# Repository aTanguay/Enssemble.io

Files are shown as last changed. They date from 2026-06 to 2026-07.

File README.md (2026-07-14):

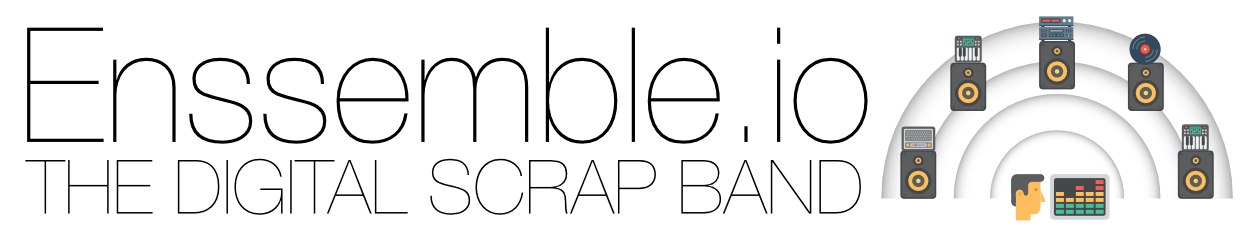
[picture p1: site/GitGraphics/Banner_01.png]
Header


**The Scrap Band**

The goal of Enssemble is to make experimenting with what I like to call a 'scrap band' a lot easier and cheaper. Placing musical members/nodes around your space gives you a completely different (and fun) experience compared to traditional two channel stereo. I personally strive to make them 100% wireless, so one can experiment at will. Running cables breaks the flow - and the metaphor.
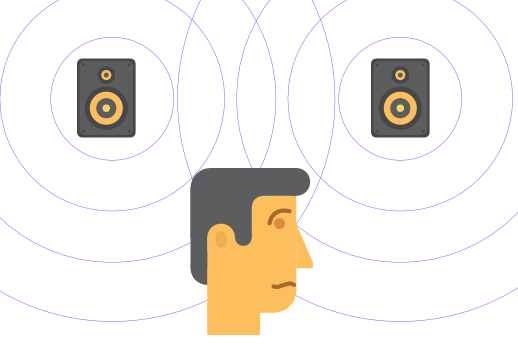
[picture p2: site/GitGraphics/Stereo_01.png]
Stereo


To create a band, we make a collection of sound making devices, sequenced through one BLE MIDI source. I personally use AUMv3 on iOS for this. This is your brain (and can be a voice of course). Just about any kind of sequencing you'd want is possible this way...from generative, to traditional straight forward compositions.

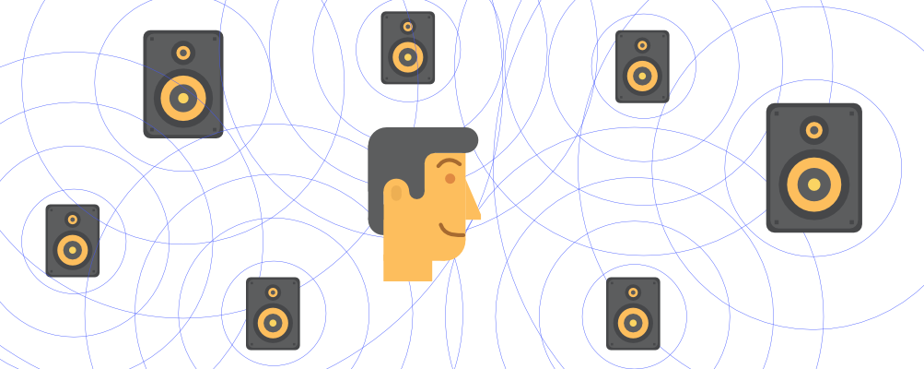
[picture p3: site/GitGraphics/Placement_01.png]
placement


**The Member Nodes** 

Battery>Node/Amp>Speaker

To get going, you need nodes, or 'members' to your band. The cheapest way I have found to make a good node is a [Seeed Studio Xiao MIDI synthesizer](https://www.seeedstudio.com/XIAO-MIDI-Synthesizer-p-6462.html) , a USB power brick, and a thrifted speaker...that's it. This could be done for $30-$50, depending on what you have available...most people have at least a few USB bricks around. So, a whole 'band' could cost you as little as $100, depending on what you have available. And frankly batteries are optional, but I go for no wires here.

Now that's the cheapest 'good' option, but there's nothing stopping you from using the tiny speaker on the Xiao, or hooking up a stadium PA. That's your business.

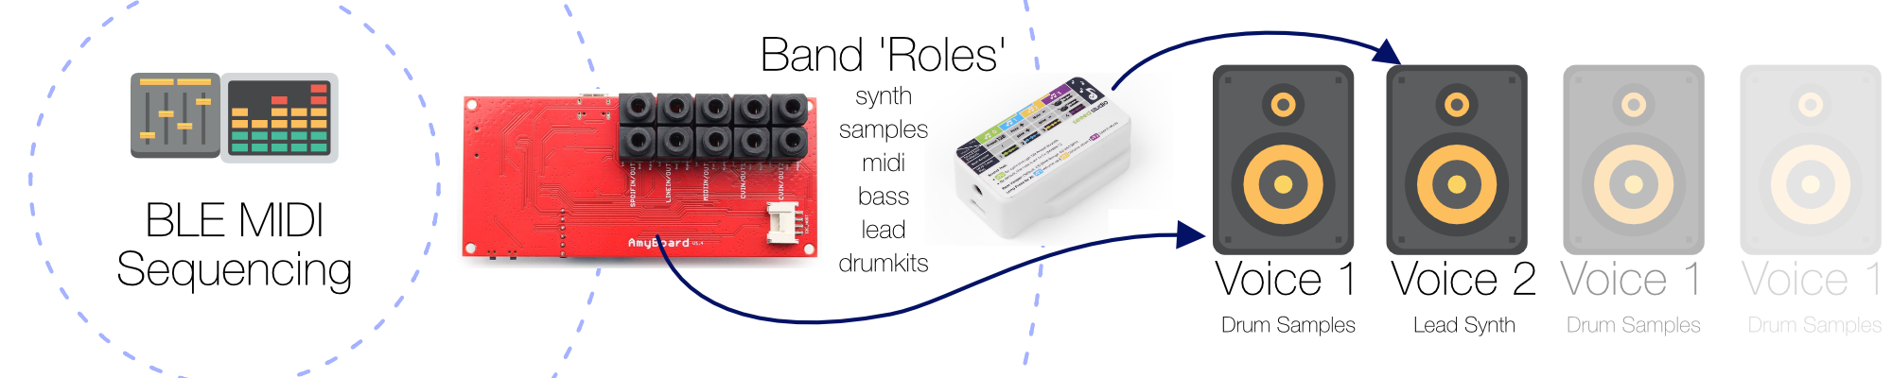
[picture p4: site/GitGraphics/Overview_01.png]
Overview


**Enssemble Firmwares**

Right now, there are two paths for Enssemble firmware. The aforementioned Xiao, and then the ['AmyBoard'](https://www.amyboard.com/) . This is a very cool, very cheap, very capable board that gives you some things that the Xiao doesn't have. The downside being the lack of built in amplifier. The Xiao has a surprisingly capable little Class D amp inside. So when powered and connected to a bookshelf speaker, it's ready to go. You'll be surprised!

On the other hand, the Amyboard supports more modern synthesis, Sample playback, and (TypeA TRS) MIDI in and out. As well as CV, if you wanna get nuts. But, you'll need powered speakers of some type. Which isn't the end of the world, but makes things more complicated.

**Node control and sonic shaping**

For this, I've been using Mozaic on iOS. The firmware support program change and passing CCs to whatever tweakable parameters the synths have. This feature is a little rough right now, but it will get cleaned up. And keep in mind that the Xiao uses some older sound types, but that's half the fun...trying to make cool stuff out a more limited palette. There are both crazy cheesy stuff in there, and surprisingly nice. And hey, put the sound through a pedal and shape it if you don't like it.

**The Pretenious Statement**

The overall experiment here is in 'spatial-like music'...meaning music experienced in 3D dimensions, instead of just two stereo speakers. By being able to place these sound sources literally anywhere around a space, you can create just about any kind of 'experience' you want. You could simulate a 4 piece Jazz trio. You could have sounds in other rooms of a home, all contributing to music. You get the idea. A lot of the inspiration is [Susan Ciani](https://www.sevwave.com/) (who I've actually never seen) who sequences her music in 3D dimensions, leading to an performance that can only be experienced in person. Neat. Whew, those kind of statements make me queasy. Here's a shortened version...It'd be cool.

*(Note, these firmwares were made largely through vibe coding with human planning and oversight. If that sits with you wrong, for the love of god, keep it to yourself and don't use these free tools that somehow a computer is 100% responsible for, but also, somehow took me dozens of man-hours to make)* Eye-roll emoji

**Yeah yeah, make with the BINS**

You probably want to know what you're looking for (feature-wise), which you'll find below, but here's the 
[Latest Release](https://github.com/aTanguay/Enssemble.io/releases/tag/v0.2.0)
Use the ESP browser based flasher, and go nuts.

flash a unit without a toolchain:
```bash
esptool.py --chip esp32c3 -p /dev/cu.usbmodem101 -b 460800 write_flash 0x0 NSMBL_Eenoo_v0.1.bin
```
or at 
[ESP TOOL ONLINE](https://espressif.github.io/esptool-js/)
Connects, flash starting at 0x00 and go to town.

## The Band (The Firmwares)

| Name | Inspiration | MIDI Ch | Role | Default Patch | Firmware |
|---|---|-----|---|---|---|
| **Eenoo** | Brian Eno | 1 | Pads/Ambient | Synth Pad | Amy and Xiao |
| **Prynz** | Prince | 2 | Lead | Synth Leads | Amy and Xiao |
| **Botsee** | Bootsie Collins | 3 | Bass | Synth Bass | Amy and Xiao |
| **Moroh** | Giorgio Moroder | 5 | Arps / Sequences | Synth Lead | Amy and Xiao |
| **8OhAte** | The 808 | 10 | Drums | GM Drum Kits | Xiao Only |
| **Kneel**  | Neal Peart | 10 | Drums | Sampled Kits | Amy Only |
| **Dapht**  | Daft Punk | 4 | General Samples | TBD | Amy Only |
| **Garee** | Gary Numan | ALL | MIDI Out to Hardware | None | Amy Only |

Named configs in `AmyBoard/configs/` — copy to `main/config.h` before flashing each board.

## What each node does (for the most part)

- Each unit advertises as a **BLE MIDI 1.0 peripheral** — connects to iOS as distinct nodes.
- Receives Note On/Off, Program Change, Pitch Bend, and CCs
- Per-unit MIDI channel filtering — each band member responds only to its assigned channel
- Real-time sound shaping via standard MIDI CCs (filter, reverb, chorus, volume, pan)
- Two platforms: **AMYboard** (ESP32-S3 + AMY software synth) and **XIAO MIDI Synthesizer** (ESP32-C3 + SAM2695 hardware GM wavetable)
- AMYboard firmware variants: **AMY synth** (256 patches) and **sample player** (WAV kits from SD)
- iOS control surface via **Mozaic** scripts

## Hardware

### AMYboard (ESP32-S3 Core)
- [AMYboard](https://www.amyboard.com/) — open-source, $29
- AMY software synth engine — 250 oscillators, 128 Juno-6 + 128 DX7 patches, GM drums
- ESP32-S3 dual-core: BLE MIDI on core 0, audio rendering on core 1
- 8MB octal PSRAM, SD card, I2S line out (3.5mm TRS stereo)
- I2C port for accessories, MIDI in/out (TRS), CV in/out, S/PDIF
- Support for I2C encoder and 128x128 OLED that most people use.

### Seeed Studio XIAO MIDI Synthesizer - ESP32-C3 Core + SAM2695 Audio Chip
- [Seeed Studio XIAO MIDI Synthesizer](https://www.seeedstudio.com/XIAO-MIDI-Synthesizer-p-6462.html)  — $22, tiny form factor, single-core RISC-V
- [Dream SAM2695](GM_VOICINGS.md) — hardware GM wavetable synth, 128 GM patches + drum kits, 64-voice polyphony
- UART MIDI at 31250 baud, full CC/NRPN passthrough (filter, envelope, vibrato, reverb/chorus types)
- 3.5mm stereo line out + onboard Class-D amplifier (that's not bad at all)

## Firmware Variants

### NSMBL_Synth — AMY Synth (`AmyBoard/NSMBL_Synth/`)
Full software synthesizer using the AMY engine. Default synths: Juno-6 (ch1), DX7 (ch2), GM drums (ch10). Supports program change to browse all 256 patches. Custom NSMBL CC handler for real-time sound shaping. Used by Eenoo, Prynz, and Botsee.

### NSMBL_SampleKits — Sample Player (`AmyBoard/NSMBL_SampleKits/`)
16-slice drum sample player. Reads WAV files with cue point markers from SD card. 4-voice polyphony, velocity-sensitive, chromatic mapping from C2. Used by Kneel.

### NSMBL_Synth — SAM2695 (`SeeedXiaoMIDI/NSMBL_Synth/`)
Hardware GM wavetable synth via SAM2695 chip. 128 GM patches, full CC passthrough, NRPN support for filter cutoff/resonance, envelope, and vibrato. BLE MIDI parser with running status support. Listens on **MIDI channel 1** (melody) and **channel 10** (GM drums); other channels are ignored (route in your host). See `Docs/SAM2695_MIDI_Reference.md` for full CC/NRPN map.

Per-unit identities live in `SeeedXiaoMIDI/NSMBL_Synth/configs/` — copy one to `main/config.h` before flashing so each module shows up with its own BLE name in AUM: **NSMBL_Eenoo** (pads, ch1), **NSMBL_Prynz** (lead, ch2), **NSMBL_Botsee** (bass, ch3), **NSMBL_Moroh** (arps, ch5), **NSMBL_8OhAte** (drums, ch10). Each unit listens only on its own channel.

Prebuilt per-member BINs are attached to the [v0.1.0 release](https://github.com/aTanguay/Enssemble.io/releases/tag/v0.1.0) — 

**Hardware buttons** (patch browsing, each press auditions the voice):

| Button | Tap | Hold |
|---|-----|---|
| 0 | Family down (coarse, −8) | — |
| 1 | Family up (coarse, +8) | Volume up |
| 2 | Patch down (fine, −1) | Volume down |
| 3 | Patch up (fine, +1) | MIDI panic |

> ⚠️ **Build gotcha:** the ESP-IDF console **must** stay off UART0 (it's the SAM2695's MIDI port). If it doesn't, log output corrupts the chip and patch changes silently fail. `sdkconfig` must show `CONFIG_ESP_CONSOLE_UART_NUM=-1`. See PLANNING.md → Technical Notes.

## Installing

There are many precompiled firmwares available for these boards. The easiest way to flash them is with the online tool from esspressiff. Depending on how many nodes you're making, you can install some or all of the firmwares, depending on their usage. 
[ESP TOOL ONLINE](https://espressif.github.io/esptool-js/)

## iOS Setup

1. Power on units — each plays a startup bleep
2. Open **AUM**, tap MIDI plug icon, connect each unit via Bluetooth MIDI
3. Route MIDI channels to the corresponding units
4. Play with a keyboard app, sequencer (Helium), or Mozaic control surface

iOS handles 13+ simultaneous BLE connections — the full band is well within range.

***CREATE DEMO VIDEO!***

## Mozaic Control Surface (still very rough)

iOS scripts in `Mozaic/` for the [Mozaic](https://ruismaker.com) MIDI scripting app:

| Script | Purpose |
|---|---|
| **NSMBL_EEnoo_Controller.moz** | AMYboard: patch browsing, filter/reso/reverb/chorus knobs, vol/pan mode, sustain, MIDI panic |
| **NSMBL_XIAO_Controller.moz** | XIAO/SAM2695: Mix layout — XY filter pad, NRPNs, named reverb/chorus types, envelope, vibrato |
| NSMBL_EEnoo_PatchSelect.moz | Simple patch bank selector |
| NSMBL_EEnoo_SoundShaper.moz | CC knobs only |

## NSMBL CC Map

Standard MIDI CCs handled by the firmware on all channels. Works with any MIDI controller.

| CC | Parameter | Mapping |
|----|---|---|
| 7 | Volume | Linear 0-127 |
| 10 | Pan | 0=Left, 64=Center, 127=Right |
| 70 | Filter Cutoff | Exponential ~13Hz-6400Hz |
| 71 | Resonance | Exponential Q 0.5-16 |
| 75/93 | Chorus Level | Linear 0=dry, 127=full |
| 91 | Reverb Level | Linear 0=dry, 127=full |

Handled by AMY internally: CC 0 (bank select), CC 64 (sustain), CC 123 (all notes off).

## License

MIT

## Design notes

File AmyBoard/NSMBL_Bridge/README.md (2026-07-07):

# NSMBL_Bridge — AMYboard BLE → DIN MIDI bridge (a.k.a. "Garee")

Takes BLE MIDI in (from AUM / an iPhone) and re-transmits it out the AMYboard's
**hardware DIN MIDI OUT** jack, so the wireless Enssemble rig can drive real
hardware synths, drum machines, and modular gear.

- No synthesis, no AMY engine, no PSRAM — a pure forwarder.
- Reuses the proven BLE MIDI parser from the XIAO firmware.
- Named member: **Garee** (Gary Numan).

## Channel routing (two knobs in `config.h` / `configs/config_*.h`)

| Define | Values | Meaning |
|---|---|---|
| `BRIDGE_IN` | `BRIDGE_ALL` (0) or a channel 1–16 | Forward every channel, or only one |
| `BRIDGE_OUT`  | `BRIDGE_PASSTHROUGH` (0) or a channel 1–16| Keep each message's channel, or remap ALL onto one  |

`config_Garee.h` default = **forward ALL → remap to ch1**, so fixed-channel
hardware (most gear defaults to ch1) just plays whatever you route to Garee.

## Hardware / pin map (AMYboard, ESP32-S3)

Confirmed from `tulipcc` `tulip/amyboard/pins.h` and the v1.4 schematic:

| Signal | GPIO | Notes |
|---|---|---|
| MIDI OUT data | 14 | UART1 TX, "Type A" data leg |
| MIDI OUT src  | 15 | "Type B" data leg — held HIGH here (see below) |
| MIDI IN | 21 | UART1 RX (not used yet) |
| UART | 1 | 31250 baud, 8N1 |

Console is on **USB-Serial-JTAG** (native USB-C), off the MIDI UART. View logs
with `idf.py -p <port> monitor` from a real terminal.

## ⚠️ The critical finding: the OUT jack needs a firmware-driven current source

**This cost hours to find and is not obvious. Read this before touching MIDI OUT.**

The AMYboard MIDI OUT is a **3.5mm TRS jack (PJ-3410)** wired, per the v1.4
schematic, as:

```
TIP    → R37 (22Ω) → GPIO14   (data leg,  "Type A")
RING   → R38 (22Ω) → GPIO15   (other leg, "Type B")
SLEEVE → GND
```

There is **no fixed 3.3V rail on the jack.** A standard DIN MIDI input is an
**optocoupler that needs a current source** (classically DIN pin 4 held at V+).
On this board that source must be provided by **firmware holding the non-data TRS
leg HIGH.** If you only drive the UART TX pin (GPIO14) and leave GPIO15 floating,
**no current flows through the receiver's opto and you get complete silence — on
any adapter, Type A or Type B.** The MIDI is transmitting perfectly on GPIO14;
the receiver just can't "see" it without the source leg.

### The fix (in `midi_out_init()`):

```c
uart_set_pin(UART_NUM_1, MIDI_TX_PIN /*14*/, MIDI_RX_PIN /*21*/, ...);
// Hold the OTHER TRS leg high = the MIDI current source (MIDI idle level).
gpio_reset_pin(MIDI_SRC_PIN /*15*/);
gpio_set_direction(MIDI_SRC_PIN, GPIO_MODE_OUTPUT);
gpio_set_level(MIDI_SRC_PIN, 1);
```

This matches exactly what the stock tulipcc firmware does in
`tulip/shared/amy_connector.c` → `amyboard_set_midi_out()`:

> `gpio_set_level(other_pin, 1);  // hold it high (MIDI idle/source)`

### Type A vs Type B on this board

TRS type is chosen by **which leg carries data vs. source**, in firmware — not
just by the cable/adapter:

- **Type A:** `MIDI_TX_PIN = 14`, `MIDI_SRC_PIN = 15`  (default)
- **Type B:** `MIDI_TX_PIN = 15`, `MIDI_SRC_PIN = 14`

A TRS-A vs TRS-B *adapter* only swaps tip/ring downstream — it cannot substitute
for the missing source leg. Get the source leg driven first; then match the
adapter/cable to your gear's type.

## Build & flash

```bash
cp configs/config_Garee.h main/config.h        # pick the member/personality
idf.py set-target esp32s3                       # first time only
idf.py build
idf.py -p /dev/cu.usbmodem101 flash monitor     # AMYboard enumerates as native USB
```

## Verified

- ✅ BLE MIDI in → remap → DIN MIDI OUT, driving an Akai MPC over a Type-A TRS
  adapter (2026-07-07). Multi-channel source (e.g. Riffer on ch1/2/3) collapses
  to ch1 out.

## Known limits / future

- Forwards channel-voice messages only (note/CC/PC/pitch-bend/aftertouch).
  **SysEx, clock, and real-time are not passed yet.**
- MIDI **thru/merge** from the DIN IN (GPIO21) is stubbed but not wired up.
- Future: single-channel Garee variants; a Type-B variant.

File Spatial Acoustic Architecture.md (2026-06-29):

# Project Manifesto: Spatial Acoustic Architecture

This project is dedicated to moving beyond the limitations of traditional stereo reproduction by exploring Spatial Acoustic Architecture. The philosophy is simple: music should not be a flat, compressed experience. It should be a physical event where sound occupies the same three-dimensional space as the listener.

## Core Philosophy

- **Sound as Physicality:** We reject the "stereo bore." By distributing sound sources physically throughout a room, we allow the room's natural acoustics to act as the final mixing console.
- **The Instrument is the Room:** The listener is not a passive audience member; they are an active participant, and their movement through the space determines the mix.
- **Zero-Friction Immersion:** Accessibility is paramount. The goal is to provide a setup that is easy for non-technical users to assemble, configure, and operate while maintaining the depth required for advanced musical performance.
- **Open Synthesis:** We favor permanent, open-source platforms like the AMYboard over transient maker-market hardware, ensuring the project remains sustainable and hackable for years to come.

## Project Roadmap

| **Phase** | **Objective** | **Primary Tech** |
| --- | --- | --- |
| 1. Foundation | Establish BLE MIDI firmware on AMYboard (ESP32-S3) via ESP-IDF. | NimBLE, ESP-IDF, AMY Engine |
| 2. Voice Categorization | Develop specialized firmware for "Band Members" (e.g., PCM Sampler, Analog Poly-Synth, FM Bassist). | AMY Wire Messages, Custom C Binaries |
| 3. The Conductor | Implement a centralized "Band Leader" interface in AUM using Mozaic for patch management. | AUM3, Mozaic, MIDI CC/PC |
| 4. Expansion | Integration of tactile UI (I2C Encoders/OLED) for physical control in room-scale setups. | Grove I2C, Physical Encoders |

## Distribution Strategy: The "DIY Ecosystem"

To avoid the pitfalls of hardware manufacturing, this project operates on a frictionless DIY model:

1. **GitHub Hub:** The central repository hosting source code, Mozaic scripts, and wiring guides.
2. **Web Flashers:** Use of ESP Web Tools to allow users to install firmware via browser without installing development environments.
3. **Community Sketches:** Sharing specialized configurations that allow users to buy stock boards and instantly transform them into designated band members.

## The Long-Term Goal

The success of this project is not measured by market share or competing with professional synthesizers. It is measured by the ability to democratize spatial audio, turning every living room into a site-specific concert hall.

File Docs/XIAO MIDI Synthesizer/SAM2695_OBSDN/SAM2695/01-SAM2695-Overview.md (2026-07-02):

---
tags: [hardware, midi, synth, sam2695]
---

# SAM2695 — Overview

⬅ [[00-SAM2695-Index]]

Low power single chip synthesizer with effects and built-in CODEC.

## Key features

- Single chip all-in-one design:
  - MIDI control processor, serial and parallel interface
  - Synthesis, General MIDI wavetable implementation
  - GM-compatible effects: reverb + chorus
  - Spatial effect
  - 4-band stereo equalizer
  - Stereo DAC — DR 86dB typ, THD+N -75dB typ
  - Mic input — DR 86dB typ, THD+N -75dB typ
  - Mic echo
- Polyphony: **64 voices** without effects, **38 voices** with effects
- On-chip CleanWave™ wavetable data, firmware, RAM delay lines
- Stereo line audio output
- Typical applications: battery-operated musical keyboards, portable phones, karaoke machines
- Package: **QFN48, 6×6mm** — small footprint, small pin count
- Low power: 18 mA typ operating / 17 µA typ power-down, single 3.3V supply

## Typical hardware configuration

```
MIDI IN ──────┐
              │→ [ SAM2695 ] → Audio Out (stereo)
Parallel MIDI ┘
```

See [[02-SAM2695-Pin-Description]] for full pinout, [[08-SAM2695-Serial-Parallel-Modes]] for how the two input paths (serial MIDI vs 8-bit parallel bus) interact.

## Related
- [[02-SAM2695-Pin-Description]]
- [[03-SAM2695-Electrical-Characteristics]]
- [[06-SAM2695-Reference-Circuits]]

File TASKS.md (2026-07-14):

# TASKS.md — Current Priorities

## Phase 1 — AMYboard BLE MIDI Firmware ✅

### NSMBL_SmplCty (Sample Player) ✅
- [x] ESP-IDF project structure with CMake (target: ESP32-S3)
- [x] NimBLE BLE MIDI peripheral — pinned to Core 0
- [x] MIDI message parsing (Note On/Off, CC, Program Change, Pitch Bend)
- [x] FreeRTOS queue for MIDI events between cores
- [x] SD card driver (SPI, FAT32, long filenames)
- [x] WAV cue point parser for 16-slice kit files
- [x] 4-voice polyphonic sample player with velocity scaling — pinned to Core 1
- [x] I2S audio output (16-bit stereo, 44.1kHz)
- [x] Per-unit configuration (NSMBL_SmplCty, channel 1)
- [x] End-to-end verified: iPhone → BLE MIDI → 808 drum playback

### NSMBL_EEnoo (AMY Synth) ✅
- [x] AMY synth engine integrated as ESP-IDF component (250 oscillators)
- [x] I2S audio output via AMY (32-bit stereo, 44.1kHz)
- [x] All-channel MIDI pass-through (Juno ch1, DX7 ch2, drums ch10)
- [x] Startup bleep confirmation
- [x] BLE MIDI shared from SmplCty codebase
- [x] End-to-end verified: iPhone → BLE MIDI → AMY synth playback

## Phase 2 — Multi-Unit & UX (In Progress)

### Done
- [x] Full CC passthrough — NSMBL CC handler: volume, pan, filter, resonance, reverb, chorus (all channels)
- [x] Pitch Bend passthrough (working since EEnoo launch)
- [x] Per-unit MIDI channel filtering (configurable via config.h, 0=all)
- [x] Mozaic control surface — patch browsing, sound shaping, sustain, panic
- [x] Band member configs created: Eenoo (pads), Prynz (lead), Botsee (bass), Kneel (drums)
- [x] Named configs in `AmyBoard/configs/` — copy to config.h before flashing
- [x] **AMY sample player (`NSMBL_SampleKits`) parser brought up to snuff** — ported the
  running-status BLE parser from the Xiao/Garee rewrite (fixes dropped/corrupted hits on
  ch10 drum streams that use running status). Built clean, flashed + boot-verified on the
  AMYboard (SD mount, 16-slice kit load, BLE connect). (2026-07-09)
  - [ ] Flash with `config_Kneel.h` identity if this unit should join the roster as Kneel
    (currently flashed as generic `NSMBL_SampleKits`, ch10)

### AMYboard sample player — I2C encoder + OLED kit selection (In Progress, 2026-07-09)
*Plan: `~/.claude/plans/warm-mapping-cake.md`. Modulino Knob [ABX00107] @ 0x76/0x74 +
SH1107 128x128 OLED @ 0x3C on the Qwiic bus (SDA=17/SCL=18).*
- [x] Shared `i2c_master` bus (`i2c_bus.c`)
- [x] Modulino Knob driver (`modulino_knob.c`) — wrap-safe delta + button edge
- [x] SH1107 OLED via vendored u8g2 (`oled.c` + `components/u8g2/`, fonts trimmed 38 MB→26 KB)
- [x] Runtime-safe kit swap (`sample_player.c`) — local-load-then-swap under `s_kit_mutex`,
  render never stalls, **latent reload leak fixed**
- [x] Kit scan of `/sdcard/Kits/*.wav` (`ui.c`) — sorted, ext-stripped; **43 kits** found on
  the card (raised `MAX_KITS` 32→96)
- [x] UI loop — turn scrolls, push loads with a "Loading…" screen
- [x] Builds clean; boot-verified on HW (bus up, scan, graceful no-peripheral fallback, 808s intact)
- [x] **Live bring-up ✅** — OLED kit list renders; knob scrolls (found at **0x3B** after the
  address correction); push → "Loading…" → new kit plays; race-safe swap holds under playback.
  SH1107 needed the **`_seeed_` variant** (`OLED_SETUP`): the generic `_128x128_` applies a
  bogus `x_offset=96` that wrapped the display; seeed uses the same init with offset 0.
  **Feature complete.**
- [ ] (future) Modulino **Buttons** (mode/audition/panic); kit switch via MIDI Program Change;
  persist last kit in NVS

### AMY synth (NSMBL_Synth) — encoder + OLED patch & parameter control ✅ (2026-07-12)
*Drivers reused verbatim from the sampler (`i2c_bus.c` / `modulino_knob.c` / vendored `u8g2`);
only `oled.c` draws + `ui.c` are synth-specific.*
- [x] "Menu + edit" UI: turn scrolls Patch/Filter/Reso/Reverb/Chorus/Volume/Pan; push enters
  EDIT; turn adjusts live; push exits.
- [x] Patch: steps 0–255, loads live via bank `CC0` + Program Change; shows `Juno/DX7 NNN`.
- [x] Params send their CC live (70/71/91/93/7/10) via the existing `nsmbl_midi_cc_handler`.
- [x] UI injects `midi_event_t` into `midi_queue` — no `synth_engine.c` change, single AMY consumer.
- [x] Running-status BLE parser ported here too (separate commit).
- [x] **HW-verified**: menu renders + scrolls; EDIT Filter sweeps the sound live over BLE.
- [ ] (watch) app image at ~93% full (AMY + u8g2) — bump partition / trim u8g2 if it grows.
- [ ] (future) shared driver component across all 3 variants; patch-name table; NVS persist;
  Modulino Buttons; reconcile host-sent CCs with on-screen values.

### Garee (NSMBL_Bridge) — encoder routing + OLED MIDI monitor ✅ (2026-07-12)
*3rd and last AMYboard to get the UI — the fleet is complete. Drivers reused verbatim.*
- [x] `bridge_state.c` — runtime `BRIDGE_IN`/`BRIDGE_OUT` (seeded from config) + monitor state,
  shared across parse/forward/UI via a short `portMUX`.
- [x] OLED monitor: `IN→OUT` header (active field boxed), last-note, IN/OUT activity dots,
  forwarded-note counter. Turn edits active field; push toggles IN/OUT.
- [x] Wire-ins: `ble_midi.c` live IN filter + record received; `bridge_task` live OUT + record forwarded.
- [x] **HW-verified**: dots flash on notes, knob re-routes live, DIN gear responds (knob at alt 0x3A).

### Now the natural cleanup — shared driver component
- [ ] **Factor `i2c_bus` / `modulino_knob` / `oled` (+ vendored `u8g2`) into ONE shared component**
  referenced by all three variants (`EXTRA_COMPONENT_DIRS`), killing the 3× copy-paste before it drifts.
- [ ] Flash the synth UI with per-member configs (Eenoo/Prynz/Botsee).
- [ ] (future) NVS-persist: last kit (sampler), last patch/params (synth), last routing (bridge).

## Phase 2b — XIAO Platform (In Progress)

### Done
- [x] XIAO ESP-IDF firmware (`SeeedXiaoMIDI/NSMBL_Synth/`) — BLE MIDI + SAM2695 UART
- [x] SAM2695 MIDI reference extracted from chip spec (`Docs/SAM2695_MIDI_Reference.md`)
- [x] Full CC/NRPN passthrough — firmware forwards all CCs to SAM2695, NRPNs work natively
- [x] Mozaic XIAO controller (`Mozaic/NSMBL_XIAO_Controller.moz`) — Layout 0 (Mix)
  - XY pad: filter cutoff + resonance via NRPN
  - 10 knobs: volume, expression, reverb/chorus send+type, attack, release, vibrato rate/depth
  - 8 pads: patch/bank navigation, sustain, reset, PANIC
- [x] BLE MIDI parser rewrite — proper running status support, debug logging
- [x] SAM2695 bank fix — clamp to GM (0) / MT-32 (127), buttons+Mozaic as GM/MT-32 selectors
- [x] Hardware buttons working — gpio_reset_pin + 50ms debounce (root cause was seating, not firmware)
- [x] Volume-tracking fix — guard was broken in all-channel mode (MIDI_CHANNEL 0)
- [x] **Program changes fixed** — real cause was ESP-IDF console on UART0 corrupting the
  SAM's MIDI; moved console to USB-JTAG (`CONFIG_ESP_CONSOLE_UART_NUM=-1`). GM System On at boot.
- [x] Channel model — listen on ch1 (melody) + ch10 (drums), ignore the rest
- [x] **Patch-nav MVP** — buttons 0/1 family jump (coarse), 2/3 single patch (fine), each auditions
- [x] Review-pass cleanup — panic releases sustain (CC64=0), stale comments fixed
- [x] **v0.1.0 GitHub release** — merged flash-at-0x0 BIN, no toolchain needed
- [x] Roster naming sync across docs + AMY/XIAO configs
- [x] **5 single-channel XIAO band variants** — each listens only on its own port:
  Eenoo (ch1), Prynz (ch2), Botsee (ch3), Moroh (ch5), 8OhAte (ch10); per-member
  prebuilt BINs built and attached to the v0.1.0 release
- [x] Flashed live: Prynz, Botsee, 8OhAte (drums confirmed!)

### Deferred — XIAO firmware hygiene (low priority, not blocking)
- [ ] **Audition blocks the MIDI task (~780ms)** — `audition_voice()` + PC delays run inside
  `midi_task`, so incoming BLE events queue up while the preview plays; a held note's
  note-off can stall, and a PC flood can overflow the 64-deep queue (silent drops).
  Fix deliberately: add a UART write mutex FIRST (two tasks must never interleave bytes
  to the SAM2695 — see the UART0 saga), then move the audition to its own task, then
  hardware-test with a live MIDI stream. Do NOT do this casually.
- [ ] Decide volume-button intent: long-press volume only adjusts VOICE_CHANNEL (ch1);
  drums (ch10) stay at boot volume. If buttons should be "device volume", also send ch10.
- [ ] Move `ble_midi_is_connected()` declaration into `ble_midi.h` (currently extern'd
  inline in main.c's led_task)
- [ ] Streamline PC band-aids (30ms bank/PC gaps, 250ms audition delay) now that the real
  UART0 bug is fixed — kept for now, "don't press our luck" (works reliably as-is)
- [ ] Long-press timing 600ms → 1000ms to match Seeed reference (feel preference)
- [ ] BLE RX buffer is fixed `uint8_t buf[128]` in `ble_midi.c` — size to negotiated MTU to avoid truncating very large bursts
- [ ] Parser SysEx handling consumes the 0xF7 terminator as a timestamp (harmless, not strictly correct)

### Next — MVP for Spatial Composition
- [ ] Flash remaining XIAO units: Eenoo (ch1, from the basement) + Moroh (ch5)
- [ ] Verify 5-unit simultaneous BLE connection from iPhone/AUM (route ch1/2/3/5 + ch10)
- [ ] Connect each unit to a speaker in a different location
- [ ] First spatial composition test (2 XIAO + 1 AMY already sounded amazing)
- [ ] Flash 3 AMYboards: Eenoo (ch1 pads), Prynz (ch2 lead), Botsee (ch3 bass)
- [ ] Verify XIAO Mozaic controller end-to-end (CCs, NRPNs, program changes)

### Later
- [ ] Kit switching via MIDI Program Change (SmplCty)
- [ ] Modulino Buttons + Knob I2C drivers (when hardware arrives)
- [x] **Garee (Gary Numan)** — AMYboard BLE→DIN MIDI bridge scaffolded
  (`AmyBoard/NSMBL_Bridge/`), builds clean for ESP32-S3. MIDI out UART1 GPIO14
  (Type A), 31250. Configurable `BRIDGE_IN` (all/one channel) + `BRIDGE_OUT`
  (passthrough/remap); default config_Garee.h forwards ALL → remaps to ch1 so
  fixed-channel hardware just plays.
  - [x] Flashed + **hardware-verified driving an Akai MPC over Type-A TRS**
    (2026-07-07). Key fix: **hold the non-data TRS leg (GPIO15) HIGH as the MIDI
    current source** — the OUT jack has no 3.3V rail, so a DIN opto gets total
    silence otherwise. Full write-up in `AmyBoard/NSMBL_Bridge/README.md`.
  - [ ] (future) MIDI thru/merge from DIN in (GPIO21); SysEx/clock passthrough
  - [x] (cleanup) reflashed the clean build — per-note diagnostic log removed (2026-07-07)
- [ ] **CV output AMYboard variant** — pitch/gate (and LFO/env) CV out to patch a band
  member into modular/Eurorack; AMYboard has 2x CV out
- [ ] Moroh AMY config (roster lists Moroh as Amy+Xiao; only the XIAO config exists so far)
- [ ] Favorite voice slots stored in NVS flash
- [ ] Reconnection handling — auto re-advertise after iOS disconnects
- [ ] Per-unit Mozaic scripts (one controller per band member)
- [ ] Dapht (Daft Punk) — sampler/granular unit, design TBD after first spatial jam

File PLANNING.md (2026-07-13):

# PLANNING.md — Enssemble / "The Band"

## Project Vision

A set of wireless BLE MIDI synthesizer units deployed spatially around a room — each one a band member with its own voice, driven wirelessly from an iPhone. Sound comes from physically located objects rather than stereo speakers.

Each unit is a band member with a single-name identity: Eenoo, Prynz, Botsee, Moroh, 8OhAte, Kneel, Dapht, Garee.

The firmware is built with **ESP-IDF** and targets two hardware platforms:
- **XIAO MIDI Synthesizer** (ESP32-C3 + SAM2695 hardware GM chip)
- **AMYboard** (ESP32-S3 + AMY software synth engine)

---

## Current Status

ESP-IDF firmware working on both AMYboard and XIAO platforms.

**XIAO platform shipped as v0.1.0** — a 5-piece XIAO band (Eenoo, Prynz, Botsee, Moroh, 8OhAte), each a single-channel BLE MIDI voice with per-member prebuilt BINs attached to the [GitHub release](https://github.com/aTanguay/Enssemble.io/releases/tag/v0.1.0). The long SAM2695 "patch won't change" bug is solved (root cause: ESP-IDF console was on UART0, the SAM's MIDI port). Three XIAO units flashed so far (Prynz, Botsee, 8OhAte); Eenoo + Moroh pending hardware.

Three AMYboards available for spatial deployment. Mozaic iOS control surface replaces the planned TouchOSC phase. Next: flash the remaining units and run the first multi-unit spatial jam.

### Firmware Variants
| Firmware | Directory | Platform | Purpose | Status |
|---|---|---|---|---|
| NSMBL_Synth | `AmyBoard/NSMBL_Synth/` | AMYboard (ESP32-S3) | AMY synth engine (Juno, DX7, drums) | ✅ Verified |
| NSMBL_SampleKits | `AmyBoard/NSMBL_SampleKits/` | AMYboard (ESP32-S3) | 16-slice WAV sample player (SD card) | ✅ Verified |
| NSMBL_Synth | `SeeedXiaoMIDI/NSMBL_Synth/` | XIAO (ESP32-C3) | SAM2695 hardware GM wavetable synth | ✅ Verified |
| NSMBL_Bridge | `AmyBoard/NSMBL_Bridge/` | AMYboard (ESP32-S3) | BLE→DIN MIDI bridge (Garee); channel filter/remap | ✅ HW-verified (drives Akai MPC) |

Band member identity is set via `config.h` — copy a named config from `AmyBoard/configs/`
(AMY) or `SeeedXiaoMIDI/NSMBL_Synth/configs/` (XIAO) before building. XIAO members are
single-channel: Eenoo ch1, Prynz ch2, Botsee ch3, Moroh ch5, 8OhAte ch10.

### iOS Control Surface (Mozaic)
| Script | Purpose | Status |
|---|---|---|
| `NSMBL_EEnoo_Controller.moz` | AMYboard: patch browser + sound shaper + panic | ✅ Working |
| `NSMBL_XIAO_Controller.moz` | XIAO: Mix layout with XY filter, NRPNs, named FX types | ✅ Working |
| `NSMBL_EEnoo_PatchSelect.moz` | Simple patch bank selector (superseded) | ✅ Working |
| `NSMBL_EEnoo_SoundShaper.moz` | CC knobs only (superseded) | ✅ Working |

### NSMBL CC Map (firmware, all channels)
| CC | Function | Range |
|----|---|---|
| 7 | Volume | 0-127 linear |
| 10 | Pan | 0=L, 64=center, 127=R |
| 70 | Filter Cutoff | Exponential ~13Hz-6400Hz |
| 71 | Resonance | Exponential Q 0.5-16 |
| 75/93 | Chorus Level | 0=dry, 127=full |
| 91 | Reverb Level | 0=dry, 127=full |

AMY handles internally: CC 0 (bank select), CC 64 (sustain), CC 123 (all notes off).

### The Band — Full Roster
*Names riff on famous musicians. Configs in `AmyBoard/configs/` (AMY) and `SeeedXiaoMIDI/NSMBL_Synth/configs/` (XIAO).*

| Name | Inspiration | MIDI Ch | Role | Default Patch | Firmware | Xiao Status | Amy Status |
| --- | --- | --- | --- | --- | --- | --- | --- |
| **Eenoo**  | Brian Eno | 1 | Pads/Ambient | Synth Pad | Amy and Xiao | ✅ Ready | |
| **Prynz**  | Prince | 2 | Lead | Synth Leads | Amy and Xiao | ✅ Ready | |
| **Botsee** | Bootsie Collins | 3 | Bass | Synth Bass | Amy and Xiao | ✅ Ready | |
| **Moroh**  | Giorgio Moroder | 5 | Arps / Sequences | Synth Lead | Amy and Xiao | ✅ Ready | |
| **8OhAte** | The 808 | 10 | Drums | GM Kits | Xiao Only | ✅ Ready | |
| **Kneel**  | Neal Peart | 10 | Drums | Sample Kits | Amy Only | | |
| **Dapht**  | Daft Punk | 4 | General Samples | TBD | Amy Only | | |
| **Garee**  | Gary Numan | ALL | MIDI Out to Hardware | None | Amy Only | | |

Named configs in `AmyBoard/configs/` (AMY) and `SeeedXiaoMIDI/NSMBL_Synth/configs/` (XIAO)
— copy one to `main/config.h` before flashing each board.

---

## Architecture

```
iPhone (AUM + Helium / TouchOSC)
        |
        | BLE MIDI 1.0 — one connection per unit
        | iOS confirmed: 13+ simultaneous connections possible
        | Latency: 3-15ms per unit
        |
        +-- Channel 1 --> Eenoo (Pads/Ambient)
        +-- Channel 2 --> Prynz (Lead)
        +-- Channel 3 --> Botsee (Bass)
        +-- Channel 4 --> Dapht (Samples) [Amy]
        +-- Channel 5 --> Moroh (Arps/Sequences)
        +-- Channel 10 -> 8OhAte (Drums, Xiao) / Kneel (Drums, Amy)
        +-- All chans -> Garee (MIDI out to hardware) [Amy]
                |
                v
AMYboard (ESP32-S3, dual-core):
  Core 0:
    +-- NimBLE BLE MIDI stack
    +-- MIDI message parsing & channel filter
    +-- Connection management
    +-- Button handler
  Core 1:
    +-- AMY synth engine (audio rendering)
    +-- I2S DAC output
  Shared (FreeRTOS queue between cores):
    +-- MIDI events from Core 0 -> Core 1
    +-- Per-unit config (device name, channel, patch)
    +-- Boot sound on startup

XIAO (ESP32-C3, single-core):
  +-- BLE MIDI stack (NimBLE) with running status support
  +-- SAM2695 via UART @ 31250 baud (128 GM + drum kits)
  +-- Full CC/NRPN passthrough (filter, envelope, vibrato, FX types)
  +-- 3.5mm stereo + onboard Class-D amp
```

---

## Phases

### Phase 1 — AMYboard BLE MIDI + Sample Player
*AMYboard first. Get BLE MIDI receiving on one core, AMY playing on the other.*

- [ ] ESP-IDF project structure with CMake (target: ESP32-S3)
- [ ] NimBLE BLE MIDI peripheral (advertise, connect, receive MIDI) — pinned to Core 0
- [ ] MIDI message parsing (Note On/Off, CC, Program Change, Pitch Bend)
- [ ] AMY synth engine integration — pinned to Core 1
- [ ] FreeRTOS queue for MIDI events between cores
- [ ] Simple sample player exposing AMY's PCM playback via MIDI notes
- [ ] I2S audio output configuration
- [ ] Per-unit configuration (device name, MIDI channel, default patch)
- [ ] Boot sound on startup
- [ ] Verified working: AUM connects, notes trigger samples, audio out confirmed

### Phase 2 — Multi-Unit & UX (AMYboard)
*Multiple AMYboard units with proper channel separation and standalone usability*

- [ ] Per-unit MIDI channel filtering
- [ ] Full CC passthrough (volume, pan, expression, sustain, mod, effects)
- [ ] Pitch Bend and Aftertouch passthrough
- [ ] Voice/patch selection via AMY
- [ ] Curated preset system per band role
- [ ] Audition note on voice change
- [ ] Favorite voice slots stored in NVS flash
- [ ] Reconnection handling — auto re-advertise after iOS disconnects
- [ ] Button input handler
- [ ] Multi-unit simultaneous operation verified

### Phase 2b — XIAO Platform ✅
*BLE MIDI on XIAO ESP32-C3 + SAM2695 hardware GM synth*

- [x] SAM2695 UART driver component (31250 baud)
- [x] Single-core architecture adapted for ESP32-C3 (RISC-V)
- [x] BLE MIDI parser with running status support
- [x] Full CC/NRPN passthrough to SAM2695
- [x] SAM2695 MIDI reference documented (`Docs/SAM2695_MIDI_Reference.md`)
- [x] Mozaic XIAO controller (Layout 0 Mix — XY filter, NRPNs, named FX types)

### Phase 3 — ~~TouchOSC~~ Mozaic Control Surface ✅
*Replaced TouchOSC plan with Mozaic iOS scripts — simpler, more flexible, already working.*

- [x] Patch browsing (prev/next per channel)
- [x] Sound shaping knobs (filter, resonance, reverb, chorus)
- [x] Volume/Pan mode toggle
- [x] Channel selector (Juno/DX7/Drums)
- [x] Sustain toggle
- [x] CC reset
- [x] MIDI Panic (all sound off, all channels)
- [ ] Multi-unit page — one Mozaic instance per band member

### Phase 4 — Deep Synth Control
*Platform-specific advanced features*

- [ ] XIAO/SAM2695: SysEx for 4-band stereo EQ, master volume/tuning
- [ ] AMYboard/AMY: Custom patches, FM synthesis, filter control
- [ ] I2C encoder/OLED UI for physical control (AMYboard)

### Phase 5 — "The Band" Physical System
*3D printed band members for room-scale deployment*

- Enclosure design — abstract sculptural forms, textile/fabric aesthetic
- LiPo battery integration for fully wireless operation
- Upgraded speakers housed in acoustic chambers
- Power on -> boot sound -> advertise -> AUM connects -> play

---

## Technical Notes

### BLE MIDI
- BLE MIDI 1.0 spec over NimBLE (ESP-IDF component, not Arduino library)
- Each unit is an independent BLE peripheral
- iOS handles 13+ simultaneous connections
- Latency: 3-15ms per unit

### SAM2695 (XIAO platform)
- Needs ~500-600ms after power-up before accepting MIDI
- Pitch Bend must be sent as raw MIDI bytes
- Bank Select (CC 0) must precede Program Change; only bank 0 (GM) / 127 (MT-32) valid
- Channel indexing: BLE MIDI uses 1-16, SAM2695 uses 0-15
- Drum channel (10) volume defaults low — set explicitly

### ⚠️ CRITICAL: keep the ESP-IDF console OFF UART0 (XIAO+SAM2695)
UART0 is the SAM2695's MIDI port. If the ESP-IDF console stays on UART0 (the
default!), every `ESP_LOGI` is transmitted to the chip as garbage MIDI and
corrupts its state — program changes stop working and every note plays one
stuck bell-like sound (intermittent, correlates with logging). This cost us a
full debugging session. Guard rails:
- `sdkconfig.defaults` must set `CONFIG_ESP_CONSOLE_UART_DEFAULT=n`,
  `CONFIG_ESP_CONSOLE_USB_SERIAL_JTAG=y`, `CONFIG_ESP_CONSOLE_SECONDARY_NONE=y`
- Editing `sdkconfig.defaults` does nothing if `sdkconfig` already exists —
  delete `sdkconfig` and rebuild to apply it
- Verify the built `sdkconfig` shows `CONFIG_ESP_CONSOLE_UART_NUM=-1` (NOT 0)
- The Arduino library avoids this by keeping debug on USB `Serial` + synth on `Serial0`

### Hardware — XIAO ESP32-C3
- Button pins (active LOW, internal pullup): GPIO 5, 4, 3, 2
- SAM2695 on UART0 at 31250 baud (TX=21, RX=20) — console MUST be on USB-JTAG, see above
- LED = GPIO 10, active LOW
- Patch nav buttons: 0/1 = family jump (coarse), 2/3 = single patch (fine)

### Hardware — AMYboard ESP32-S3
- AMY software synth engine (250 oscillators, dual-core rendering)
- I2S audio output (32-bit stereo via onboard DAC)
- 8MB octal PSRAM for samples and synth data
- SD card (SPI: MOSI=11, MISO=13, CLK=12, CS=10)
- I2S pins: MCLK=3, BCLK=8, WS=2, DOUT=6
- I2C port: SDA=17, SCL=18 (for Modulino accessories)
- MIDI out: GPIO 14 (Type A) / GPIO 15 (Type B)
- MIDI in: GPIO 21
- Line out: 3.5mm TRS stereo
- S/PDIF in/out, CV in/out (2x each)

### iOS BLE Limits
- iOS handles 13+ simultaneous BLE connections
- iPad Pro tested to 15 concurrent
- 4-5 band members is comfortably within limits
- Each unit is independent — no bandwidth competition

---

## Session Log

### 2026-07-09 — AMY sample player: I2C encoder + OLED kit selection ✅ HW-VERIFIED
- **Goal:** make each AMYboard drum node self-contained — turn a knob to browse the
  WAV kits on the SD card, see the selection on a screen, push to load. Plan file:
  `~/.claude/plans/warm-mapping-cake.md`.
- **Hardware:** Arduino Modulino Knob [ABX00107] (I2C 0x76/0x74) + SH1107 128x128 OLED
  (I2C 0x3C), both on the AMYboard Qwiic bus (SDA=17, SCL=18).
- **Built (all in `AmyBoard/NSMBL_SampleKits/main/`):**
  - `i2c_bus.c` — shared `i2c_master` bus (new driver API).
  - `modulino_knob.c` — probe + wrap-safe int16 delta + button-edge decode; we never `set()`.
    **Corrected against the vendored `Docs/Amyboard/Arduino_Modulino-main` source:** real 7-bit
    address is **0x3B/0x3A** (Arduino quotes 8-bit 0x76/0x74, lib divides by 2), and the read
    frame is **4 bytes** with the pinstrap byte FIRST (discard byte0; count=1-2, button=3).
  - `oled.c` + vendored **u8g2** component (BSD-2) — `u8g2_fonts.c` trimmed 38 MB → 26 KB
    (3 fonts). Kit-list / loading / message screens. SH1107 panel variant is a one-line
    knob: `OLED_SETUP` in `config.h` (swap to `_pimoroni_`/`_seeed_` if the image is offset).
  - `ui.c` — scans `/sdcard/Kits/*.wav`, sorts, drives selection + load-on-press.
- **Race-safe kit swap** in `sample_player.c`: kit now loads into a *local* `kit_t` (old kit
  keeps playing through the ~5 s SD read), then swaps in under a brief `s_kit_mutex`; render
  task takes the mutex with a 0 timeout (emits one silent buffer during the µs swap, never
  stalls). **Fixed a latent reload leak** (old PSRAM buffer is now freed). `note_on` shares
  the mutex so it never indexes a half-swapped kit.
- **Verified on hardware (peripherals not yet attached):** I2C bus up; kit scan found **43
  kits** on the card (sorted, extension-stripped, boot kit matched; `MAX_KITS` raised 32→96
  after the first run capped out); knob/OLED absent → graceful "disabled", 808s still play;
  no crashes; ~35% flash free.
- **Hardware-verified live (evening 2026-07-09):** OLED shows the kit list; the knob
  (found at **0x3B** once the address was corrected) scrolls the highlight; push shows the
  "Loading…" splash and the new kit plays — the race-safe swap held up under live playback.
- **SH1107 panel-offset fix:** the generic `_128x128_` descriptor applies `x_offset=96`,
  which wrapped this module horizontally. Switched `OLED_SETUP` to the **`_seeed_`** variant
  (`u8x8_seeed_128x128_display_info`, `x_offset=0`, same init seq / vertical start as generic)
  — text snapped into alignment. (Not pimoroni — that variant also shifts the vertical start.)
- Scope held tight: Modulino **Buttons** and MIDI-Program-Change kit switching deferred.

### 2026-07-09 — AMY sample player brought up to snuff (parser port) + flashed
- **Ported the running-status BLE parser into `NSMBL_SampleKits`.** The sample
  player was still running the *old* pre-rewrite parser (duplicate timestamp-skip
  blocks, no running-status fallback, desync on 0xA0/0xD0). Replaced its
  `parse_midi_message` with the proven Xiao/Garee version (`data_bytes_for_status()`
  lookup + real running-status tracking + SysRT/SysEx handling). Matters most for a
  drum stream on ch10, where iOS routinely omits repeated status bytes → the old
  parser dropped/corrupted hits. No `midi_event_t` change: aftertouch is advanced
  correctly but not enqueued.
- **Confirmed the UART0/console rule does NOT apply here** — the AMYboard sampler has
  no UART MIDI (audio = I2S, MIDI = BLE), so console-on-UART0 stays (useful for
  monitoring). The Garee GPIO15 MIDI-out current-source fix is likewise bridge-only.
- **Built clean and flashed to the AMYboard** (`/dev/cu.usbmodem101`). Boot verified
  over serial: SD mounted, `808_Mars_01_16kit.wav` loaded (16 cue points → 16 slices,
  3.05 MB into PSRAM), advertised as `NSMBL_SampleKits`, BLE host connected.
- Open item: the board flashed with the generic `main/config.h` (name
  `NSMBL_SampleKits`, ch10), not the `config_Kneel.h` identity — copy that config
  first if this unit should join the roster as **Kneel**.

### 2026-07-07 — Garee bridge live: BLE → DIN MIDI drives real hardware
- **Scaffolded `AmyBoard/NSMBL_Bridge/` (Garee)** — a pure BLE→DIN MIDI forwarder
  (no AMY engine). Reuses the XIAO BLE parser; new `midi_out.c` re-serializes to
  UART1. Configurable `BRIDGE_IN`/`BRIDGE_OUT`; default = forward ALL, remap to ch1.
  Console on USB-Serial-JTAG (off the MIDI UART).
- **Solved a hard, non-obvious hardware bug: no MIDI reached the Akai MPC.** The
  firmware was transmitting fine on GPIO14 (confirmed via per-note logs), and the
  MPC/cable were proven good — yet silence on both Type-A and Type-B adapters.
- **Root cause (from the v1.4 schematic in `Docs/Amyboard/tulipcc-main`):** the OUT
  jack is TRS `tip=GPIO14 (data), ring=GPIO15, sleeve=GND` with **no 3.3V rail**.
  A DIN MIDI opto needs a current source, which on this board must be **firmware
  holding the non-data leg (GPIO15) HIGH**. We only drove GPIO14 → opto never
  conducted. Fix matches stock `amyboard_set_midi_out()`:
  `gpio_set_direction(15,OUTPUT); gpio_set_level(15,1);`. Type A = TX14/SRC15,
  Type B = TX15/SRC14. **Verified live driving the MPC.** Full write-up in the
  bridge README + memory `reference-amyboard-midi-trs`.

### 2026-07-06 — XIAO band shipped: v0.1.0, 5 single-channel members
- **Cut the v0.1.0 GitHub release** with a merged, flash-at-0x0 BIN (no toolchain needed).
- **Synced the whole roster naming** across docs + configs: Eenoo, Prynz, Botsee
  (Bootsie Collins), Moroh (Giorgio Moroder), 8OhAte, Kneel, Dapht, Garee. Renamed
  AMY + XIAO configs to match.
- **Made each XIAO unit single-channel** so it responds only to its own port (synths on
  ch1/2/3/5 via DRUM_CHANNEL disabled; 8OhAte on ch10 = GM drums). Boot flourish is now
  conditional: drummers play the beat, synths play a hello note in their own voice.
- **Built per-member BINs** (Eenoo/Prynz/Botsee/Moroh/8OhAte) and attached them to the
  release. Flashed 3 units live: Prynz, Botsee, 8OhAte (hearing real drums!).
- Review pass on the XIAO firmware: fixed panic to release sustain (CC64=0), tidied stale
  comments; deferred items logged (audition blocking the MIDI task needs a UART mutex first).

### 2026-07-02 — XIAO patch-nav MVP + the UART0/console bug
- **Root-caused the "patch never changes / stuck bell" bug**: the ESP-IDF debug
  console was on UART0 — the SAM2695's MIDI port. Log text was being transmitted
  to the chip as garbage MIDI and corrupting its state. Fix: force console to
  USB-Serial-JTAG, delete stale `sdkconfig`, rebuild (`CONFIG_ESP_CONSOLE_UART_NUM=-1`).
  See the CRITICAL warning in Technical Notes. Verified on two units.
- Chased many red herrings first (bank clamp, timing gaps, GM-On, wavetable
  delay) — all band-aids; the console was the real cause. GM-On kept as good practice.
- Confirmed the SAM2695 is multitimbral; unit listens on ch1 (melody) + ch10 (drums),
  ignores other channels (host routes). Buttons own patch selection.
- Patch nav: buttons 0/1 jump by GM family (coarse, 16 voices), 2/3 step by one
  patch (fine). Each press auditions a single C4 preview note.
- Also fixed earlier this session: BLE running-status parser, GM/MT-32 bank
  handling, button hardening (gpio_reset_pin + debounce), volume tracking.

### 2026-07-01 — XIAO Platform: SAM2695 Reference, Mozaic Controller, BLE Parser Fix
- Extracted full SAM2695 MIDI reference from chip spec PDF → `Docs/SAM2695_MIDI_Reference.md`
- Documented all CCs, reverb/chorus types, NRPNs (filter, envelope, vibrato), RPNs, SysEx deep params, 4-band EQ
- Created Mozaic XIAO controller (`NSMBL_XIAO_Controller.moz`) — Layout 0 (Mix)
  - XY pad: filter cutoff + resonance via NRPN
  - 10 knobs: volume, expression, reverb/chorus send+type (with named labels), attack, release, vibrato rate/depth
  - 8 pads: patch/bank nav, sustain, CC reset, PANIC
- Rewrote BLE MIDI parser (`ble_midi.c`) — proper running status support
  - Old parser had duplicate timestamp-skip blocks that broke when iOS omitted status bytes
  - Timestamps were misinterpreted as status bytes, corrupting CCs into phantom Note Offs
  - New parser tracks running_status, uses data_bytes_for_status() lookup, handles SysRT/SysEx
  - Added raw hex dump at DEBUG level for troubleshooting
- Confirmed XIAO firmware forwards all CCs to SAM2695 — no firmware changes needed for new CC types

### 2026-06-30 — NSMBL_EEnoo + Mozaic Control Surface
- Integrated AMY synth engine as ESP-IDF component (250 oscillators)
- AMY handles I2S, dual-core rendering, and voice management internally
- Default synths: Juno-6 (ch1), DX7 (ch2), GM drums (ch10)
- All-channel MIDI pass-through (no channel filter)
- Reorganized project: `AmyBoard/NSMBL_SmplCty/` and `AmyBoard/NSMBL_EEnoo/`
- Custom NSMBL CC handler replacing AMY's Juno-only example — filter, resonance, reverb, chorus, volume, pan on all channels
- Mozaic iOS control surface: learned API from scratch, built 3 scripts
- Unified Controller script: patch browsing, sound shaping, sustain, panic
- Phase 3 (TouchOSC) rendered unnecessary by Mozaic approach
- Three AMYboards available for first spatial composition test

### 2026-06-29 — NSMBL_SmplCty (Sample Player) Working
- First ESP-IDF firmware from scratch — BLE MIDI + sample playback
- WAV cue point parser for 16-slice drum kits
- 4-voice polyphony with velocity scaling, I2S output
- SD card with FAT32 long filename support
- End-to-end verified: iPhone → AUM → BLE → 808 drums

### 2026-06-29 — ESP-IDF Migration Started
- Decision: move from Arduino to ESP-IDF for both XIAO and AMYboard platforms
- Updated all project documentation for new framework
- Arduino-era prototype code preserved in git history

### 2026-06-26 — Multi-Unit Success (Arduino era)
- Dual-unit operation achieved: EEnoo + Ryngo both connected to AUM
- Drums sequenced via Helium on channel 10
- This validated the spatial multi-unit concept

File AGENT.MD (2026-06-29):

# Development Instructions

## Framework

- Use native ESP-IDF.
- Do not introduce Arduino dependencies unless explicitly approved.
- Target boards: ESP32-C3 (XIAO MIDI Synthesizer) and ESP32-S3 (AMYboard).
- Write new application code in C++ where appropriate.
- Keep hardware drivers in separate components.
- Platform-specific code (SAM2695 driver, AMY driver) must be isolated from shared BLE/MIDI logic.

## Build and Validation

After making code changes, run:

    idf.py build

Do not consider a task complete unless the project builds without errors.

When hardware is attached, use:

    idf.py -p <PORT> flash monitor

## Project Documentation

- README.md describes currently implemented behavior.
- PLANNING.md contains design decisions and planned behavior.
- TASKS.md is the authoritative task list.
- Update TASKS.md when completing work.
- Do not describe planned features as currently implemented.

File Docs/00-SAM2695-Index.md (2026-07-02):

---
tags: [hardware, midi, synth, sam2695, dream, moc]
chip: SAM2695
manufacturer: Dream S.A.S. France
package: QFN48 6x6mm
datasheet_date: 2015-06-22
---

# SAM2695 — Index

Low power single-chip GM synthesizer with effects and built-in CODEC, from Dream S.A.S. France. Used as the synth chip in [[AMYboard]] and similar Eurorack/MIDI projects.

Split out of the monolithic PDF into linked notes:

## Hardware
- [[01-SAM2695-Overview]] — features, block diagram, typical config
- [[02-SAM2695-Pin-Description]] — pinout by function & by pin number, mechanical package
- [[03-SAM2695-Electrical-Characteristics]] — absolute max ratings, DC/DAC/ADC specs
- [[04-SAM2695-Timings]] — 8-bit parallel interface read/write timing
- [[05-SAM2695-Reset-Power-Down]] — reset sequence, pin states in power-down
- [[06-SAM2695-Reference-Circuits]] — crystal, line out, headphone out, mic in
- [[07-SAM2695-Board-Layout]] — layout rules (GND/decoupling/crystal/analog)

## Firmware / MIDI control
- [[08-SAM2695-Serial-Parallel-Modes]] — UART vs 8-bit parallel host interface
- [[09-SAM2695-NRPN-Messages]] — full NRPN control list (EQ, reverb/chorus routing, echo, spatial)
- [[10-SAM2695-Parallel-Controls]] — CONTROL-register byte commands (parallel mode)
- [[11-SAM2695-MIDI-Implementation]] — standard MIDI messages, RPN/NRPN/SysEx table
- [[12-SAM2695-Sounds-GM-MT32]] — GM program list + MT-32 variation bank
- [[13-SAM2695-Drum-Sets]] — channel 10 drum maps (Standard/Power/Brush/Orchestra/CM-64)
- [[14-SAM2695-Polyphony-Effects-Select]] — NRPN 375Fh bitfield, polyphony cost table
- [[15-SAM2695-Codec-Control-Sysex]] — raw port-write SysEx, codec control registers, gain tables
- [[16-SAM2695-Appendix]] — 2-voice instrument list, signal flow, spatial effect & echo diagrams

## Software / porting
- [[17-SAM2695-basicino-ESP-IDF-Breakdown]] — Seeed `SAM2695Synth` Arduino example dissected line-by-line, with raw MIDI byte equivalents and an ESP-IDF UART driver skeleton for porting off Arduino

## Quick reference
- Host interface: 8-bit parallel (D0-D7, A0, CS/, RD/, WR/, IRQ) **or** serial MIDI IN — see [[08-SAM2695-Serial-Parallel-Modes]]
- Master volume NRPN: `3707h` (0-7Fh) — see [[09-SAM2695-NRPN-Messages]]
- Reset all to power-up defaults: NRPN `375Fh` = `45h` — see [[14-SAM2695-Polyphony-Effects-Select]]
- Crystal: 12 MHz (XDIV tied to VD33) or 9.6 MHz (XDIV grounded), 22pF loading caps — see [[06-SAM2695-Reference-Circuits]]
- Write cycle time must be ≥ 3.5 µs — see [[04-SAM2695-Timings]]

## Source
Dream SAM2695 datasheet + user's manual, rev. June 22 2015, © Dream S.A.S. France. `info@dream.fr` / http://www.dream.fr

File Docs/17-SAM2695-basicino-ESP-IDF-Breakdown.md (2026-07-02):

---
tags: [firmware, sam2695, arduino, esp-idf, midi, port]
source: Seeed_Arduino_MIDIMaster / basic.ino
---

# SAM2695Synth `basic.ino` — Breakdown for ESP-IDF Porting

⬅ [[00-SAM2695-Index]]

This note dissects the Seeed `Seeed_Arduino_MIDIMaster` example (`basic.ino`) that talks to a SAM2695 chip (as used on the XIAO MIDI Synthesizer board), so it can be handed to an agent rewriting it against raw ESP-IDF instead of the Arduino framework. Byte-level MIDI details cross-reference [[11-SAM2695-MIDI-Implementation]] and [[09-SAM2695-NRPN-Messages]] in this vault.

## What the code actually does, in one sentence

It opens a **hardware UART at 31250 baud** (standard MIDI speed) wired to the SAM2695's `MIDI_IN` pin, and writes raw 2–3 byte MIDI messages to it — there is no other protocol magic. The `SAM2695Synth` class is a thin C++ wrapper that builds those bytes for you and calls `Serial.write()`.

## Line-by-line

```cpp
#include "SAM2695Synth.h"
```
Pulls in the Seeed library — a templated singleton class `SAM2695Synth<T>` where `T` is whatever serial class you're using (`HardwareSerial`, `SoftwareSerial`, `Uart`). The template exists purely so the same library source works across AVR/SAMD/RP2040/ESP32 boards with different serial implementations. **This whole templating concern disappears in ESP-IDF** — you'll just use the UART driver directly.

### The `#if defined(...)` block (lines 13–53)
This is board-detection boilerplate, not SAM2695-specific logic. It picks:
1. **Which serial peripheral** to hand to the synth (`COM_SERIAL`) — software serial on AVR/RP2040, hardware `Serial0` on ESP32-C3/C6/S3, `Serial1` on SAMD/nRF52.
2. **Which serial to use for debug/USB print** (`SHOW_SERIAL`).

For your ESP32 target, the relevant branch is:
```cpp
#if defined(CONFIG_IDF_TARGET_ESP32C3) || defined(CONFIG_IDF_TARGET_ESP32C6) || defined(CONFIG_IDF_TARGET_ESP32S3)
    #define COM_SERIAL Serial0
    #define SHOW_SERIAL Serial
    SAM2695Synth<HardwareSerial> synth = SAM2695Synth<HardwareSerial>::getInstance();
#endif
```
`Serial0` = ESP32's hardware UART0. On the XIAO MIDI Synthesizer board, UART0 TX is hard-wired on the PCB to the SAM2695's `MIDI_IN` pin (pin 16, per [[02-SAM2695-Pin-Description]]). **Note:** on ESP32-S3, Arduino's `Serial` (USB-CDC) and `Serial0` (real UART0) are separate peripherals — that's *why* this split exists. If you're on a custom board (not the XIAO Synth), you need to confirm which GPIO is physically wired to `MIDI_IN` and use that as your UART TX pin in ESP-IDF; don't assume it matches the XIAO's default.

Only **TX** matters here — this example never reads from the SAM2695 (no IRQ/status handling), so RX is unused/don't-care.

### `setup()`
```cpp
SHOW_SERIAL.begin(USB_SERIAL_BAUD_RATE);       // USB-CDC debug console, irrelevant to the synth
synth.begin(COM_SERIAL, MIDI_SERIAL_BAUD_RATE); // Opens UART0 at 31250 baud, 8N1 (standard MIDI)
synth.setInstrument(0, CHANNEL_0, unit_synth_instrument_t::GrandPiano_1);
delay(1000);
```
- `MIDI_SERIAL_BAUD_RATE` is a library constant = **31250** — the fixed MIDI spec baud rate. Non-negotiable; the SAM2695's serial MIDI IN expects exactly this.
- `synth.begin()` internally just does `serial.begin(baud, SERIAL_8N1)` (or equivalent) on the given port — 8 data bits, no parity, 1 stop bit.
- `synth.setInstrument(bank, channel, value)` sends **two** raw MIDI messages back-to-back:
  1. **Bank Select MSB**: `Bnh 00h bank` (Control Change 0)
  2. **Program Change**: `Cnh value` (where `value` = `GrandPiano_1` = program 0 in the library's 0-indexed enum, i.e. GM PC 1 — see [[12-SAM2695-Sounds-GM-MT32]])
  
  `n` = channel nibble. `CHANNEL_0` is a library constant = `0x00`.
- The 1000ms `delay()` just gives the SAM2695 time to finish its power-up init routine (datasheet: **≤500ms max** before audio is ready — see [[05-SAM2695-Reset-Power-Down]]) before the first note is sent. If your firmware brings up UART late enough after chip power-on, you may be able to shorten or drop this.

### `loop()`
```cpp
synth.setNoteOn(CHANNEL_0, NOTE_E4, VELOCITY_DEFAULT);
delay(1000);
synth.setNoteOff(CHANNEL_0, NOTE_E4);
delay(1000);
```
- `setNoteOn(channel, pitch, velocity)` → raw bytes `[0x90 | channel, pitch, velocity]` (Note On — see [[11-SAM2695-MIDI-Implementation]])
- `setNoteOff(channel, pitch)` → raw bytes `[0x80 | channel, pitch, 0x00]` (Note Off, velocity is don't-care per spec but the library sends 0)
- `NOTE_E4` is a library constant for MIDI note number 64 (E4, one octave+4 semitones above middle C=60)
- `VELOCITY_DEFAULT` is typically `0x64` (100) or `0x7F` (127) — check the header if exact value matters to you; functionally any 1–127 works

**That's the entire example.** No SysEx, no NRPN, no CC beyond bank-select — this is the simplest possible "make a sound" sketch.

## Raw MIDI byte cheat-sheet for this specific sketch

| Library call | Raw bytes sent | Meaning |
|---|---|---|
| `synth.begin(serial, 31250)` | *(none — just opens UART)* | UART0, 31250 baud, 8N1 |
| `synth.setInstrument(0, 0, GrandPiano_1)` | `B0 00 00`, `C0 00` | CC0 bank=0 on ch0, then Program Change 0 (GrandPiano_1) on ch0 |
| `synth.setNoteOn(0, 64, 100)` | `90 40 64` | Note On, ch0, note 64 (E4), velocity 100 |
| `synth.setNoteOff(0, 64)` | `80 40 00` | Note Off, ch0, note 64, velocity 0 |

(Hex above — bytes shown as sent on the wire, MSB nibble = status, low nibble = channel for the status bytes.)

## What an ESP-IDF port needs to do instead

Since ESP-IDF has no Arduino `Serial` object, you replace the whole `SAM2695Synth<T>` abstraction with:

1. **UART driver init** (`driver/uart.h`):
   ```c
   uart_config_t uart_config = {
       .baud_rate = 31250,
       .data_bits = UART_DATA_8_BITS,
       .parity    = UART_PARITY_DISABLE,
       .stop_bits = UART_STOP_BITS_1,
       .flow_ctrl = UART_HW_FLOWCTRL_DISABLE,
   };
   uart_param_config(UART_NUM_1, &uart_config);   // pick a free UART, not UART0 if that's your console
   uart_set_pin(UART_NUM_1, TX_GPIO, UART_PIN_NO_CHANGE, UART_PIN_NO_CHANGE, UART_PIN_NO_CHANGE);
   uart_driver_install(UART_NUM_1, 256, 0, 0, NULL, 0);
   ```
   `TX_GPIO` must be whatever pin your board wires to the SAM2695's `MIDI_IN` pin. RX/RTS/CTS can be `UART_PIN_NO_CHANGE` since you're not reading the SAM2695's IRQ/status line in this simple flow.

2. **Small helper functions** that mirror the library API 1:1, each just calling `uart_write_bytes()`:
   ```c
   void sam2695_note_on(uart_port_t port, uint8_t ch, uint8_t note, uint8_t vel) {
       uint8_t msg[3] = { 0x90 | (ch & 0x0F), note & 0x7F, vel & 0x7F };
       uart_write_bytes(port, (const char*)msg, 3);
   }

   void sam2695_note_off(uart_port_t port, uint8_t ch, uint8_t note) {
       uint8_t msg[3] = { 0x80 | (ch & 0x0F), note & 0x7F, 0x00 };
       uart_write_bytes(port, (const char*)msg, 3);
   }

   void sam2695_set_instrument(uart_port_t port, uint8_t bank, uint8_t ch, uint8_t program) {
       uint8_t bank_msg[3] = { 0xB0 | (ch & 0x0F), 0x00, bank & 0x7F };  // CC0 = bank select MSB
       uint8_t pc_msg[2]   = { 0xC0 | (ch & 0x0F), program & 0x7F };
       uart_write_bytes(port, (const char*)bank_msg, 3);
       uart_write_bytes(port, (const char*)pc_msg, 2);
   }
   ```

3. **Startup delay** — `vTaskDelay(pdMS_TO_TICKS(1000))` after `uart_driver_install()`, matching the datasheet's power-up timing.

4. **Optional but recommended:** if you also want the parallel-port status/IRQ handling, or want to hit the extra features (reverb/chorus/EQ/NRPN), those all go through the *same* UART using the messages catalogued in [[09-SAM2695-NRPN-Messages]] and [[10-SAM2695-Parallel-Controls]] — build them the same way (raw `uint8_t` arrays over `uart_write_bytes`). No parallel bus wiring is implied by this sketch; it only ever uses the serial MIDI path (see [[08-SAM2695-Serial-Parallel-Modes]] for why that's the SAM2695's default power-up state, so no mode-switch handshake is needed).

## Instructions for a coding agent

If you're prompting an agent to generate the ESP-IDF equivalent, give it:
- This file
- [[11-SAM2695-MIDI-Implementation]] (for the full standard MIDI + SysEx message table if they need more than note on/off/program change)
- The target GPIO number for UART TX → SAM2695 `MIDI_IN` (confirm from your board's schematic — **don't let the agent assume a XIAO default pin** unless you're literally using the stock XIAO MIDI Synthesizer board)
- Explicit constraint: **baud rate must be exactly 31250**, 8N1, and consecutive writes should respect the datasheet's minimum inter-message timing if driving the parallel bus (not relevant for pure serial MIDI, which has no documented minimum spacing beyond normal UART framing)

## Related
- [[11-SAM2695-MIDI-Implementation]]
- [[08-SAM2695-Serial-Parallel-Modes]]
- [[09-SAM2695-NRPN-Messages]]
- [[05-SAM2695-Reset-Power-Down]]
- [[02-SAM2695-Pin-Description]]

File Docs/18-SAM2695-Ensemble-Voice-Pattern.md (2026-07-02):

---
tags: [firmware, sam2695, midi, esp-idf, ensemble, agent-instructions]
---

# SAM2695 — "Ensemble Voice" Pattern (Broadcast Program Change, Omni Note Passthrough)

⬅ [[00-SAM2695-Index]]

**Context:** Each unit is a standalone SAM2695 module (see [[17-SAM2695-basicino-ESP-IDF-Breakdown]] for the base ESP-IDF UART wiring) receiving MIDI over BLE from an iOS sequencer (AUM). Several units are deployed around a room as an ensemble ("The Band"). Goal: physical buttons on each unit pick one instrument voice for that unit; the unit should then play that voice regardless of which MIDI channel the sequencer happens to send notes on, while channel 10 remains dedicated to drums.

## Background an agent needs before touching this code

The SAM2695 is a **16-channel multitimbral GM synth** — every MIDI channel (1–16) has its *own independent* instrument assignment, set via Bank Select (CC0) + Program Change, and that assignment persists until changed again. **Channel 10 is hardwired by GM/GS convention to be the drum/rhythm channel** — Program Change on channel 10 selects a drum *kit*, not a melodic instrument, and this is fixed firmware behavior in the chip (see [[13-SAM2695-Drum-Sets]]), not something caused by app/host config.

This means: if your sequencer (AUM) assigns different tracks to different MIDI channels — which is normal, expected multitimbral behavior — and your firmware only ever sends Program Change to one channel while notes arrive on others, **those other channels are still sitting on whatever patch they last had (GM default = Grand Piano at power-up)**. This looks like "buttons don't work" or "wrong instrument depending on channel," but it isn't a bug in the SAM2695 or the MIDI stack — it's a mismatch between the chip's per-channel model and the single "one voice per box" behavior this project wants.

## The fix: broadcast + omni passthrough

Don't try to remap/funnel incoming note channels (that was a false start — see below). Instead:

1. **On patch change (button press):** send the same Bank Select + Program Change to **all 15 melodic channels** (everything except channel 10). This makes every channel's stored instrument identical, so it no longer matters which channel a given note arrives on.
2. **On incoming Note On/Off, CC, pitch bend, aftertouch:** pass through **completely unmodified**, on whatever channel they arrived on. No remapping needed once step 1 is done.
3. **On incoming Program Change from the host (optional but recommended):** drop it. If AUM ever sends its own PC messages per track, letting them through would desync that one channel from the other 14 and reintroduce the original bug. The hardware buttons should be the sole source of truth for patch selection.
4. **Channel 10** is left alone by all of the above — it never gets touched by the broadcast, and (depending on your ensemble design, see "Decisions" below) may also be filtered out of note passthrough on units that shouldn't play drums.

### Why not "channel funnel" (remap every note to one fixed channel)?
That's a different, also-valid pattern (documented for comparison below) but it collapses all incoming tracks onto a single MIDI channel, which throws away the channel identity of notes. **Broadcast** is the better fit here because it keeps each channel's notes native (simpler passthrough, no rewriting per-message) and simply keeps all 15 channels tuned to the same patch. Use funnel only if you specifically need to force polyphony/voice-stealing behavior onto one literal channel for some other reason.

## Reference implementation (ESP-IDF, C)

```c
#include "driver/uart.h"

#define SAM_UART       UART_NUM_1   // whichever UART is wired to SAM2695 MIDI_IN
#define DRUM_CHANNEL   9            // 0-indexed MIDI channel 10

// --- Patch selection: call this from button handlers ---
// Sets the same instrument on all 15 melodic channels (channel 10 untouched).
void sam2695_set_ensemble_voice(uint8_t bank, uint8_t program) {
    for (uint8_t ch = 0; ch < 16; ch++) {
        if (ch == DRUM_CHANNEL) continue;

        uint8_t bank_msg[3] = { (uint8_t)(0xB0 | ch), 0x00, (uint8_t)(bank & 0x7F) };
        uint8_t pc_msg[2]   = { (uint8_t)(0xC0 | ch), (uint8_t)(program & 0x7F) };

        uart_write_bytes(SAM_UART, (const char*)bank_msg, 3);
        uart_write_bytes(SAM_UART, (const char*)pc_msg, 2);
    }
}

// --- Incoming MIDI from BLE (AUM) ---
// Notes/CC/pitchbend/aftertouch: pass through unmodified.
// Program Change from host: dropped, so it can't fight the button-selected voice.
// SysEx / system messages: pass through unmodified.
void handle_incoming_midi(const uint8_t *msg, size_t len) {
    if (len == 0) return;

    uint8_t status = msg[0];

    // System messages (0xF0-0xFF) have no channel nibble - always pass through
    if ((status & 0xF0) == 0xF0) {
        uart_write_bytes(SAM_UART, (const char*)msg, len);
        return;
    }

    uint8_t msg_type = status & 0xF0;

    // Swallow host-originated Program Change - buttons are the only patch source
    if (msg_type == 0xC0) return;

    // Everything else (Note On/Off, CC, Pitch Bend, Poly/Channel Aftertouch): passthrough as-is
    uart_write_bytes(SAM_UART, (const char*)msg, len);
}

// --- Call once at boot with your default/last-saved patch ---
// GM power-on default is Grand Piano on every channel; without this call,
// a freshly booted unit sits on piano until a button is pressed.
void sam2695_init_default_voice(void) {
    sam2695_set_ensemble_voice(0 /*bank*/, 0 /*GrandPiano_1*/);
}
```

## Decisions to make explicit per-unit (don't leave these implicit)

- **Should this unit play drums at all?** If a given box in the ensemble is melodic-only, filter out channel 10 entirely in `handle_incoming_midi` (`if ((status & 0x0F) == DRUM_CHANNEL) return;` after confirming it's a channel-voice message). If it should be a dedicated drum unit, consider the inverse — only pass channel 10 through, ignore everything else.
- **Persisting the selected voice across power cycles.** If you want a unit to remember its last-selected patch after a reboot (NVS/flash), store just the `(bank, program)` pair and call `sam2695_set_ensemble_voice()` with it in `sam2695_init_default_voice()` instead of hardcoding Grand Piano.
- **Button debounce.** Not shown above — make sure button presses are debounced before calling `sam2695_set_ensemble_voice()`, since a bouncing GPIO firing this function rapidly sends 15×2 = 30 MIDI messages per bounce.
- **Bank value.** All examples above use bank `0` (standard GM). If you want MT-32 variation sounds ([[12-SAM2695-Sounds-GM-MT32]]), that's selected differently (CC0=127 then PC) — not a bank-select in the GM sense — so don't conflate the two if you add that feature later.

## Related
- [[17-SAM2695-basicino-ESP-IDF-Breakdown]] — base UART setup this builds on
- [[11-SAM2695-MIDI-Implementation]] — raw message reference (Note On/Off, CC0, Program Change)
- [[13-SAM2695-Drum-Sets]] — why channel 10 is special
- [[12-SAM2695-Sounds-GM-MT32]] — instrument/program numbers for `sam2695_set_ensemble_voice()`

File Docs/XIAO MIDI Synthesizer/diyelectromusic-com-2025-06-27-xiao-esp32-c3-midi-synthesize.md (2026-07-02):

[Skip to content](https://diyelectromusic.com/2025/06/27/xiao-esp32-c3-midi-synthesizer-part-4/#content)



[Kevin](https://diyelectromusic.com/author/emalliab/)[Intermediate](https://diyelectromusic.com/category/project-difficulty/intermediate/), [Synth Modules](https://diyelectromusic.com/category/project-categories/synth-modules/)June 27, 2025June 29, 20254 Minutes

In [Part 2](https://diyelectromusic.com/2025/06/27/xiao-esp32-c3-midi-synthesizer-part-2/) I looked at how to add USB MIDI to the XIAO MIDI Synthesizer and in [Part 3](https://diyelectromusic.com/2025/06/27/xiao-esp32-c3-midi-synthesizer-part-3/) I looked at some of the properties of the SAM2695 synth chip itself. This post combines the two into a relatively simple, but playable, synth.

- [Part 1](https://diyelectromusic.com/2025/06/26/xiao-esp32-c3-midi-synthesizer/) – Getting started and getting code running.
- [Part 2](https://diyelectromusic.com/2025/06/27/xiao-esp32-c3-midi-synthesizer-part-2/) – Swapping the ESP32-C3 for a SAMD21 to get USB MIDI.
- [Part 3](https://diyelectromusic.com/2025/06/27/xiao-esp32-c3-midi-synthesizer-part-3/) – Taking a deeper look at the SAM2695 itself.
- [Part 4](https://diyelectromusic.com/2025/06/27/xiao-esp32-c3-midi-synthesizer-part-4/) – A USB MIDI Synth Module using the SAMD21 again as a USB MIDI Host.
- [Part 5](https://diyelectromusic.com/2025/06/28/xiao-esp32-c3-midi-synthesizer-part-5/) – A Serial MIDI Synth Module using the original ESP32-C3.
- [Part 6](https://diyelectromusic.com/2025/06/29/xiao-esp32-c3-midi-synthesizer-part-6/) – Pairs the Synth with a XIAO Expansion board to add display and potentiometers.

XIAO MIDI Synthesizer USB MIDI Host - MakerTube

Error details

_**Warning!** I strongly recommend using old or second hand equipment for your experiments.  I am not responsible for any damage to expensive instruments!_

These are the key tutorials for the main concepts used in this project:

- [Getting Started with the XIAO MIDI Synthesizer](https://wiki.seeedstudio.com/xiao_midi_synthesizer/)
- [XIAO SAMD21, Arduino and MIDI](https://diyelectromusic.com/2023/03/12/xiao-samd21-arduino-and-midi/)

If you are new to microcontrollers, see the [Getting Started](https://diyelectromusic.wordpress.com/getting-started/) pages.

### The Circuit

I’m wanting to plug a USB MIDI keyboard into my XIAO Synth, so I’m going to swap the XIAO ESP32-C3 out once again for a XIAO SAMD21 as described in [Part 2](https://diyelectromusic.com/2025/06/27/xiao-esp32-c3-midi-synthesizer-part-2/). A future post will go back and create a serial MIDI version using the unmodified XIAO Synth.

Recall that a source of 5V power is required, and below I’m just using the 5V USB passthrough from the original XIAO ESP32-C3.



There is one issue to watch out for in this kind of configuration. Depending on how the USB power is provided, there might not be a common ground point between the XIAO’s power and any audio amplification used.

Apparently GND is always passed through many USB charger blocks.

To prevent interference and noise, it may be necessary to ground the USB connection providing power.

### The Code

I’m using a combination of the SAMD21 USB Host Library “USB MIDI Converter” example and some GPIO and MIDI handling.

The general thread of the code will be as follows:

```
loop():
  Do any USB host processing (e.g. plug-and-play)
  IF USB MIDI messages received THEN
    Send to serial MIDI
  IF any buttons pressed THEN
    Handle button IO
    Generate any additional MIDI messages as required
    Send to serial MIDI
```

In particular it should be noted that the MIDI “listening” is one-way only USB to serial MIDI; and that any internal control events that generate MIDI are also only going one way – to serial MIDI.

The buttons will be used to do the following:

- Button 0 and 1: Program Select Up/Down
- Button 2 and 3: Channel Volume Up/Down

A much more sophisticated interface could be developed – e.g. using one of the buttons to change modes for the other buttons, to allow the selection of different things, but for now, this is plenty.

There are several layers to the code to allow this however, so I’ll cover them briefly here.

- Main Loop button IO: Checks for the main H->L, L->H, L->L, H->H events and calls functions for all but the last (buttons are pulled high so H->H means “nothing happening).
- Event functions for Pressed, Released, Hold which call program or volume handling functions as required.
- Program/volume handling functions that update the values and then trigger the appropriate MIDI messages to be sent.
- Functions to send a MIDI Program Change or Control Change message as required.

In the end I’ve only triggered events on button Pressed, so the Release and Hold functions don’t cause any further action to take place, but the model is there for use in the future if required.

Note: as I’m not using the Arduino MIDI Library, I just build PC or CC messages directly and call out to Serial1.Write as shown below.

```
void midiSendControl (uint8_t cmd, uint8_t d) {
  uint8_t buf[3];
  buf[0] = MIDI_CC | (MIDI_CHANNEL-1);
  buf[1] = cmd;
  buf[2] = d;
  Serial1.write(buf, 3);
}
```

Simple, but it works. Note PC are only two bytes in size not three.

If performance seems to be an issue, then I have a few things to adjust in the scheduling:

- I can split the digitalRead() of each button over several scans to allow MIDI processing to happen in between.
- I can switch to the XIAO equivalent of direct PORT IO to try to read all IO pins at the same time. I don’t know what this looks like for the SAMD21 however and it would make it hardware specific, so I’d really rather not do that.
- I can remove the waiting of 1mS. This was in the original USB converter, so I kept it in here too. I ought to measure the free running loop() time to see if it is needed.

[Find it on GitHub here](https://github.com/diyelectromusic/sdemp/tree/main/src/SDEMP/XIAOSynthUSBMIDIHost).

### Closing Thoughts

In the video I cycle through a few of the programs whilst controlling the synth from a keyboard.

At one point I remove the external audio connection (yes, I should have turned it down first!) to contrast the sound with the internal speaker. Yes, it is a bit “tinny” but it isn’t too bad.

This really is just the very “tip of the iceberg” given the whole range of parameters available that were mentioned in [Part 3](https://diyelectromusic.com/2025/06/27/xiao-esp32-c3-midi-synthesizer-part-3/).

Kevin

### Share this:

- [Share on X (Opens in new window)X](https://diyelectromusic.com/2025/06/27/xiao-esp32-c3-midi-synthesizer-part-4/?share=twitter&nb=1)
- [Share on Facebook (Opens in new window)Facebook](https://diyelectromusic.com/2025/06/27/xiao-esp32-c3-midi-synthesizer-part-4/?share=facebook&nb=1)

LikeLoading...

### _Related_

[XIAO ESP32-C3 MIDI Synthesizer – Part 2](https://diyelectromusic.com/2025/06/27/xiao-esp32-c3-midi-synthesizer-part-2/ "XIAO ESP32-C3 MIDI Synthesizer &#8211; Part&nbsp;2")June 27, 2025In "Intermediate"

[XIAO ESP32-C3 MIDI Synthesizer – Part 5](https://diyelectromusic.com/2025/06/28/xiao-esp32-c3-midi-synthesizer-part-5/ "XIAO ESP32-C3 MIDI Synthesizer &#8211; Part&nbsp;5")June 28, 2025In "Beginner"

[XIAO USB Device to Serial MIDI Converter](https://diyelectromusic.com/2025/06/28/xiao-usb-device-to-serial-midi-converter/ "XIAO USB Device to Serial MIDI&nbsp;Converter")June 28, 2025In "MIDI Control"

- Tagged
- [control change](https://diyelectromusic.com/tag/control-change/)
- [midi](https://diyelectromusic.com/tag/midi/)
- [program change](https://diyelectromusic.com/tag/program-change/)
- [SAM2695](https://diyelectromusic.com/tag/sam2695/)
- [samd21](https://diyelectromusic.com/tag/samd21/)
- [usb host](https://diyelectromusic.com/tag/usb-host/)
- [xiao](https://diyelectromusic.com/tag/xiao/)

Unknown's avatar

## Published by Kevin

Just another soul meandering my way around the Internet ... [View all posts by Kevin](https://diyelectromusic.com/author/emalliab/)

**Published** June 27, 2025June 29, 2025

### Leave a comment [Cancel reply](https://diyelectromusic.com/2025/06/27/xiao-esp32-c3-midi-synthesizer-part-4/\#respond)

Δ

- [Comment](https://diyelectromusic.com/2025/06/27/xiao-esp32-c3-midi-synthesizer-part-4/#respond)
- [Reblog](https://diyelectromusic.com/2025/06/27/xiao-esp32-c3-midi-synthesizer-part-4/)
- [Subscribe](https://diyelectromusic.com/2025/06/27/xiao-esp32-c3-midi-synthesizer-part-4/) [Subscribed](https://diyelectromusic.com/2025/06/27/xiao-esp32-c3-midi-synthesizer-part-4/)

  - [ Simple DIY Electronic Music Projects](https://diyelectromusic.com/)

Join 213 other subscribers

Sign me up

  - Already have a WordPress.com account? [Log in now.](https://wordpress.com/log-in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)

- - [ Simple DIY Electronic Music Projects](https://diyelectromusic.com/)
  - [Subscribe](https://diyelectromusic.com/2025/06/27/xiao-esp32-c3-midi-synthesizer-part-4/) [Subscribed](https://diyelectromusic.com/2025/06/27/xiao-esp32-c3-midi-synthesizer-part-4/)
  - [Sign up](https://wordpress.com/start/)
  - [Log in](https://wordpress.com/log-in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)
  - [Copy shortlink](https://wp.me/pc1YuP-4FZ)
  - [Report this content](https://wordpress.com/abuse/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)
  - [View post in Reader](https://wordpress.com/reader/blogs/177786911/posts/17979)
  - [Manage subscriptions](https://subscribe.wordpress.com/)
  - [Collapse this bar](https://diyelectromusic.com/2025/06/27/xiao-esp32-c3-midi-synthesizer-part-4/)

[Toggle photo metadata visibility](https://diyelectromusic.com/2025/06/27/xiao-esp32-c3-midi-synthesizer-part-4/#)[Toggle photo comments visibility](https://diyelectromusic.com/2025/06/27/xiao-esp32-c3-midi-synthesizer-part-4/#)

Loading Comments...

Write a Comment...

Email (Required)Name (Required)Website

%d

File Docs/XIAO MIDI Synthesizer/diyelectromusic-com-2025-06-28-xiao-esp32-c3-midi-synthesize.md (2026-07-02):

[Skip to content](https://diyelectromusic.com/2025/06/28/xiao-esp32-c3-midi-synthesizer-part-5/#content)



[Kevin](https://diyelectromusic.com/author/emalliab/)[Beginner](https://diyelectromusic.com/category/project-difficulty/beginner/), [Synth Modules](https://diyelectromusic.com/category/project-categories/synth-modules/)June 28, 2025June 29, 20252 Minutes

So I was somewhat guilty that I’d replaced the XIAO microcontroller in the last couple of parts to get USB MIDI, so in this one I put the original ESP32-C3 back in and now have a version of [Part 4](https://diyelectromusic.com/2025/06/27/xiao-esp32-c3-midi-synthesizer-part-4/) for serial MIDI.

- [Part 1](https://diyelectromusic.com/2025/06/26/xiao-esp32-c3-midi-synthesizer/) – Getting started and getting code running.
- [Part 2](https://diyelectromusic.com/2025/06/27/xiao-esp32-c3-midi-synthesizer-part-2/) – Swapping the ESP32-C3 for a SAMD21 to get USB MIDI.
- [Part 3](https://diyelectromusic.com/2025/06/27/xiao-esp32-c3-midi-synthesizer-part-3/) – Taking a deeper look at the SAM2695 itself.
- [Part 4](https://diyelectromusic.com/2025/06/27/xiao-esp32-c3-midi-synthesizer-part-4/) – A USB MIDI Synth Module using the SAMD21 again as a USB MIDI Host.
- [Part 5](https://diyelectromusic.com/2025/06/28/xiao-esp32-c3-midi-synthesizer-part-5/) – A Serial MIDI Synth Module using the original ESP32-C3.
- [Part 6](https://diyelectromusic.com/2025/06/29/xiao-esp32-c3-midi-synthesizer-part-6/) – Pairs the Synth with a XIAO Expansion board to add display and potentiometers.

XIAO MIDI Synthesizer Serial MIDI - MakerTube

Error details

_**Warning!** I strongly recommend using old or second hand equipment for your experiments.  I am not responsible for any damage to expensive instruments!_

These are the key tutorials for the main concepts used in this project:

- [Getting Started with the XIAO MIDI Synthesizer](https://wiki.seeedstudio.com/xiao_midi_synthesizer/)
- [XIAO SAMD21, Arduino and MIDI](https://diyelectromusic.com/2023/03/12/xiao-samd21-arduino-and-midi/)

If you are new to microcontrollers, see the [Getting Started](https://diyelectromusic.wordpress.com/getting-started/) pages.

### The Circuit

This goes back to adding a 3V3 compatible serial MIDI board using the XIAO GPIO breakout pins as described in [Part 1](https://diyelectromusic.com/2025/06/26/xiao-esp32-c3-midi-synthesizer/).

This is powered from 3V3 and GND and connected to D6/RX (which may or may not be GPIO 6).



### The Code

This is all the same code from [Part 4](https://diyelectromusic.com/2025/06/27/xiao-esp32-c3-midi-synthesizer-part-4/) but with the USB handling removed and the bespoke serial port writing replaced with calls into the Arduino MIDI Library using Serial0 as the MIDI device:

```
MIDI_CREATE_INSTANCE(HardwareSerial, Serial0, MIDI);

void midiSendProgram (uint8_t prog) {
  MIDI.sendProgramChange(prog, MIDI_CHANNEL);
}

void midiSendControl (uint8_t cmd, uint8_t d) {
  MIDI.sendControlChange(cmd, d, MIDI_CHANNEL);
}

void setup() {
  MIDI.begin(MIDI_CHANNEL);
  ...
}

void loop() {
  MIDI.read();
  ...
}
```

Once again I’m relying on the fact that the serial MIDI transport has an automatic MIDI THRU enabled between RX and TX.

[Find it on GitHub here](https://github.com/diyelectromusic/sdemp/tree/main/src/SDEMP/XIAOSynthSerialMIDI).

### Closing Thoughts

Whilst the USB MIDI host solution is a lot more convenient in terms of being able to plug in MIDI controllers, the serial MIDI version is a lot easier when it comes to programming and powering the device.

The video shows a PC streaming a MIDI file to the XIAO Synth whilst I’m changing volume and voice.

Kevin

### Share this:

- [Share on X (Opens in new window)X](https://diyelectromusic.com/2025/06/28/xiao-esp32-c3-midi-synthesizer-part-5/?share=twitter&nb=1)
- [Share on Facebook (Opens in new window)Facebook](https://diyelectromusic.com/2025/06/28/xiao-esp32-c3-midi-synthesizer-part-5/?share=facebook&nb=1)

LikeLoading...

### _Related_

[Other SAM2695 Synths](https://diyelectromusic.com/2025/07/15/other-sam2695-synths/ "Other SAM2695 Synths")July 15, 2025In "Beginner"

[XIAO ESP32-C3 MIDI Synthesizer – Part 2](https://diyelectromusic.com/2025/06/27/xiao-esp32-c3-midi-synthesizer-part-2/ "XIAO ESP32-C3 MIDI Synthesizer &#8211; Part&nbsp;2")June 27, 2025In "Intermediate"

[XIAO ESP32-C3 MIDI Synthesizer](https://diyelectromusic.com/2025/06/26/xiao-esp32-c3-midi-synthesizer/ "XIAO ESP32-C3 MIDI&nbsp;Synthesizer")June 26, 2025In "Beginner"

- Tagged
- [control change](https://diyelectromusic.com/tag/control-change/)
- [midi](https://diyelectromusic.com/tag/midi/)
- [program change](https://diyelectromusic.com/tag/program-change/)
- [SAM2695](https://diyelectromusic.com/tag/sam2695/)
- [xiao](https://diyelectromusic.com/tag/xiao/)

Unknown's avatar

## Published by Kevin

Just another soul meandering my way around the Internet ... [View all posts by Kevin](https://diyelectromusic.com/author/emalliab/)

**Published** June 28, 2025June 29, 2025

### Leave a comment [Cancel reply](https://diyelectromusic.com/2025/06/28/xiao-esp32-c3-midi-synthesizer-part-5/\#respond)

Δ

- [Comment](https://diyelectromusic.com/2025/06/28/xiao-esp32-c3-midi-synthesizer-part-5/#respond)
- [Reblog](https://diyelectromusic.com/2025/06/28/xiao-esp32-c3-midi-synthesizer-part-5/)
- [Subscribe](https://diyelectromusic.com/2025/06/28/xiao-esp32-c3-midi-synthesizer-part-5/) [Subscribed](https://diyelectromusic.com/2025/06/28/xiao-esp32-c3-midi-synthesizer-part-5/)

  - [ Simple DIY Electronic Music Projects](https://diyelectromusic.com/)

Join 213 other subscribers

Sign me up

  - Already have a WordPress.com account? [Log in now.](https://wordpress.com/log-in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)

- - [ Simple DIY Electronic Music Projects](https://diyelectromusic.com/)
  - [Subscribe](https://diyelectromusic.com/2025/06/28/xiao-esp32-c3-midi-synthesizer-part-5/) [Subscribed](https://diyelectromusic.com/2025/06/28/xiao-esp32-c3-midi-synthesizer-part-5/)
  - [Sign up](https://wordpress.com/start/)
  - [Log in](https://wordpress.com/log-in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)
  - [Copy shortlink](https://wp.me/pc1YuP-4Gn)
  - [Report this content](https://wordpress.com/abuse/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)
  - [View post in Reader](https://wordpress.com/reader/blogs/177786911/posts/18003)
  - [Manage subscriptions](https://subscribe.wordpress.com/)
  - [Collapse this bar](https://diyelectromusic.com/2025/06/28/xiao-esp32-c3-midi-synthesizer-part-5/)

[Toggle photo metadata visibility](https://diyelectromusic.com/2025/06/28/xiao-esp32-c3-midi-synthesizer-part-5/#)[Toggle photo comments visibility](https://diyelectromusic.com/2025/06/28/xiao-esp32-c3-midi-synthesizer-part-5/#)

Loading Comments...

Write a Comment...

Email (Required)Name (Required)Website

%d

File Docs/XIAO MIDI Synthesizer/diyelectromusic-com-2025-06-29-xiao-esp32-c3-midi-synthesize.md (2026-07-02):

[Skip to content](https://diyelectromusic.com/2025/06/29/xiao-esp32-c3-midi-synthesizer-part-6/#content)



[Kevin](https://diyelectromusic.com/author/emalliab/)[Beginner](https://diyelectromusic.com/category/project-difficulty/beginner/), [MIDI Control](https://diyelectromusic.com/category/project-categories/midi-control/), [Synth Modules](https://diyelectromusic.com/category/project-categories/synth-modules/)June 29, 2025June 29, 20255 Minutes

Expanding on my previous posts, I thought it might be interesting to see how I might be able to add some additional IO to the MIDI Synth. This is an exploration of some options there.

- [Part 1](https://diyelectromusic.com/2025/06/26/xiao-esp32-c3-midi-synthesizer/) – Getting started and getting code running.
- [Part 2](https://diyelectromusic.com/2025/06/27/xiao-esp32-c3-midi-synthesizer-part-2/) – Swapping the ESP32-C3 for a SAMD21 to get USB MIDI.
- [Part 3](https://diyelectromusic.com/2025/06/27/xiao-esp32-c3-midi-synthesizer-part-3/) – Taking a deeper look at the SAM2695 itself.
- [Part 4](https://diyelectromusic.com/2025/06/27/xiao-esp32-c3-midi-synthesizer-part-4/) – A USB MIDI Synth Module using the SAMD21 again as a USB MIDI Host.
- [Part 5](https://diyelectromusic.com/2025/06/28/xiao-esp32-c3-midi-synthesizer-part-5/) – A Serial MIDI Synth Module using the original ESP32-C3.
- [Part 6](https://diyelectromusic.com/2025/06/29/xiao-esp32-c3-midi-synthesizer-part-6/) – Pairs the Synth with a XIAO Expansion board to add display and potentiometers.



_**Warning!** I strongly recommend using old or second hand equipment for your experiments.  I am not responsible for any damage to expensive instruments!_

These are the key tutorials for the main concepts used in this project:

- [Getting Started with the XIAO MIDI Synthesizer](https://wiki.seeedstudio.com/xiao_midi_synthesizer/)
- [XIAO SAMD21, Arduino and MIDI](https://diyelectromusic.com/2023/03/12/xiao-samd21-arduino-and-midi/)
- [XIAO SAMD21, Arduino and MIDI – Part 6](https://diyelectromusic.com/2023/04/11/xiao-samd21-arduino-and-midi-part-6/)

If you are new to microcontrollers, see the [Getting Started](https://diyelectromusic.wordpress.com/getting-started/) pages.

### The Synth Grove Connector

One option to immediately explore for me was the Grove connector on the Synth – highlighted by the blue rectangle in the photo below. I’m thinking at this stage of the XIAO Expander Module ( [more here](https://diyelectromusic.com/2023/04/11/xiao-samd21-arduino-and-midi-part-6/)) and how that might give some options for easily hooking up to the Synth.



There one obvious issue with this, and one not so obvious issue.

First, of course, there is no access to this connector through the case. My initial thought was to simply remove the PCB from the case and use it as a stand-alone board. On initial inspection it seemed that there were two screws holding it down. Not so, a more thorough inspection (after remove the two screws and still not being able to remove it), revealed a third screw underneath the “light pipe” for the LEDs.

Unfortunately that light pipe is pretty well wedged into the case making removal particularly tricky. But without removing the light pipe, it isn’t possible to get to the screw at all.

I did wonder about making a hole in the 3D printed case. A better option might be to get hold of the published 3D print files and add a hole and make my own (they are available via the product page).

But both options would probably end up changing the original case somehow – even if printing my own, I still need to get the original PCB out somehow and that brings me back to the light pipe issue.

The second issue isn’t quite so obvious. In that photo we can see that the pins for the Grove connector are labelled as follows (top to bottom):

- NC
- TX
- 5V
- GND

The UART on the XIAO expander board, which I’d like to use, is labelled:

- RX7
- TX6
- 3V3
- GND

Checking in with the Synth schematic, the connector is wired as follows:



SYS\_MIDI connects to the MIDI\_IN pin of the SAM2695, so actually connecting “TX to TX” in this instance should be ok.

5V might be an issue though, as it really does look like (to me) that it really means 5V – it is the input to the TPL740F33 that generates the 3V3 power signal, as well as feeding the amplifier directly. The datasheet of the TPL740F33 does seem to imply that if receiving 3V3 it can still generate 3V3 so it might be ok? The amplifier obviously won’t be as powerful though running off 3V3.

Anyway, for now, instead I’ve just opted to use the GPIO again, wired into the expansion sockets with the XIAO removed.

At the XIAO expander end, I’ve used the additional pins rather than the Grove connector, as they support a 5V output.



The downsides to this approach:

- I’m not using the Grove connectors, which would have been really neat.
- I have no access to the four buttons on the XIAO MIDI Synth.

But I do now have access to two I2C Grove connectors, a GPIO Grove, and the RX part of the UART Grove too as well as the on-board display.

If a XIAO SAMD21 is used, then the previous code for USB to the Synth can be used directly – see [XIAO ESP32-C3 MIDI Synthesizer – Part 2](https://diyelectromusic.com/2025/06/27/xiao-esp32-c3-midi-synthesizer-part-2/).

If the XIAO ESP32-C3 is used, then an additional serial MIDI connection is required. This can be connected to the Grove UART connector (using the RX pin, and leaving TX unconnected) or the RX pin of the additional 8-way pin header on the expansion board. Then the code from this will work directly: [XIAO ESP32-C3 MIDI Synthesizer – Part 5](https://diyelectromusic.com/2025/06/28/xiao-esp32-c3-midi-synthesizer-part-5/).

### Adding a Display and Program Control

I already have some code that has done this for a XIAO on an expansion board here [XIAO SAMD21, Arduino and MIDI – Part 6](https://diyelectromusic.com/2023/04/11/xiao-samd21-arduino-and-midi-part-6/).

But for this to work usefully with the Synth module, I need to adjust the routing so that MIDI goes from USB to serial, but the program change messages are also sent via serial to the synth module. That has already been address in previous parts, to I just need to merge the code with that from [XIAO ESP32-C3 MIDI Synthesizer – Part 4](https://diyelectromusic.com/2025/06/27/xiao-esp32-c3-midi-synthesizer-part-4/).

This is the result.



There is a bit of jitter on the analog pot, but that is only because I’m using the original fairly simplified algorithm to detect changes. If I was fussed about it, I’d reuse the averaging class from [Arduino MIDI Atari Paddles](https://diyelectromusic.com/2025/06/23/arduino-midi-atari-paddles/). And to be honest, a capacitor on the pot would probably go quite a long way too…

As a test, I also powered the device from the Grove UART port connecting it as follows:

- Expander GND – GND Synth
- Expander 3V3 – 5V IN Synth
- Expander TX – RX/D6 Synth
- Expander RX – N/C

And this all worked fine. So I think a Grove to Grove lead would work fine if I had access to the Synth’s Grove port.

This does mean that the exact same code can work with the M5 Synth module using a Grove to Grove lead. The downside of this, even though it is a lot simpler in connectivity terms, is that there is now external audio out like there is on the XIAO Synth.



For completeness the same code can be used with the XIAO ESP32-C3 and serial MIDI, see the photo at the start of this blog.

To turn off all USB handling in the code, the following must be commented out:

```
//#define HAS_USB
//#define SER_TO_USB
//#define MIDI_USB_PCCC
```

For other parts of the code, the Arduino abstraction for A0 maps over to the ESP32-C3 fine. The only thing to watch out for is the increased analog resolution from 10 to 12 bits, but a call to analogReadResolution(10) drops that back to the expected 10 bits.

Oh and the Serial port to use is different:

- XIAO SAMD21: Serial1
- XIAO ESP32-C3: Serial0

[Find it on GitHub here](https://github.com/diyelectromusic/sdemp/tree/main/src/SDEMP/XiaoSynthMIDIPCCC).

### Closing Thoughts

If I can be bothered, it would be nice to actually display the General MIDI voice name on the display. The SAM2695 also has its MT-32 mode, so having some means of selecting that might be interesting too.

And so far I’ve largely only messed about with driving it on a single MIDI channel, so there is a lot more that could be done there.

Kevin

### Share this:

- [Share on X (Opens in new window)X](https://diyelectromusic.com/2025/06/29/xiao-esp32-c3-midi-synthesizer-part-6/?share=twitter&nb=1)
- [Share on Facebook (Opens in new window)Facebook](https://diyelectromusic.com/2025/06/29/xiao-esp32-c3-midi-synthesizer-part-6/?share=facebook&nb=1)

LikeLoading...

### _Related_

[XIAO ESP32-C3 MIDI Synthesizer – Part 2](https://diyelectromusic.com/2025/06/27/xiao-esp32-c3-midi-synthesizer-part-2/ "XIAO ESP32-C3 MIDI Synthesizer &#8211; Part&nbsp;2")June 27, 2025In "Intermediate"

[XIAO ESP32-C3 MIDI Synthesizer – Part 5](https://diyelectromusic.com/2025/06/28/xiao-esp32-c3-midi-synthesizer-part-5/ "XIAO ESP32-C3 MIDI Synthesizer &#8211; Part&nbsp;5")June 28, 2025In "Beginner"

[XIAO USB Device to Serial MIDI Converter](https://diyelectromusic.com/2025/06/28/xiao-usb-device-to-serial-midi-converter/ "XIAO USB Device to Serial MIDI&nbsp;Converter")June 28, 2025In "MIDI Control"

- Tagged
- [control change](https://diyelectromusic.com/tag/control-change/)
- [esp32c3](https://diyelectromusic.com/tag/esp32c3/)
- [midi](https://diyelectromusic.com/tag/midi/)
- [program change](https://diyelectromusic.com/tag/program-change/)
- [SAM2695](https://diyelectromusic.com/tag/sam2695/)
- [samd21](https://diyelectromusic.com/tag/samd21/)
- [usb midi](https://diyelectromusic.com/tag/usb-midi/)
- [xiao](https://diyelectromusic.com/tag/xiao/)

Unknown's avatar

## Published by Kevin

Just another soul meandering my way around the Internet ... [View all posts by Kevin](https://diyelectromusic.com/author/emalliab/)

**Published** June 29, 2025June 29, 2025

## 3 thoughts on “XIAO ESP32-C3 MIDI Synthesizer – Part 6”

1. [@diyelectromusic.com](https://diyelectromusic.com/@diyelectromusic.com) since I've lost track of where this was going, I can only commend the byzantine heights it's attaining 🙂 Makes my MI porting efforts look pedestrian. (ducks'n'runs)

[Like](https://diyelectromusic.com/2025/06/29/xiao-esp32-c3-midi-synthesizer-part-6/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) Liked by [1 person](https://diyelectromusic.com/2025/06/29/xiao-esp32-c3-midi-synthesizer-part-6/#)

[Reply as](https://diyelectromusic.com/2025/06/29/xiao-esp32-c3-midi-synthesizer-part-6/)

Reply on the Fediverse

## Remote Reply

#### Original Comment URL

Paste the comment URL into the search field of your favorite open social app or platform.

Comment URL Copy

#### Your Profile

Or, if you know your own profile, we can start things that way! Why do I need to enter my profile?

This site is part of the ⁂ open social web, a network of interconnected social platforms (like Mastodon, Pixelfed, Friendica, and others). Unlike centralized social media, your account lives on a platform of your choice, and you can interact with people across different platforms.

By entering your profile, we can send you to your account where you can complete this action.

Your Fediverse profile ReplyLoading…

Save my profile for future comments.

1. I do like the idea that you imagine there was any kind of direction to begin with 🙂

      I’m just messing around, as usual!

      Kevin

      [Like](https://diyelectromusic.com/2025/06/29/xiao-esp32-c3-midi-synthesizer-part-6/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) Like

      [Reply](https://diyelectromusic.com/2025/06/29/xiao-esp32-c3-midi-synthesizer-part-6/?replytocom=3955#respond)
2. [@diyelectromusic.com](https://diyelectromusic.com/@diyelectromusic.com) I had not heard of the SAM2695. Thanks for pointing it out. I think M5Stack missed a trick by not including a headphone jack in their module.

[Like](https://diyelectromusic.com/2025/06/29/xiao-esp32-c3-midi-synthesizer-part-6/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) Liked by [1 person](https://diyelectromusic.com/2025/06/29/xiao-esp32-c3-midi-synthesizer-part-6/#)

[Reply as](https://diyelectromusic.com/2025/06/29/xiao-esp32-c3-midi-synthesizer-part-6/)

Reply on the Fediverse

## Remote Reply

#### Original Comment URL

Paste the comment URL into the search field of your favorite open social app or platform.

Comment URL Copy

#### Your Profile

Or, if you know your own profile, we can start things that way! Why do I need to enter my profile?

This site is part of the ⁂ open social web, a network of interconnected social platforms (like Mastodon, Pixelfed, Friendica, and others). Unlike centralized social media, your account lives on a platform of your choice, and you can interact with people across different platforms.

By entering your profile, we can send you to your account where you can complete this action.

Your Fediverse profile ReplyLoading…

Save my profile for future comments.

### Leave a comment [Cancel reply](https://diyelectromusic.com/2025/06/29/xiao-esp32-c3-midi-synthesizer-part-6/\#respond)

Δ

- [Comment](https://diyelectromusic.com/2025/06/29/xiao-esp32-c3-midi-synthesizer-part-6/#comments)
- [Reblog](https://diyelectromusic.com/2025/06/29/xiao-esp32-c3-midi-synthesizer-part-6/)
- [Subscribe](https://diyelectromusic.com/2025/06/29/xiao-esp32-c3-midi-synthesizer-part-6/) [Subscribed](https://diyelectromusic.com/2025/06/29/xiao-esp32-c3-midi-synthesizer-part-6/)

  - [ Simple DIY Electronic Music Projects](https://diyelectromusic.com/)

Join 213 other subscribers

Sign me up

  - Already have a WordPress.com account? [Log in now.](https://wordpress.com/log-in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)

- - [ Simple DIY Electronic Music Projects](https://diyelectromusic.com/)
  - [Subscribe](https://diyelectromusic.com/2025/06/29/xiao-esp32-c3-midi-synthesizer-part-6/) [Subscribed](https://diyelectromusic.com/2025/06/29/xiao-esp32-c3-midi-synthesizer-part-6/)
  - [Sign up](https://wordpress.com/start/)
  - [Log in](https://wordpress.com/log-in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)
  - [Copy shortlink](https://wp.me/pc1YuP-4GX)
  - [Report this content](https://wordpress.com/abuse/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)
  - [View post in Reader](https://wordpress.com/reader/blogs/177786911/posts/18039)
  - [Manage subscriptions](https://subscribe.wordpress.com/)
  - [Collapse this bar](https://diyelectromusic.com/2025/06/29/xiao-esp32-c3-midi-synthesizer-part-6/)

[Toggle photo metadata visibility](https://diyelectromusic.com/2025/06/29/xiao-esp32-c3-midi-synthesizer-part-6/#)[Toggle photo comments visibility](https://diyelectromusic.com/2025/06/29/xiao-esp32-c3-midi-synthesizer-part-6/#)

Loading Comments...

Write a Comment...

Email (Required)Name (Required)Website

%d

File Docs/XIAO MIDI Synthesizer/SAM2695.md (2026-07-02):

## SAM2695

## LOW POWER SINGLE CHIP SYNTHESIZER
## WITH EFFECTS AND BUILT-IN CODEC

 Single chip all-in-one design.
o   MIDI control processor, serial and parallel interface
o   Synthesis, General MIDI wavetable implementation
o   General MIDI compatible effects: reverb + chorus
o   Spatial   Effect
o   4-band stereo equalizer
o   Stereo DAC. DR: 86dB typ, THD+N: -75dB typ
o   Mike input. DR: 86dB typ, THD+N: -75dB typ
o   Mike   echo

 State of the art synthesis for best quality/price products
o   64-voice polyphony (without effects)
o   38-voice polyphony + effects
o   On-chip CleanWave™ wavetable data, firmware, RAM delay lines

 Audio stereo line output.

 Typical applications: battery operated musical keyboards, portable phones,
karaokes.

 QFN48 (6 x 6mm) package: small footprint, small pin count

 Low power
o   18 mA typ Operating / 17 μA typ Power down
o   Single 3.3V power supply

## MIDI IN

## Audio
## Out
Typical hardware configuration

## SAM2695
Parallel MIDI

Cited trademarks belong to their respective owners, General MIDI logo under license of MIDI Manufacturers Association
© 2013-2014 DREAM S.A.S. FRANCE - All rights reserved

## 2
## SAM2695

## 1- PIN DESCRIPTION

1-1- PINS BY FUNCTION – 48-lead QFN Package
- 5VT indicates a 5 volt tolerant Input or I/O pin.
-  DR4,  DR8 indicates driving capability at VOL, VOH (see § 4- D.C. CHARACTERISTICS)

Power supply group

Pin name Pin # Type Description
## GND 9, 13, 18, 25,
## 36, 45, 48
## PWR    DIGITAL    GROUND
All pins should be connected to a ground plane
GND                   exposed                   die
pad
## PWR    DIGITAL    GROUND
Ground supply; down bonded to the exposed die pad (heatsink).
It is recommended, but not obligatory, to connect this pad to a
ground plane during PCB layout
## VD33 8, 11, 20, 31,
## 35, 41, 46
PWR    PERIPHERY POWER SUPPLY (+2.7V to 3.6V)
All VD33 pins should be returned to nominal +3.3V.
AGND                4                PWR                ANALOG                GROUND
This pin should be connected to an analog ground plane
## VA33 6 PWR    CODEC PERIPHERY ANALOG SUPPLY
This pin should be connected to a nominal 3.3V power through a
serial inductor filter (better result) or a 10 ohm resistor.

Serial MIDI, parallel MIDI

Pin name Pin # Type Description
MIDI_IN              16              IN-5VT  Serial  TTL  MIDI  IN.  Connected  to  the  built-in  synthesizer  at
power-up. This pin has a built-in pull up. It should be left open or
tied HIGH if not used.
## D0-D7                24,                26-30,
## 32, 33
## I/O
## -5VT-DR8
8-bit data bus to host processor.
Information on these pins is parallel MIDI
A0                      10                      IN-5VT  Select  data(0)  or  control(1)  for  write,  data(0)  or  status(1)  for
read.
CS/                     14                     IN-5VT  Chip  select,  active  low.  This  pin  has  a  built-in  pull  up.  It  should
be left unconnected if not used.
RD/                     15                     IN-5VT  Read,  active  low.  When  CS/  and  RD/  are  low,  data  (A0=0)  or
status (A0=1) is read on D0-D7. Read data is acknowledged on
the rising edge of RD/.
WR/                    12                    IN-5VT  Write,  active  low.  When  CS/  and  WR/  are  low,  data  (A0=0)  or
control (A0=1) is written from the D0-D7 bus to the SAM2695 on
the rising edge of WR/.
IRQ                    42                    OUT-DR4  A rising edge indicates that a MIDI byte is available for read on
D0-D7. Acknowledged by reading the byte.

Analog audio group

Pin name Pin # Type Description
MICIN 7 IN Analog microphone input.
AOUTL 1 OUT Left channel audio line or headphones output
AOUTR 2 OUT Right channel audio line or headphones output
VCM 5 OUT Analog common-mode voltage. Should be stabilized by external
capacitors 10μF // 100nF to AGND.
VCMHPOUT 3 OUT Analog headphones common-mode voltage buffer output.

## 3
## SAM2695

Miscellaneous group

Pin name Pin # Type Description
RST/PD/             38             IN-5VT    Master reset and Power down. Schmitt trigger input.
RST/PD/ should be held low during at least 10ms after power is
applied.
On the rising edge of RST/PD/ the chip enters its initialization
routine.
When  RST/PD/  is  low,  Power-down  is  active:  8-bit  port  data
lines are High-Z. IRQ is set to 0. The PLL is stopped and supply
voltage  is  removed  from  analog  and  digital  core.  To  exit  from
power down, RST/PD/ must be set to VD33.
X1-X2  39,  40  -  9.6  MHz  or  12  MHz  crystal  connection.  An  external  clock  can
also be used on X1.
XDIV 47 IN System clock divider.
- When grounded, it allows using 9.6MHz crystal
- When connected to VD33, it allows using 12MHz crystal
OUTVC12  34  PWR     3.3V  to  1.2  V  regulator  output.  The  built-in  regulator  gives  1.2V
for internal use only (core supply).
4.7μF   or   10μF   Decoupling   capacitor   must   be   connected
between OUTVC12 and GND.
TEST 37 IN Test pin with a built-in pull-down. It should be grounded or left
open for normal operation.
## NC 17, 19, 21-23;
## 43, 44
- Not connected pins.

1-2- PINOUT BY PIN # - 48-lead QFN Package

Pin# Signal Name Pin# Signal Name Pin#Signal Name Pin# Signal Name
## 1         AOUTL         13
## GND
## 25
## GND
## 37       TEST
## 2         AOUTR         14         CS/ 26        D1        38        RST/PD/
3         VCMHPOUT          15         RD/         27         D2         39         X1
## 4
## AGND
## 16         MIDI_IN         28         D3         40         X2
## 5         VCM         17         NC         29         D4         41
## VD33
## 6
## VA33
## 18
## GND
## 30        D5        42        IRQ
## 7         MICIN         19         NC         31
## VD33
## 43       NC
## 8
## VD33
## 20
## VD33
## 32        D6        44        NC
## 9
## GND
## 21         NC         33         D7         45
## GND
## 10       A0 22         NC         34         OUTVC12         46
## VD33
## 11
## VD33
## 23         NC         35
## VD33
## 47       XDIV
## 12       WR/ 24         D0         36
## GND
## 48
## GND

## 4
## SAM2695
1-3- MECHANICAL DIMENSIONS – 48-lead MQFN Package

## ZI
21140 Semur-en-Auxois
## FRANCE
## TITLE
48 LD MQFN (6x6mm) Package Outline
L/F Material: A194 FH

Package designation

## MQFN48
## REV.

## 5
## SAM2695

## 1-4- MARKING

## SAM2695
## FRANCE
## YYWW
## XXXXX-XXX
## •

## Pin 1

## 6
## SAM2695

2- ABSOLUTE MAXIMUM RATINGS (All voltages with respect to 0V, GND=0V)*

## Parameter Symbol Min Typ Max Unit
Temperature under bias - -55 - +125 °C
Storage temperature - -65 - +150 °C
Voltage on any 5 volt tolerant pin (5VT)                            -                            -0.3                            -                            5.5                            V
Voltage on any non-5 volt tolerant pin - -0.3 - VD33+0.3 V
Supply voltage (I/O) VD33 -0.3 - 3.6 V
Supply voltage (CODEC analog 3.3V) VA33 -0.3 - 3.6 V

*NOTICE: Stresses beyond those listed under “Absolute Maximum Ratings” may cause permanent damage to
the  device.  This  is  a  stress  rating  only  and  functional  operation  of  the  device  at  these  or  any  other  conditions
beyond  those  indicated  in  the  operational  sections  of  this  specification  is  not  implied.  Exposure  to  absolute
maximum rating conditions for extended periods may affect device reliability.

## 3- RECOMMENDED OPERATING CONDITIONS

## Parameter Symbol Min Typ Max Unit
Digital supply voltage VD33 2.7 3.3 3.6 V
Analog supply voltage (CODEC) VA33 2.7 3.3 3.6 V
Operating ambient temperature tA -25 - +70 °C

## 4- D.C. CHARACTERISTICS
(TA=25°C, VD33=3.3V, X1=12 MHz, AOUTL/AOUTR load = 47kΩ)

## Parameter Symbol Min Typ Max Unit
Low level input voltage VIL - - 0.8 V
High level input voltage on 5VT pins VIH 2 - - V
High level input voltage on non 5VT pins VIH 2 - - V
Low level output voltage  at IOL = IOHL Min VOL - - 0.4 V
High level output voltage at IOH = IOHL Min VOH 2.4 - - V
Schmitt-trigger negative-to-threshold voltage VTN 0.8 1.1 - V
Schmitt-trigger positive-to-threshold voltage VTP - 1.6 2 V
Driving capability at VOL, VOH for DR4 pins IOHL - - 4 mA
Driving capability at VOL, VOH for DR8 pins IOHL -  8 mA
Input leakage current IIN -10 ±1 10 μA
OUTVC12 output voltage VD12 1.14 1.2 1.26 V
Digital power supply current  ID33 - 10 - mA
Analog power supply current  IA33 - 8 - mA
Power down supply current - - 17 - μA
Pull-up, Pull-down or Keeper resistor Rudk 30 75 190 kΩ

## 7
## SAM2695
## 5- DAC. CHARACTERISTICS
## (TA=25°C, VA33=3.3V)

## Parameter Symbol Min Typ Max Unit
## Total Harmonic Distortion + Noise
(at - 6 dB)
THD + N - -75 - dB
Dynamic Range (-60dBFS with A-Weighted)                  DR                  -                   86                   -                  dB
Inter-channel isolation (1kHz) - 89 - - dB
Full-scale output voltage - - 0.85*VA33 - Vpp
VCM Maximum allowable DC current source - - - 0.1 mA
VCM Reference voltage
(with 10μF and 100nF capacitors)
## - VA33 ÷ 2
– 50mV
## VA33 ÷ 2 VA33 ÷ 2
+ 50mV
## V
## Output Gain Control
- 1dB steps
- Additional setting 1
- Additional setting 2
## -
## -40
## -43.5
## -58.5

## +6

dB
dB
dB
Maximum output power in Headphones mode -  30  mW

## 6- ADC. CHARACTERISTICS
## (TA=25°C, VA33 = 3.3V)

## Parameter Symbol Min Typ Max Unit
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

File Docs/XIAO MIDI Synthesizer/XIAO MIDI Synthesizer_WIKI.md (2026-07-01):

# Getting Started with XIAO MIDI Synthesizer

URL: https://wiki.seeedstudio.com/xiao_midi_synthesizer/



[**Get One Now 🖱️**](https://www.seeedstudio.com/XIAO-MIDI-Synthesizer-p-6462.html)

## Introduction
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

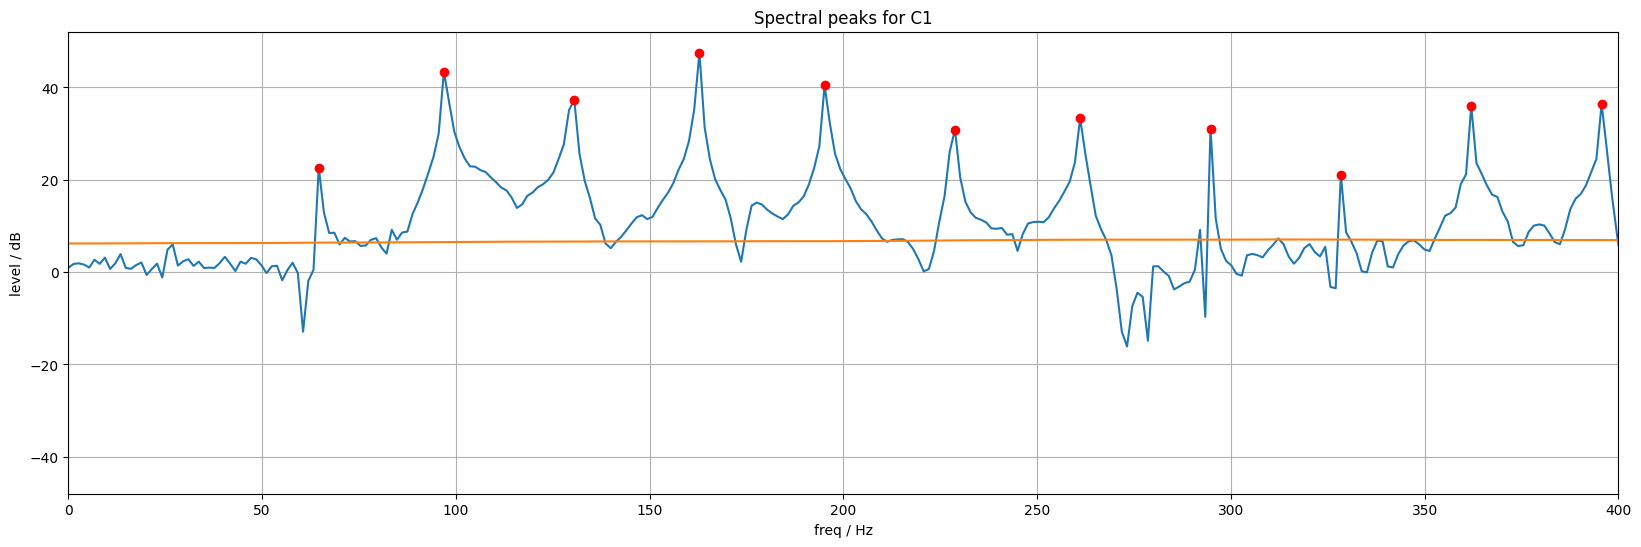
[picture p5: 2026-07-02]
Docs/AmyBoard/amy-main/docs/spectralpeaks.png

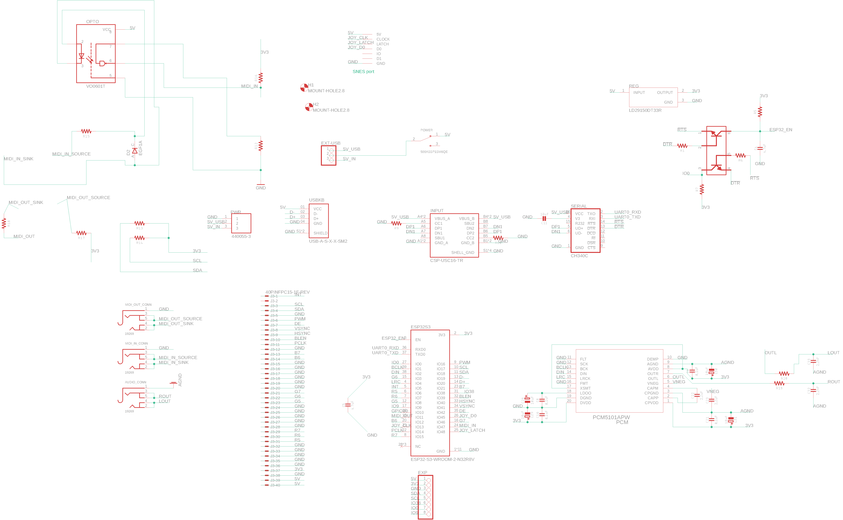
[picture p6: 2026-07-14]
Docs/Amyboard/tulipcc-main/docs/pcbs/tulip4_board_v4r8/schematic.png

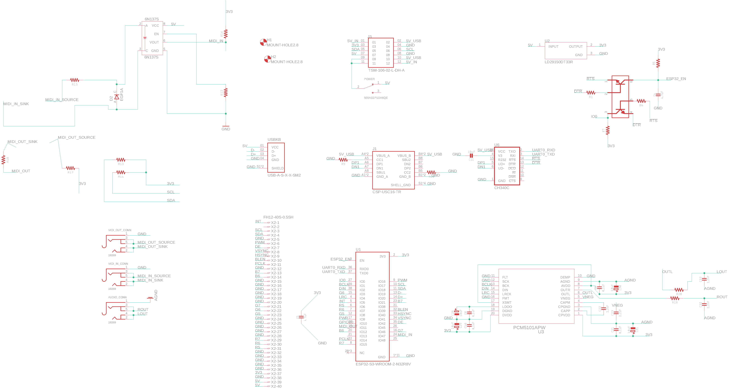
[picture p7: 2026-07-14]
Docs/Amyboard/tulipcc-main/docs/pcbs/tulip4_board_v4r6/schematic.png

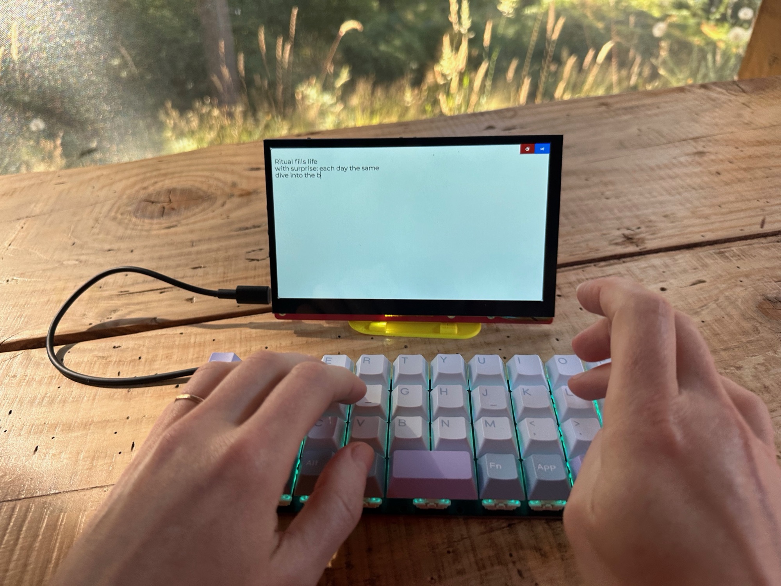
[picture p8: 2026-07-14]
Docs/Amyboard/tulipcc-main/assets/img/tulipcc-poem.jpeg

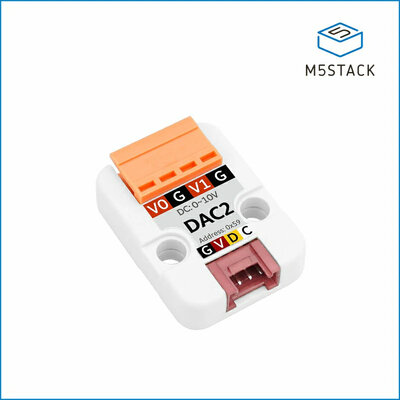
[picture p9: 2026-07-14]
Docs/Amyboard/tulipcc-main/docs/amyboard/img/accessory_m5_dac2.jpg

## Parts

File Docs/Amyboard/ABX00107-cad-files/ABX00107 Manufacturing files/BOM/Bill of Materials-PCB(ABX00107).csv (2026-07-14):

Quantity | Designator | Description | Part Number | Manufacturer
1 | C3 | CAP CHIP 0402 100nF 10% 16V X7R | 0402B104K160CT | Walsin
1 | C4 | CAP CHIP 0603 4.7uF 10% 16V X5R | GRM188R61C475KAAJD | Murata
1 | D1 | LED SMD 0603 GREEN/568 15mcd 120^ | HSMG-C190 | Broadcom
1 | ENCODER1 | ENCODER 2b quadrature, 15PPR, 30 detents, shaft 15mm D-Cut, switch 350+-100gf, SMD 15x18x20mm | PEC11J-9215F-S0015 | Bourns
2 | J1, J2 | CONN JST 4POS SIDE 1MM TIN QWIIC | SM04B-SRSS-TB(LF)(SN) | JST
1 | R1 | RES CHIP 0402 1k 1% 1/16W | CRCW04021K00FKEDC | Vishay
5 | R6, R7, R8, R10, R11 | RES CHIP 0402 4k7 1% 1/16W | RC0402FR-074K7L | YAGEO
1 | U1 | IC Cortex M0, 32b MCU, 32KB Flash, 6KB RAM, VDD 2-3.6V, -40°C to 85°C, QFN20 3x3mm | STM32C011F4U6TR | ST Microelectronics

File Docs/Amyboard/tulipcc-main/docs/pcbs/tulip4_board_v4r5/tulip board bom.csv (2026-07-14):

Part | Value | Device | Package | Description | AVAILABILITY | DESCRIPTION | MF | MP | MPN | OC_FARNELL | OC_NEWARK | PACKAGE | POPULARITY | PRICE | PURCHASE-URL
6N138 | 6N138SDM | 6N138SDM | COUPL_6N138SDM | Optocoupler DC-IN 1-CH Darlington With Base DC-OUT 8-Pin PDIP SMD Black T/R Check availability | In Stock | Optoisolator Darlington with Base Output 5000Vrms 1 Channel 8-SMD | ON Semiconductor | 6N138SDM |  |  |  | PDIP GW-8 ON Semiconductor |  | None | https://pricing.snapeda.com/search/part/6N138SDM/?ref=eda
AUDIO_CONN | 19269 | AUDIO_3.5MMJACK | 4UCONN_19269 | 3.5MM Audio Jack
C1 | 0.1uF | CAP_CERAMIC0805-NOOUTLINE | 0805-NO | Ceramic Capacitors
C2 | 0.1uF | CAP_CERAMIC0805-NOOUTLINE | 0805-NO | Ceramic Capacitors
C3 | 4.7uF | CAP_CERAMIC0805-NOOUTLINE | 0805-NO | Ceramic Capacitors
C4 | 4.7uF | CAP_CERAMIC0805-NOOUTLINE | 0805-NO | Ceramic Capacitors
C5 | 4.7uF | CAP_CERAMIC0805-NOOUTLINE | 0805-NO | Ceramic Capacitors
C11 | 0.1uF | CAP_CERAMIC0805-NOOUTLINE | 0805-NO | Ceramic Capacitors
C12 | 0.1uF | CAP_CERAMIC0805-NOOUTLINE | 0805-NO | Ceramic Capacitors
C13 | 0.01uF | CAP_CERAMIC0805-NOOUTLINE | 0805-NO | Ceramic Capacitors
C14 | 0.01uF | CAP_CERAMIC0805-NOOUTLINE | 0805-NO | Ceramic Capacitors
C15 | 0.1uF | CAP_CERAMIC0805-NOOUTLINE | 0805-NO | Ceramic Capacitors
C16 | 47uF | CAP_ELECTROLYTICPANASONIC_C | PANASONIC_C | Electrolytic Capacitors
C17 | 47uF | CAP_ELECTROLYTICPANASONIC_C | PANASONIC_C | Electrolytic Capacitors
C18 | 10uF | CAP_CERAMIC0805-NOOUTLINE | 0805-NO | Ceramic Capacitors
C19 | 10uF | CAP_CERAMIC0805-NOOUTLINE | 0805-NO | Ceramic Capacitors
C20 | 10uF | CAP_CERAMIC0805-NOOUTLINE | 0805-NO | Ceramic Capacitors
CONNHEADER |  | FE08-2 | FE08-2 | FEMALE HEADER |  |  |  |  |  | unknown | unknown |  | 1
CP2102 | CP2102N-A02-GQFN24 | CP2102N-A02-GQFN24 | QFN50P400X400X80-25N | USB Interface IC USB to UART bridge - QFN24 | In Stock | USB Bridge, USB to UART USB 2.0 UART Interface 24-QFN (4x4) | Silicon Labs | CP2102N-A02-GQFN24 |  |  |  | WFQFN-24 Silicon Labs |  | None | https://pricing.snapeda.com/search/part/CP2102N-A02-GQFN24/?ref=eda
D2 | EGF1A | EGF1A | DIOM449X264X300L114X135N | EGF1A Series 1 A 100 V 50 ns Surface Mount Fast Recovery Rectifier - DO-214AC Check availability | In Stock | Diode Standard 50 V 1A Surface Mount DO-214AC (SMA) | ON Semiconductor | EGF1A |  |  |  | SMA-2 ON Semiconductor |  | None | https://pricing.snapeda.com/search/part/EGF1A/?ref=eda
FB3 | Ferrite | FERRITE0805 | 0805 | Ferrite Bead
FB4 | Ferrite | FERRITE0805 | 0805 | Ferrite Bead
J1 | CSP-USC16-TR | CSP-USC16-TR | VALCON_CSP-USC16-TR | CSP-USC16-TR Valcon USB Type C Surface Mount PCB Socket Check availability | In Stock | CSP-USC16-TR Valcon USB Type C Surface Mount PCB Socket | Valcon | CSP-USC16-TR |  |  |  | None |  | None | https://pricing.snapeda.com/search/part/CSP-USC16-TR/?ref=eda
MIDI_IN_CONN | 19269 | AUDIO_3.5MMJACK | 4UCONN_19269 | 3.5MM Audio Jack
MIDI_OUT_CONN | 19269 | AUDIO_3.5MMJACK | 4UCONN_19269 | 3.5MM Audio Jack
R1 | 100k | R-US_R0805 | R0805 | RESISTOR, American symbol
R2 | 22.1k | R-US_R0805 | R0805 | RESISTOR, American symbol
R3 | 47.5k | R-US_R0805 | R0805 | RESISTOR, American symbol
R4 | 10k | R-US_R0805 | R0805 | RESISTOR, American symbol
R5 | 10k | R-US_R0805 | R0805 | RESISTOR, American symbol
R6 | 100k | R-US_R0805 | R0805 | RESISTOR, American symbol
R7 | 10k | R-US_R0805 | R0805 | RESISTOR, American symbol
R8 | 220k | R-US_R0805 | R0805 | RESISTOR, American symbol
R9 | 100 | R-US_R0805 | R0805 | RESISTOR, American symbol
R10 | 5.1K | R-US_R0805 | R0805 | RESISTOR, American symbol
R11 | 5.1K | R-US_R0805 | R0805 | RESISTOR, American symbol
R12 | 4.7K | R-US_R0805 | R0805 | RESISTOR, American symbol
R13 | 4.7K | R-US_R0805 | R0805 | RESISTOR, American symbol
R14 | 4.7K | R-US_R0805 | R0805 | RESISTOR, American symbol
R15 | 220 | R-US_R0805 | R0805 | RESISTOR, American symbol
R16 | 470 | R-US_R0805 | R0805 | RESISTOR, American symbol
R17 | 33 | R-US_R0805 | R0805 | RESISTOR, American symbol
R18 | 10 | R-US_R0805 | R0805 | RESISTOR, American symbol
R22 | 220k | R-US_R0805 | R0805 | RESISTOR, American symbol
R23 | 100 | R-US_R0805 | R0805 | RESISTOR, American symbol
REG | TS1117BCW33_RPG | TS1117BCW33_RPG | VREG_TS1117BCW33_RPG | Check availability | In Stock | 1A 3.3V LOW DROPOUT VOLTAGE REGULATOR | Taiwan Semiconductor | TS1117BCW33 RPG |  |  |  | SOT-223 Taiwan Semiconductor |  | None | https://pricing.snapeda.com/search/part/TS1117BCW33 RPG/?ref=eda
RESET | MBT3904DW1T1G | MBT3904DW1T1G | SOT236 | Check availability | In Stock | Bipolar (BJT) Transistor Array 2 NPN (Dual) 40V 200mA 300MHz 150mW Surface Mount SC-88/SC70-6/SOT-363 | ON Semiconductor | MBT3904DW1T1G |  |  |  | SC-88-6 ON Semiconductor |  | None | https://pricing.snapeda.com/search/part/MBT3904DW1T1G/?ref=eda
U1 | ESP32-S3-WROOM-2-N32R8V | ESP32-S3-WROOM-2-N32R8V | XCVR_ESP32-S3-WROOM-2-N32R8V | Check availability | In Stock | Bluetooth, WiFi 802.11b/g/n, Bluetooth v5.0 Transceiver Module 2.4GHz PCB Trace Surface Mount | Espressif Systems | ESP32-S3-WROOM-2-N32R8V |  |  |  | Package |  | None | https://pricing.snapeda.com/search/part/ESP32-S3-WROOM-2-N32R8V/?ref=eda
UDA1334 | UDA1334ATS | AUDIO_I2S_UDA1334" | SSOP16_4.4MM | UDA1334 I2C Audio DAC
USBKB | USB-A-S-X-X-SM2 | USB-A-S-X-X-SM2 | SAMTEC_USB-A-S-X-X-SM2 | USB-A (USB TYPE-A) USB 2.0 Receptacle Connector 4 Position Surface Mount, Right Angle; Through Hole Check availability | In Stock | USB-A (USB TYPE-A) USB 2.0 Receptacle Connector 4 Position Surface Mount, Right Angle | Samtec | USB-A-S-F-W-SM2-TR |  |  |  | None |  | None | https://pricing.snapeda.com/search/part/USB-A-S-F-W-SM2-TR/?ref=eda
X2 | FH12-40S-0.5SH | FH12-40S-0.5SH | FH12-40S-0.5SH | 0.5mm Pitch Connectors For FPC/FFC |  |  |  |  | FH12-40S-0.5SH(55) | 1324556 | 34M6178 |  | 0

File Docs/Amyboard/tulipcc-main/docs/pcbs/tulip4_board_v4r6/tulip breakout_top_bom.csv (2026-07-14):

Comment | Designator | Footprint | LCSC Part #
0.1uF | C8 C9 C10 C21 | 0805-NO
2.2nF | C32 C33 | 0805-NO
2.2uF | C22 C23 | 0805-NO
4.7K | R12 R13 R14 | R0805
4.7uF | C4 C5 | 0805-NO
5.1K | R9 R10 | R0805
6N137S | 6N137S | 8-SMD
10 | R18 | R0805
10k | R5 R7 | R0805
10uF | C11 | 0805-NO
10uF | C28 C29 C30 C31 | PANASONIC_C
33 | R17 | R0805
100k | R1 R6 | R0805
220 | R15 | R0805
470 | R16 R19 R20 | R0805
500ASSP1SM6QE | POWER | SW_500ASSP1SM6QE
19269 | AUDIO_CONN MIDI_IN_CONN MIDI_OUT_CONN | 4UCONN_19269
CH340C | U6 | SO016
CSP-USC16-TR | J1 | VALCON_CSP-USC16-TR
EGF1A | D2 | DIOM449X264X300L114X135N
ESP32-S3-WROOM-2-N32R8V | U1 | XCVR_ESP32-S3-WROOM-2-N32R8V
FH12-40S-0.5SH | X2 | FH12-40S-0.5SH
LD29150DT33R | U2 | DPAK456P972X240-3N
MBT3904DW1T1G | RESET | SOT236
PCM5101APW | U3 | PW20_TEX
TSM-106-02-L-DH-A | J3 | SAMTEC_TSM-106-02-L-DH-A
USB-A-S-X-X-SM2 | USBKB | SAMTEC_USB-A-S-X-X-SM2

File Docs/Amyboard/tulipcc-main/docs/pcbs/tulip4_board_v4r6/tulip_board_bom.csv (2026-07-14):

Part | Value | Device | Package | Description | AMOUNT | WHERE | URL
6N137S | 6N137S | 6N137S | 8-SMD | Lite-On 6N137 - High Speed Opto Isolator | 1 | DIGIKEY | https://www.digikey.com/en/mylists/list/90SZQTXF6W
AUDIO_CONN | 19269 | AUDIO_3.5MMJACK | 4UCONN_19269 | 3.5MM Audio Jack | 3 | DIGIKEY | https://www.digikey.com/en/mylists/list/90SZQTXF6W
C4 C5 | 4.7uF | CAP_CERAMIC0805-NOOUTLINE | 0805-NO | Ceramic Capacitors | 2 | DIGIKEY | https://www.digikey.com/en/mylists/list/90SZQTXF6W
C8 C9 C10 C21 | 0.1uF | CAP_CERAMIC0805-NOOUTLINE | 0805-NO | Ceramic Capacitors | 4 | DIGIKEY | https://www.digikey.com/en/mylists/list/90SZQTXF6W
C11 | 10uF | CAP_CERAMIC0805-NOOUTLINE | 0805-NO | Ceramic Capacitors | 1 | DIGIKEY | https://www.digikey.com/en/mylists/list/90SZQTXF6W
C22 C23 | 2.2uF | CAP_CERAMIC0805-NOOUTLINE | 0805-NO | Ceramic Capacitors | 2 | DIGIKEY | https://www.digikey.com/en/mylists/list/90SZQTXF6W
C28 C29 C30 C31 | 10uF | CAP_ELECTROLYTICPANASONIC_C | PANASONIC_C | Electrolytic Capacitors | 4 | DIGIKEY | https://www.digikey.com/en/mylists/list/90SZQTXF6W
C32 C33 | 2.2nF | CAP_CERAMIC0805-NOOUTLINE | 0805-NO | Ceramic Capacitors | 2 | DIGIKEY | https://www.digikey.com/en/mylists/list/90SZQTXF6W
D2 | EGF1A | EGF1A | DIOM449X264X300L114X135N | Diode EGF1A Series 1 A 100 V | 1 | DIGIKEY | https://www.digikey.com/en/mylists/list/90SZQTXF6W
J3 | TSM-106-02-L-D |  |  | Header row SMT | 1 | DIGIKEY | https://www.digikey.com/en/mylists/list/90SZQTXF6W
R1 R6 | 100k | R-US_R0805 | R0805 | RESISTOR, American symbol | 2 | DIGIKEY | https://www.digikey.com/en/mylists/list/90SZQTXF6W
R5 R7 | 10k | R-US_R0805 | R0805 | RESISTOR, American symbol | 2 | DIGIKEY | https://www.digikey.com/en/mylists/list/90SZQTXF6W
R9 R10 | 5.1K | R-US_R0805 | R0805 | RESISTOR, American symbol | 2 | DIGIKEY | https://www.digikey.com/en/mylists/list/90SZQTXF6W
R12 R13 R14 | 4.7K | R-US_R0805 | R0805 | RESISTOR, American symbol | 3 | DIGIKEY | https://www.digikey.com/en/mylists/list/90SZQTXF6W
R15 | 220 | R-US_R0805 | R0805 | RESISTOR, American symbol | 1 | DIGIKEY | https://www.digikey.com/en/mylists/list/90SZQTXF6W
R16 R19 R20 | 470 | R-US_R0805 | R0805 | RESISTOR, American symbol | 3 | DIGIKEY | https://www.digikey.com/en/mylists/list/90SZQTXF6W
R17 | 33 | R-US_R0805 | R0805 | RESISTOR, American symbol | 1 | DIGIKEY | https://www.digikey.com/en/mylists/list/90SZQTXF6W
R18 | 10 | R-US_R0805 | R0805 | RESISTOR, American symbol | 1 | DIGIKEY | https://www.digikey.com/en/mylists/list/90SZQTXF6W
RESET | MBT3904DW1T1G | MBT3904DW1T1G | SOT236 | ESP32 reset transistors | 1 | DIGIKEY | https://www.digikey.com/en/mylists/list/90SZQTXF6W
U1 | ESP32-S3-WROOM-2-N32R8V | ESP32-S3-WROOM-2-N32R8V | XCVR_ESP32-S3-WROOM-2-N32R8V | ESP32-S3 | 1 | DIGIKEY | https://www.digikey.com/en/mylists/list/90SZQTXF6W
U2 | LD29150DT33R | LD29150DT33R | DPAK456P972X240-3N | Regulator - LD29150 Series 1.5 A 3.3 V | 1 | DIGIKEY | https://www.digikey.com/en/mylists/list/90SZQTXF6W
U3 | PCM5101APW | PCM5101APW | PW20_TEX | Audio I2S DAC | 1 | DIGIKEY | https://www.digikey.com/en/mylists/list/90SZQTXF6W
USBKB | USB-A-S-X-X-SM2 | USB-A-S-X-X-SM2 | SAMTEC_USB-A-S-X-X-SM2 | USB-A female connector | 1 | DIGIKEY | https://www.digikey.com/en/mylists/list/90SZQTXF6W
X2 | FH12-40S-0.5SH | FH12-40S-0.5SH | FH12-40S-0.5SH | 40 pin 0.5mm FPC connector | 1 | DIGIKEY | https://www.digikey.com/en/mylists/list/90SZQTXF6W
POWER | 500ASSP1SM6QE | 500ASSP1SM6QE |  | Power switch | 1 | DIGIKEY | https://www.digikey.com/en/mylists/list/90SZQTXF6W
JUMPER |  |  |  | Jumper | 1 | DIGIKEY | https://www.digikey.com/en/mylists/list/90SZQTXF6W
J1 | CSP-USC16-TR | CSP-USC16-TR | VALCON_CSP-USC16-TR | USB C connector | 1 | TOBY | https://www.toby.co.uk/signal-to-board-connectors/usb-connectors/csp-usc16-tr-valcon-usb-type-c-surface-mount-pcb-socket/CSP-USC16-TR/
U6 | CH340C | CH340C | SO016 | USB to Serial | 1 | LCSC | https://www.lcsc.com/product-detail/USB_CH340C_C84681.html
FPC CABLE |  |  |  | A-B 40 Pin FPC cable | 1 | ADAFRUIT | https://www.adafruit.com/product/4933
DISPLAY |  |  |  | 10.1" RGB Display | 1 | HOTMCU | https://www.hotmcu.com/101-inch-1024x600-tft-lcd-display-with-capacitive-touch-panel-p-215.html
BATTERY HOLDER |  |  |  | Optional 2 cell parallel 18650 Battery holder | 1 | AMAZON | https://www.amazon.com/dp/B07FRYPYTK
BOOST/CHARGER | J5019 |  |  | Optional J5019 Charger circuit board | 1 | AMAZON | https://www.amazon.com/dp/B08GWTBD3T
BATTERY-18650 |  |  |  | Optional batteries | 2 | 18650BATTERYSTORE | https://www.18650batterystore.com/products/sanyo-ncr18650ga

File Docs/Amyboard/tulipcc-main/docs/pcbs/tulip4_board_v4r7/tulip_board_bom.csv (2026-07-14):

Part | Value | Device | Package | Description | AMOUNT | WHERE | URL
VO0601T | VO0601T | VO0601T | 8-SOIC | Optoisolator | 1 | DIGIKEY | https://www.digikey.com/en/mylists/list/ZB5IAQSM2O
AUDIO_CONN | 19269 | AUDIO_3.5MMJACK | 4UCONN_19269 | 3.5MM Audio Jack | 3 | DIGIKEY | https://www.digikey.com/en/mylists/list/ZB5IAQSM2O
C4 C5 | 4.7uF | CAP_CERAMIC0805-NOOUTLINE | 0805-NO | Ceramic Capacitors | 2 | DIGIKEY | https://www.digikey.com/en/mylists/list/ZB5IAQSM2O
C8 C9 C10 C21 | 0.1uF | CAP_CERAMIC0805-NOOUTLINE | 0805-NO | Ceramic Capacitors | 4 | DIGIKEY | https://www.digikey.com/en/mylists/list/ZB5IAQSM2O
C11 | 10uF | CAP_CERAMIC0805-NOOUTLINE | 0805-NO | Ceramic Capacitors | 1 | DIGIKEY | https://www.digikey.com/en/mylists/list/ZB5IAQSM2O
C22 C23 | 2.2uF | CAP_CERAMIC0805-NOOUTLINE | 0805-NO | Ceramic Capacitors | 2 | DIGIKEY | https://www.digikey.com/en/mylists/list/ZB5IAQSM2O
C28 C29 C30 C31 | 10uF | CAP_ELECTROLYTICPANASONIC_C | PANASONIC_C | Electrolytic Capacitors | 4 | DIGIKEY | https://www.digikey.com/en/mylists/list/ZB5IAQSM2O
C32 C33 | 2.2nF | CAP_CERAMIC0805-NOOUTLINE | 0805-NO | Ceramic Capacitors | 2 | DIGIKEY | https://www.digikey.com/en/mylists/list/ZB5IAQSM2O
D2 | EGF1A | EGF1A | DIOM449X264X300L114X135N | Diode EGF1A Series 1 A 100 V | 1 | DIGIKEY | https://www.digikey.com/en/mylists/list/ZB5IAQSM2O
EXT-USB | 1540 | 1540 |  | Right angle headers (3 pin) 0.1” | 1 | ADAFRUIT | https://www.adafruit.com/product/1540
R1 R6 | 100k | R-US_R0805 | R0805 | RESISTOR, American symbol | 2 | DIGIKEY | https://www.digikey.com/en/mylists/list/ZB5IAQSM2O
R5 R7 | 10k | R-US_R0805 | R0805 | RESISTOR, American symbol | 2 | DIGIKEY | https://www.digikey.com/en/mylists/list/ZB5IAQSM2O
R9 R10 | 5.1K | R-US_R0805 | R0805 | RESISTOR, American symbol | 2 | DIGIKEY | https://www.digikey.com/en/mylists/list/ZB5IAQSM2O
R12 R13 R14 | 4.7K | R-US_R0805 | R0805 | RESISTOR, American symbol | 3 | DIGIKEY | https://www.digikey.com/en/mylists/list/ZB5IAQSM2O
R15 | 220 | R-US_R0805 | R0805 | RESISTOR, American symbol | 1 | DIGIKEY | https://www.digikey.com/en/mylists/list/ZB5IAQSM2O
R16 R19 R20 | 470 | R-US_R0805 | R0805 | RESISTOR, American symbol | 3 | DIGIKEY | https://www.digikey.com/en/mylists/list/ZB5IAQSM2O
R17 | 33 | R-US_R0805 | R0805 | RESISTOR, American symbol | 1 | DIGIKEY | https://www.digikey.com/en/mylists/list/ZB5IAQSM2O
R18 | 10 | R-US_R0805 | R0805 | RESISTOR, American symbol | 1 | DIGIKEY | https://www.digikey.com/en/mylists/list/ZB5IAQSM2O
RESET | MBT3904DW1T1G | MBT3904DW1T1G | SOT236 | ESP32 reset transistors | 1 | DIGIKEY | https://www.digikey.com/en/mylists/list/ZB5IAQSM2O
U1 | ESP32-S3-WROOM-2-N32R8V | ESP32-S3-WROOM-2-N32R8V | XCVR_ESP32-S3-WROOM-2-N32R8V | ESP32-S3 | 1 | DIGIKEY | https://www.digikey.com/en/mylists/list/ZB5IAQSM2O
U2 | LD29150DT33R | LD29150DT33R | DPAK456P972X240-3N | Regulator - LD29150 Series 1.5 A 3.3 V | 1 | DIGIKEY | https://www.digikey.com/en/mylists/list/ZB5IAQSM2O
U3 | PCM5101APW | PCM5101APW | PW20_TEX | Audio I2S DAC | 1 | DIGIKEY | https://www.digikey.com/en/mylists/list/ZB5IAQSM2O
USBKB | USB-A-S-X-X-SM2 | USB-A-S-X-X-SM2 | SAMTEC_USB-A-S-X-X-SM2 | USB-A female connector | 1 | DIGIKEY | https://www.digikey.com/en/mylists/list/ZB5IAQSM2O
X2 | XF2M-4015-1A | XF2M-4015-1A | XF2M-4015-1A | 40 pin 0.5mm FPC connector | 1 | DIGIKEY | https://www.digikey.com/en/mylists/list/ZB5IAQSM2O
POWER | 500ASSP1SM6QE | 500ASSP1SM6QE |  | Power switch | 1 | DIGIKEY | https://www.digikey.com/en/mylists/list/ZB5IAQSM2O
JUMPER |  |  |  | Jumper | 1 | DIGIKEY | https://www.digikey.com/en/mylists/list/ZB5IAQSM2O
J1 | CSP-USC16-TR | CSP-USC16-TR | VALCON_CSP-USC16-TR | USB C connector | 1 | TOBY | https://www.toby.co.uk/signal-to-board-connectors/usb-connectors/csp-usc16-tr-valcon-usb-type-c-surface-mount-pcb-socket/CSP-USC16-TR/
U6 | CH340C | CH340C | SO016 | USB to Serial | 1 | LCSC | https://www.lcsc.com/product-detail/USB_CH340C_C84681.html
DISPLAY |  |  |  | 10.1" RGB Display with A-A 40 pin FPC cable | 1 | HOTMCU | https://www.hotmcu.com/101-inch-1024x600-tft-lcd-display-with-capacitive-touch-panel-p-215.html
POWER | A100044-ND | A100044-ND | JST | OPTIONAL 3 pin JST connector | 1 | DIGIKEY | https://www.digikey.com/en/mylists/list/ZB5IAQSM2O
POWER_CABLE |  |  |  | OPTIONAL 3 pin JST cable | 1 | AMAZON | https://www.amazon.com/gp/product/B01DUC1PW6/
BATTERY HOLDER |  |  |  | OPTIONAL 2 cell parallel 18650 Battery holder | 1 | AMAZON | https://www.amazon.com/dp/B07FRYPYTK
BOOST/CHARGER | J5019 |  |  | OPTIONAL J5019 Charger circuit board | 1 | AMAZON | https://www.amazon.com/dp/B08GWTBD3T
BATTERY-18650 |  |  |  | OPTIONAL batteries | 2 | 18650BATTERYSTORE | https://www.18650batterystore.com/products/sanyo-ncr18650ga
SNES |  |  |  | OPTIONAL 7-pin SNES connector | 1 | ZEDLABZ | https://www.zedlabz.com/products/zedlabz-7-pin-90-degree-female-controller-connector-port-for-nintendo-snes-console-2-pack-grey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

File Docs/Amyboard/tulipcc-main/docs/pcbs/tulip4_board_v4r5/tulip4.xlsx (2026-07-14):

Country of Origin may be different at time of shipment.
The HTSUS and ECCN information shown is for informational purposes only and is not a representation or warranty as to the accuracy or reliability of these classifications. All information is provided "as is" and is subject to change without notice. Any use made of the information provided is without recourse to Digi-Key and at the user's risk.
Index | Manufacturer Part Number | Manufacturer Name | Description | Availability | Stock Status | Assemblies | Attrition % | Requested Quantity 1 | Pack Quantity 1 | Pack Type 1 | Digi-Key Part Number 1 | Unit Price 1 | Extended Price 1 | Minimum Order Quantity 1 | Customer Reference | Requested Part Number | Lead Weeks | Datasheet | Reference Designator | US Import Tariff | Note | Part Status | RoHS Status | ECCN | HTSUS | Country of Origin | Environmental Information | Original Part numbers | Image
1 | ESP32-S3-WROOM-2-N32R8V | Espressif Systems | SMD MODULE, ESP32-S3R8 WITH 1.8V | 490 | In Stock | 5 |  | 1 | 5 | Cut Tape (CT) | 1965-ESP32-S3-WROOM-2-N32R8VCT-ND | 7.35000 | $36.75 | 1 |  | 1965-ESP32-S3-WROOM-2-N32R8VCT-ND | 8 | https://media.digikey.com/pdf/Data%20Sheets/Espressif%20PDFs/ESP32-S3-WROOM-2_2U_Preliminary_v0.1_Preliminary.pdf |  | May apply on shipments to the U.S. |  | Active | Unknown | 5A992C | 8517.62.0090 | China |  | 1965-ESP32-S3-WROOM-2-N32R8VCT-ND | https://media.digikey.com/Photos/Espressif%20Systems/MFG_ESP32-S3-WROOM-2-N32R8V.jpg
2 | RMCF0805JT22K0 | Stackpole Electronics Inc | RES 22K OHM 5% 1/8W 0805 | 1,070,039 | In Stock | 5 |  | 1 | 5 | Cut Tape (CT) | RMCF0805JT22K0CT-ND | 0.10000 | $0.50 | 1 |  | RMCF0805JT22K0CT-ND | 16 | https://www.seielect.com/catalog/sei-rmcf_rmcp.pdf |  | May apply on shipments to the U.S. |  | Active | ROHS3 Compliant | EAR99 | 8533.21.0030 | China | https://www.seielect.com/catalog/cert-of-compliance.pdf|https://www.seielect.com/catalog/SEI-RoHS_Compliance_Status.pdf|https://www.seielect.com/catalog/reach.pdf | RMCF0805JT22K0CT-ND | https://media.digikey.com/Renders/Stackpole%20Renders/0805-RMCF-Series.jpg
3 | CRCW0805100KJNTA | Vishay Dale | RES SMD 100K OHM 5% 1/8W 0805 | 4,970 | In Stock | 5 |  | 2 | 10 | Cut Tape (CT) | 541-3014-1-ND | 0.13900 | $1.39 | 1 |  | 541-3014-1-ND | 99 | https://www.vishay.com/docs/20008/dcrcw.pdf |  | N/A |  | Active | RoHS non-compliant | EAR99 | 8533.21.0030 | Israel |  | 541-3014-1-ND | https://media.digikey.com/Renders/Vishay%20Dale%20Renders/CRCW-0805-(2125metric).jpg
4 | RC0805JR-1347KL | YAGEO | RES 47K OHM 5% 1/8W 0805 | 30,560 | In Stock | 5 |  | 1 | 5 | Cut Tape (CT) | 13-RC0805JR-1347KLCT-ND | 0.10000 | $0.50 | 1 |  | 13-RC0805JR-1347KLCT-ND | 20 | https://www.yageo.com/upload/media/product/productsearch/datasheet/rchip/PYu-RC_Group_51_RoHS_L_12.pdf |  | N/A |  | Active | ROHS3 Compliant | EAR99 | 8533.21.0030 | Taiwan | https://www.yageo.com/en/Download/Index/certificates#rchip | 13-RC0805JR-1347KLCT-ND | https://media.digikey.com/Renders/Yageo%20Renders/0805-(2012-Metric).jpg
5 | RC0805JR-0710KP | YAGEO | RES SMD 10K OHM 5% 1/8W 0805 | 3,125 | In Stock | 5 |  | 2 | 10 | Cut Tape (CT) | YAG1329CT-ND | 0.06400 | $0.64 | 1 |  | YAG1329CT-ND | 20 | https://www.yageo.com/upload/media/product/products/datasheet/rchip/PYu-RC_51_RoHS_P_4.pdf |  | N/A |  | Active | ROHS3 Compliant | EAR99 | 8533.21.0030 | Taiwan |  | YAG1329CT-ND | https://media.digikey.com/Renders/Yageo%20Renders/0805-(2012-Metric).jpg
6 | RMCF0805JT5K10 | Stackpole Electronics Inc | RES 5.1K OHM 5% 1/8W 0805 | 903,112 | In Stock | 5 |  | 2 | 10 | Cut Tape (CT) | RMCF0805JT5K10CT-ND | 0.01800 | $0.18 | 1 |  | RMCF0805JT5K10CT-ND | 16 | https://www.seielect.com/catalog/sei-rmcf_rmcp.pdf |  | May apply on shipments to the U.S. |  | Active | ROHS3 Compliant | EAR99 | 8533.21.0030 | Taiwan | https://www.seielect.com/catalog/cert-of-compliance.pdf|https://www.seielect.com/catalog/SEI-RoHS_Compliance_Status.pdf|https://www.seielect.com/catalog/reach.pdf | RMCF0805JT5K10CT-ND | https://media.digikey.com/Renders/Stackpole%20Renders/0805-RMCF-Series.jpg
7 | RMCF0805JT4K70 | Stackpole Electronics Inc | RES 4.7K OHM 5% 1/8W 0805 | 1,587,175 | In Stock | 5 |  | 3 | 15 | Cut Tape (CT) | RMCF0805JT4K70CT-ND | 0.01800 | $0.27 | 1 |  | RMCF0805JT4K70CT-ND | 16 | https://www.seielect.com/catalog/sei-rmcf_rmcp.pdf |  | May apply on shipments to the U.S. |  | Active | ROHS3 Compliant | EAR99 | 8533.21.0030 | Taiwan | https://www.seielect.com/catalog/reach.pdf|https://www.seielect.com/catalog/cert-of-compliance.pdf|https://www.seielect.com/catalog/SEI-RoHS_Compliance_Status.pdf | RMCF0805JT4K70CT-ND | https://media.digikey.com/Renders/Stackpole%20Renders/0805-RMCF-Series.jpg
8 | RC0805JR-07220RL | YAGEO | RES 220 OHM 5% 1/8W 0805 | 593,020 | In Stock | 5 |  | 1 | 5 | Cut Tape (CT) | 311-220ARCT-ND | 0.10000 | $0.50 | 1 |  | 311-220ARCT-ND | 33 | https://www.yageo.com/upload/media/product/productsearch/datasheet/rchip/PYu-RC_Group_51_RoHS_L_12.pdf |  | May apply on shipments to the U.S. |  | Active | ROHS3 Compliant | EAR99 | 8533.21.0030 | Taiwan | https://www.yageo.com/en/Download/Index/certificates#rchip | 311-220ARCT-ND | https://media.digikey.com/Renders/Yageo%20Renders/0805-(2012-Metric).jpg
9 | RMCF0805JG470R | Stackpole Electronics Inc | RES 470 OHM 5% 1/8W 0805 | 104,496 | In Stock | 5 |  | 3 | 15 | Cut Tape (CT) | RMCF0805JG470RCT-ND | 0.01800 | $0.27 | 1 |  | RMCF0805JG470RCT-ND | 16 | https://www.seielect.com/catalog/sei-rmcf_rmcp.pdf |  | N/A |  | Active | ROHS3 Compliant | EAR99 | 8533.21.0030 | Taiwan | https://www.seielect.com/catalog/reach.pdf|https://www.seielect.com/catalog/cert-of-compliance.pdf|https://www.seielect.com/catalog/SEI-RoHS_Compliance_Status.pdf | RMCF0805JG470RCT-ND | https://media.digikey.com/Renders/Stackpole%20Renders/0805-RMCF-Series.jpg
10 | RMCF0805JT33R0 | Stackpole Electronics Inc | RES 33 OHM 5% 1/8W 0805 | 343,659 | In Stock | 5 |  | 1 | 5 | Cut Tape (CT) | RMCF0805JT33R0CT-ND | 0.10000 | $0.50 | 1 |  | RMCF0805JT33R0CT-ND | 16 | https://www.seielect.com/catalog/sei-rmcf_rmcp.pdf |  | May apply on shipments to the U.S. |  | Active | ROHS3 Compliant | EAR99 | 8533.21.0030 | Taiwan | https://www.seielect.com/catalog/cert-of-compliance.pdf|https://www.seielect.com/catalog/SEI-RoHS_Compliance_Status.pdf|https://www.seielect.com/catalog/reach.pdf | RMCF0805JT33R0CT-ND | https://media.digikey.com/Renders/Stackpole%20Renders/0805-RMCF-Series.jpg
11 | RMCF0805JG10R0 | Stackpole Electronics Inc | RES 10 OHM 5% 1/8W 0805 | 851,705 | In Stock | 5 |  | 1 | 5 | Cut Tape (CT) | RMCF0805JG10R0CT-ND | 0.10000 | $0.50 | 1 |  | RMCF0805JG10R0CT-ND | 19 | https://www.seielect.com/catalog/sei-rmcf_rmcp.pdf |  | May apply on shipments to the U.S. |  | Active | ROHS3 Compliant | EAR99 | 8533.21.0030 | Taiwan | https://www.seielect.com/catalog/reach.pdf|https://www.seielect.com/catalog/cert-of-compliance.pdf|https://www.seielect.com/catalog/SEI-RoHS_Compliance_Status.pdf | RMCF0805JG10R0CT-ND | https://media.digikey.com/Renders/Stackpole%20Renders/0805-RMCF-Series.jpg
12 | 0805ZC475MAT2A | KYOCERA AVX | CAP CER 4.7UF 10V X7R 0805 | 16,992 | In Stock | 5 |  | 3 | 15 | Cut Tape (CT) | 478-7965-1-ND | 0.15200 | $2.28 | 1 |  | 478-7965-1-ND | 16 | https://datasheets.kyocera-avx.com/X7RDielectric.pdf |  | May apply on shipments to the U.S. |  | Active | ROHS3 Compliant | EAR99 | 8532.24.0020 | Taiwan |  | 478-7965-1-ND | https://media.digikey.com/Renders/AVX%20Renders/0805-(2012-Metric)-1,52mm.jpg
13 | STX-3500-5NTR | Kycon, Inc. | CONN JACK STEREO 3.5MM SMD R/A | 2,232 | In Stock | 5 |  | 3 | 15 | Cut Tape (CT) | 2092-STX-3500-5NCT-ND | 1.39300 | $20.90 | 1 |  | 2092-STX-3500-5NCT-ND | 31 | https://www.kycon.com/Pub_Eng_Draw/STX-3500-5N.pdf |  | N/A |  | Active | RoHS Compliant | EAR99 | 8536.69.4040 | Taiwan |  | 2092-STX-3500-5NCT-ND | https://media.digikey.com/Photos/Kycon-Inc/STX-3500-5NTR.jpg
14 | CP2102-GMR | Silicon Labs | IC USB-TO-UART BRIDGE 28VQFN | 21,488 | In Stock | 5 |  | 1 | 5 | Cut Tape (CT) | 336-1160-1-ND | 5.06000 | $25.30 | 1 |  | 336-1160-1-ND | 20 | https://www.silabs.com/documents/public/data-sheets/CP2102-9.pdf |  | N/A |  |  | ROHS3 Compliant | EAR99 | 8542.39.0001 | Taiwan |  | 336-1160-1-ND | https://media.digikey.com/photos/Silicon%20Labs%20Photos/SL-28-MLP.jpg
15 | US1A-13-F | Diodes Incorporated | DIODE GEN PURP 50V 1A SMA | 35,238 | In Stock | 5 |  | 1 | 5 | Cut Tape (CT) | US1A-FDICT-ND | 0.46000 | $2.30 | 1 |  | US1A-FDICT-ND | 20 | https://www.diodes.com/assets/Datasheets/ds16008.pdf |  | May apply on shipments to the U.S. |  | Active | ROHS3 Compliant | EAR99 | 8541.10.0080 | China | https://www.diodes.com/assets/Quality-Reliability-Docs/Master_CofC.pdf | US1A-FDICT-ND | https://media.digikey.com/Renders/Diodes%20Renders/DO-214AA_SMB.jpg
16 | USB4500-03-0-A | GCT | USB C REC 16P, 3U" MID MNT 0.8MM | 1,203 | In Stock | 5 |  | 1 | 5 | Cut Tape (CT) | 2073-USB4500-03-0-ACT-ND | 0.80000 | $4.00 | 1 |  | 2073-USB4500-03-0-ACT-ND | 10 | https://gct.co/files/drawings/usb4500.pdf |  | May apply on shipments to the U.S. |  | Active | ROHS3 Compliant | EAR99 | 8536.69.4040 | China |  | 2073-USB4500-03-0-ACT-ND | https://media.digikey.com/Photos/GCT/MFG_USB4500_0.jpg
17 | MBT3904DW1T1G | onsemi | TRANS 2NPN 40V 0.2A SC88/SC70-6 | 393,040 | In Stock | 5 |  | 1 | 5 | Cut Tape (CT) | MBT3904DW1T1GOSCT-ND | 0.26000 | $1.30 | 1 |  | MBT3904DW1T1GOSCT-ND | 23 | https://www.onsemi.com/pdf/datasheet/mbt3904dw1t1-d.pdf |  | May apply on shipments to the U.S. |  | Active | ROHS3 Compliant | EAR99 | 8541.21.0075 | China | https://www.onsemi.com/PowerSolutions/MaterialComposition.do?export=pdf&opnId=MBT3904DW1T1G|https://www.onsemi.com/site/pdf/REACH-compliance-statement.pdf|https://www.onsemi.com/site/pdf/RoHS-statement.pdf | MBT3904DW1T1GOSCT-ND | https://media.digikey.com/Renders/On%20Semi%20Renders/Mfg_488;-419B-02;-DF,-DW,-SQ;-6.jpg
18 | PCM5101AQPWRQ1 | Texas Instruments | IC DAC 16/24/32BIT 384K 20TSSOP | 2,000 | In Stock | 5 |  | 1 | 5 | Cut Tape (CT) | 296-37276-1-ND | 4.03000 | $20.15 | 1 |  | 296-37276-1-ND | 35 | https://www.ti.com/general/docs/suppproductinfo.tsp?distId=10 |  | N/A |  | Active | ROHS3 Compliant | EAR99 | 8542.39.0001 | Taiwan |  | 296-37276-1-ND | https://media.digikey.com/Renders/Texas%20Instr%20Renders/296;4040064-5;PW;20.jpg
19 | USB-A-S-F-W-SM2-TR | Samtec Inc. | CONN RCPT USB2.0 TYPEA 4P SMD RA | 873 | In Stock | 5 |  | 1 | 5 | Cut Tape (CT) | SAM14901CT-ND | 2.18000 | $10.90 | 1 |  | SAM14901CT-ND | 11 | http://suddendocs.samtec.com/catalog_english/usb_a.pdf |  | May apply on shipments to the U.S. |  | Active | ROHS3 Compliant | EAR99 | 8536.69.4040 | China |  | SAM14901CT-ND | https://media.digikey.com/Photos/Samtec%20Photos/USB-A-S-F-W-SM2.JPG
20 | FH12-40S-0.5SH(55) | Hirose Electric Co Ltd | CONN FFC BOTTOM 40POS 0.50MM R/A | 15,355 | In Stock | 5 |  | 1 | 5 | Cut Tape (CT) | 26-FH12-40S-0.5SH(55)CT-ND | 3.00000 | $15.00 | 1 |  | 26-FH12-40S-0.5SH(55)CT-ND | 16 | https://www.hirose.com/product/document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 |  | N/A |  | Active | RoHS Compliant | EAR99 | 8536.69.4051 | Japan |  | 26-FH12-40S-0.5SH(55)CT-ND | https://media.digikey.com/photos/Hirose%20Elect%20Photos/FH12-40S-0.5SH(55).jpg
21 | 6N137S | Lite-On Inc. | OPTOISO 5KV 1CH OPEN COLL 8SMD | 104,885 | In Stock | 5 |  | 1 | 5 | Tube | 160-1793-ND | 0.81000 | $4.05 | 1 |  | 160-1793-ND | 24 | https://media.digikey.com/pdf/Data%20Sheets/Lite-On%20PDFs/6N137%20Series.pdf |  | N/A |  | Active | ROHS3 Compliant | EAR99 | 8541.49.8000 | Malaysia |  | 160-1793-ND | https://media.digikey.com/photos/Lite%20On%20Photos/6N137S-TA1.JPG
22 | EEE-FC1C100R | Panasonic Electronic Components | CAP ALUM 10UF 20% 16V SMD | 605,091 | In Stock | 5 |  | 4 | 20 | Cut Tape (CT) | PCE3995CT-ND | 0.27600 | $5.52 | 1 |  | PCE3995CT-ND | 50 | https://industrial.panasonic.com/cdbs/www-data/pdf/RDE0000/ABA0000C1172.pdf |  | N/A |  |  | RoHS Compliant | EAR99 | 8532.22.0020 | Malaysia |  | PCE3995CT-ND | https://media.digikey.com/photos/Panasonic%20Photos/FC%20SERIES%205.5H,4.0D.jpg
23 | C0805C104K4RAC7800 | KEMET | CAP CER 0.1UF 16V X7R 0805 | 290,807 | In Stock | 5 |  | 6 | 30 | Cut Tape (CT) | 399-C0805C104K4RAC7800CT-ND | 0.13600 | $4.08 | 1 |  | 399-C0805C104K4RAC7800CT-ND | 45 | https://connect.kemet.com:7667/gateway/IntelliData-ComponentDocumentation/1.0/download/datasheet/C0805C104K4RACTU |  | May apply on shipments to the U.S. |  | Active | ROHS3 Compliant | EAR99 | 8532.24.0020 | Taiwan |  | 399-C0805C104K4RAC7800CT-ND | https://media.digikey.com/Renders/Kemet%20Renders/0805-(2012-Metric)-2,00x1,20x1,00mm.jpg
24 | 0805ZC225MAT2A | KYOCERA AVX | CAP CER 2.2UF 10V X7R 0805 | 2,900 | In Stock | 5 |  | 2 | 10 | Cut Tape (CT) | 478-0805ZC225MAT2ACT-ND | 0.13000 | $1.30 | 1 |  | 478-0805ZC225MAT2ACT-ND | 99 | https://datasheets.kyocera-avx.com/X7RDielectric.pdf |  | N/A |  | Active | ROHS3 Compliant | EAR99 | 8532.24.0020 | Taiwan |  | 478-0805ZC225MAT2ACT-ND | https://media.digikey.com/Renders/AVX%20Renders/0805-(2012-Metric)-1,40mm.jpg
25 | C0805C222KAGECAUTO | KEMET | CAP CER 0805 2.2NF 250V C0G | 13,725 | In Stock | 5 |  | 2 | 10 | Cut Tape (CT) | 399-17905-1-ND | 0.19000 | $1.90 | 1 |  | 399-17905-1-ND | 56 | https://connect.kemet.com:7667/gateway/IntelliData-ComponentDocumentation/1.0/download/datasheet/C0805C222KAGECAUTO |  | N/A |  | Active | ROHS3 Compliant | EAR99 | 8532.24.0020 | Mexico |  | 399-17905-1-ND | https://media.digikey.com/Renders/Kemet%20Renders/0805-(2012-Metric)-2,00x1,20x1,00mm.jpg

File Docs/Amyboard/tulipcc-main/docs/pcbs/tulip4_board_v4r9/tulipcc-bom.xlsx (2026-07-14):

Item | Qty | Designator | Comment | Manufacturer | Footprint | Supplier 1 | Supplier 1 # | Supplier 2 | Supplier 2 #
1 | 11 | C1, C4, C8, C9, C11, C13, C15, C17, C26, C27, C30 | 0.1uF | Kemet | C0805C104K5RAC7411 | Mouser | 80-C0805C104K5RACLR | DigiKey | 399-C0805C104K5RAC7800CT-ND
2 | 5 | C2, C32, C33, C34, C35 | 22uF | Kemet | C1210C226M4RAC7210 | Mouser | 80-C1210C226M4RACLR | DigiKey | 399-C1210C226M4RAC7210CT-ND
3 | 5 | C3, C5, C29, C31, C36 | 4.7uF | Kemet | C0805C475K3RACTU | Mouser | 80-C0805C475K3RACTU | DigiKey | 399-C0805C475K3RAC7800CT-ND
4 | 2 | C6, C7 | 47pF | Kemet | C0805C470K5RACTU | Mouser | 80-C0805C470K5RACTU | DigiKey | 399-C0805C470K5RAC7800CT-ND
5 | 3 | C10, C21, C25 | 220uF | WE | 865060345007 | Mouser | 710-865060345007 | DigiKey | 732-8524-1-ND
6 | 4 | C12, C14, C16, C28 | 10uF | WE | 865060340001 | Mouser | 710-865060340001 | DigiKey | 732-8518-1-ND
7 | 4 | C18, C19, C22, C23 | 2.2uF | Kemet | C0805C225K3RACTU | Mouser | 80-C0805C225K3R | DigiKey | 399-11941-1-ND
8 | 2 | C20, C24 | 0.47uF | Kemet | C0805C474K3RACTU | Mouser | 80-C0805C474K3R | DigiKey | 399-C0805C474K3NAC7800CT-ND
9 | 1 | D1 | 1N4148WS | Vishay | 1N4148WS-G3-08 | Mouser | 78-1N4148WS-G3-08 | DigiKey | 1N4148WS-G3-08GICT-ND
10 | 1 | D2 | B340AE-13 | Diodes Inc | B340AE-13 | Mouser | 621-B340AE-13 | DigiKey | B340AE-13DICT-ND
11 | 1 | FB1 | 120R | Murata | BLM21PG121SN1D | Mouser | 81-BLM18SG121TN1D | DigiKey | 490-BLM21PG121BH1DCT-ND
12 | 1 | J1 | XF2M-4015-1A | Omron | XF2M-4015-1A | Mouser | 653-XF2M-4015-1A | DigiKey | OR729CT-ND
13 | 1 | J2 | 1734709-4 | TE | 1734709-4 | Mouser | 571-1734709-4 | DigiKey | A99957CT-ND
14 | 2 | J3, J5 | 217179-0001 | Molex | 217179-0001 | Mouser | 538-217179-0001 | DigiKey | 900-2171790001CT-ND
15 | 3 | J4, J6, J7 | SJ2-35863B1 | CUI | SJ2-35863B1-SMT-TR | Mouser | 490-SJ2-35863B1SMTTR | DigiKey | CP-SJ2-35863B1-SMT-CT-ND
16 | 1 | J8 | 1734827-2 | TE | 1734827-2 | Mouser | 571-1734827-2 | DigiKey | 455-S2B-PH-SM4-TBCT-ND
17 | 1 | L1 | 1uH | Vishay Dale | IFSC1515AHER1R0M01 | Mouser | 70-IFSC1515AHER1R0M0 | DigiKey | 541-1403-1-ND
18 | 1 | Q1 | DMP3099L | Diodes Inc | DMP3099L-13 | Mouser | 621-DMP3099L-13 | DigiKey | DMP3099L-13DICT-ND
19 | 9 | R1, R2, R11, R14, R27, R28, R30, R31, R32 | 10K | Bourns | CR0805-FX-1002ELF | Mouser | 652-CR0805FX-1002ELF | DigiKey | CR0805-FX-1002ELFCT-ND
20 | 2 | R3, R4 | 2.4K | Bourns | CR0805-FX-2401ELF | Mouser | 652-CR0805FX-2401ELF | DigiKey | CR0805-FX-2401ELFCT-ND
21 | 2 | R5, R6 | 100K | Bourns | CR0805-FX-1003ELF | Mouser | 652-CR0805FX-1003ELF | DigiKey | CR0805-FX-1003ELFCT-ND
22 | 2 | R7, R8 | 27R | Bourns | CR0805-FX-27R0ELF | Mouser | 652-CR0805FX-27R0ELF | DigiKey | 118-CMP0603AFX-27R0ELFCT-ND
23 | 2 | R9, R10 | 5.1K | Bourns | CR0805-FX-5101ELF | Mouser | 652-CR0805FX-5101ELF | DigiKey | CR0805-FX-5101ELFCT-ND
24 | 1 | R12 | 220R | Bourns | CR0805-FX-2200ELF | Mouser | 652-CR0805FX-2200ELF | DigiKey | CR0805-FX-2200ELFCT-ND
25 | 3 | R13, R22, R23 | 470R | Bourns | CR0805-FX-4700ELF | Mouser | 652-CR0805FX-4700ELF | DigiKey | CR0805-FX-4700ELFCT-ND
26 | 2 | R15, R16 | 0R | Bourns | CR0805-J/-000ELF | Mouser | 652-CR0805-J/-000ELF | DigiKey | CR0805-J/-000ELFCT-ND
27 | 1 | R17 | 33R | Bourns | CR0805-FX-3002ELF | Mouser | 652-CR0805FX-33R0ELF | DigiKey | 118-CR0805-FX-3002ELFCT-ND
28 | 1 | R18 | 10R | Bourns | CR0805-FX-10R0ELF | Mouser | 652-CR0805FX-10R0ELF | DigiKey | 118-CR0805-FX-10R0ELFCT-ND
29 | 2 | R19, R20 | 56K | Bourns | CR0805-FX-5602ELF | Mouser | 652-CR0805FX-5602ELF | DigiKey | 118-CR0805-FX-5602ELFCT-ND
30 | 2 | R21, R26 | 33K | Bourns | CR0805-FX-3302ELF | Mouser | 652-CR0805FX-3302ELF | DigiKey | CR0805-FX-3302ELFCT-ND
31 | 2 | R24, R25 | 22K | Bourns | CR0805-FX-2202ELF | Mouser | 652-CR0805-FX2202ELF | DigiKey | CR0805-FX-2202ELFCT-ND
32 | 1 | R29 | 2K | Bourns | CR0805-FX-2001ELF | Mouser | 652-CR0805FX-2001ELF | DigiKey | CR0805-FX-2001ELFCT-ND
33 | 1 | SW1 | JS102011JAQN | C&K | JS102011JAQN | Mouser | 611-JS102011JAQN | DigiKey | CKN10720CT-ND
34 | 1 | U1 | ESP32-S3-WROOM-2-N32R8V | Espressif | ESP32-S3-WROOM-2-N32R8V | Mouser | 356-ESP3S3WRM2N32R8V | DigiKey | 1965-ESP32-S3-WROOM-2-N32R8VCT-ND
35 | 1 | U2 | MBT3904DW1T1G | Onsemi | MBT3904DW1T1G | Mouser | 863-MBT3904DW1T1G | DigiKey | MBT3904DW1T1GOSCT-ND
36 | 2 | U3, U7 | USBLC6-2SC6 | ST | USBLC6-2SC6 | Mouser | 511-USBLC6-2SC6 | DigiKey | 497-5235-1-ND
37 | 1 | U4 | FT231XS | FTDI | FT231XS-R | Mouser | 895-FT231XS-R | DigiKey | 768-1129-1-ND
38 | 1 | U5 | MIC2005A-2YM5-TR | Microchip | MIC2005A-2YM5-TR | Mouser | 998-MIC2005A-2YM5TR | DigiKey | 576-3464-1-ND
39 | 1 | U6 | H11L1SR2M | Onsemi | H11L1SR2M | Mouser | 512-H11L1SR2M | DigiKey | H11L1SR2MCT-ND
40 | 1 | U8 | PCM5101A-Q1 | TI | PCM5101AQPWRQ1 | Mouser | 595-PCM5101AQPWRQ1 | DigiKey | 296-37276-1-ND
41 | 1 | U9 | TPA6110A2DGN | TI | TPA6110A2DGNR | Mouser | 595-TPA6110A2DGNR | DigiKey | 296-31976-1-ND
42 | 1 | U10 | MCP73832 | Microchip | MCP73832T-2ACI/OT | Mouser | 579-MCP73832T-2ACIOT | DigiKey | MCP73832T-2ACI/OTCT-ND
43 | 1 | U11 | MAX17048G | Analog Devices | MAX17048G+T10 | Mouser | 700-MAX17048G+T10 | DigiKey | MAX17048G+T10CT-ND
44 | 1 | U12 | TPS7A4533DCQR | TI | TPS7A4533DCQR | Mouser | 595-TPS7A4533DCQR | DigiKey | 296-37002-1-ND
45 | 1 | U13 | MIC2875-5.0YMT | Microchip | MIC2875-5.0YMT | Mouser | 998-MIC2875-50YMTT5 | Microchip | MIC2875-5.0YMT-TR
46 | 1 | VR1 | RK10J12R0A0B | Alps | RK10J12R0A0B | Mouser | 688-RK10J12R0A0B

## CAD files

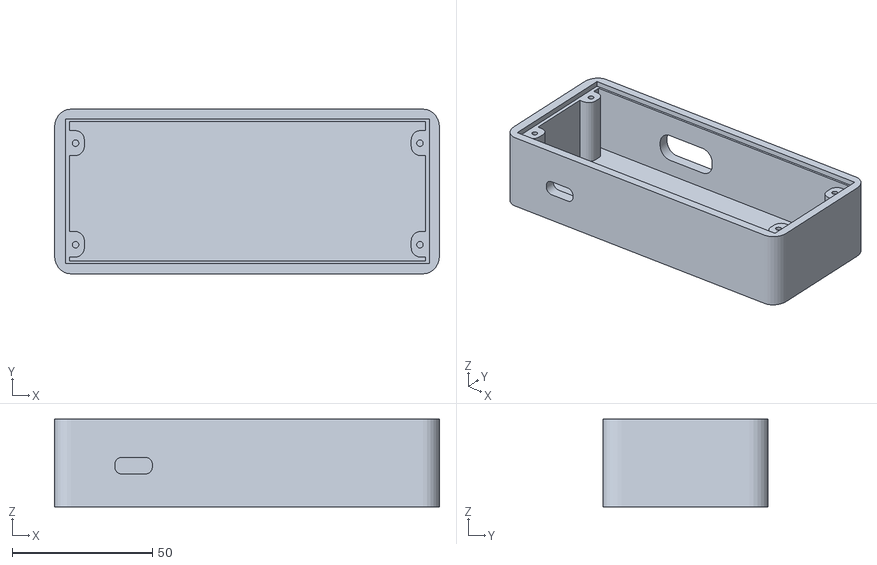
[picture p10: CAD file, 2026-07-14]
3D_Design/AmyBoardCasing_03.stl
137.1 x 58.6 x 31.2

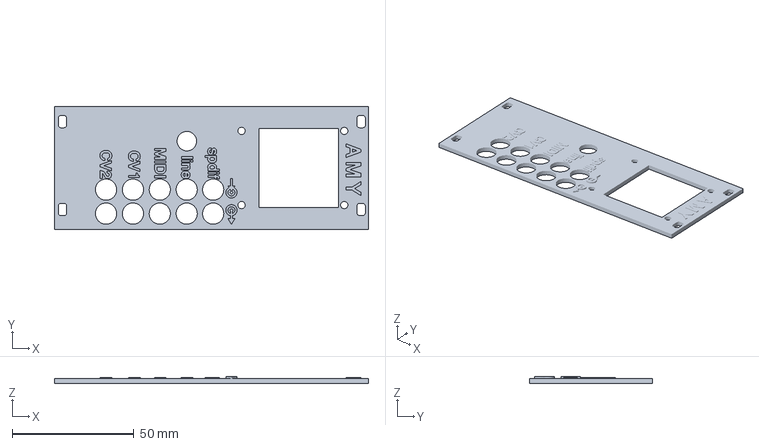
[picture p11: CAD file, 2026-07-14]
Docs/Amyboard/tulipcc-main/docs/pcbs/amyboard/amyboard_front_panel.3mf
128.7 x 50.5 x 2.69 mm

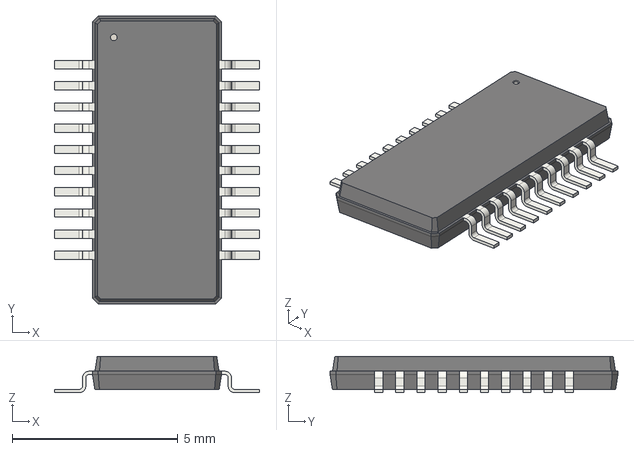
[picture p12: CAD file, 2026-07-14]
Docs/Amyboard/tulipcc-main/docs/pcbs/tulip4_board_v4r9/3dmodels/SSOP-20_3.9x8.7mm_P0.635mm.step
6.20 x 8.70 x 1.10 mm

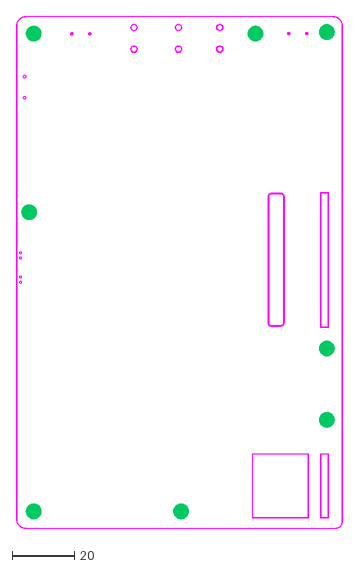
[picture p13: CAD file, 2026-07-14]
Docs/Amyboard/tulipcc-main/docs/pcbs/tulip4_r11/tulipv4_r11_dimension.dxf
105.3 x 165.3

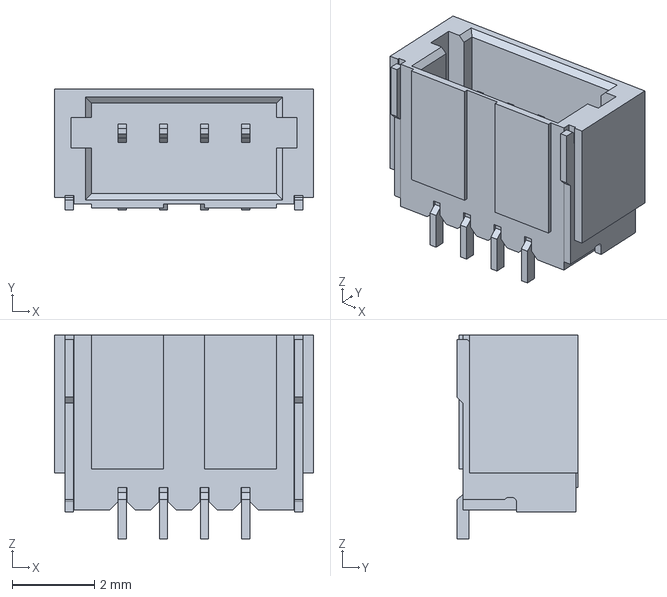
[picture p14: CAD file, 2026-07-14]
Docs/Amyboard/tulipcc-main/docs/pcbs/tulip4_board_v4r9/3dmodels/TE-1734709-4-b-3d.stp
6.30 x 2.95 x 4.95 mm

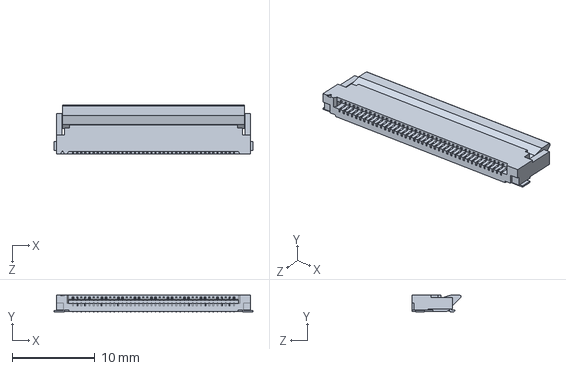
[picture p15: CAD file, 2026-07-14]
Docs/Amyboard/tulipcc-main/docs/pcbs/tulip4_board_v4r9/3dmodels/XF2M_4015_1A.step
24.1 x 2.00 x 5.90 mm

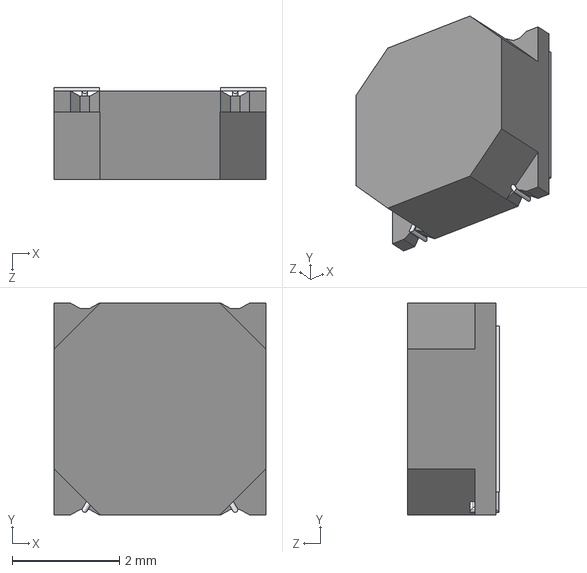
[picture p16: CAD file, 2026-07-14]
Docs/Amyboard/tulipcc-main/docs/pcbs/tulip4_board_v4r9/3dmodels/VISHAY_IFSC-1515AH-01.STEP
3.95 x 3.95 x 1.71 mm

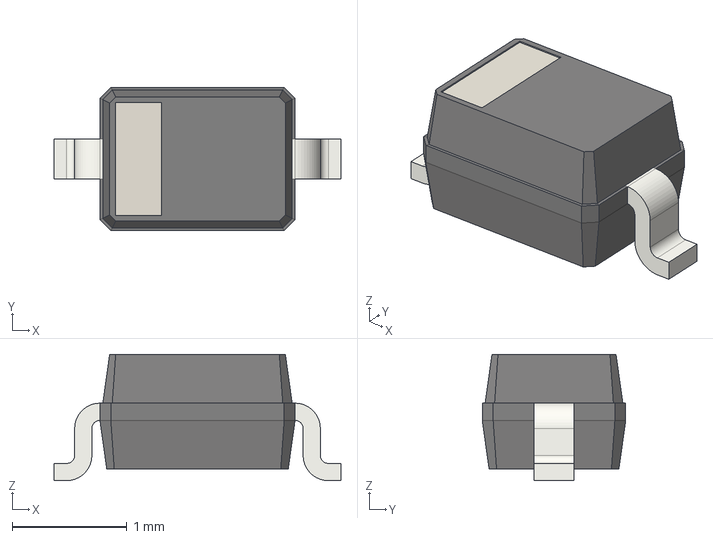
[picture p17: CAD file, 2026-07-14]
Docs/Amyboard/tulipcc-main/docs/pcbs/tulip4_board_v4r9/3dmodels/D_SOD-323.step
2.50 x 1.25 x 1.10 mm

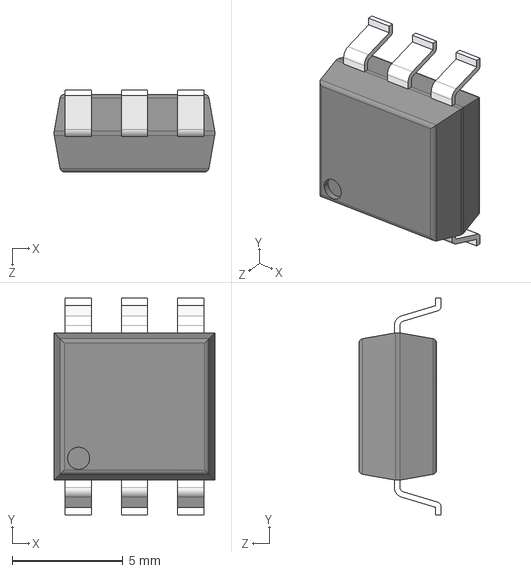
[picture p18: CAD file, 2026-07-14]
Docs/Amyboard/tulipcc-main/docs/pcbs/tulip4_board_v4r9/3dmodels/DIP-6-SMD.step
7.25 x 9.80 x 3.71 mm

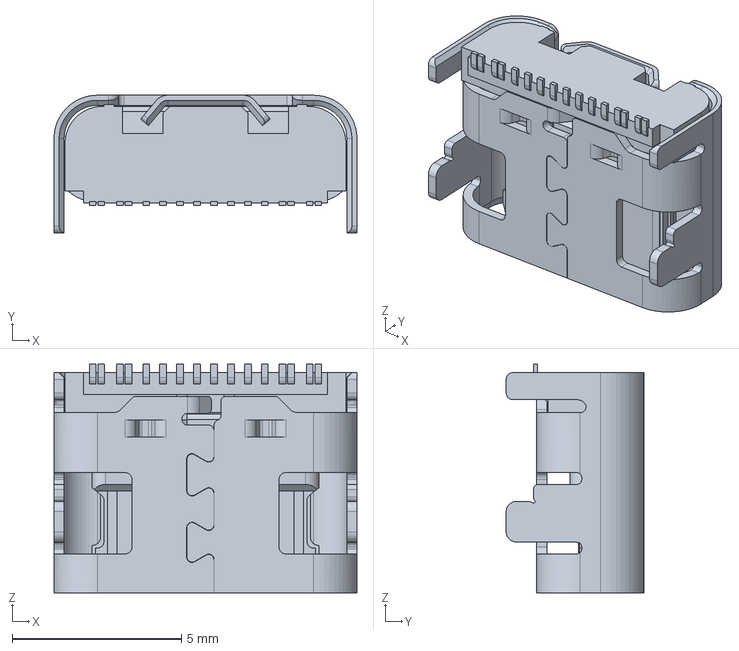
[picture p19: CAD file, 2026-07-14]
Docs/Amyboard/tulipcc-main/docs/pcbs/tulip4_board_v4r9/3dmodels/MOLEX_217179-0001.stp
8.94 x 4.06 x 6.75 mm

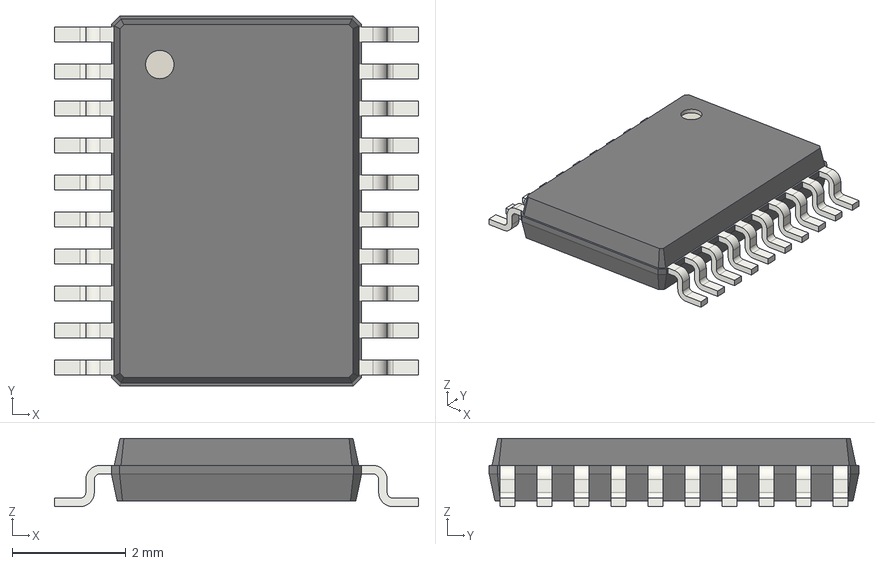
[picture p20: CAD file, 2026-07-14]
Docs/Amyboard/tulipcc-main/docs/pcbs/tulip4_board_v4r9/3dmodels/TSSOP-20_4.4x6.5mm_P0.65mm.step
6.40 x 6.50 x 1.20 mm

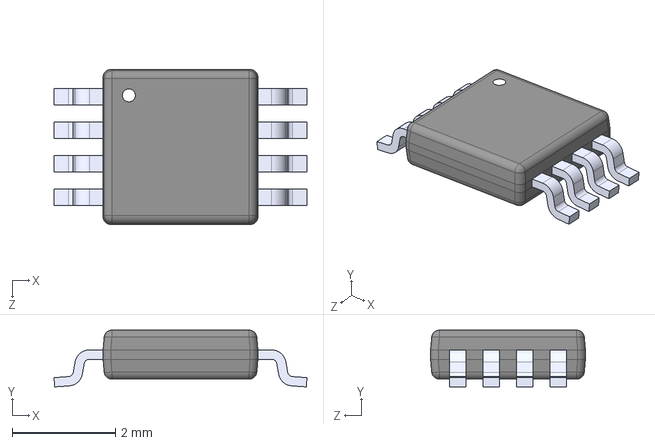
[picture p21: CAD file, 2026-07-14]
Docs/Amyboard/tulipcc-main/docs/pcbs/tulip4_board_v4r9/3dmodels/HVSSOP-8.STEP
4.90 x 1.10 x 3.00 mm

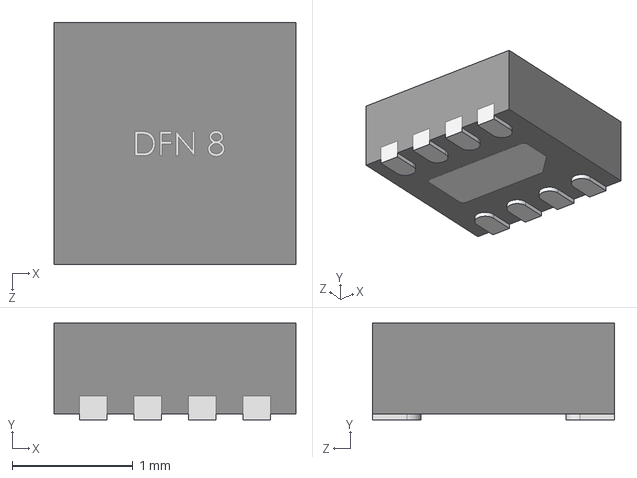
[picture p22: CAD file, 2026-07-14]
Docs/Amyboard/tulipcc-main/docs/pcbs/tulip4_board_v4r9/3dmodels/DFN 8.STEP
2.00 x 0.801 x 2.00 mm

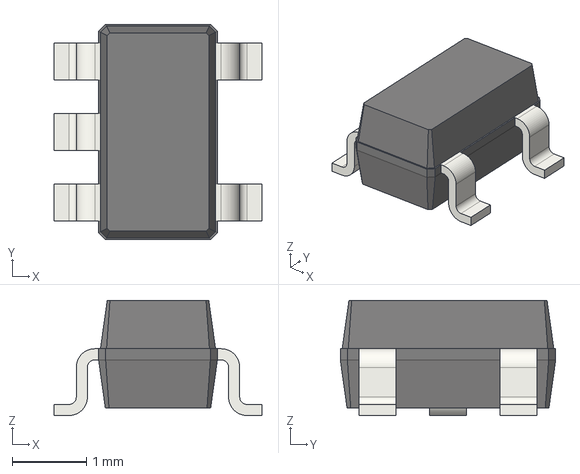
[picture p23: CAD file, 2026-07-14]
Docs/Amyboard/tulipcc-main/docs/pcbs/tulip4_board_v4r9/3dmodels/SOT-23-5.step
2.80 x 2.90 x 1.55 mm

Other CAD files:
Docs/Amyboard/tulipcc-main/docs/pcbs/tulip4_board_v4r9/3dmodels/CAP_WE_865060345007.stp
Docs/Amyboard/tulipcc-main/docs/pcbs/tulip4_board_v4r9/3dmodels/SOT-23-3.step
Docs/Amyboard/tulipcc-main/docs/pcbs/tulip4_board_v4r9/3dmodels/CUI_DEVICES_SJ2-35863B1-SMT-TR.step
Docs/Amyboard/tulipcc-main/docs/pcbs/tulip4_board_v4r9/3dmodels/RK10J1_R.step
Docs/Amyboard/ABX00107-cad-files/ABX00107 DXF/ABX00107_DXF_ALL.DXF
Docs/Amyboard/ABX00107-cad-files/ABX00107 DXF/ABX00107_DXF_BOTTOM ASSEMBLY.DXF
Docs/Amyboard/ABX00107-cad-files/ABX00107 DXF/ABX00107_DXF_BOTTOM SOLDER.DXF
Docs/Amyboard/ABX00107-cad-files/ABX00107 DXF/ABX00107_DXF_BOTTOM.DXF
Docs/Amyboard/ABX00107-cad-files/ABX00107 DXF/ABX00107_DXF_OUTLINE.DXF
Docs/Amyboard/ABX00107-cad-files/ABX00107 DXF/ABX00107_DXF_TOP ASSEMBLY.DXF
Docs/Amyboard/ABX00107-cad-files/ABX00107 DXF/ABX00107_DXF_TOP SOLDER.DXF
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

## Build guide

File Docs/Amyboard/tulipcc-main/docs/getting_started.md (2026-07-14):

# Getting started with the Tulip CC v4r11

Welcome to the [Tulip Creative Computer!](https://github.com/shorepine/tulipcc) Here you'll find out all about your new [Tulip board that you bought from Makerfabs.](https://tulip.computer)

Before we get started, we want to explain the brief history of Tulip and how we work on it. You'll get a lot more out of Tulip if you understand what sort of thing we're building and what sort of community we are.

Tulip

Tulip has been a side project of [mine](https://notes.variogram.com/about) for a few years. I've always wanted a small low-power computer I could write code or games or music on, that was portable and didn't have distractions like a web browser or work email. Over the years, Tulip has gone through a few iterations from [a bunch of wires](tulip_breadboard.md) to the much more polished and cheap board you just bought from our friends at Makerfabs. Along the way, I encouraged [a friend](https://scholar.google.com/citations?user=1H4HuCkAAAAJ&hl=en) to help me with the [music synthesizer underlying Tulip](https://github.com/shorepine/amy). We quickly saw the power and fun of having an excellent analog and FM-style synth that could be controlled in Python on constrained real-time hardware. The Tulip you have in your hands is brand new, we constantly chase bugs, add new features, make new music and demos for it. There's a small but growing community of like minded people on our [Discord](https://discord.gg/TzBFkUb8pG) who try fun experiments as we build. 

**No one working on Tulip makes any money from it**. We're all hobbyists and engineers and scientists and musicians who enjoy working on a small project like this and we hope others can join us. Tulip was designed to be incredibly cheap and completely open source. You can even [build one yourself!](tulip_build.md) I've spent the initial money on PCB design to be able to get this version of Tulip in your hands, and you did pay a tiny amount extra over the raw cost of the parts and assembly needed to build Tulip, to support future design work from our partner Makerfabs. 

**Tulip is fun to use today but still needs help**. You should have fun hacking on and using Tulip, and never expect it to be perfect. You will run into lots of weirdness and challenges. We hope you find those constraints entertaining and inspiring. We're hoping to build a community of people that can work together to make Tulip better every day. Remember, if the Tulip firmware doesn't do it for you, you can always use the hardware you bought for your own creations. You can easily replace our firmware and flash it yourself using the ESP-IDF or Arduino.

If you have problems with Tulip, you can find us on GitHub [issues](https://github.com/shorepine/tulipcc/issues) or the [Discord](https://discord.gg/TzBFkUb8pG). We'll do our best to help out!

-- Brian

## Get used to the ports

Here's a legend to the ports, facing the front. 



## Acesssories you may want

The Tulip board you got can work on its own. Most people will want to add a couple of accessories to make it work even better. You should at least get a computer keyboard, the rest are optional. 

### USB keyboard

Tulip is a very command-line centered interface with some touch controls. You'll have a much easier time using Tulip if you connect a USB computer keyboard to it for typing. It turns the Tulip into a portable "deck" for whatever you can imagine. 

You _should_ be able to use any USB computer keyboard you already have. We're always surprised to find weird keyboards that don't follow all the "rules", so if yours doesn't "just work", get in touch and we'll help you debug!

[If you want a more compact hardware keyboard, the tiny "cardKB" will work great with Tulip, plugged into the I2C port.](https://shop.m5stack.com/products/cardkb-mini-keyboard-programmable-unit-v1-1-mega8a)

### DACs or ADCs for modular synths

If you use modular synths, Tulip is a powerful and fun control surface and way to "program" your modular rig or older analog synth in Python. You can use the existing MIDI ports to do a lot, but if you have CV gear, we recommend getting a I2C DAC to control it. [You can get a 2 channel DAC with modular ready 3.5mm jacks from Makerfabs](https://www.makerfabs.com/mabee-dac-gp8413.html). You can use up to 8 at once for a total of 16 CV outputs!

[You can see a list other supported I2C devices, including ADCs to read CV output, that you can use with your Tulip.](tulip_api.md#i2c--grove--mabee)

### Type-A 3.5mm MIDI adapters to full size

We support both USB MIDI and "standard" TRS MIDI. Most modern MIDI equipment now uses 3.5mm jacks for MIDI connectors. If you have the older 5-pin DIN connectors and want to use them on Tulip, you'll want to pick up a couple of [Type-A 3.5mm adapters](https://www.amazon.com/Kurrent-Electric-Type-3-5mm-Adapter/dp/B0C2RLB3SL/). 

### A hub for USB MIDI

If you want to use a USB MIDI device (like a keyboard or a USB-MIDI adapter), we support that on Tulip from the `USB-KB` connector. We also support simple hubs, since you'll want to connect both a USB MIDI plug and a typing keyboard. USB hub support works but is in constant development, so please let us know if your setup doesn't work! 

### A small li-po battery

Tulip is a low power device and can run on battery for portable computing. There's a standard JST connector on back for flat li-po or 18650 battery packs. Tulip will charge the battery if you connect a USB power cable to the USB charge/PWR port (the top one.) I personally use [this 1200mAh battery](https://www.adafruit.com/product/258). If you want to keep it "inside" Tulip (between the back case and the PCB), you'll want to find a battery that is 5mm or so thin. You can use a piece of double sided tape it keep it inside the battery area of the PCB. 

Larger batteries will work great and last longer, but you'll have to remove the back case to make them fit (or mount the battery some other way.) [This 5200mAh battery pack](https://www.amazon.com/XINLANTECH-Rechargeable-Bluetooth-Electronic-Batteries/dp/B0C2VFTDPY) will last many many hours on Tulip and fit right on the PCB with the back case removed. 

**Please make sure you have the polarity right!** The red cable on the battery should be going to the side of the connector with a + sign on the Tulip board. 

### An extra Alles or five



Tulip supports using [Alles](http://github.com/shorepine/alles) as extra speakers. You control up to dozens of other speakers wirelessly using the AMY synthesizer for amazing multi-channel audio setups, using only a Tulip to control them! [You can get Alles PCBs from our friends at Blinkinlabs.](https://shop.blinkinlabs.com/products/alles-pcb)

## Get started with Tulip



Now that you've got your Tulip, here's how to get started:

 - If you want to use a battery, open the back black case with a screwdriver and plug it in. If you do remove the back case, make sure not to bump the touchscreen connector labeled above as it's been known to be loose (we're working on gluing it down at the factory.) 
 - Connect a USB-C cable from a power adapter or your computer to the **top** USB connector, facing Tulip.
 - Plug in a USB keyboard to the **bottom** USB connector. 
 - Optionally wire up your stereo audio jack, MIDI and I2C connectors if you have them. Headphones will work fine on the audio jack if you don't have a mixer or other sound system. 
 - Turn on the Tulip! The switch is on the top of the board.
 - You should see the following. If you have audio connected, you should also hear a "bleep" sound on startup.



 - Your USB keyboard should be able to type into this screen, called the "REPL". It can accept Python code and some simple system commands. Try `ls` and you should see a directory listing. 

### First, upgrade your Tulip! 

You should **upgrade the firmware on Tulip** whenever you receive it. You should also upgrade maybe once every week or so. We are constantly adding new features, fixing bugs, updating the API. To upgrade your Tulip, connect it to your Wi-Fi first:

 - `tulip.wifi('ssid', 'password')` will return an IP address if successful.
 - `tulip.upgrade()` will walk you through the upgrade. Accept both upgrades -- the system folder and the firmware. This process will take a few minutes in total. Your Tulip will reboot itself when it is done.

[If you don't have easy access to Wi-Fi, or want to flash Tulip from code we haven't released yet, you can also directly flash Tulip from your computer.](tulip_flashing.md)

### More quick start tips

 - Type `run('calibrate')` to calibrate the touch screen if you think it is needed. 
 - The black icon on the bottom right is a launcher, for quick access to some included programs. Tap on `Drums` and you should see (and hear!) a drum machine. 
 - Tap the top right blue "switch" icon to get back to the REPL. Tap it again to get back to the drum machine. You can also use `control-Tab`
 - Tap the red "quit" icon to quit the drum machine.
 - You can `edit('boot.py')` to add anything you want to run on Tulip startup, like wifi, or calibration, or setting up a synth. You can save in the editor with `control-X` and quit with `control-Q`. 
 - You can switch TFB/REPL font sizes with `tulip.tfb_font(x)`: `0` is the default 8x12 font, `1` is a small 6x8 font, and `2` is a big 12x16 font.
 - After joining Wi-Fi, try out Tulip World with `run('worldui')` or `world.ls()` to see files and messages posted by others! 
 - Other things to try:
   - Some games/animations: `run('bunny_bounce')` or `run('planet_boing')` or `run('parallax')` (use control-C to quit), 
   - Music apps: `run('voices')`, `run('juno6')`, `run('drums')`
   - Music demo: `run('xanadu')`
   - Other utlities: `run('wordpad')`, `run('buttons')`. 
 - The code for all of these are available, for you to modify or learn from. We ship a copy of `drums`, `voices` and `juno6` as `my_drums`, `my_voices`, `my_juno6` in `/sys/ex` if you want to edit those. The official versions are read-only and you can't mess them up! 
 - If you've got MIDI plugged in, try playing a note! Tulip boots with Juno-6 patch #0 on MIDI Channel 1. You can use the `voices` app to change that assignment. If you want your MIDI knobs / sliders to control things like the Juno-6 parameters in `run('juno6')`, run a script to learn the sliders and update the midi mapping: `import learn_midi_codes`. Note you'll need to "learn" at least 13 buttons, 8 knobs and 9 sliders for full control of Juno. 
 - Try `world.download('mc_dance')`, `world.download('tracks')`, or `world.download('periodic2')` for some neat things by the Tulip community. 

Your next stop: [check out our making music on Tulip tutorial](music.md)

Then, [check out the API for making your own music, games, graphics with Tulip.](tulip_api.md)

If you're having any issues with your Tulip, please check out our [troubleshooting guide.](troubleshooting.md)

[If you want to work on Tulip itself, check out our guide to compiling and flashing the Tulip firmware.](tulip_flashing.md)

If you find yourself wanting to write Tulip code on a "real" computer, check out [Tulip Web](https://tulip.computer/run) and [Tulip Desktop](tulip_desktop.md), which simulates the Tulip hardware, or, see below how to transfer and edit files remotely.

## How to transfer files between Tulip and your computer

There are a few ways to files between Tulip and your computer. You can connect Tulip to your computer over a USB cable (the top USB port, the charging/UART/power port) and use a program called `mpremote`, or you can do it wirelessly by turning on Wi-Fi on the Tulip and using our Tulip World BBS or setting up a little server on your computer. 

### Using `mpremote`

[`mpremote`](https://docs.micropython.org/en/latest/reference/mpremote.html) is provided by the MicroPython project to be able to control and interact with MicroPython on many kinds of devices, including Tulip! It connects to Tulip over the UART USB connection and you are able to use the Tulip REPL, edit, upload and download files. (It does a lot more, but we'll just discuss file transfer here.)

**You may need to install the USB->Serial driver first for your computer's OS.** Some OSes already have it installed and some don't. If `mpremote` can't find a port, [try to install the CH340K drivers.](https://www.wch-ic.com/downloads/CH341SER_ZIP.html). 

First, install `mpremote`on your computer. Usually, this is (in your Terminal app) `pip install mpremote`. (If you don't have `pip`, please search for how to install it on your OS.) Once it's installed, make sure you've connected a USB cable from Tulip's top USB port - "USB pwr/charge/program" - to your computer. Then, with Tulip on, just run `mpremote` on your computer's terminal. You should see the Tulip's REPL on your screen! You can type into it and see it there. It's a fine way to control almost all of Tulip. 

To transfer a file from your computer to Tulip from mpremote, use `mpremote resume fs cp local_file.py :tulip_file.py`. This takes a file called `local_file.py` on your computer in the folder you're in, and transfers it to the current Tulip directory, calling it `tulip_file.py`. It's pretty fast! To transfer a file from Tulip to your computer, do it in reverse: `mpremote resume fs cp :tulip_file.py local_file.py`. 

To edit a file on Tulip directly on your computer, just do `mpremote resume edit file.py`. This will open whatever `EDITOR` you have set in your shell's environment. Once you save it in your editor, it'll be saved on Tulip! 

[See a lot more about `mpremote`](https://docs.micropython.org/en/latest/reference/mpremote.html). Note that we've only confirmed Tulip to work with the `fs`, `mount` and `repl` commands so far.  And on Tulip, you always need to add `resume` to your `mpremote` command. If you have any issues let us know! 

## Using Wi-Fi

With Wi-Fi, after you do `tulip.wifi('ssid', 'password')` first, there are two ways of getting files between Tulip hardware and your computer:

 - **Use Tulip World and Tulip Desktop:** On [Tulip Desktop](tulip_desktop.md) your files are in your  `~/.local/share/tulipcc/user` folder. You can edit and add files there directly and use `world.upload(folder)` or `world.upload(filename)` to place files on Tulip World from either Deskop or hardware Tulip. You can retrieve these files with `world.download(folder)` or `world.download(filename)`. The only downside to this method is that your files are publicly available to anyone else on Tulip World, so please don't share private information using Tulip World. 

 - **Use our file transfer script**: You can privately transfer files to and from a Tulip with our Python script [file_server.py](../tulip/shared/util/file_server.py). Download that script to your computer somewhere. Then, on your computer's terminal, run it, like `$ python file_server.py`. Wherever you run that script, all files in the folder you ran it from will be available to your Tulip. Use your computers' network manager to find out your computers' IP address (the `192.168.1.23` bit below is an example of it.)\
 \
 You can transfer any files **from** a computer to Tulip with `tulip.url_save(url, filename)` like: `tulip.url_save('http://192.168.1.23:8000/file.py', 'file.py')`. The `file.py` should be a file in the current directory that you've run `file_server.py` from.\
 \
 To transfer from a Tulip **to** a computer, use `tulip.url_put(url, file)` like `tulip.url_put('http://192.168.1.23:8000', 'file.py')` and it will appear in that folder on your computer.

[shore pine sound systems discord **Chat about Tulip on our Discord!**](https://discord.gg/TzBFkUb8pG)

Have fun! See you on Tulip World!

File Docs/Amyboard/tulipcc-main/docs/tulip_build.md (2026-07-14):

# Building your own Tulip Creative Computer

Custom Tulip laptop

[If you don't want to buy your own Tulip CC](https://tulip.computer), there are four ways to start building and using your own [Tulip Creative Computer.](../README.md) 

 * [No hardware for me, I want to just run Tulip Desktop or Tulip Web on my desktop computer for now.](tulip_desktop.md) Use this option if you're just curious about Tulip and want to try it out. If you get into it, you can then upgrade to real hardware!
 * [I just want to build a temporary Tulip with hookup wires and a breadboard.](tulip_breadboard.md) Do this if you aren't great at soldering or just want to quickly throw a Tulip together. It won't be very stable and will be hard to move or use portably, as there's many wires. But it'll work!
 * [I can solder through-hole just fine and want to build a more reliable Tulip with your breakout board PCB.](tulip_breakout.md) Do this if you are competent at thru-hole soldering and want to make a reliable Tulip by soldering together other breakout boards. You can buy a cheap PCB that bridges together all the things you need. It's more bulky than our integrated Tulip board, but works just the same. 
 * [I want to build a single board Tulip and know how to solder SMT or use a service that assembles one for me.](tulip_board.md) This is the deluxe option: a fully integrated Tulip board with connectors for a display, audio, MIDI and keyboard. Like a Raspberry Pi but it's Tulip. But you'll need either good soldering skills (many small SMT parts and the FPC connector) or use a service like JLCPCB, PCBway, or Aisler to assemble the board for you. 

 When you're done building your Tulip Creative Computer, [next learn how to compile and flash the firmware.](tulip_flashing.md)

Any questions? [Chat with us on our discussions page.](https://github.com/shorepine/tulipcc/discussions)

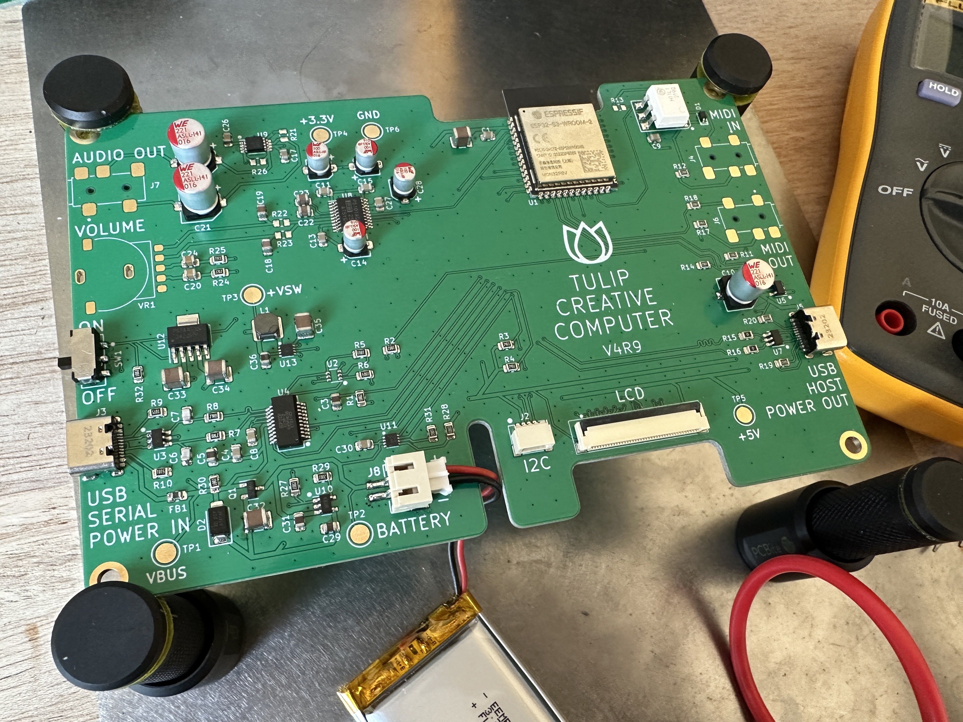
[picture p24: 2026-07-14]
Docs/Amyboard/tulipcc-main/docs/pics/nicoboard-assembled.jpg

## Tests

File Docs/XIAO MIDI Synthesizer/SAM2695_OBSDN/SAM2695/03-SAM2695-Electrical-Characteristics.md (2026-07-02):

---
tags: [hardware, sam2695, electrical]
---

# SAM2695 — Electrical Characteristics

⬅ [[00-SAM2695-Index]]

## Absolute maximum ratings (all voltages vs GND=0V)

| Parameter | Symbol | Min | Max | Unit |
|---|---|---|---|---|
| Temperature under bias | – | -55 | +125 | °C |
| Storage temperature | – | -65 | +150 | °C |
| Voltage on any 5V-tolerant pin | – | -0.3 | 5.5 | V |
| Voltage on any non-5V-tolerant pin | – | -0.3 | VD33+0.3 | V |
| Supply voltage (I/O) | VD33 | -0.3 | 3.6 | V |
| Supply voltage (CODEC analog) | VA33 | -0.3 | 3.6 | V |

> Stress beyond these ratings may cause permanent damage; not a functional operating spec.

## Recommended operating conditions

| Parameter | Symbol | Min | Typ | Max | Unit |
|---|---|---|---|---|---|
| Digital supply voltage | VD33 | 2.7 | 3.3 | 3.6 | V |
| Analog supply voltage (CODEC) | VA33 | 2.7 | 3.3 | 3.6 | V |
| Operating ambient temperature | tA | -25 | – | +70 | °C |

## D.C. characteristics
(TA=25°C, VD33=3.3V, X1=12MHz, AOUTL/AOUTR load = 47kΩ)

| Parameter | Symbol | Min | Typ | Max | Unit |
|---|---|---|---|---|---|
| Low level input voltage | VIL | – | – | 0.8 | V |
| High level input voltage, 5VT pins | VIH | 2 | – | – | V |
| High level input voltage, non-5VT pins | VIH | 2 | – | – | V |
| Low level output voltage @ IOL=IOHL min | VOL | – | – | 0.4 | V |
| High level output voltage @ IOH=IOHL min | VOH | 2.4 | – | – | V |
| Schmitt-trigger negative threshold | VTN | 0.8 | 1.1 | – | V |
| Schmitt-trigger positive threshold | VTP | – | 1.6 | 2 | V |
| Driving capability (DR4 pins) | IOHL | – | – | 4 | mA |
| Driving capability (DR8 pins) | IOHL | – | 8 | – | mA |
| Input leakage current | IIN | -10 | ±1 | 10 | µA |
| OUTVC12 output voltage | VD12 | 1.14 | 1.2 | 1.26 | V |
| Digital power supply current | ID33 | – | 10 | – | mA |
| Analog power supply current | IA33 | – | 8 | – | mA |
| Power down supply current | – | – | 17 | – | µA |
| Pull-up/down/keeper resistor | Rudk | 30 | 75 | 190 | kΩ |

## DAC characteristics
(TA=25°C, VA33=3.3V)

| Parameter | Symbol | Typ | Max | Unit |
|---|---|---|---|---|
| THD+N (at -6dB) | THD+N | -75 | – | dB |
| Dynamic range (-60dBFS, A-weighted) | DR | 86 | – | dB |
| Inter-channel isolation (1kHz) | – | 89 | – | dB |
| Full-scale output voltage | – | 0.85×VA33 | – | Vpp |
| VCM max allowable DC current source | – | – | 0.1 | mA |
| VCM reference voltage (10µF+100nF caps) | – | VA33÷2 ±50mV | – | V |
| Output gain control, 1dB steps | – | -40 to +6 | – | dB |
| Output gain, additional setting 1 | – | -43.5 | – | dB |
| Output gain, additional setting 2 | – | -58.5 | – | dB |
| Max output power, headphone mode | – | 30 | – | mW |

## ADC characteristics
(TA=25°C, VA33=3.3V)

| Parameter | Symbol | Min | Typ | Max | Unit |
|---|---|---|---|---|---|
| THD+N (at -6dB) | THD+N | – | -75 | -70 | dB |
| Dynamic range (-60dBFS, A-weighted) | DR | – | 86 | – | dB |
| Full-scale input voltage | – | – | 0.6×VA33 | – | Vpp |
| Input gain without boost | – | – | +4 | – | dB |
| Input gain with boost | – | +22 | – | +24 | dB |
| Input programmable gain amp, 1dB steps | – | -27 | – | +36 | dB |
| Frequency response (-3dB bandwidth) | – | 0.41 | – | – | Fs |
| MICIN input resistance, boost disabled | – | – | 35 | – | kΩ |
| MICIN input resistance, boost enabled | – | – | 3.5 | – | kΩ |

## Related
- [[15-SAM2695-Codec-Control-Sysex]] — for the actual gain-control bitfields (OUTG, ING, MICBT) used to hit these ranges in firmware
- [[02-SAM2695-Pin-Description]]

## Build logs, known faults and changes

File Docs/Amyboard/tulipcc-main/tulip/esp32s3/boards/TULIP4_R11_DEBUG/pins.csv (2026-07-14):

I2C_SCL | GPIO9
I2C_SDA | GPIO8
FG_INT | GPIO21
UART0_TX | GPIO43
UART0_RX | GPIO44

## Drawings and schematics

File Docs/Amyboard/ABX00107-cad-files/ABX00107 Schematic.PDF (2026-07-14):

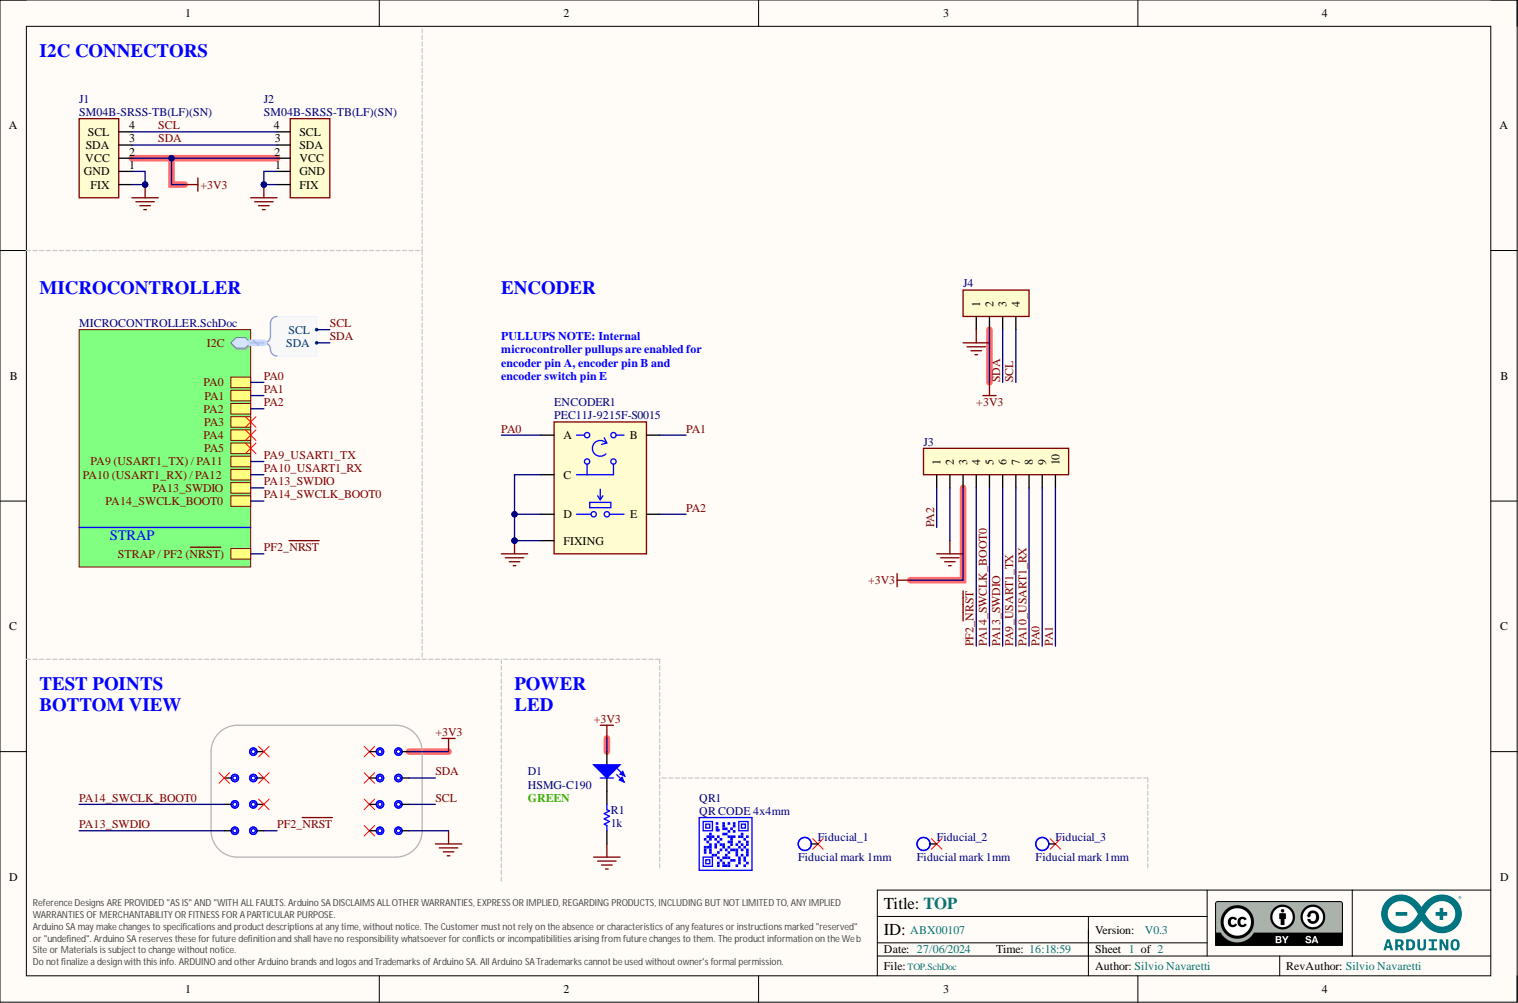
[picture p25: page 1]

SM04B-SRSS-TB(LF)(SN)

PULLUPS NOTE: Internal
microcontroller pullups are enabled for
encoder pin A, encoder pin B and
encoder switch pin E

Reference Designs ARE PROVIDED "AS IS" AND "WITH ALL FAULTS. Arduino SA DISCLAIMS ALL OTHER WARRANTIES, EXPRESS OR IMPLIED, REGARDING PRODUCTS, INCLUDING BUT NOT LIMITED TO, ANY IMPLIED
WARRANTIES OF MERCHANTABILITY OR FITNESS FOR A PARTICULAR PURPOSE.
Arduino SA may make changes to specifications and product descriptions at any time, without notice. The Customer must not rely on the absence or characteristics of any features or instructions marked "reserved"
or "undefined". Arduino SA reserves these for future definition and shall have no responsibility whatsoever for conflicts or incompatibilities arising from future changes to them. The product information on the Web
Site or Materials is subject to change without notice.

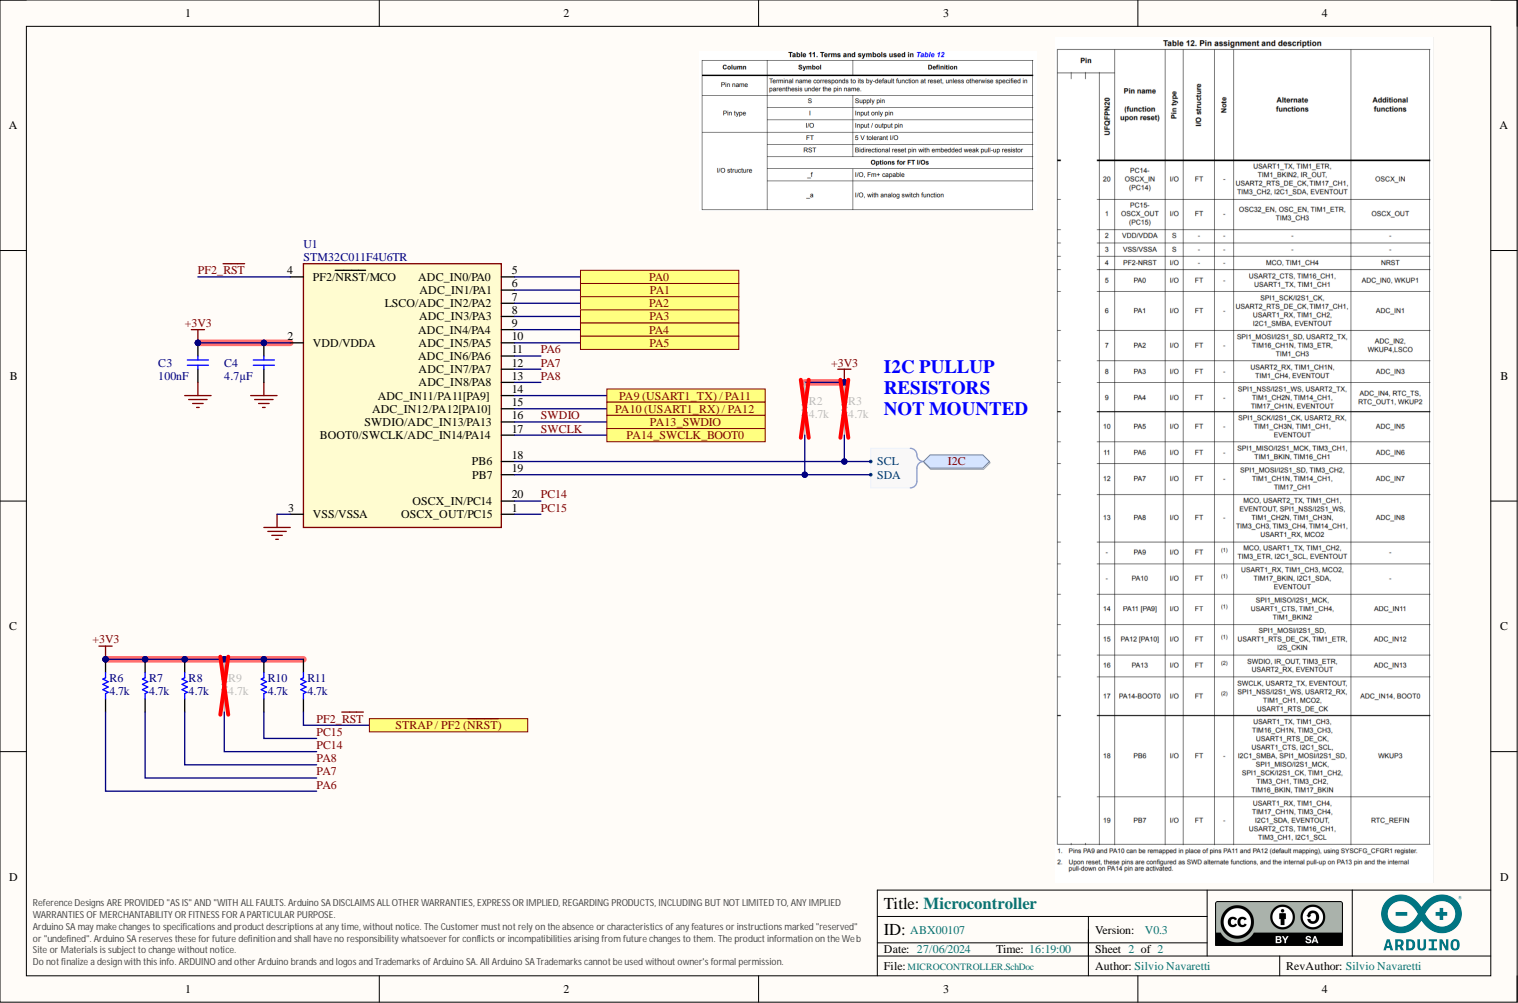
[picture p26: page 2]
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

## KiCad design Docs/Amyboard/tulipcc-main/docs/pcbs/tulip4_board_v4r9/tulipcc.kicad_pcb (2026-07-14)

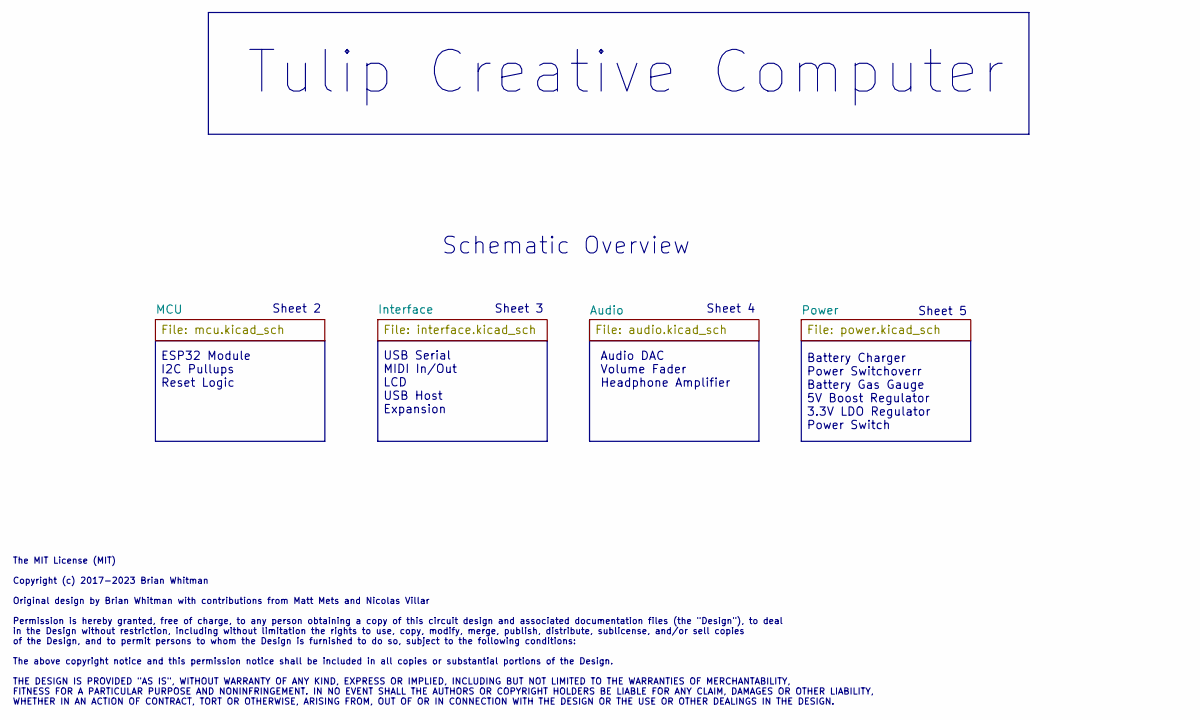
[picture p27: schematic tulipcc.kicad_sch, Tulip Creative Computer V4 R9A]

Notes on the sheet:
Schematic Overview
Sheet 2
Sheet 3
Battery Charger Power Switchoverr Battery Gas Gauge 5V Boost Regulator 3.3V LDO Regulator Power Switch
USB Serial MIDI In/Out LCD USB Host Expansion
Tulip Creative Computer
Sheet 4
Sheet 5
The MIT License (MIT) Copyright (c) 2017-2023 Brian Whitman Original design by Brian Whitman with contributions from Matt Mets and Nicolas Villar Permission is hereby granted, free of charge, to any person obtaining a copy of this circuit design and associated documentation files (the "Design"), to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
Audio DAC Volume Fader Headphone Amplifier
ESP32 Module I2C Pullups Reset Logic

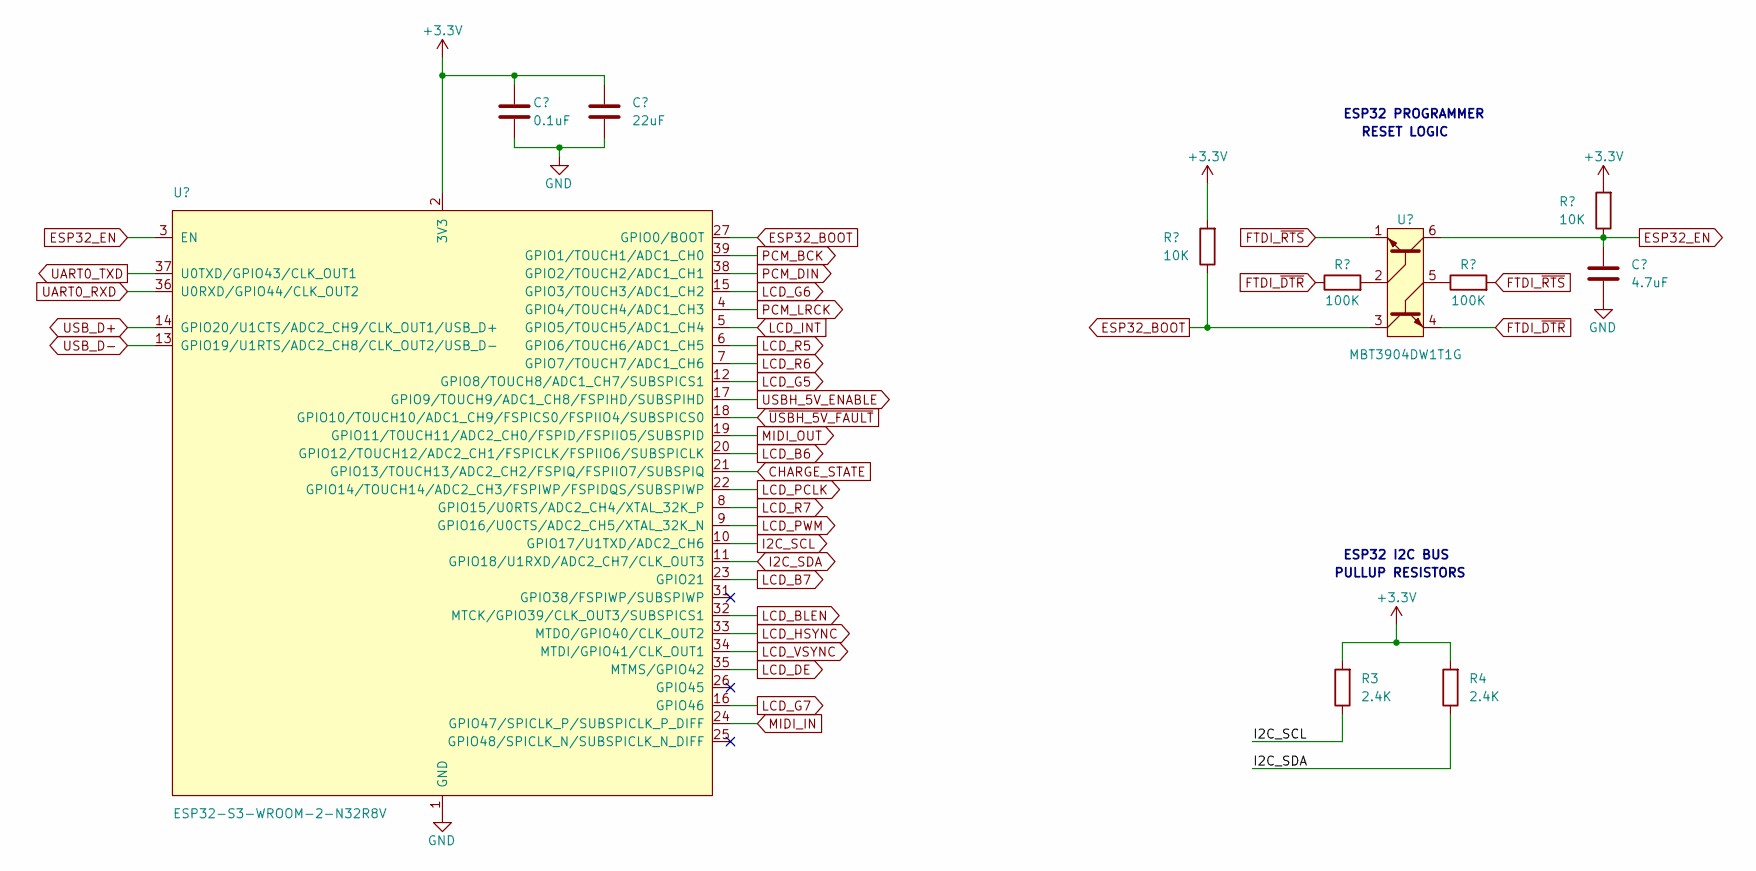
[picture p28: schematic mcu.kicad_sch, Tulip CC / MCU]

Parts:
C1: 0.1uF; C_0805_2012; Part # C0805C104K5RAC7411
C2: 22uF; C_1210_3225; Rating 16V; Part # C1210C226M4RAC7210
C3: 4.7uF; C_0805_2012; Part # C0805C475K3RACTU
R1, R2: 10K; R_0805_2012; Part # CR0805-FX-1002ELF
R3, R4: 2.4K; R_0805_2012; Part # CR0805-FX-2401ELF
R5, R6: 100K; R_0805_2012; Part # CR0805-FX-1003ELF
U1: ESP32-S3-WROOM-2-N32R8V; ESP32-S3-WROOM-2; Part # ESP32-S3-WROOM-2-N32R8V
U2: MBT3904DW1T1G; SOT-363_SC-70-6; Part # MBT3904DW1T1G

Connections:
+3.3V: C1.1, C2.2, R1.2, R2.2, R3.2, R4.2, U1.2 (3V3); also elsewhere on the board
CHARGE_STATE: U1.21 (GPIO13/TOUCH13/ADC2_CH2/FSPIQ/FSPIIO7/S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); also elsewhere on the board
ESP32_BOOT: R2.1, U1.27 (GPIO0/BOOT), U2.3
ESP32_EN: C3.1, R1.1, U1.3 (EN), U2.6
FTDI_~DTR: R5.1, U2.4; also elsewhere on the board
FTDI_~RTS: R6.2, U2.1; also elsewhere on the board
GND: C1.2, C2.1, C3.2, U1.1 (GND), U1.40 (GND), U1.41 (GND); also elsewhere on the board
I2C_SCL: R3.1, U1.10 (GPIO17/U1TXD/ADC2_CH6); also elsewhere on the board
I2C_SDA: R4.1, U1.11 (GPIO18/U1RXD/ADC2_CH7/CLK_OUT3); also elsewhere on the board
LCD_B6: U1.20 (GPIO12/TOUCH12/ADC2_CH1/FSPICLK/FSPIIO6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); also elsewhere on the board
LCD_B7: U1.23 (GPIO21); also elsewhere on the board
LCD_BLEN: U1.32 (MTCK/GPIO39/CLK_OUT3/SUBSPICS1); also elsewhere on the board
LCD_DE: U1.35 (MTMS/GPIO42); also elsewhere on the board
LCD_G5: U1.12 (GPIO8/TOUCH8/ADC1_CH7/SUBSPICS1); also elsewhere on the board
LCD_G6: U1.15 (GPIO3/TOUCH3/ADC1_CH2); also elsewhere on the board
LCD_G7: U1.16 (GPIO46); also elsewhere on the board
LCD_HSYNC: U1.33 (MTDO/GPIO40/CLK_OUT2); also elsewhere on the board
LCD_INT: U1.5 (GPIO5/TOUCH5/ADC1_CH4); also elsewhere on the board
LCD_PCLK: U1.22 (GPIO14/TOUCH14/ADC2_CH3/FSPIWP/FSPIDQS/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); also elsewhere on the board
LCD_PWM: U1.9 (GPIO16/U0CTS/ADC2_CH5/XTAL_32K_N); also elsewhere on the board
LCD_R5: U1.6 (GPIO6/TOUCH6/ADC1_CH5); also elsewhere on the board
LCD_R6: U1.7 (GPIO7/TOUCH7/ADC1_CH6); also elsewhere on the board
LCD_R7: U1.8 (GPIO15/U0RTS/ADC2_CH4/XTAL_32K_P); also elsewhere on the board
LCD_VSYNC: U1.34 (MTDI/GPIO41/CLK_OUT1); also elsewhere on the board
MIDI_IN: U1.24 (GPIO47/SPICLK_P/SUBSPICLK_P_DIFF); also elsewhere on the board
MIDI_OUT: U1.19 (GPIO11/TOUCH11/ADC2_CH0/FSPID/FSPIIO5/S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); also elsewhere on the board
unnamed: R5.2, U2.2
unnamed: R6.1, U2.5
PCM_BCK: U1.39 (GPIO1/TOUCH1/ADC1_CH0); also elsewhere on the board
PCM_DIN: U1.38 (GPIO2/TOUCH2/ADC1_CH1); also elsewhere on the board
PCM_LRCK: U1.4 (GPIO4/TOUCH4/ADC1_CH3); also elsewhere on the board
UART0_RXD: U1.36 (U0RXD/GPIO44/CLK_OUT2); also elsewhere on the board
UART0_TXD: U1.37 (U0TXD/GPIO43/CLK_OUT1); also elsewhere on the board
USBH_5V_ENABLE: U1.17 (GPIO9/TOUCH9/ADC1_CH8/FSPIHD/SUBSPIHD); also elsewhere on the board
USB_D+: U1.14 (GPIO20/U1CTS/ADC2_CH9/CLK_OUT1/USB_D+); also elsewhere on the board
USB_D-: U1.13 (GPIO19/U1RTS/ADC2_CH8/CLK_OUT2/USB_D-); also elsewhere on the board
~USBH_5V_FAULT: U1.18 (GPIO10/TOUCH10/ADC1_CH9/FSPICS0/FSPIIO4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); also elsewhere on the board

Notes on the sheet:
PULLUP RESISTORS
RESET LOGIC
ESP32 I2C BUS
ESP32 PROGRAMMER

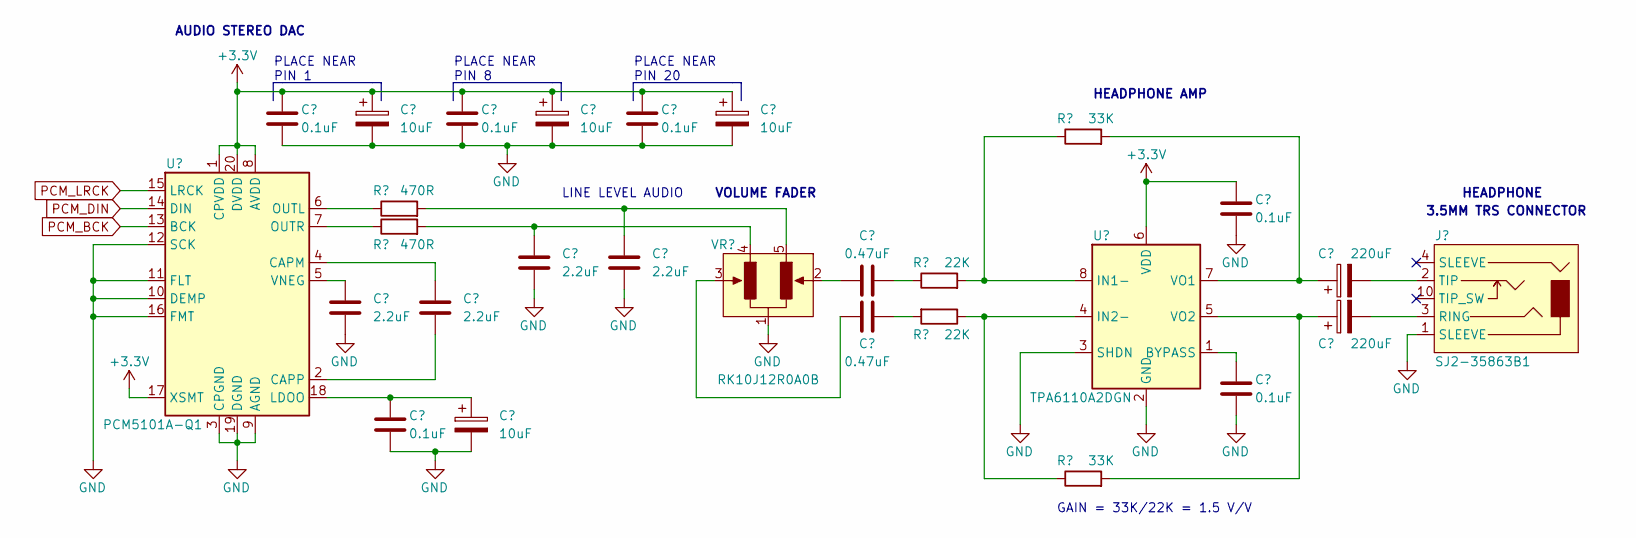
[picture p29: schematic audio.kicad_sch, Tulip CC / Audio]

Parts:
C11, C13, C15, C17, C26, C27: 0.1uF; C_0805_2012; Part # C0805C104K5RAC7411
C12, C14, C16, C28: 10uF; CAP_WE_865060340001; Rating 16V; Part # 865060340001
C18, C19, C22, C23: 2.2uF; C_0805_2012; Part # C0805C225K3RACTU
C20, C24: 0.47uF; C_0805_2012; Part # C0805C474K3RACTU
C21, C25: 220uF; CAP_WE_865060345007; Rating 16V; Part # 865060345007
J7: SJ2-35863B1; CON_CUI_SJ2-35863B1-SMT; Part # SJ2-35863B1-SMT-TR
R21, R26: 33K; R_0805_2012; Part # CR0805-FX-3002ELF
R22, R23: 470R; R_0805_2012; Part # CR0805-FX-4700ELF
R24, R25: 22K; R_0805_2012; Part # CR0805-FX-2202ELF
U8: PCM5101A-Q1; TSSOP-20_4.4x6.5mm_P0.65mm; Part # PCM5101AQPWRQ1
U9: TPA6110A2DGN; HVSSOP-8-1EP_3x3mm_P0.65mm_EP1.57x1.89mm; Part # TPA6110A2DGNR
VR1: RK10J12R0A0B; ALPS_RK10J12R0A0B; Part # RK10J12R0A0B

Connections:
+3.3V: C11.1, C12.1, C13.1, C14.1, C15.1, C16.1, C17.1, U8.1 (CPVDD), U8.8 (AVDD), U8.17 (XSMT), U8.20 (DVDD), U9.6 (VDD); also elsewhere on the board
GND: C11.2, C12.2, C13.2, C14.2, C15.2, C16.2, C17.2, C18.2, C19.2, C22.2, C26.2, C27.2, C28.2, J7.1 (SLEEVE), U8.3 (CPGND), U8.9 (AGND), U8.10 (DEMP), U8.11 (FLT), U8.12 (SCK), U8.16 (FMT), U8.19 (DGND), U9.2 (GND), U9.3 (SHDN), U9.9 (GND), VR1.1; also elsewhere on the board
unnamed: C18.1, R23.2, VR1.4
unnamed: C19.1, R22.2, VR1.5
unnamed: C20.1, R24.1
unnamed: C20.2, VR1.2
unnamed: C24.1, R25.2
unnamed: C24.2, VR1.3
unnamed: C25.2, J7.3 (RING)
unnamed: C21.2, J7.2 (TIP)
unnamed: C23.1, U8.4 (CAPM)
unnamed: C23.2, U8.2 (CAPP)
unnamed: C27.1, C28.1, U8.18 (LDOO)
unnamed: R22.1, U8.6 (OUTL)
unnamed: R23.1, U8.7 (OUTR)
unnamed: C22.1, U8.5 (VNEG)
unnamed: C26.1, U9.1 (BYPASS)
unnamed: R21.1, R24.2, U9.8 (IN1-)
unnamed: R25.1, R26.1, U9.4 (IN2-)
unnamed: C21.1, R21.2, U9.7 (VO1)
unnamed: C25.1, R26.2, U9.5 (VO2)
PCM_BCK: U8.13 (BCK); also elsewhere on the board
PCM_DIN: U8.14 (DIN); also elsewhere on the board
PCM_LRCK: U8.15 (LRCK); also elsewhere on the board

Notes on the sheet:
GAIN = 33K/22K = 1.5 V/V
3.5MM TRS CONNECTOR
HEADPHONE AMP
VOLUME FADER
PLACE NEAR PIN 20
PLACE NEAR PIN 1
HEADPHONE
PLACE NEAR PIN 8
LINE LEVEL AUDIO
AUDIO STEREO DAC

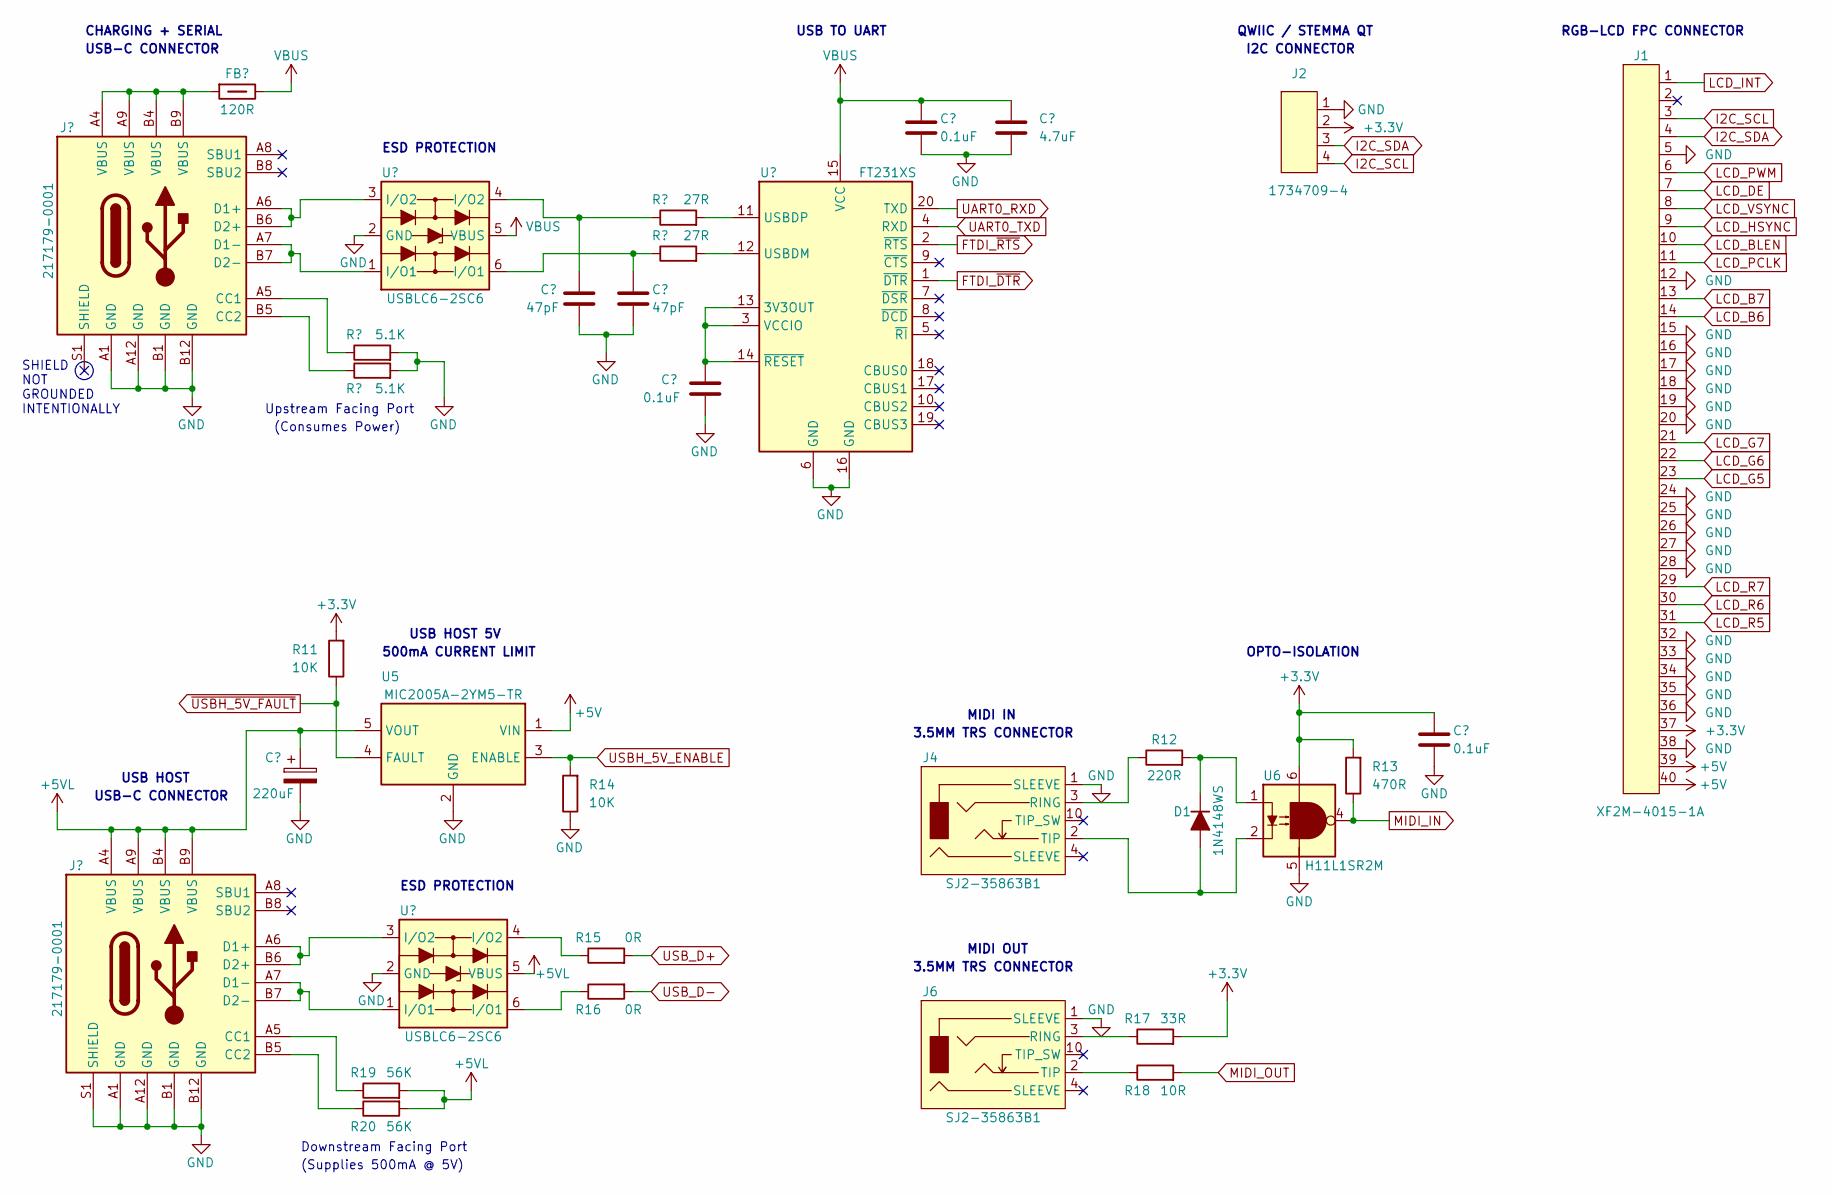
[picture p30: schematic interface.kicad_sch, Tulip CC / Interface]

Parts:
C4, C8, C9: 0.1uF; C_0805_2012; Part # C0805C104K5RAC7411
C5: 4.7uF; C_0805_2012; Part # C0805C475K3RACTU
C6, C7: 47pF; C_0805_2012; Part # C0805C470K5RACTU
C10: 220uF; CAP_WE_865060345007; Rating 16V; Part # 865060345007
D1: 1N4148WS; D_SOD-323; Part # 1N4148WS-G3-08
FB1: 120R; FB_0805_2012; Part # BLM21PG121SN1D
J1: XF2M-4015-1A; OMRON_XF2M-4015-1A; Part # XF2M-4015-1A
J2: 1734709-4; TE_1734709-4; Part # 1734709-4
J3, J5: 217179-0001; USB-C_Molex_217179-0001; Part # 217179-0001
J4, J6: SJ2-35863B1; CON_CUI_SJ2-35863B1-SMT; Part # SJ2-35863B1-SMT-TR
R7, R8: 27R; R_0805_2012; Part # CR0805-FX-27R0ELF
R9, R10: 5.1K; R_0805_2012; Part # CR0805-FX-5101ELF
R11, R14: 10K; R_0805_2012; Part # CR0805-FX-1002ELF
R12: 220R; R_0805_2012; Part # CR0805-FX-2200ELF
R13: 470R; R_0805_2012; Part # CR0805-FX-4700ELF
R15, R16: 0R; R_0805_2012; Part # CR0805-J/-000ELF
R17: 33R; R_0805_2012; Part # CR0805-FX-3002ELF
R18: 10R; R_0805_2012; Part # CR0805-FX-10R0ELF
R19, R20: 56K; R_0805_2012; Part # CR0805-FX-5602ELF
U3, U7: USBLC6-2SC6; SOT-23-6; Part # USBLC6-2SC6
U4: FT231XS; SSOP-20_3.9x8.7mm_P0.635mm; Part # FT231XS-R
U5: MIC2005A-2YM5-TR; SOT-23-5; Part # MIC2005A-2YM5-TR
U6: H11L1SR2M; PDIP6-SMD; Part # H11L1SR2M

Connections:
+3.3V: C9.1, J1.37, J2.2, R11.2, R13.2, R17.2, U6.6; also elsewhere on the board
+5V: J1.39, J1.40, U5.1 (VIN); also elsewhere on the board
+5VL: C10.1, J5.A4 (VBUS), J5.A9 (VBUS), J5.B4 (VBUS), J5.B9 (VBUS), R19.2, R20.2, U5.5 (VOUT), U7.5 (VBUS)
FTDI_~DTR: U4.1 (~DTR); also elsewhere on the board
FTDI_~RTS: U4.2 (~RTS); also elsewhere on the board
GND: C4.2, C5.2, C6.2, C7.2, C8.2, C9.2, C10.2, J1.5, J1.12, J1.15, J1.16, J1.17, J1.18, J1.19, J1.20, J1.24, J1.25, J1.26, J1.27, J1.28, J1.32, J1.33, J1.34, J1.35, J1.36, J1.38, J2.1, J3.A1 (GND), J3.A12 (GND), J3.B1 (GND), J3.B12 (GND), J4.1 (SLEEVE), J5.A1 (GND), J5.A12 (GND), J5.B1 (GND), J5.B12 (GND), J5.S1 (SHIELD), J6.1 (SLEEVE), R9.2, R10.2, R14.1, U3.2 (GND), U4.6 (GND), U4.16 (GND), U5.2 (GND), U6.5, U7.2 (GND); also elsewhere on the board
I2C_SCL: J1.3, J2.4; also elsewhere on the board
I2C_SDA: J1.4, J2.3; also elsewhere on the board
LCD_B6: J1.14; also elsewhere on the board
LCD_B7: J1.13; also elsewhere on the board
LCD_BLEN: J1.10; also elsewhere on the board
LCD_DE: J1.7; also elsewhere on the board
LCD_G5: J1.23; also elsewhere on the board
LCD_G6: J1.22; also elsewhere on the board
LCD_G7: J1.21; also elsewhere on the board
LCD_HSYNC: J1.9; also elsewhere on the board
LCD_INT: J1.1; also elsewhere on the board
LCD_PCLK: J1.11; also elsewhere on the board
LCD_PWM: J1.6; also elsewhere on the board
LCD_R5: J1.31; also elsewhere on the board
LCD_R6: J1.30; also elsewhere on the board
LCD_R7: J1.29; also elsewhere on the board
LCD_VSYNC: J1.8; also elsewhere on the board
MIDI_IN: R13.1, U6.4; also elsewhere on the board
MIDI_OUT: R18.2; also elsewhere on the board
unnamed: C6.1, R7.1, U3.4 (I/O2)
unnamed: C7.1, R8.1, U3.6 (I/O1)
unnamed: D1.2 (A), J4.2 (TIP), U6.2
unnamed: D1.1 (K), R12.2, U6.1
unnamed: FB1.1, J3.A4 (VBUS), J3.A9 (VBUS), J3.B4 (VBUS), J3.B9 (VBUS)
unnamed: J3.A5 (CC1), R9.1
unnamed: J3.B5 (CC2), R10.1
unnamed: J3.A6 (D1+), J3.B6 (D2+), U3.3 (I/O2)
unnamed: J3.A7 (D1-), J3.B7 (D2-), U3.1 (I/O1)
unnamed: J4.3 (RING), R12.1
unnamed: J5.A5 (CC1), R19.1
unnamed: J5.B5 (CC2), R20.1
unnamed: J5.A6 (D1+), J5.B6 (D2+), U7.3 (I/O2)
unnamed: J5.A7 (D1-), J5.B7 (D2-), U7.1 (I/O1)
unnamed: J6.3 (RING), R17.1
unnamed: J6.2 (TIP), R18.1
unnamed: R15.1, U7.4 (I/O2)
unnamed: R16.1, U7.6 (I/O1)
unnamed: C8.1, U4.3 (VCCIO), U4.13 (3V3OUT), U4.14 (~RESET)
unnamed: R8.2, U4.12 (USBDM)
unnamed: R7.2, U4.11 (USBDP)
UART0_RXD: U4.20 (TXD); also elsewhere on the board
UART0_TXD: U4.4 (RXD); also elsewhere on the board
USBH_5V_ENABLE: R14.2, U5.3 (ENABLE); also elsewhere on the board
USB_D+: R15.2; also elsewhere on the board
USB_D-: R16.2; also elsewhere on the board
VBUS: C4.1, C5.1, FB1.2, U3.5 (VBUS), U4.15 (VCC); also elsewhere on the board
~USBH_5V_FAULT: R11.1, U5.4 (FAULT); also elsewhere on the board

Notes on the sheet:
USB TO UART
3.5MM TRS CONNECTOR
500mA CURRENT LIMIT
OPTO-ISOLATION
MIDI IN
USB-C CONNECTOR
USB HOST 5V
ESD PROTECTION
USB HOST
SHIELD NOT GROUNDED INTENTIONALLY
I2C CONNECTOR
RGB-LCD FPC CONNECTOR
MIDI OUT
Upstream Facing Port
QWIIC / STEMMA QT
(Consumes Power)
Downstream Facing Port
CHARGING + SERIAL
(Supplies 500mA @ 5V)

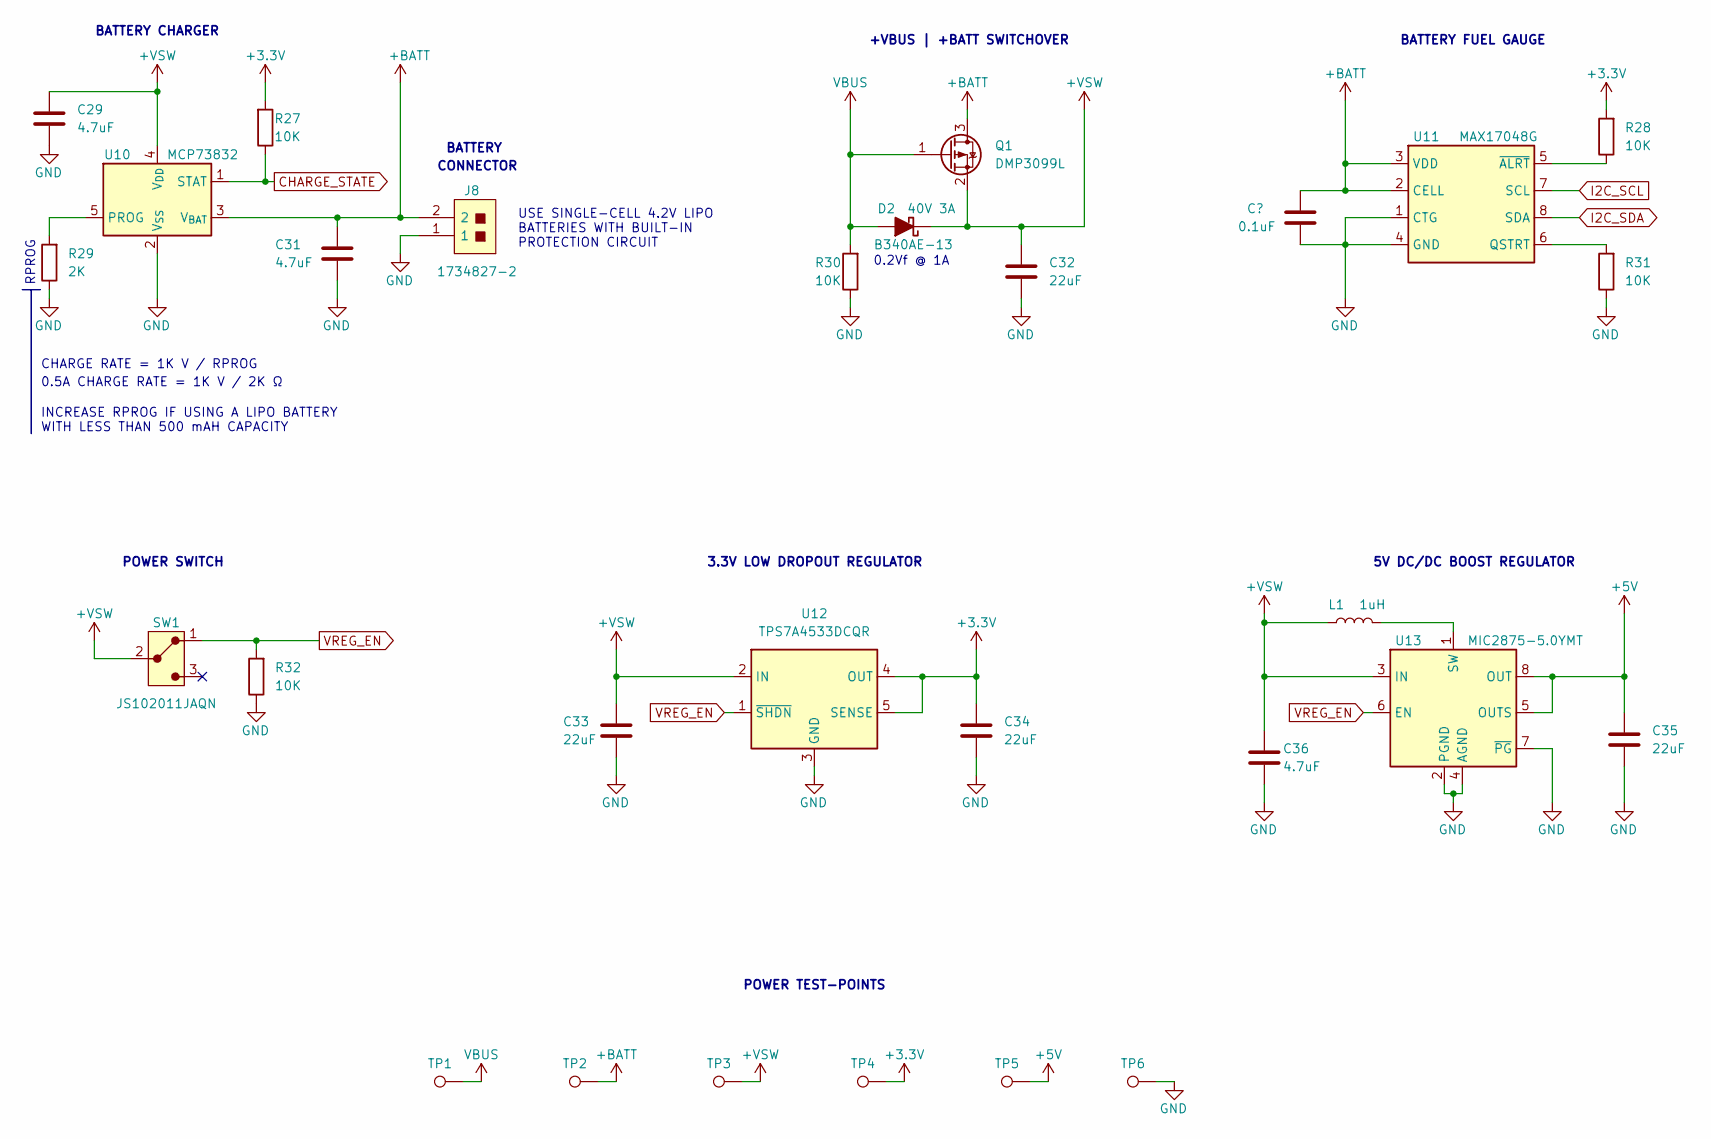
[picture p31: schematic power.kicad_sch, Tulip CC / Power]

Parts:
C29, C31, C36: 4.7uF; C_0805_2012; Part # C0805C475K3RACTU
C30: 0.1uF; C_0805_2012; Part # C0805C104K5RAC7411
C32, C33, C34, C35: 22uF; C_1210_3225; Rating 16V; Part # C1210C226M4RAC7210
D2: B340AE-13; D_SMA; Rating 40V 3A; Part # B340AE-13
J8: 1734827-2; TE_17348272; Part # 1734827-2
L1: 1uH; IND_VD_IFSC-1515AH-01; Rating 3.8A 25mR; Part # IFSC1515AHER1R0M01
Q1: DMP3099L; SOT-23-3; Part # DMP3099L-13
R27, R28, R30, R31, R32: 10K; R_0805_2012; Part # CR0805-FX-1002ELF
R29: 2K; R_0805_2012; Part # CR0805-FX-2001ELF
SW1: JS102011JAQN; CK_JS102011JAQN; Part # JS102011JAQN
TP1, TP2, TP3, TP4, TP5, TP6: PCB Test Point; TEST_POINT; Part # N/A
U10: MCP73832; SOT-23-5; Part # MCP73832T-2ACI/OT
U11: MAX17048G; TDFN-8-1EP_2x2mm_P0.5mm_EP0.8x1.2mm; Part # MAX17048G+T10
U12: TPS7A4533DCQR; SOT-223-6; Part # TPS7A4533DCQR
U13: MIC2875-5.0YMT; UDFN-8-1EP_2x2mm_P0.5mm_EP0.7x1.3mm_1; Part # MIC2875-5.0YMT

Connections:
+3.3V: C34.2, R27.2, R28.2, TP4.1, U12.4 (OUT), U12.5 (SENSE); also elsewhere on the board
+5V: C35.2, TP5.1, U13.5 (OUTS), U13.8 (OUT); also elsewhere on the board
+BATT: C30.1, C31.1, J8.2, Q1.3 (D), TP2.1, U10.3 (V_{BAT}), U11.2 (CELL), U11.3 (VDD)
+VSW: C29.1, C32.1, C33.2, C36.1, D2.1 (K), L1.1, Q1.2 (S), SW1.2, TP3.1, U10.4 (V_{DD}), U12.2 (IN), U13.3 (IN)
CHARGE_STATE: R27.1, U10.1 (STAT); also elsewhere on the board
GND: C29.2, C30.2, C31.2, C32.2, C33.1, C34.1, C35.1, C36.2, J8.1, R29.1, R30.1, R31.1, R32.1, TP6.1, U10.2 (V_{SS}), U11.1 (CTG), U11.4 (GND), U11.9 (GND), U12.3 (GND), U12.6 (GND), U13.2 (PGND), U13.4 (AGND), U13.7 (~PG), U13.9 (AGND); also elsewhere on the board
I2C_SCL: U11.7 (SCL); also elsewhere on the board
I2C_SDA: U11.8 (SDA); also elsewhere on the board
unnamed: R29.2, U10.5 (PROG)
unnamed: R31.2, U11.6 (QSTRT)
unnamed: R28.1, U11.5 (~ALRT)
unnamed: L1.2, U13.1 (SW)
VBUS: D2.2 (A), Q1.1 (G), R30.2, TP1.1; also elsewhere on the board
VREG_EN: R32.2, SW1.1, U12.1 (~SHDN), U13.6 (EN)

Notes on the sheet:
BATTERY
0.2Vf @ 1A
3.3V LOW DROPOUT REGULATOR
RPROG
BATTERY CHARGER
+VBUS | +BATT SWITCHOVER
POWER TEST-POINTS
BATTERY FUEL GAUGE
INCREASE RPROG IF USING A LIPO BATTERY WITH LESS THAN 500 mAH CAPACITY
USE SINGLE-CELL 4.2V LIPO BATTERIES WITH BUILT-IN PROTECTION CIRCUIT
POWER SWITCH
CONNECTOR
0.5A CHARGE RATE = 1K V / 2K Ω
5V DC/DC BOOST REGULATOR
CHARGE RATE = 1K V / RPROG

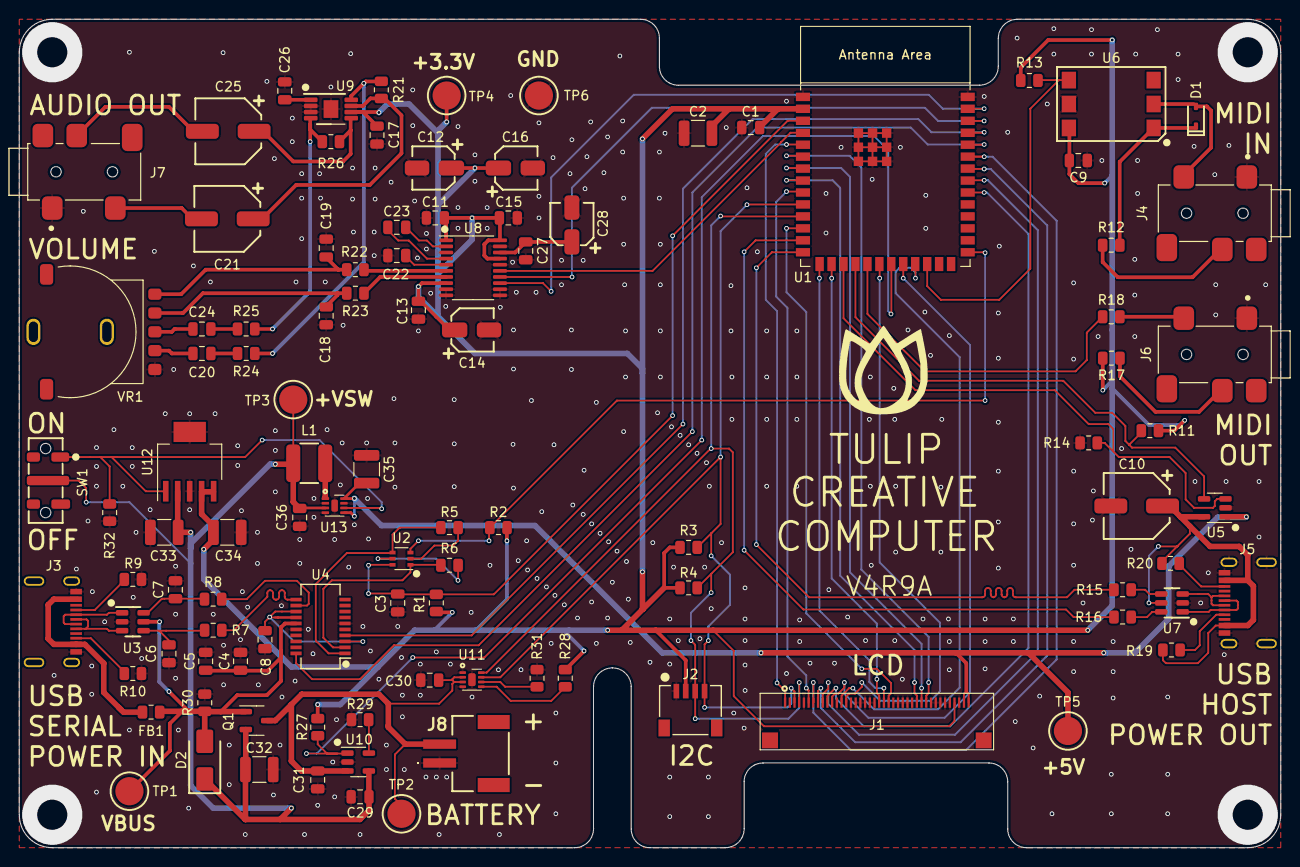
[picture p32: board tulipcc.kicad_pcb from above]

Board: 2 copper layers, 134.0 x 88.0 mm, 102 parts (0 on the bottom side), 87 nets.

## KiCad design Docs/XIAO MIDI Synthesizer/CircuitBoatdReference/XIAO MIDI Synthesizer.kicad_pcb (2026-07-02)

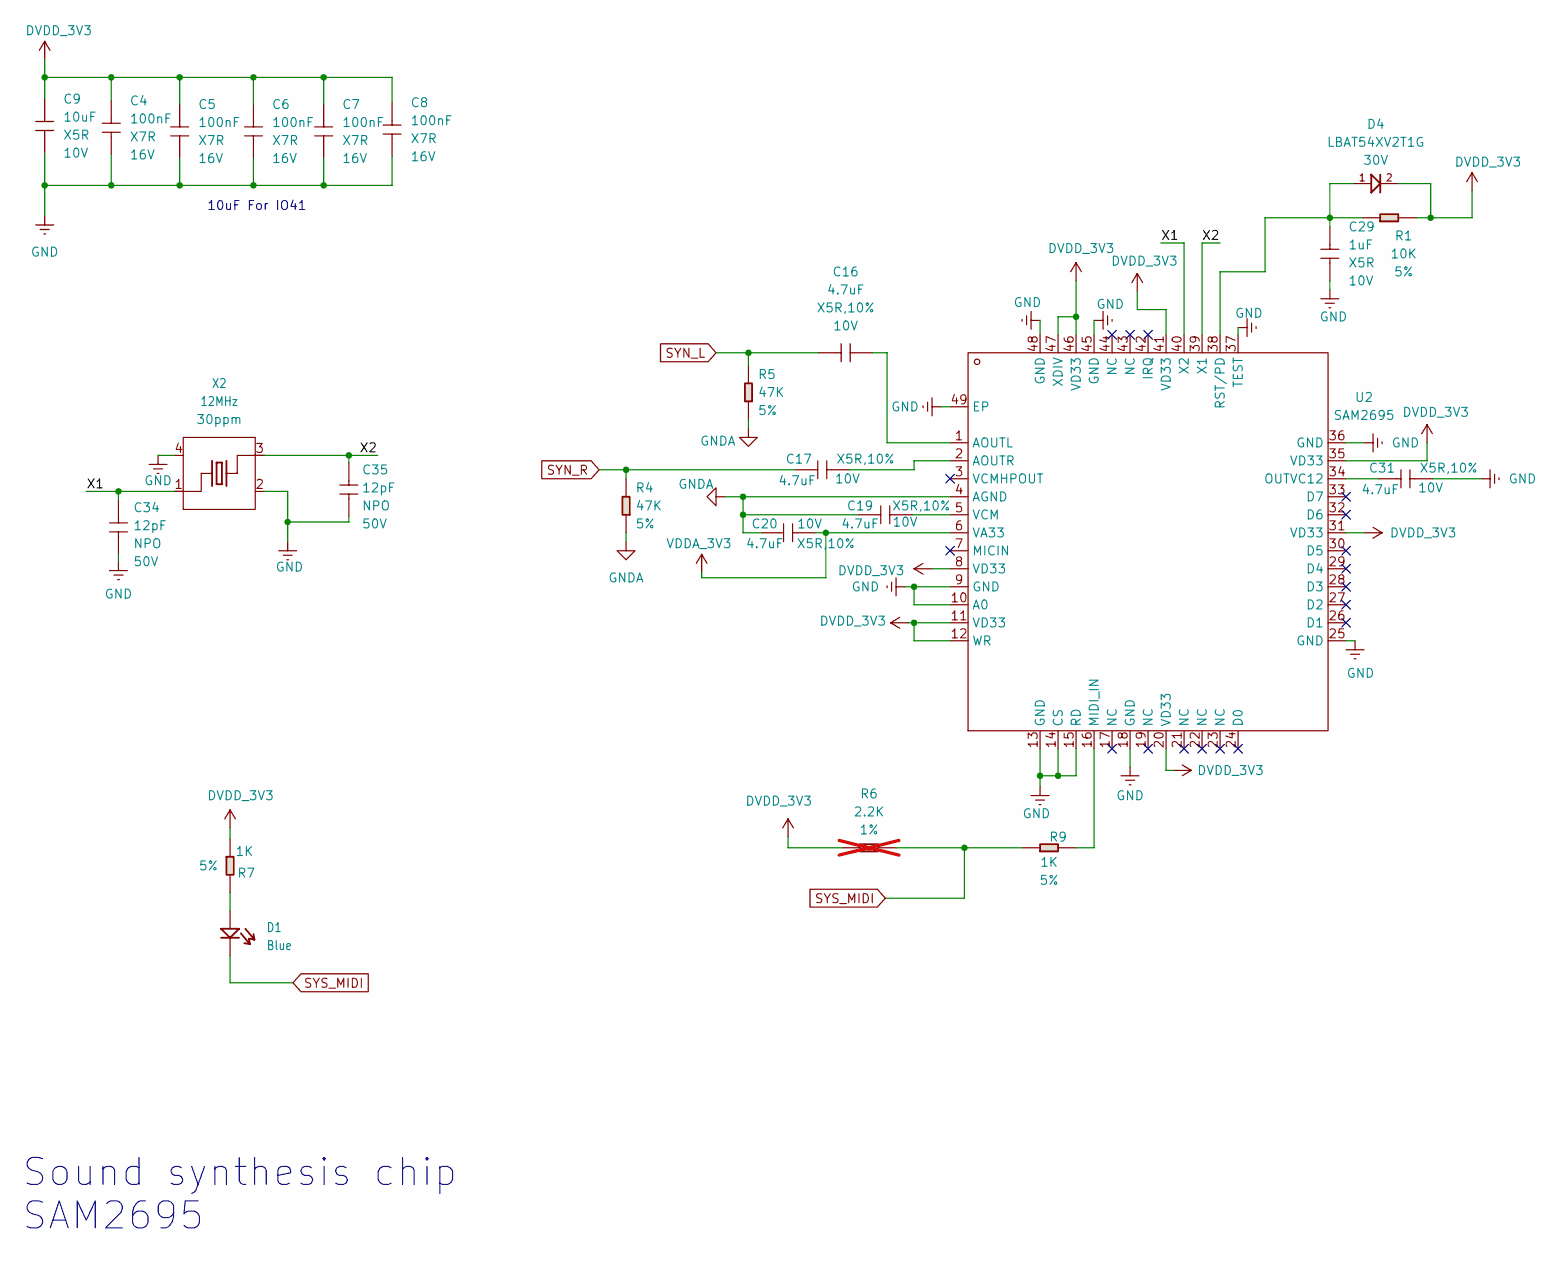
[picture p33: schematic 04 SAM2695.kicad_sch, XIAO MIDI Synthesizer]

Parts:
C4, C5, C6, C7, C8: 100nF; C0402; Voltage Rating 16V; MPN CC0402KRX7R7BB104
C9: 10uF; C0402; Voltage Rating 10V; MPN CC0402MRX5R6BB106
C16, C17, C19, C20, C31: 4.7uF; C0402; Voltage Rating 10V; MPN CC0402KRX5R6BB475
C29: 1uF; C0402; Voltage Rating 10V; MPN CC0402KRX5R6BB105
C34, C35: 12pF; C0402; Voltage Rating 50V; MPN CC0402JRNPO9BN120
D1: Blue; LED-0603; MPN 19-217/BHC-ZL1M2RY/3T
D4: LBAT54XV2T1G; SOD-523; Rating 30V; MPN LBAT54XV2T1G
R1: 10K; R0402; Power Rating 5%; MPN RC0402JR-0710KL
R4, R5: 47K; R0402; Power Rating 5%; MPN RC0402JR-0747KL
R6: 2.2K; R0402; Power Rating 1%; MPN RC0402FR-072K2L; not fitted
R7, R9: 1K; R0402; Power Rating 5%; MPN RC0402JR-071KL
U2: SAM2695; QFN48-0.4-6X6MM; MPN SAM2695
X2: 12MHz; X4-SMD-2.5X2.0MM; Rating 30ppm; MPN FA-20H 12MHz

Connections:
/04 SAM2695/X1: C34.1, U2.40 (X2), X2.1
/04 SAM2695/X2: C35.2, U2.39 (X1), X2.3
DVDD_3V3: C4.1, C5.1, C6.1, C7.1, C8.1, C9.1, D4.2, R1.2, R6.1, R7.1, U2.8 (VD33), U2.11 (VD33), U2.12 (WR), U2.20 (VD33), U2.31 (VD33), U2.35 (VD33), U2.41 (VD33), U2.46 (VD33), U2.47 (XDIV); also elsewhere on the board
GND: C4.2, C5.2, C6.2, C7.2, C8.2, C9.2, C29.1, C31.2, C34.2, C35.1, U2.9 (GND), U2.10 (A0), U2.13 (GND), U2.14 (CS), U2.15 (RD), U2.18 (GND), U2.25 (GND), U2.36 (GND), U2.37 (TEST), U2.45 (GND), U2.48 (GND), U2.49 (EP), X2.2, X2.4; also elsewhere on the board
GNDA: C19.1, C20.1, R4.1, R5.1, U2.4 (AGND); also elsewhere on the board
unnamed: D1.1 (+), R7.2
unnamed: C16.2, U2.1 (AOUTL)
unnamed: C17.2, U2.2 (AOUTR)
unnamed: R9.2, U2.16 (MIDI_IN)
unnamed: C31.1, U2.34 (OUTVC12)
unnamed: C29.2, D4.1, R1.1, U2.38 (RST/PD)
unnamed: C19.2, U2.5 (VCM)
SYN_L: C16.1, R5.2; also elsewhere on the board
SYN_R: C17.1, R4.2; also elsewhere on the board
SYS_MIDI: D1.2 (-), R6.2, R9.1; also elsewhere on the board
VDDA_3V3: C20.2, U2.6 (VA33); also elsewhere on the board

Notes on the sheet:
Sound synthesis chip SAM2695
10uF For IO41

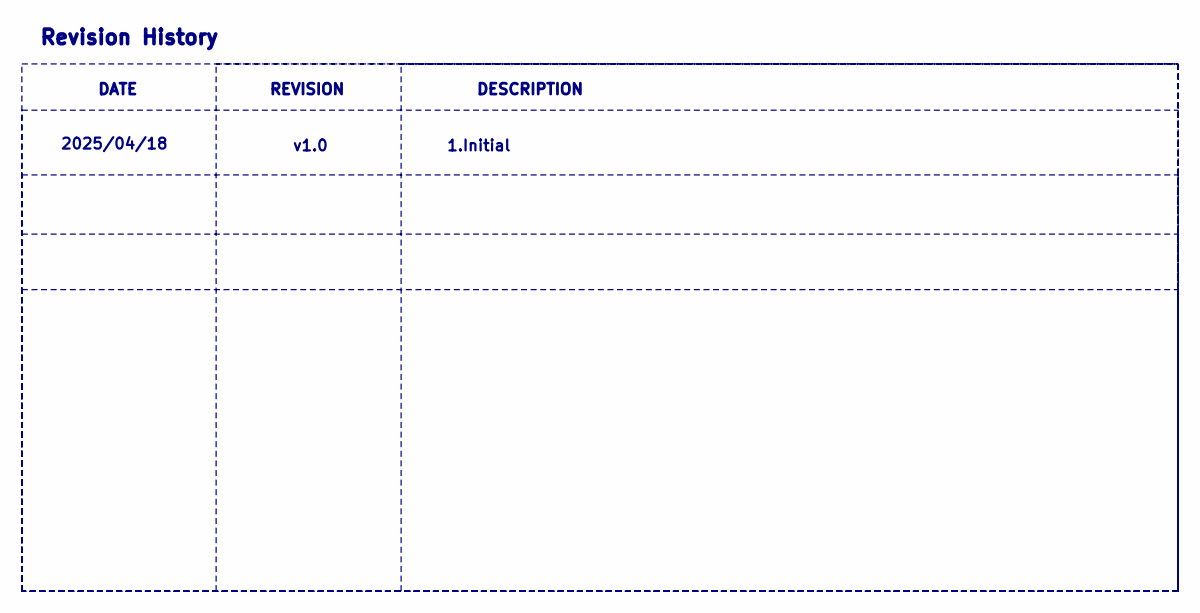
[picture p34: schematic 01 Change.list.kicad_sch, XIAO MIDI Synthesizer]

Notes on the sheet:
v1.0
DATE REVISION DESCRIPTION
1.Initial
Revision History
2025/04/18

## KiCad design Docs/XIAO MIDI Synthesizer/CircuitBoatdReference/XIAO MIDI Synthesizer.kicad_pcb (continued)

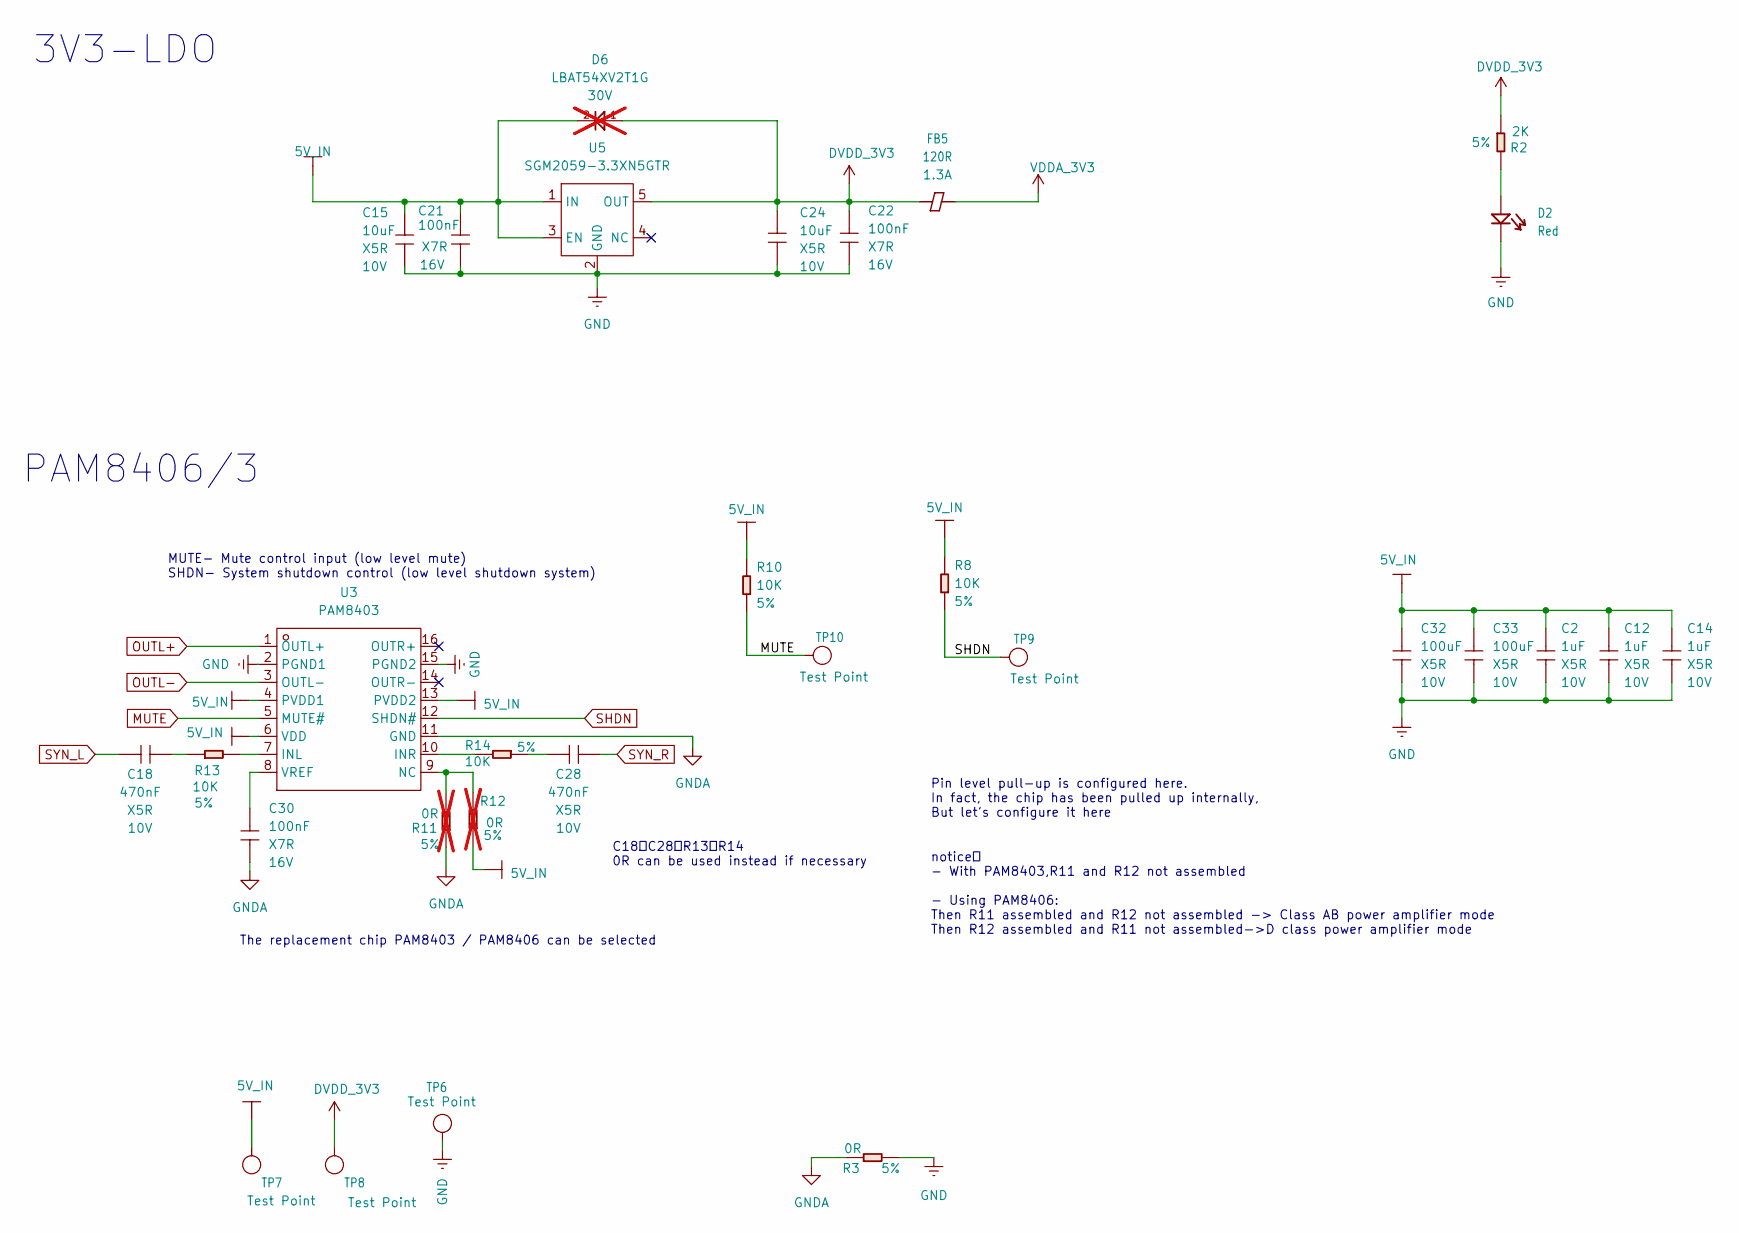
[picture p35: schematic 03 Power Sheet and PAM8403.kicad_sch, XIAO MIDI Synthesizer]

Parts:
C2, C12, C14: 1uF; C0402; Voltage Rating 10V; MPN CC0402KRX5R6BB105
C15, C24: 10uF; C0402; Voltage Rating 10V; MPN CC0402MRX5R6BB106
C18, C28: 470nF; C0402; Voltage Rating 10V; MPN CC0402KRX5R6BB474
C21, C22, C30: 100nF; C0402; Voltage Rating 16V; MPN CC0402KRX7R7BB104
C32, C33: 100uF; C1206; Voltage Rating 10V; MPN GRM31CR61A107ME05L
D2: Red; LED-0603; MPN EL-19-217/R6C-AL1M2VY/3T
D6: LBAT54XV2T1G; SOD-523; Rating 30V; MPN LBAT54XV2T1G; not fitted
FB5: 120R; L0402; Rating 1.3A; MPN BLM15PD121SN1D
R2: 2K; R0402; Power Rating 5%; MPN RC0402JR-072KL
R3: 0R; R0402; Power Rating 5%; MPN RC0402JR-070RL
R8, R10, R13, R14: 10K; R0402; Power Rating 5%; MPN RC0402JR-0710KL
R11, R12: 0R; R0402; Power Rating 5%; MPN RC0402JR-070RL; not fitted
TP6, TP7, TP8, TP9, TP10: Test Point; TP-1.6MM-ROUND; Part Type Test Point
U3: PAM8403; SOP16-1.27-10X4MM; MPN PAM8403
U5: SGM2059-3.3XN5GTR; SOT-23-5; MPN SGM2059-3.3XN5GTR

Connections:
5V_IN: C2.1, C12.1, C14.1, C15.1, C21.1, C32.1, C33.1, D6.2, R8.2, R10.2, R12.1, TP7.1 (T), U3.4 (PVDD1), U3.6 (VDD), U3.13 (PVDD2), U5.1 (IN), U5.3 (EN); also elsewhere on the board
DVDD_3V3: C22.1, C24.1, D6.1, FB5.1, R2.1, TP8.1 (T), U5.5 (OUT); also elsewhere on the board
GND: C2.2, C12.2, C14.2, C15.2, C21.2, C22.2, C24.2, C32.2, C33.2, D2.2 (-), R3.2, TP6.1 (T), U3.2 (PGND1), U3.15 (PGND2), U5.2 (GND); also elsewhere on the board
GNDA: C30.2, R3.1, R11.1, U3.11 (GND); also elsewhere on the board
MUTE: R10.1, TP10.1 (T), U3.5 (MUTE#)
unnamed: C18.2, R13.1
unnamed: C28.1, R14.1
unnamed: D2.1 (+), R2.2
unnamed: R13.2, U3.7 (INL)
unnamed: R14.2, U3.10 (INR)
unnamed: R11.2, R12.2, U3.9 (NC)
unnamed: C30.1, U3.8 (VREF)
OUTL+: U3.1 (OUTL+); also elsewhere on the board
OUTL-: U3.3 (OUTL-); also elsewhere on the board
SHDN: R8.1, TP9.1 (T), U3.12 (SHDN#); also elsewhere on the board
SYN_L: C18.1; also elsewhere on the board
SYN_R: C28.2; also elsewhere on the board
VDDA_3V3: FB5.2; also elsewhere on the board

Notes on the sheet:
PAM8406/3
MUTE- Mute control input (low level mute) SHDN- System shutdown control (low level shutdown system)
C18，C28，R13，R14 0R can be used instead if necessary
3V3-LDO
The replacement chip PAM8403 / PAM8406 can be selected
Pin level pull-up is configured here. In fact, the chip has been pulled up internally, But let's configure it here
notice： - With PAM8403,R11 and R12 not assembled - Using PAM8406: Then R11 assembled and R12 not assembled -> Class AB power amplifier mode Then R12 assembled and R11 not assembled->D class power amplifier mode

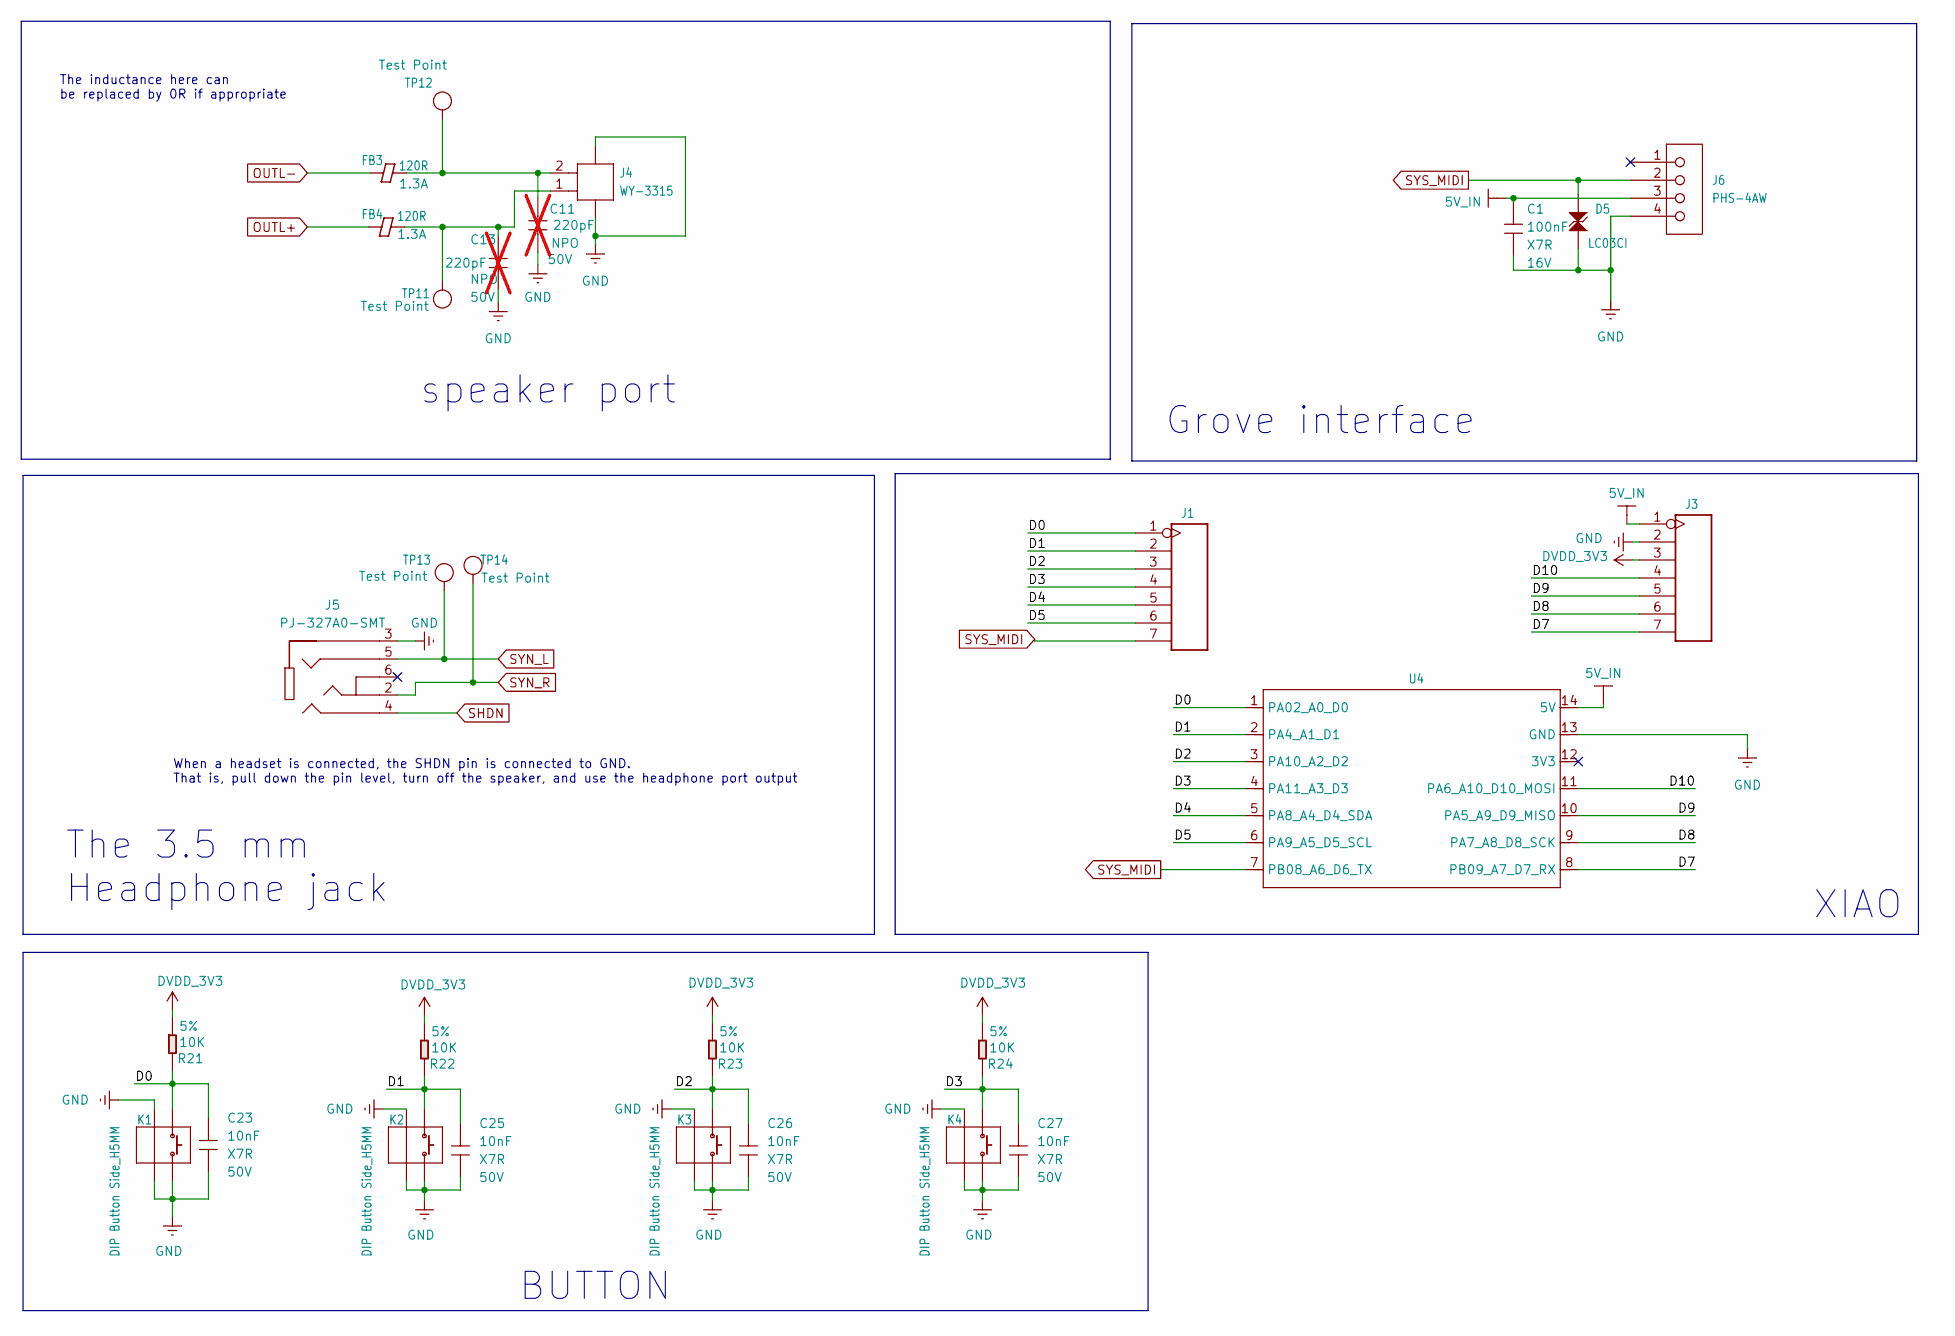
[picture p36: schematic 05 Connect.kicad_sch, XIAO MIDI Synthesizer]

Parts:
C1: 100nF; C0402; Voltage Rating 16V; MPN CC0402KRX7R7BB104
C11, C13: 220pF; C0402; Voltage Rating 50V; MPN CC0402JRNPO9BN221; not fitted
C23, C25, C26, C27: 10nF; C0402; Voltage Rating 50V; MPN CC0402KRX7R9BB103
D5: LC03CI; SOD-323; MPN LC03CI
FB3, FB4: 120R; L0402; Rating 1.3A; MPN BLM15PD121SN1D
J1, J3: ST-PH-254-0087-1*7P-PC1.8; H7-2.54; MPN ST-PH-254-0087-1*7P-PC1.8
J4: WY-3315; JST2P_1d25_7_55x4_25x4_8mm; MPN WY-3315
J5: PJ-327A0-SMT; AUDIO5P-3.6-14X6.1X4.5MM; MPN PJ-327A0-SMT
J6: PHS-4AW; HW4-2.0-90D; MPN PHS-4AW
K1, K2, K3, K4: DIP Button Side_H5MM; SW4-DIP-7.5X6.6X7MM; MPN TC-00100A
R21, R22, R23, R24: 10K; R0402; Power Rating 5%; MPN RC0402JR-0710KL
TP11, TP12, TP13, TP14: Test Point; TP-1.6MM-ROUND; Part Type Test Point
U4: MOUDLE14P-XIAO-HALF-HOLE

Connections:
5V_IN: C1.2, J3.1, J6.3, U4.14 (5V); also elsewhere on the board
/05 Connect/D0: C23.1, J1.1, K1.1, R21.2, U4.1 (PA02_A0_D0)
/05 Connect/D1: C25.1, J1.2, K2.1, R22.2, U4.2 (PA4_A1_D1)
/05 Connect/D2: C26.1, J1.3, K3.1, R23.2, U4.3 (PA10_A2_D2)
/05 Connect/D3: C27.1, J1.4, K4.1, R24.2, U4.4 (PA11_A3_D3)
/05 Connect/D4: J1.5, U4.5 (PA8_A4_D4_SDA)
/05 Connect/D5: J1.6, U4.6 (PA9_A5_D5_SCL)
/05 Connect/D7: J3.7, U4.8 (PB09_A7_D7_RX)
/05 Connect/D8: J3.6, U4.9 (PA7_A8_D8_SCK)
/05 Connect/D9: J3.5, U4.10 (PA5_A9_D9_MISO)
/05 Connect/D10: J3.4, U4.11 (PA6_A10_D10_MOSI)
DVDD_3V3: J3.3, R21.1, R22.1, R23.1, R24.1; also elsewhere on the board
GND: C1.1, C11.2, C13.2, C23.2, C25.2, C26.2, C27.2, D5.1, J3.2, J4.3, J4.4, J5.3, J6.4, K1.2, K1.3 (S1), K1.4 (S2), K2.2, K2.3 (S1), K2.4 (S2), K3.2, K3.3 (S1), K3.4 (S2), K4.2, K4.3 (S1), K4.4 (S2), U4.13 (GND); also elsewhere on the board
unnamed: C13.1, FB4.2, J4.1, TP11.1 (T)
unnamed: C11.1, FB3.2, J4.2, TP12.1 (T)
OUTL+: FB4.1; also elsewhere on the board
OUTL-: FB3.1; also elsewhere on the board
SHDN: J5.4; also elsewhere on the board
SYN_L: J5.5, TP13.1 (T); also elsewhere on the board
SYN_R: J5.2, TP14.1 (T); also elsewhere on the board
SYS_MIDI: D5.2, J1.7, J6.2, U4.7 (PB08_A6_D6_TX); also elsewhere on the board

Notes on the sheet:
When a headset is connected, the SHDN pin is connected to GND. That is, pull down the pin level, turn off the speaker, and use the headphone port output
The 3.5 mm Headphone jack
XIAO
speaker port
BUTTON
The inductance here can be replaced by 0R if appropriate
Grove interface

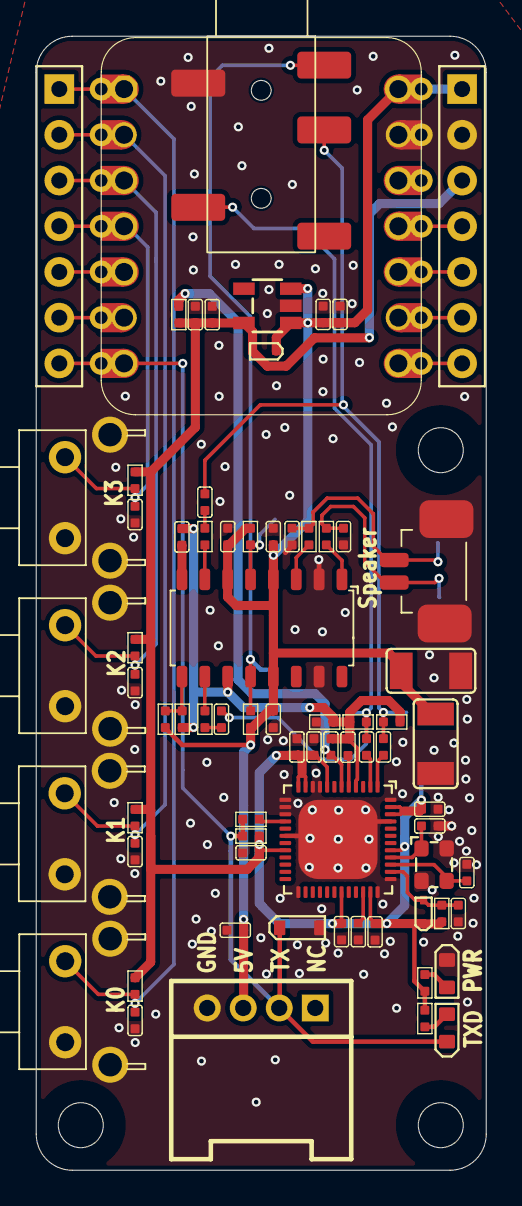
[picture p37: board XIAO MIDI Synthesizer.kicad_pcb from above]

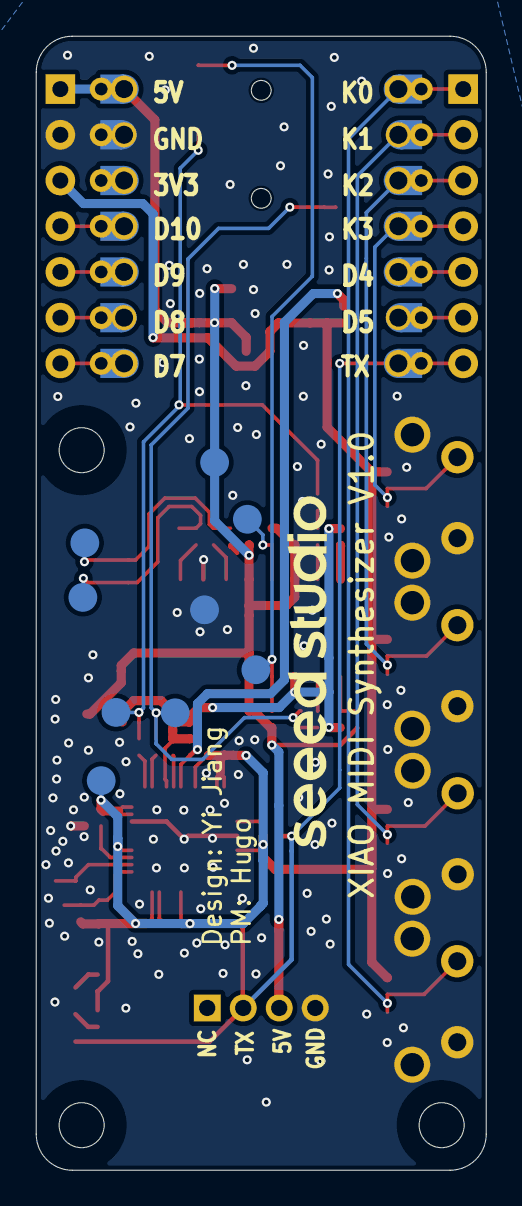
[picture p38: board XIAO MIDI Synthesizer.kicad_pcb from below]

Board: 2 copper layers, 25.0 x 63.0 mm, 82 parts (9 on the bottom side), 40 nets.

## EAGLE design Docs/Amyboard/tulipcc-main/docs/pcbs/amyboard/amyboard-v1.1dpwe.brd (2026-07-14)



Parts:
1-10VPP: 218-4LPSTR; SW_218-4LPSTR
BOOT: TS24CA; 2*4*3.5MM
C1, C4, C5, C7, C11, C13, C15, C20, C23, C24, C25, C26, C33, C35, C36, C37, C40, C41, C46, C47, C52: 100nF; DISCRETE_C0402
C2, C3, C8, C12, C14, C16, C22, C42, C43, C44, C45: 10uF/10V/TAN; SMC_Z
C6: 68nF; DISCRETE_C0402
C9, C10: 1nF; DISCRETE_C0402
C17: 4.7nF; DISCRETE_C0402
C21, C32, C53, C54, C55: 1uF; DISCRETE_C0402
C27: 22uF; C0603
C28: 10uF; DISCRETE_C0402
C29: 22pF; C0603
C30: 1uF; C0603
C31, C56: 10uF; C0603
C34, C38, C39, C85: 10uF; DISCRETE_C0603
C48, C49: 2.2uF; DISCRETE_C0402
C50, C51: 2.2nF; DISCRETE_C0402
C106: 4.7uF/16V; 0603
C107: 10uF; 0603
CV_IN1, CV_IN2: NV-PJ3410_STEREO; NV-PJ3410_SOCKET
CV_OUT1, CV_OUT2: NV-PJ3410_STEREO; NV-PJ3410_SOCKET
D1, D2, D3, D4, D5, D8, D9, D10, D14: SS34; DO-214AC
D12: SMF05C; SOT363
D13: 1N4148WS; SOD323
FB3: 100Mhz@120R; R0805
HOST: 2X6 FEMALE; 2X6
I2C_CONTROL, I2C_HOST: HW4-SMD-2.0; HW4-SMD-2.0-90D
L3: 3.3µH/±30%/3.4A; CR54
LDK320AM120R: TS5205; SOT25
LINE_IN: NV-PJ3410_STEREO; NV-PJ3410_SOCKET
LINE_OUT: NV-PJ3410_STEREO; NV-PJ3410_SOCKET
ME6214C33, ME6214C50: SPX3819; SOT23-5
MIDI_IN: NV-PJ3410_STEREO; NV-PJ3410_SOCKET
MIDI_OUT: NV-PJ3410_STEREO; NV-PJ3410_SOCKET
MODULAR_PSU: 52601-G10-8LF; AMPHENOL_52601-G10-8LF
PCM5101: U11; PW20_TEX
Q2, Q5: S8050; SOT23
Q3: AO3407; SOT23-3
R1, R2, R52, R53: 5.1K; DISCRETE_R0402
R3: 150R; DISCRETE_R0402
R4: 680R; DISCRETE_R0402
R5, R7: 39.7K; DISCRETE_R0402
R6, R20: 13.1K; DISCRETE_R0402
R8, R9, R12, R13, R14, R21, R31, R32, R33, R39, R40, R41, R42, R43, R47, R48, R49: 10K; DISCRETE_R0402
R10, R27: 30K; DISCRETE_R0402
R11, R19: 100K; DISCRETE_R0402
R15, R17, R37: 10R; DISCRETE_R0402
R16: 0R; DISCRETE_R0402
R18: 4.65K; DISCRETE_R0402
R22, R28: 51K; DISCRETE_R0402
R23: 1K; DISCRETE_R0402
R24: 2R; DISCRETE_R0402
R25, R26: 2.2K; DISCRETE_R0402
R29, R30: 22K; DISCRETE_R0402
R35, R50, R51: 470R; DISCRETE_R0402
R36: 220R; DISCRETE_R0402
R38: 33R; DISCRETE_R0402
R44: NC; DISCRETE_R0402
R45, R46: 51R; DISCRETE_R0402
R80: 0R; DISCRETE_R0603
RST: TS24CA; 2*4*3.5MM
SD1: SD; 9P-SMD-W/-RING
SPDIF_IN: NV-PJ3410_STEREO; NV-PJ3410_SOCKET
SPDIF_OUT: NV-PJ3410_STEREO; NV-PJ3410_SOCKET
TXC7W-22.5792MBE: SM77H
U1: PCM9211PT; QFP50P900X900X160-48N
U2: ESP32­S2­SOLO; ESP32-­S2-­SOLO
U4: TL074CD; SOIC127P600X175-14N
U5: ADS1015IDGSR; SOP50P490X110-10N
U6: HX3608; SOT-23-6
U7: GP8413; SOIC-10
U15: H11L1SR2M; SOP-6-2.54MM
U16: SPX3819; SOT23-5
USB: USB-C; USB-C-16P-5
XC6901DC01MR-G: TS5205; SOT25

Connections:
3V3_IN: D2.A, I2C_CONTROL.3, Q3.2 (S)
5V_IN: C34.2, C52.2, C85.2, D3.A, D14.A, FB3.2
12V5_UNREG: C28.2, LDK320AM120R.1 (VIN), LDK320AM120R.3 (CE), ME6214C33.1 (VIN), ME6214C33.3 (EN), ME6214C50.1 (VIN), ME6214C50.3 (EN), R15.2
12_IN: D1.A, D4.A, MODULAR_PSU.09, MODULAR_PSU.10
13.5V: C20.2, C26.2, C27.1, C29.1, D8.C, R15.1, R16.1, R19.1, U7.5 (VCC)
+3V3: C3.+, C5.1, C11.1, C12.+, C14.+, C15.1, C33.2, C35.1, C37.2, C38.1, C39.2, C40.1, C45.+, C46.1, C107.1, D12.4 (C3), HOST.2, HOST.5, I2C_HOST.3, PCM5101.1 (CPVDD), PCM5101.17 (XSMT), PCM5101.20 (DVDD), Q3.3 (D), R23.1, R35.1, R38.2, R39.2, R40.2, R41.2, R42.2, R43.2, R44.2, R47.2, R49.2, SD1.4 (VDD), TXC7W-22.5792MBE.1 (E/D), TXC7W-22.5792MBE.4 (VCC), U1.22 (DVDD), U1.34 (RST), U1.36 (VDDRX), U1.42 (VCC), U2.2 (3V3), U15.6 (VCC), U16.5 (VOUT)
-12.6V: C25.1, R17.2
A3V3: C22.+, C47.1, C55.2, ME6214C33.5 (VOUT), PCM5101.8 (AVDD), R6.2, R12.2, R13.2, R20.2, R31.1, U5.8 (VDD)
A5V: C13.1, C16.+, C54.2, HOST.12, ME6214C50.5 (VOUT), U1.46 (VCCAD)
A12V: C21.2, LDK320AM120R.5 (VOUT), U4.4 (VCC+)
A-12V: C53.2, U4.11 (VCC-), XC6901DC01MR-G.5 (VOUT)
ADC1: C10.1, R5.1, R6.1, R8.2, U5.4 (AIN0)
ADC2: C9.1, R7.1, R20.1, R21.2, U5.5 (AIN1)
AGND: C7.2, C8.-, C11.2, C12.-, C13.2, C16.-, C22.-, C45.-, C46.2, C47.2, C48.1, C50.1, C51.1, LINE_IN.GND (EARTH), LINE_OUT.GND (EARTH), PCM5101.3 (CPGND), PCM5101.9 (AGND), R25.1, R26.1, R29.1, R30.1, R80.1, U1.41 (AGND), U1.45 (AGNDAD), U5.6 (AIN2), U5.7 (AIN3)
AMYIN: U1.17 (DOUT), U2.17 (IO9)
AMYOUT: PCM5101.14 (DIN), R33.2, U1.10 (MPIO_C3), U2.6 (IO6)
AMY_FOLLOWER_SCL: I2C_CONTROL.1, U2.5 (IO5)
AMY_FOLLOWER_SDA: I2C_CONTROL.2, U2.4 (IO4)
BCLK: PCM5101.13 (BCK), U1.8 (MPIO_C1), U1.19 (BCK), U2.12 (IO8)
CV_OUT1: CV_OUT1.LEFT/TIP (TIP), R27.1, U4.1 (OUT1)
CV_OUT2: CV_OUT2.LEFT/TIP (TIP), R10.1, U4.7 (OUT2)
DTR: HOST.11, Q5.2 (E), R48.2
ENABLE: R14.2, U6.4 (EN)
GND: BOOT.1, BOOT.3, BOOT.4, C2.-, C3.-, C5.2, C9.2, C10.2, C14.-, C15.2, C17.1, C20.1, C21.1, C23.1, C24.1, C25.2, C26.1, C27.2, C28.1, C31.1, C32.2, C33.1, C34.1, C35.2, C36.1, C37.1, C38.2, C39.1, C40.2, C41.1, C42.-, C52.1, C53.1, C54.1, C55.1, C56.2, C85.1, C106.2, C107.2, CV_IN1.GND (EARTH), CV_IN2.GND (EARTH), CV_OUT1.GND (EARTH), CV_OUT2.GND (EARTH), D9.C, D12.2 (A), HOST.1, I2C_CONTROL.4, I2C_CONTROL.SS1, I2C_CONTROL.SS2, I2C_HOST.4, I2C_HOST.SS1, I2C_HOST.SS2, LDK320AM120R.2 (GND), ME6214C33.2 (GND), ME6214C50.2 (GND), MIDI_IN.GND (EARTH), MIDI_OUT.GND (EARTH), MODULAR_PSU.03, MODULAR_PSU.04, MODULAR_PSU.05, MODULAR_PSU.06, MODULAR_PSU.07, MODULAR_PSU.08, PCM5101.10 (DEMP), PCM5101.11 (FLT), PCM5101.12 (SCK), PCM5101.16 (FMT), PCM5101.19 (DGND), R4.2, R8.1, R11.1, R18.2, R21.1, R32.1, R33.1, R52.2, R53.2, R80.2, RST.1, RST.3, RST.4, SD1.6 (VSS), SD1.G1, SD1.G2, SD1.G3, SD1.G4, SPDIF_IN.GND (EARTH), SPDIF_OUT.GND (EARTH), TXC7W-22.5792MBE.2 (GND), U1.21 (DGND), U1.23 (MDO/ADRO), U1.26 (MS/ADR1), U1.27 (MODE), U1.38 (GNDRX), U2.1 (GND), U2.40 (GND), U2.41 (EPAD), U5.3 (GND), U6.2 (GND), U7.3 (A0), U7.4 (A1), U7.6 (GND), U7.9 (A2), U15.5 (GND), U16.2 (GND), USB.GND, USB.GND2 (GND), XC6901DC01MR-G.1 (VIN)
I2C_SCL: I2C_HOST.1, U1.25 (MC/SCL), U2.11 (IO18), U5.10 (SCL), U7.1 (SCLK)
I2C_SDA: I2C_HOST.2, U1.24 (MDL/SDA), U2.10 (IO17), U5.9 (SDA), U7.2 (SDA)
IO0: BOOT.2, Q5.3 (C), R49.1, U2.27 (IO0)
IO19: R45.2, U2.13 (IO19)
IO20: R46.2, U2.14 (IO20)
LIN: LINE_IN.LEFT/TIP (TIP), R2.2
LINX: C43.+, U1.47 (VINL)
LOUT: LINE_OUT.LEFT/TIP (TIP), R22.1, U4.8 (OUT3)
LOUT_2V: C50.2, R51.1, U4.10 (POS_3)
LRC: PCM5101.15 (LRCK), U1.9 (MPIO_C2), U1.18 (LRCK), U2.38 (IO2)
MCLK: U1.7 (MPIO_CO), U1.20 (SCKO), U2.15 (IO3)
MIDI_IN: R35.2, U2.23 (IO21), U15.4 (VO)
MIDI_OUT: R37.2, U2.22 (IO14)
unnamed: C1.1, U1.37 (RXINO)
unnamed: C4.2, R3.1
unnamed: C4.1, U1.15 (MPOO)
unnamed: 1-10VPP.1, C43.-, R2.1
unnamed: 1-10VPP.2, C44.-, R1.1
unnamed: C7.1, C8.+, U1.44 (VCOM)
unnamed: C6.2, C17.2, U1.43 (FLLT)
unnamed: C6.1, R4.1
unnamed: CV_IN2.LEFT/TIP (TIP), R7.2
unnamed: C32.1, R17.1, XC6901DC01MR-G.2 (GND)
unnamed: C31.2, D10.A
unnamed: C23.2, U4.3 (POS_1), U7.8 (VOUT0)
unnamed: CV_IN1.LEFT/TIP (TIP), R5.2
unnamed: C24.2, U4.5 (POS_2), U7.7 (VOUT1)
unnamed: D8.A, L3.P$2 (2), R24.2, U6.1 (SW)
unnamed: C42.+, U7.10 (V5V)
unnamed: D3.C, D4.C, D5.A, Q3.1 (G), R11.2
unnamed: C106.1, D5.C, U16.1 (VIN), U16.3 (EN)
unnamed: C29.2, R18.1, R19.2, U6.3 (FB)
unnamed: C30.1, R24.1
unnamed: R16.2, U6.5 (VIN)
unnamed: C30.2, D9.A, D10.C
unnamed: R23.2, XC6901DC01MR-G.3 (CE)
unnamed: R10.2, R13.1, U4.6 (NEG_2)
unnamed: R12.1, R27.2, U4.2 (NEG_1)
unnamed: Q2.1 (B), R48.1
unnamed: 1-10VPP.5, R30.2
unnamed: 1-10VPP.6, R29.2
unnamed: Q5.1 (B), R9.1
unnamed: R53.1, USB.A5 (CC1)
unnamed: R52.1, USB.B5 (CC2)
unnamed: 1-10VPP.8, R25.2
unnamed: 1-10VPP.7, R26.2
unnamed: FB3.1, USB.VBUS1 (VBUS), USB.VBUS2 (VBUS)
unnamed: R31.2, U5.2 (ALERT/RDY)
unnamed: 1-10VPP.3, R22.2, U4.9 (NEG3)
unnamed: 1-10VPP.4, R28.2, U4.13 (NEG_4)
unnamed: R32.2, U5.1 (ADDR)
unnamed: C2.+, C41.2, PCM5101.18 (LDOO)
unnamed: PCM5101.7 (OUTR), R50.2
unnamed: C49.2, PCM5101.4 (CAPM)
unnamed: C49.1, PCM5101.2 (CAPP)
unnamed: D13.+, MIDI_IN.LEFT/TIP (TIP), U15.2 (CAT)
unnamed: MIDI_IN.RIGHT/RING (RING), R36.1
unnamed: D13.-, R36.2, U15.1 (AN)
unnamed: MIDI_OUT.LEFT/TIP (TIP), R37.1
unnamed: MIDI_OUT.RIGHT/RING (RING), R38.1
unnamed: R39.1, SD1.1 (DATA2)
unnamed: R43.1, SD1.8 (DATA1)
OUTL: PCM5101.6 (OUTL), R51.2
RESET: C36.2, Q2.3 (C), R47.1, RST.2, U2.3 (EN)
RIN: LINE_IN.RIGHT/RING (RING), R1.2
RINX: C44.+, U1.48 (VINR)
ROUT: LINE_OUT.RIGHT/RING (RING), R28.1, U4.14 (OUT4)
ROUT_2V: C51.2, R50.1, U4.12 (POS_4)
RTS: HOST.3, Q2.2 (E), R9.2
RXD/IO44: HOST.7, U2.36 (RXD0)
SPDIFIN_SIGNAL: C1.2, SPDIF_IN.LEFT/TIP (TIP)
SPDIFOUT_SIGNAL: R3.2, SPDIF_OUT.LEFT/TIP (TIP)
SPI0_CS0: D12.1 (C1), HOST.4, R40.1, SD1.2 (CS), U2.18 (IO10)
SPI0_MISO: D12.6 (C5), HOST.8, R42.1, SD1.7 (DO), U2.21 (IO13)
SPI0_MOSI: D12.3 (C2), HOST.6, R41.1, SD1.3 (DI), U2.19 (IO11)
SPI0_SCK: D12.5 (C4), HOST.10, R44.1, SD1.5 (SCLK), U2.20 (IO12)
TXD/IO43: HOST.9, U2.37 (TXD0)
USB_D+: R46.1, USB.A6 (D+), USB.B6 (D+)
USB_D-: R45.1, USB.A7 (D-), USB.B7 (D-)
VNEG: C48.2, PCM5101.5 (VNEG)
VPWR: C56.1, D1.C, D2.C, D14.C, L3.P$1 (1), R14.1
XTI: TXC7W-22.5792MBE.3 (OUT), U1.39 (XTI)
XTO: U1.40 (XTO)

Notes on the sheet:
USB
USB Type C
IO46: pulldown
IO46: inout &output
ESP32-S3-WROOM-2-N32R8V
IO47
IO48
ME6214C33
MIDI
PCM9211 ADC and SPDIF
ESP32S3
HEADERS
TF Card
CMD
CLK
Modular 10vpp
Fb=0.6V
PCM5101 DAC
Place C20 and C25 close to U4 (TL074)
POWER
AmyBoard V1.1 dpwe
XC6901 pin numbers are correct; pin 1 is GND and pin 2 is -VIN
P-chan FET with Rds < 0.1R @ Vgs=-3V e.g. DMP4065SQ



Board: 2 copper layers, 106.0 x 48.0 mm, 159 parts (11 on the bottom side), 106 nets.

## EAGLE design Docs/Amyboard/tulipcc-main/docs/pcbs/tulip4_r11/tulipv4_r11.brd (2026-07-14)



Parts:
3V3: PAD-TEST-POINT-CIRCLE'4545'; TP_4545; PARTNO DNP
5V: TEST-POINT'4545'; TP-D45MIL
AUDIO_CONN1: 19269; 4UCONN_19269
BAT: JST-2P; HW2-SMD-2.0-90D
BOOT: TS24CA; 2*4*3.5MM
C1, C61: 10pF/25V; DISCRETE_C0603
C2: 10pF/50V; DISCRETE_C0603
C3, C4, C5, C6, C10, C16, C20, C23, C29, C31, C63: 10uF; DISCRETE_C0603
C7, C8, C9, C14, C17, C18, C19, C21, C24, C25, C26, C28, C30, C32, C46, C47, C48, C49, C50, C51, C52, C53, C55, C62, C68: 0.1uF; DISCRETE_C0603
C11: 4.7uF/35V; DISCRETE_C1206
C12: 0.1uF/50V; DISCRETE_C0603
C13: NC; DISCRETE_C0603
C15, C60: 100nF; DISCRETE_C0603
C22, C27, C35, C36, C38, C40, C42, C43, C65: 10uF; 0603
C33: 22uF; C0603
C37, C39, C44: 0.1uF; 0603
C41, C64: 4.7uF/16V; 0603
C45, C66: NC; 0603
C54: 100nF; C0603
C56, C57, C58, C59: 1uF; DISCRETE_C0603
C67: 0.1uF/16V; DISCRETE_C0603
C69: 22pF; C0603
C73, C74, C75, C76: 0.1uF; 0805-NO@1
C77, C78: 2.2uF; 0805-NO@1
C79, C80, C81, C82: 10uF; PANASONIC_C
C83, C84: 2.2nF; 0805-NO@1
D1, D4, D9: 1N4148WS; SOD323
D2, D10, D12: SS54; DO-214AC
D3: W8/5.1V; SOD123
D5: 7.5V; SOD-323
D6, D7: 200mA/70V; SOT23-3
D8: 16V; SOD-323
D11: B5819WS; SOD323
FB1, FB2: 100Mhz@120R; R0805
GND: TEST-POINT'4545'; TP-D45MIL
I2C: GROVE-CONNECTOR-SMD'90D'; HW4-SMD-2.0-90D
L1, L2: 10µH/±30%; CR54
L3: 3.3µH/±30%/3.4A; CR54
M1, M2, M3, M4, M5, M6, M7, M8: M2.5
MIDI_IN_CONN2: 19269; 4UCONN_19269
MIDI_OUT_CONN3: 19269; 4UCONN_19269
P1, P4: 1X6P-1MM; 1*6P-SMT1MM
P3: 150P-0.5MM; 1*50P-SMT0.5MM
PWR: NC; CHIPLED_0805_NOOUTLINE
Q1, Q3, Q4, Q7: S8050; SOT23
Q6: MOSFET-PCHANNEL; SOT23-3
R1, R39, R40, R43, R44, R45, R60, R65: 10K; DISCRETE_R0603
R2, R17, R35, R51, R53, R54, R63: 0R; R0603
R3: 3.48K; DISCRETE_R0603
R4, R27: NC; R0603
R5: 220R; R0603
R6: 33R; R0603
R7: 10R; R0603
R8, R62: 0R; DISCRETE_R0603
R9: 470R; R0603
R10, R24, R64: 4.3K; DISCRETE_R0603
R11, R30: 2K; DISCRETE_R0603
R12, R13, R42, R47: 5.1K; DISCRETE_R0603
R14, R15: 56K; DISCRETE_R0603
R16, R22, R25, R26: 10K; R0603
R18: 1.2K; DISCRETE_R0603
R19, R31, R36, R37, R56, R61, R66: NC; DISCRETE_R0603
R20, R21: 51R; R0603
R23: 50R; DISCRETE_R0603
R28: 1.2K; R0603
R29: 10KR; DISCRETE_R0603
R32, R33: 3.6R; DISCRETE_R0603
R34, R38: 470K; R0603
R41, R59: 4.7K; DISCRETE_R0603
R46, R67, R68: 470; R0805
R48: 88.7K; DISCRETE_R0603
R49, R52, R57: 100K; DISCRETE_R0603
R50: 13K; DISCRETE_R0603
R58: 100k; R0603
R69: 12K; DISCRETE_R0603
RST: TS24CA; 2*4*3.5MM
RW1: TC33X-2-103E; TC33-3MM-SMD
SW1: JS102011JAQN; SMD-6-2.5MM
U1: ESP32­S2­SOLO; ESP32-­S2-­SOLO
U2: RY3730; SOT23-6
U3: CH340K; ESOP-10-EP-150MIL
U4: SGM6601YTN5G/TR; SOT-23-5
U5, U8: SPX3819; SOT23-5
U6: TP4056; SOP8-1.27P
U7: H11L1SR2M; SOP-6-2.54MM
U9: HX3608; SOT-23-6
U11: U11; PW20_TEX
USB-KEY: USB_C5; USB-C-16P-5
USB-TTL: USB_C5; USB-C-16P-5
VCOM: PAD-TEST-POINT-CIRCLE'4545'; TP_4545
VDD10: PAD-TEST-POINT-CIRCLE'4545'; TP_4545; PARTNO DNP
VGH: PAD-TEST-POINT-CIRCLE'4545'; TP_4545; PARTNO DNP
VGL: PAD-TEST-POINT-CIRCLE'4545'; TP_4545; PARTNO DNP
VPWR: PAD-TEST-POINT-CIRCLE'4545'; TP_4545; PARTNO DNP

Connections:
3.3V: 3V3.T, C5.2, C14.1, C16.2, C17.2, C20.2, C21.2, C22.1, C23.2, C24.2, C25.2, C26.2, C29.2, C30.2, C31.1, C32.1, C60.2, C62.2, C63.2, L2.P$1 (1), P1.1, P3.12, P3.43, P3.44, P4.1, R1.2, R6.1, R9.1, R36.2, R40.2, R42.2, R44.2, R45.2, R47.2, R63.2, R64.2, R65.2, U4.5 (VIN), U7.6 (VCC)
5V: 5V.T, C27.1, C28.2, C33.1, C54.1, C65.1, C68.2, C69.1, D10.C, D12.C, R14.1, R15.1, R48.2, R62.2, U8.5 (VOUT), USB-KEY.VBUS1 (VBUS), USB-KEY.VBUS2 (VBUS)
+3V3: C3.2, C9.1, C10.1, C18.2, C19.2, C42.1, C74.2, C75.2, C76.2, C80.+, C81.+, C82.+, I2C.3, PWR.A, R4.1, R16.2, R22.2, R27.2, R63.1, U1.2 (3V3), U3.7 (VCC), U3.10 (V3), U5.5 (VOUT), U11.1 (CPVDD), U11.8 (AVDD), U11.17 (XSMT), U11.20 (DVDD)
AGND: AUDIO_CONN1.1, C74.1, C76.1, C78.2, C81.-, C82.-, C83.2, C84.2, R8.1, U11.3 (CPGND), U11.9 (AGND)
AVDD10: C53.2, C55.2, C61.2, C64.1, C67.2, D7.1 (A1), D9.-, P3.8, R29.2, R49.2, U8.1 (VIN), U8.3 (EN), VDD10.T
BCLK: R53.2, U11.13 (BCK)
D+: U3.1 (UD+), USB-TTL.A6 (D+), USB-TTL.B6 (D+)
D-: U3.2 (UD-), USB-TTL.A7 (D-), USB-TTL.B7 (D-)
DCLK: C1.2, FB1.1, P3.14
DIN: R51.2, U11.14 (DIN)
DTR: Q3.2 (E), R26.2, U3.4 (DTR#)
ENABLE: R57.1, U9.4 (EN)
GND: BAT.3, BAT.4, BAT.- (2), BOOT.1, BOOT.3, BOOT.4, C1.1, C2.1, C3.1, C4.1, C5.1, C6.1, C7.1, C8.2, C9.2, C10.2, C11.1, C12.1, C13.1, C14.2, C15.1, C16.1, C17.1, C18.1, C19.1, C20.1, C21.1, C22.2, C23.1, C24.1, C25.1, C26.1, C27.2, C28.1, C29.1, C30.1, C31.2, C32.2, C33.2, C35.1, C36.1, C37.2, C38.2, C39.2, C40.2, C41.2, C42.2, C43.1, C44.2, C45.2, C46.1, C47.1, C50.1, C51.1, C52.1, C53.1, C54.2, C55.1, C56.1, C57.1, C58.1, C59.1, C60.1, C62.1, C63.1, C64.2, C65.2, C66.2, C67.1, C68.1, C73.2, C75.1, C79.-, C80.-, D3.A, D5.C, D6.2 (C2), D8.A, GND.T, I2C.4, I2C.SS1, I2C.SS2, M1.1, M2.1, M3.1, M4.1, M5.1, M6.1, M7.1, M8.1, MIDI_IN_CONN2.1, MIDI_OUT_CONN3.1, P1.6, P1.7, P1.8, P3.3, P3.11, P3.13, P3.15, P3.16, P3.17, P3.18, P3.24, P3.25, P3.26, P3.32, P3.33, P3.34, P3.35, P3.46, P3.51, P3.52, P4.6, P4.7, P4.8, Q1.2 (E), Q7.2 (E), R8.2, R10.1, R12.1, R13.1, R19.1, R24.1, R28.2, R30.1, R31.1, R32.1, R33.1, R37.2, R38.1, R43.1, R50.1, R58.2, R60.1, R61.1, R66.1, R69.1, RST.1, RST.3, RST.4, U1.1 (GND), U1.40 (GND), U1.41 (EPAD), U2.2 (GND), U3.3 (GND), U3.EP, U4.2 (GND), U5.2 (GND), U6.1 (TEMP), U6.3 (GND), U6.6 (DONE), U6.7 (CHRG), U6.9 (GND), U7.5 (GND), U8.2 (GND), U9.2 (GND), U11.10 (DEMP), U11.11 (FLT), U11.12 (SCK), U11.16 (FMT), U11.19 (DGND), USB-KEY.GND, USB-KEY.GND2 (GND), USB-TTL.GND, USB-TTL.GND2 (GND)
IO0: BOOT.2, Q3.3 (C), R22.1, U1.27 (IO0)
IO1: P3.39, U1.39 (IO1)
IO2: R54.1, U1.38 (IO2)
IO3: R34.1, R38.2, U1.15 (IO3)
IO4: P3.31, U1.4 (IO4)
IO5: R51.1, U1.5 (IO5)
IO6: P3.27, U1.6 (IO6)
IO7: P3.28, U1.7 (IO7)
IO8: R53.1, U1.12 (IO8)
IO9: P3.38, U1.17 (IO9)
IO10: P3.21, U1.18 (IO10)
IO11/MIDI_OUT: R7.1, U1.19 (IO11)
IO12/MIDI_IN: R9.2, U1.20 (IO12), U7.4 (VO)
IO13: P3.20, U1.21 (IO13)
IO14: P3.23, U1.22 (IO14)
IO15: P3.29, U1.8 (IO15)
IO16: P3.30, U1.9 (IO16)
IO17/I2C_SDA: I2C.2, P1.5, P4.5, R47.1, U1.10 (IO17)
IO18/I2C_SCL: I2C.1, P1.4, P4.4, R27.1, R42.1, U1.11 (IO18)
IO19: R20.2, U1.13 (IO19)
IO20: R21.2, U1.14 (IO20)
IO21: P3.22, U1.23 (IO21)
IO38: P3.36, U1.31 (IO38)
IO39: P3.40, R40.1, U1.32 (IO39)
IO40: P3.42, U1.33 (IO40)
IO41: P3.41, R45.1, U1.34 (IO41)
IO42: FB1.2, U1.35 (IO42)
IO45: P3.19, R4.2, U1.26 (IO45)
IO46: P3.37, U1.16 (IO46)
IO47: R59.2, U1.24 (IO33)
IO48: R41.2, U1.25 (IO34)
LCD_RST: C15.2, P3.7, R1.1
LED+: C11.2, C12.2, D1.-, P3.49, P3.50, R46.1, U2.5 (OVP)
LED-: P3.47, P3.48, R32.2, R33.2, R46.2, U2.3 (FB)
LOUT: AUDIO_CONN1.2, AUDIO_CONN1.4, C84.1, R68.1
LRC: R54.2, U11.15 (LRCK)
unnamed: C47.2, D6.1 (A1), R11.1
unnamed: Q4.1 (B), R26.1
unnamed: Q3.1 (B), R25.1
unnamed: C61.1, R49.1, R50.2, R52.1
unnamed: P3.4, R65.1, R66.2
unnamed: R15.2, USB-KEY.A5 (CC1)
unnamed: PWR.C, R19.2
unnamed: C48.2, D6.3 (COM)
unnamed: C48.1, C49.2, D9.+, L2.P$2 (2), U4.1 (SW)
unnamed: R13.2, USB-TTL.A5 (CC1)
unnamed: R12.2, USB-TTL.B5 (CC2)
unnamed: C49.1, D7.3 (COM)
unnamed: C50.2, D7.2 (C2), R18.2
unnamed: R14.2, USB-KEY.B5 (CC2)
unnamed: R52.2, U4.3 (FB)
unnamed: R3.1, R30.2, RW1.2, RW1.3
unnamed: D1.+, L1.P$2 (2), R23.2, U2.1 (LX)
unnamed: Q1.3 (C), R35.1
unnamed: R64.1, U4.4 (EN)
unnamed: Q1.1 (B), R41.1, R43.2
unnamed: FB2.1, USB-TTL.VBUS1 (VBUS), USB-TTL.VBUS2 (VBUS)
unnamed: C2.2, R23.1
unnamed: MIDI_IN_CONN2.3, MIDI_IN_CONN2.5, R5.2
unnamed: Q7.3 (C), R31.2, R39.1, U2.4 (EN)
unnamed: D12.A, L3.P$2 (2), U9.1 (SW)
unnamed: D4.-, R5.1, U7.1 (AN)
unnamed: MIDI_OUT_CONN3.3, MIDI_OUT_CONN3.5, R6.2
unnamed: C69.2, R48.1, R69.2, U9.3 (FB)
unnamed: Q7.1 (B), R59.1, R60.2
unnamed: R28.1, U6.2 (ISET)
unnamed: R61.2, U9.6 (NC)
unnamed: R56.1, R62.1, U9.5 (VIN)
unnamed: C66.1, U8.4 (BYP)
unnamed: MIDI_OUT_CONN3.2, MIDI_OUT_CONN3.4, R7.2
unnamed: D4.+, MIDI_IN_CONN2.2, MIDI_IN_CONN2.4, U7.2 (CAT)
unnamed: C73.1, C79.+, U11.18 (LDOO)
unnamed: R67.2, U11.7 (OUTR)
unnamed: C77.1, U11.4 (CAPM)
unnamed: R17.2, U3.9 (RXD)
unnamed: C77.2, U11.2 (CAPP)
unnamed: R2.2, U3.8 (TXD)
unnamed: C45.1, U5.4 (BYP)
OUTL: R68.2, U11.6 (OUTL)
RESET: C8.1, Q4.3 (C), R16.1, RST.2, U1.3 (EN)
ROUT: AUDIO_CONN1.3, AUDIO_CONN1.5, C83.1, R67.1
RTS: Q4.2 (E), R25.2, U3.6 (RTS#)
RXD/IO44: R2.1, U1.36 (RXD0)
TP_INT: P1.2, P4.2, R36.1, R37.1
TP_RST: C13.2, P1.3, P4.3, R35.2, R44.1
TXD/IO43: R17.1, U1.37 (TXD0)
USB_D+: R21.1, USB-KEY.A6 (D+), USB-KEY.B6 (D+)
USB_D-: R20.1, USB-KEY.A7 (D-), USB-KEY.B7 (D-)
VBAT: BAT.+ (1), C40.1, C44.1, D11.+, Q6.3 (D), R34.2, U6.5 (BAT)
VBUS: C4.2, C6.2, C7.2, C36.2, C37.1, C38.1, C39.1, D2.A, D10.A, FB2.2, Q6.1 (G), R58.1, U6.4 (VIN), U6.8 (CE)
VCOM: C52.2, P3.5, P3.45, R3.2, R29.1, RW1.1, VCOM.T
VGH: C51.2, C56.2, C57.2, D8.C, P3.10, R18.1, R24.2, VGH.T
VGL: C46.2, C58.2, C59.2, D5.A, P3.9, R10.2, R11.2, VGL.T
VNEG: C78.1, U11.5 (VNEG)
VOUT: C35.2, D2.C, D3.C, D11.-, Q6.2 (S), SW1.2, SW1.2@1 (2)
VPWR: C41.1, C43.2, L1.P$1 (1), L3.P$1 (1), R39.2, R56.2, R57.2, SW1.3, SW1.3@1 (3), U2.6 (IN), U5.1 (VIN), U5.3 (EN), VPWR.T

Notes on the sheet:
www.makerfabs.com
Design by Charlin
USB
LEDS
POWER AND FILTERING
USB TO SERIAL CONVERTER
Tulip CC v4r10
POWER
USB to UART
USB Type C
GT911
Closer to IC
Back Light
IO46: pulldown
IO46: inout &output
Mabee
LCD
MCU
ESP32-S3-WROOM-2-N32R8V
IO47
IO48
Closer to PIN4
LDO&Charger
AO3401
ME6217
VSYNC
HSYNC
GND
BAT54S
key flash
2.5~5.5V
Zener
IO47 and IO48 is 1.8V
VDD_SPI=1.8V IO45 pullup
ADC1_CH2
Fb=0.6V


Board: 2 copper layers, 105.0 x 165.0 mm, 211 parts (0 on the bottom side), 109 nets.

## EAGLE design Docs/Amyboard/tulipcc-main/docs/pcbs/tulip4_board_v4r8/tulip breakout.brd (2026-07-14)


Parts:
AUDIO_CONN: 19269; 4UCONN_19269
C4, C5: 4.7uF; 0805-NO
C8, C9, C10, C21: 0.1uF; 0805-NO
C11: 10uF; 0805-NO
C22, C23: 2.2uF; 0805-NO
C28, C29, C30, C31: 10uF; PANASONIC_C
C32, C33: 2.2nF; 0805-NO
D2: EGF1A; DIOM449X264X300L114X135N
ESP32S3: ESP32-S3-WROOM-2-N32R8V; XCVR_ESP32-S3-WROOM-2-N32R8V
EXP: PINHD-1X8BIG; 1X08-BIG
EXT-USB: EG1224; SW_EG1224
H1, H2: MOUNT-HOLE2.8; 2,8
INPUT: CSP-USC16-TR; VALCON_CSP-USC16-TR
J3: 40PINFPC15-1F-REV; XF2M-4015-1F-REVERSE
KEYBD: CSP-USC16-TR; VALCON_CSP-USC16-TR
MIDI_IN_CONN: 19269; 4UCONN_19269
MIDI_OUT_CONN: 19269; 4UCONN_19269
OPTO: VO0601T; SOIC127P610X331-8N
PCM: PCM5101APW; PW20_TEX
POWER: EG1224; SW_EG1224
PWR: 440055-3; TE_440055-3
R1, R6: 100k; R0805
R5, R7: 10k; R0805
R9, R10: 5.1K; R0805
R12, R13, R14: 4.7K; R0805
R15: 220; R0805
R16, R19, R20: 470; R0805
R17: 33; R0805
R18: 10; R0805
REG: LD29150DT33R; DPAK456P972X240-3N
RESET: MBT3904DW1T1G; SOT236
SERIAL: CH340C; SO016
SNES: SNESCONN

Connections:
3V3: C5.1, C9.2, C10.2, C21.2, C29.+, C30.+, C31.+, ESP32S3.2 (3V3), EXP.2, J3.37 (MS), PCM.1 (CPVDD), PCM.8 (AVDD), PCM.17 (XSMT), PCM.20 (DVDD), R5.2, R7.1, R13.1, R14.1, R16.2, R17.1, REG.2 (OUTPUT)
5V: EXP.1, J3.39 (MS), J3.40 (MS), KEYBD.A4 (VBUS_A), KEYBD.A9 (VBUS_A), KEYBD.B4 (VBUS_B), KEYBD.B9 (VBUS_B), OPTO.8 (VCC), POWER.1, REG.1 (INPUT), SNES.5V
5V_IN: EXT-USB.3, PWR.3
5V_USB: EXT-USB.1, INPUT.A4 (VBUS_A), INPUT.A9 (VBUS_A), INPUT.B4 (VBUS_B), INPUT.B9 (VBUS_B), PWR.2, SERIAL.16 (VCC)
!DTR: R1.2, RESET.4, SERIAL.13 (!DTR)
!RTS: R6.1, RESET.1, SERIAL.14 (!RTS)
AGND: AUDIO_CONN.1, C9.1, C21.1, C23.2, C30.-, C31.-, C32.2, C33.2, PCM.3 (CPGND), PCM.9 (AGND)
B6: ESP32S3.20 (IO12), J3.14 (MS)
B7: ESP32S3.23 (IO21), J3.13 (MS)
BCLK: ESP32S3.39 (IO1), PCM.13 (BCK)
BLEN: ESP32S3.32 (IO39), J3.10 (MS)
D+: ESP32S3.14 (IO20), KEYBD.A6 (DP1), KEYBD.B6 (DP2)
D-: ESP32S3.13 (IO19), KEYBD.A7 (DN1), KEYBD.B7 (DN2)
DE: ESP32S3.35 (IO42), J3.7 (MS)
DIN: ESP32S3.38 (IO2), PCM.14 (DIN)
DN1: INPUT.A7 (DN1), INPUT.B7 (DN2), SERIAL.6 (UD-)
DP1: INPUT.A6 (DP1), INPUT.B6 (DP2), SERIAL.5 (UD+)
ESP32_EN: C4.1, ESP32S3.3 (EN), R5.1, RESET.6
EXT-USB: EXT-USB.2, POWER.2
G5: ESP32S3.12 (IO8), J3.23 (MS)
G6: ESP32S3.15 (IO3), J3.22 (MS)
G7: ESP32S3.16 (IO46), J3.21 (MS)
GND: C4.2, C5.2, C8.2, C10.1, C11.1, C28.-, C29.-, ESP32S3.1 (GND), ESP32S3.40 (GND), ESP32S3.41_1 (GND), ESP32S3.41_2 (GND), ESP32S3.41_3 (GND), ESP32S3.41_4 (GND), ESP32S3.41_5 (GND), ESP32S3.41_6 (GND), ESP32S3.41_7 (GND), ESP32S3.41_8 (GND), ESP32S3.41_9 (GND), EXP.3, INPUT.A1 (GND_A), INPUT.A12 (GND_A), INPUT.B1 (GND_B), INPUT.B12 (GND_B), INPUT.S1 (SHELL_GND), INPUT.S2 (SHELL_GND), INPUT.S3 (SHELL_GND), INPUT.S4 (SHELL_GND), J3.5 (MS), J3.12 (MS), J3.15 (MS), J3.16 (MS), J3.17 (MS), J3.18 (MS), J3.19 (MS), J3.20 (MS), J3.24 (MS), J3.25 (MS), J3.26 (MS), J3.27 (MS), J3.28 (MS), J3.32 (MS), J3.33 (MS), J3.34 (MS), J3.35 (MS), J3.36 (MS), J3.38 (MS), KEYBD.A1 (GND_A), KEYBD.A12 (GND_A), KEYBD.B1 (GND_B), KEYBD.B12 (GND_B), KEYBD.S1 (SHELL_GND), KEYBD.S2 (SHELL_GND), KEYBD.S3 (SHELL_GND), KEYBD.S4 (SHELL_GND), MIDI_IN_CONN.1, MIDI_OUT_CONN.1, OPTO.5 (GND), PCM.10 (DEMP), PCM.11 (FLT), PCM.12 (SCK), PCM.16 (FMT), PCM.19 (DGND), PWR.1, R9.2, R10.1, R12.1, REG.3 (GND), SERIAL.1 (GND), SNES.GND
GPIO10: ESP32S3.18 (IO10)
HSYNC: ESP32S3.33 (IO40), J3.9 (MS)
INT: ESP32S3.5 (IO5), J3.1 (MSV)
IO0: ESP32S3.27 (IO0), EXP.7, R7.2, RESET.3
IO9: ESP32S3.17 (IO9), EXP.8
IO38: ESP32S3.31 (IO38), EXP.6
JOY_CLK: ESP32S3.21 (IO13), SNES.CLOCK
JOY_D0: ESP32S3.26 (IO45), SNES.D0
JOY_LATCH: ESP32S3.25 (IO48), SNES.LATCH
LOUT: AUDIO_CONN.2, AUDIO_CONN.4, C33.1, R20.1
LRC: ESP32S3.4 (IO4), PCM.15 (LRCK)
MIDI_IN: ESP32S3.24 (IO47), OPTO.6 (VO), R16.1
MIDI_IN_SINK: D2.A, MIDI_IN_CONN.2, MIDI_IN_CONN.4, OPTO.3 (C)
MIDI_IN_SOURCE: MIDI_IN_CONN.3, MIDI_IN_CONN.5, R15.2
MIDI_OUT: ESP32S3.19 (IO11), R18.2
MIDI_OUT_SINK: MIDI_OUT_CONN.2, MIDI_OUT_CONN.4, R18.1
MIDI_OUT_SOURCE: MIDI_OUT_CONN.3, MIDI_OUT_CONN.5, R17.2
unnamed: R1.1, RESET.2
unnamed: R6.2, RESET.5
unnamed: INPUT.B5 (CC2), R10.2
unnamed: C8.1, C28.+, PCM.18 (LDOO)
unnamed: PCM.7 (OUTR), R19.2
unnamed: C22.1, PCM.4 (CAPM)
unnamed: C22.2, PCM.2 (CAPP)
unnamed: D2.C, OPTO.2 (A), R15.1
unnamed: OPTO.7 (VE), R12.2
unnamed: C11.2, SERIAL.4 (V3)
unnamed: INPUT.A5 (CC1), R9.1
OUTL: PCM.6 (OUTL), R20.2
PCLK: ESP32S3.22 (IO14), J3.11 (MS)
PWM: ESP32S3.9 (IO16), J3.6 (MS)
R5: ESP32S3.6 (IO6), J3.31 (MS)
R6: ESP32S3.7 (IO7), J3.30 (MS)
R7: ESP32S3.8 (IO15), J3.29 (MS)
ROUT: AUDIO_CONN.3, AUDIO_CONN.5, C32.1, R19.1
SCL: ESP32S3.10 (IO17), EXP.5, J3.3 (MS), R14.2
SDA: ESP32S3.11 (IO18), EXP.4, J3.4 (MS), R13.2
UART0_RXD: ESP32S3.36 (RXD0), SERIAL.2 (TXO)
UART0_TXD: ESP32S3.37 (TXD0), SERIAL.3 (RXI)
VNEG: C23.1, PCM.5 (VNEG)
VSYNC: ESP32S3.34 (IO41), J3.8 (MS)

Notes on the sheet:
SNES port



Board: 2 copper layers, 66.2 x 55.6 mm, 50 parts (2 on the bottom side), 63 nets.

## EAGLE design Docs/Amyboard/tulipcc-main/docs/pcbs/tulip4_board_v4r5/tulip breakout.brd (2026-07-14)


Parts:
6N137S: 6N137S; 8-SMD
AUDIO_CONN: 19269; 4UCONN_19269
C4, C5: 4.7uF; 0805-NO
C8, C9, C10, C21: 0.1uF; 0805-NO
C11: 10nF; 0805-NO
C22, C23: 2.2uF; 0805-NO
C28, C29, C30, C31: 10uF; PANASONIC_C
C32, C33: 2.2nF; 0805-NO
D2: EGF1A; DIOM449X264X300L114X135N
J1: CSP-USC16-TR; VALCON_CSP-USC16-TR
J3: TSM-106-02-L-DH-A; SAMTEC_TSM-106-02-L-DH-A
MIDI_IN_CONN: 19269; 4UCONN_19269
MIDI_OUT_CONN: 19269; 4UCONN_19269
POWER: 500ASSP1SM6QE; SW_500ASSP1SM6QE
R1, R6: 100k; R0805
R5, R7: 10k; R0805
R9, R10: 5.1K; R0805
R12, R13, R14: 4.7K; R0805
R15: 220; R0805
R16, R19, R20: 470; R0805
R17: 33; R0805
R18: 10; R0805
RESET: MBT3904DW1T1G; SOT236
U1: ESP32-S3-WROOM-2-N32R8V; XCVR_ESP32-S3-WROOM-2-N32R8V
U2: LD29150DT33R; DPAK456P972X240-3N
U3: PCM5101APW; PW20_TEX
U6: CH340C; SO016
USBKB: USB-A-S-X-X-SM2; SAMTEC_USB-A-S-X-X-SM2
X2: FH12-40S-0.5SH

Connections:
3V3: C5.1, C9.2, C10.2, C21.2, C29.+, C30.+, C31.+, J3.03, R5.2, R7.1, R13.1, R14.1, R16.2, R17.1, U1.2 (3V3), U2.2 (OUTPUT), U3.1 (CPVDD), U3.8 (AVDD), U3.17 (XSMT), U3.20 (DVDD), U6.16 (VCC), X2.37
5V: 6N137S.8 (VCC), J3.07, POWER.1 (NC), U2.1 (INPUT), USBKB.01 (VCC), X2.39, X2.40
5V_IN: J3.01, J3.12
5V_USB: J1.A4 (VBUS_A), J1.A9 (VBUS_A), J1.B4 (VBUS_B), J1.B9 (VBUS_B), J3.02, J3.10
!DTR: R1.2, RESET.4, U6.13 (!DTR)
!RTS: R6.1, RESET.1, U6.14 (!RTS)
AGND: AUDIO_CONN.1, C9.1, C21.1, C23.2, C30.-, C31.-, C32.2, C33.2, U3.3 (CPGND), U3.9 (AGND)
B6: U1.20 (IO12), X2.14
B7: U1.23 (IO21), X2.13
BCLK: U1.39 (IO1), U3.13 (BCK)
BLEN: U1.32 (IO39), X2.10
D+: U1.14 (IO20), USBKB.03 (D+)
D-: U1.13 (IO19), USBKB.02 (D-)
DE: U1.35 (IO42), X2.7
DIN: U1.38 (IO2), U3.14 (DIN)
DN1: J1.A7 (DN1), U6.6 (UD-)
DP1: J1.A6 (DP1), U6.5 (UD+)
ESP32_EN: C4.1, R5.1, RESET.6, U1.3 (EN)
G5: U1.12 (IO8), X2.23
G6: U1.15 (IO3), X2.22
G7: U1.16 (IO46), X2.21
GND: 6N137S.5 (GND), C4.2, C5.2, C8.2, C10.1, C11.1, C28.-, C29.-, J1.A1 (GND_A), J1.A12 (GND_A), J1.B1 (GND_B), J1.B12 (GND_B), J1.S1 (SHELL_GND), J1.S2 (SHELL_GND), J1.S3 (SHELL_GND), J1.S4 (SHELL_GND), J3.04, J3.08, MIDI_IN_CONN.1, MIDI_OUT_CONN.1, R9.2, R10.1, R12.1, U1.1 (GND), U1.40 (GND), U1.41_1 (GND), U1.41_2 (GND), U1.41_3 (GND), U1.41_4 (GND), U1.41_5 (GND), U1.41_6 (GND), U1.41_7 (GND), U1.41_8 (GND), U1.41_9 (GND), U2.3 (GND), U3.10 (DEMP), U3.11 (FLT), U3.12 (SCK), U3.16 (FMT), U3.19 (DGND), U6.1 (GND), USBKB.04 (GND), USBKB.S1 (SHIELD), USBKB.S2 (SHIELD), X2.5, X2.12, X2.15, X2.16, X2.17, X2.18, X2.19, X2.20, X2.24, X2.25, X2.26, X2.27, X2.28, X2.32, X2.33, X2.34, X2.35, X2.36, X2.38
GPIO10: U1.18 (IO10)
HSYNC: U1.33 (IO40), X2.9
INT: U1.5 (IO5), X2.1
IO0: R7.2, RESET.3, U1.27 (IO0)
LOUT: AUDIO_CONN.2, AUDIO_CONN.4, C33.1, R20.1
LRC: U1.4 (IO4), U3.15 (LRCK)
MIDI_IN: 6N137S.6 (VOUT), R16.1, U1.24 (IO47)
MIDI_IN_SINK: 6N137S.3 (C), D2.A, MIDI_IN_CONN.2, MIDI_IN_CONN.4
MIDI_IN_SOURCE: MIDI_IN_CONN.3, MIDI_IN_CONN.5, R15.2
MIDI_OUT: R18.2, U1.19 (IO11)
MIDI_OUT_SINK: MIDI_OUT_CONN.2, MIDI_OUT_CONN.4, R18.1
MIDI_OUT_SOURCE: MIDI_OUT_CONN.3, MIDI_OUT_CONN.5, R17.2
unnamed: R1.1, RESET.2
unnamed: R6.2, RESET.5
unnamed: J1.B5 (CC2), R10.2
unnamed: C8.1, C28.+, U3.18 (LDOO)
unnamed: R19.2, U3.7 (OUTR)
unnamed: J3.09, J3.11, POWER.2 (COM)
unnamed: C22.1, U3.4 (CAPM)
unnamed: C22.2, U3.2 (CAPP)
unnamed: 6N137S.2 (A), D2.C, R15.1
unnamed: 6N137S.7 (EN), R12.2
unnamed: C11.2, U6.4 (V3)
unnamed: J1.A5 (CC1), R9.1
OUTL: R20.2, U3.6 (OUTL)
PCLK: U1.22 (IO14), X2.11
PWM: U1.9 (IO16), X2.6
PWR: U1.17 (IO9)
R5: U1.6 (IO6), X2.31
R6: U1.7 (IO7), X2.30
R7: U1.8 (IO15), X2.29
ROUT: AUDIO_CONN.3, AUDIO_CONN.5, C32.1, R19.1
SCL: J3.06, R14.2, U1.10 (IO17), X2.3
SDA: J3.05, R13.2, U1.11 (IO18), X2.4
UART0_RXD: U1.36 (RXD0), U6.2 (TXO)
UART0_TXD: U1.37 (TXD0), U6.3 (RXI)
VNEG: C23.1, U3.5 (VNEG)
VSYNC: U1.34 (IO41), X2.8


Board: 2 copper layers, 78.8 x 55.6 mm, 45 parts (0 on the bottom side), 58 nets.

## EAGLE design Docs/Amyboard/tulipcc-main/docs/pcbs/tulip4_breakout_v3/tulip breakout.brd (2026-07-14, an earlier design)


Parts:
AUDIO3: PINHD-1X6; 1X06
D1: 1N4004; DO41-10
DISPLAY1: MA20-2
ESP32S3L, ESP32S3R: PINHD-1X22; 1X22
H1, H2: MOUNT-HOLE2.8; 2,8
MIDIIN: MIDIJACK; CP-2350
MIDIOUT: MIDIJACK; CP-2350
OK1: 6N138; DIL08
R1, R2, R3: 4.7K; 0207/12
R4: 220; 0207/12
R5: 470; 0207/12
R6: 33; 0207/12
R7: 10; 0207/12
X1: PN87520

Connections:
3V3: DISPLAY1.37, ESP32S3L.1, ESP32S3L.2, R1.2, R2.2, R5.2, R6.2
5V: AUDIO3.1, DISPLAY1.39, DISPLAY1.40, ESP32S3L.21, OK1.8 (VCC), X1.1
B6: DISPLAY1.14, ESP32S3L.18
B7: DISPLAY1.13, ESP32S3R.18
BCLK: AUDIO3.6, ESP32S3R.4
BLEN: DISPLAY1.10, ESP32S3R.9
D+: ESP32S3R.19, X1.3
D-: ESP32S3R.20, X1.2
DE: DISPLAY1.7, ESP32S3R.6
DIN: AUDIO3.5, ESP32S3R.5
G5: DISPLAY1.23, ESP32S3L.12
G6: DISPLAY1.22, ESP32S3L.13
G7: DISPLAY1.21, ESP32S3L.14
GND: AUDIO3.3, DISPLAY1.5, DISPLAY1.12, DISPLAY1.15, DISPLAY1.16, DISPLAY1.17, DISPLAY1.18, DISPLAY1.19, DISPLAY1.20, DISPLAY1.24, DISPLAY1.25, DISPLAY1.26, DISPLAY1.27, DISPLAY1.28, DISPLAY1.32, DISPLAY1.33, DISPLAY1.34, DISPLAY1.35, DISPLAY1.36, DISPLAY1.38, ESP32S3L.22, ESP32S3R.1, ESP32S3R.21, ESP32S3R.22, MIDIOUT.2, OK1.5 (GND), R3.1, X1.4
HSYNC: DISPLAY1.9, ESP32S3R.8
INT: DISPLAY1.1, ESP32S3L.5
LRC: AUDIO3.4, ESP32S3L.4
MIDI_IN: ESP32S3R.17, OK1.6 (VO), R5.1
MIDI_OUT: ESP32S3L.17, R7.1
unnamed: MIDIIN.4, R4.1
unnamed: D1.C, OK1.2 (A), R4.2
unnamed: D1.A, MIDIIN.5, OK1.3 (C)
unnamed: OK1.7 (VB), R3.2
unnamed: MIDIOUT.5, R7.2
unnamed: MIDIOUT.4, R6.1
PCLK: DISPLAY1.11, ESP32S3L.20
PWM: DISPLAY1.6, ESP32S3L.9
R5: DISPLAY1.31, ESP32S3L.6
R6: DISPLAY1.30, ESP32S3L.7
R7: DISPLAY1.29, ESP32S3L.8
SCL: DISPLAY1.3, ESP32S3L.10, R2.1
SDA: DISPLAY1.4, ESP32S3L.11, R1.1
VSYNC: DISPLAY1.8, ESP32S3R.7


Board: 2 copper layers, 89.1 x 43.5 mm, 18 parts (1 on the bottom side), 33 nets.

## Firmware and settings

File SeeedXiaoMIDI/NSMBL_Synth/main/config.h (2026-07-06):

#pragma once

// --- Band Member Identity ---
// Copy a named config from configs/ before building, e.g.:
//   cp configs/config_Eenoo.h  main/config.h   (pads,  ch1)
//   cp configs/config_Prynz.h  main/config.h   (lead,  ch2)
//   cp configs/config_Botsee.h main/config.h   (bass,  ch3)
//   cp configs/config_Moroh.h  main/config.h   (arps,  ch5)
//   cp configs/config_8OhAte.h main/config.h   (drums, ch10)
#define DEVICE_NAME     "NSMBL_Synth"
#define DEFAULT_PATCH   0
#define DEFAULT_BANK    0

// --- Channel behavior ---
// The unit listens on exactly two MIDI channels and ignores all others, like a
// normal hardware synth — you route in your host (AUM). Send melody to MIDI
// channel 1 and GM drums to channel 10; anything else is dropped by the parser.
#define VOICE_CHANNEL   0       // melodic voice (internal 0 = MIDI channel 1)
#define DRUM_CHANNEL    9       // GM drums   (internal 9 = MIDI channel 10)

// --- Hardware Pins (XIAO ESP32-C3) ---
#define BUTTON_0_PIN    5
#define BUTTON_1_PIN    4
#define BUTTON_2_PIN    3
#define BUTTON_3_PIN    2
#define LED_PIN         10      // Active LOW

// --- SAM2695 UART ---
#define SAM_UART_NUM    UART_NUM_0
#define SAM_UART_BAUD   31250
#define SAM_TX_PIN      21      // XIAO Serial0 TX
#define SAM_RX_PIN      20      // XIAO Serial0 RX

// --- MIDI Event Queue ---
#define MIDI_QUEUE_SIZE 64

// --- Button Timing ---
#define DEBOUNCE_MS     50
#define LONG_PRESS_MS   600

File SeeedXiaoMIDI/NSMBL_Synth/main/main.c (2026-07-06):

#include "config.h"
#include "ble_midi.h"
#include "sam2695.h"
#include "buttons.h"

#include "esp_log.h"
#include "nvs_flash.h"
#include "driver/gpio.h"
#include "esp_timer.h"
#include "freertos/FreeRTOS.h"
#include "freertos/task.h"
#include "freertos/queue.h"

static const char *TAG = "nsmbl";

// --- Voice state ---
static uint8_t  current_program = DEFAULT_PATCH;
static uint8_t  current_bank    = DEFAULT_BANK;
static uint8_t  current_volume  = 100;
static uint32_t last_note_ms    = 0;   // when the last incoming note arrived

// A Program Change is silent on its own, so preview the new voice with a short
// note when a patch button is pressed while nothing is being played.
#define AUDITION_IDLE_MS 1200

static uint32_t now_ms(void)
{
    return (uint32_t)(esp_timer_get_time() / 1000);
}

// --- GM Patch names (first 10 of each family for display) ---
static const char *GM_FAMILIES[] = {
    "Piano", "Chrom Perc", "Organ", "Guitar",
    "Bass", "Strings", "Ensemble", "Brass",
    "Reed", "Pipe", "Synth Lead", "Synth Pad",
    "Synth FX", "Ethnic", "Percussive", "SFX"
};

// --- MIDI event processing ---
// The parser only delivers events on VOICE_CHANNEL (melody, MIDI ch1) and
// DRUM_CHANNEL (GM drums, MIDI ch10), so each message just plays on its own
// channel. Program/bank/volume state is tracked for the melodic voice only.
static void process_midi_event(const midi_event_t *event)
{
    uint8_t ch    = event->channel - 1;              // VOICE_CHANNEL or DRUM_CHANNEL
    bool    drums = (ch == DRUM_CHANNEL);

    switch (event->type) {
    case MIDI_NOTE_ON:
        last_note_ms = now_ms();
        sam2695_note_on(ch, event->data1, event->data2);
        break;

    case MIDI_NOTE_OFF:
        sam2695_note_off(ch, event->data1);
        break;

    case MIDI_CC:
        if (!drums && event->data1 == 0) {
            // Bank Select MSB — SAM2695 has only bank 0 (GM) and 127 (MT-32).
            // Clamp and track it so the next Program Change uses the same bank.
            current_bank = (event->data2 == 0) ? 0 : 127;
            sam2695_control_change(VOICE_CHANNEL, 0, current_bank);
        } else {
            sam2695_control_change(ch, event->data1, event->data2);
            if (!drums && event->data1 == 7) {
                current_volume = event->data2;
            }
        }
        break;

    case MIDI_PROGRAM_CHANGE:
        if (drums) {
            // On channel 10 a Program Change selects the drum kit (bank 0).
            sam2695_program_change(DRUM_CHANNEL, 0, event->data1);
        } else {
            sam2695_program_change(VOICE_CHANNEL, current_bank, event->data1);
            current_program = event->data1;
            ESP_LOGI(TAG, "Patch: [%d] %s", event->data1,
                     GM_FAMILIES[event->data1 / 8]);
        }
        break;

    case MIDI_PITCH_BEND: {
        uint16_t bend = (uint16_t)(event->pitch_bend + 8192);
        sam2695_pitch_bend(ch, bend);
        break;
    }

    case MIDI_AFTERTOUCH:
        sam2695_aftertouch(ch, event->data1);
        break;
    }
}

// --- Voice audition ---
// Play a short preview note on the voice channel so a patch-button press is
// audible. Skipped if a note arrived recently, so it won't interrupt playing.
static void audition_voice(void)
{
    if (last_note_ms != 0 && (now_ms() - last_note_ms) < AUDITION_IDLE_MS) {
        return;
    }
    // The SAM2695 needs time to load the new patch's wavetable after a Program
    // Change; a note played too soon (<~150ms) still uses the OLD patch. 250ms
    // is a safe margin so the preview always reflects the selected voice.
    vTaskDelay(pdMS_TO_TICKS(250));
    sam2695_note_on(VOICE_CHANNEL, 60, 110);   // single C4 preview note
    vTaskDelay(pdMS_TO_TICKS(500));
    sam2695_note_off(VOICE_CHANNEL, 60);
}

// --- Button callbacks ---
// Patch navigation:
//   Button 0/1 = coarse — jump by instrument family (16 distinct voices)
//   Button 2/3 = fine   — step one patch at a time within/across families
// Each press auditions the new voice.
static void on_short_press(uint8_t idx)
{
    switch (idx) {
    case 0: {  // Family down — jump to the previous instrument family
        uint8_t fam = (current_program / 8 + 15) & 0x0F;   // -1 family, wraps 0..15
        current_program = fam * 8;
        sam2695_program_change(VOICE_CHANNEL, current_bank, current_program);
        ESP_LOGI(TAG, "Family down -> [%d] %s", current_program,
                 GM_FAMILIES[current_program / 8]);
        audition_voice();
        break;
    }
    case 1: {  // Family up — jump to the next instrument family
        uint8_t fam = (current_program / 8 + 1) & 0x0F;    // +1 family, wraps 0..15
        current_program = fam * 8;
        sam2695_program_change(VOICE_CHANNEL, current_bank, current_program);
        ESP_LOGI(TAG, "Family up   -> [%d] %s", current_program,
                 GM_FAMILIES[current_program / 8]);
        audition_voice();
        break;
    }
    case 2:  // Patch down — fine step to the previous voice
        current_program = (current_program == 0) ? 127 : (current_program - 1);
        sam2695_program_change(VOICE_CHANNEL, current_bank, current_program);
        ESP_LOGI(TAG, "Patch down  -> [%d] %s", current_program,
                 GM_FAMILIES[current_program / 8]);
        audition_voice();
        break;
    case 3:  // Patch up — fine step to the next voice
        current_program = (current_program + 1) & 0x7F;
        sam2695_program_change(VOICE_CHANNEL, current_bank, current_program);
        ESP_LOGI(TAG, "Patch up    -> [%d] %s", current_program,
                 GM_FAMILIES[current_program / 8]);
        audition_voice();
        break;
    }
}

static void on_long_press(uint8_t idx)
{
    switch (idx) {
    case 0:  // (reserved)
        break;
    case 1:  // Volume up
        current_volume = (current_volume + 10 > 127) ? 127 : current_volume + 10;
        sam2695_set_volume(VOICE_CHANNEL, current_volume);
        ESP_LOGI(TAG, "Volume: %d", current_volume);
        break;
    case 2:  // Volume down
        current_volume = (current_volume < 10) ? 0 : current_volume - 10;
        sam2695_set_volume(VOICE_CHANNEL, current_volume);
        ESP_LOGI(TAG, "Volume: %d", current_volume);
        break;
    case 3:  // MIDI panic
        for (uint8_t ch = 0; ch < 16; ch++) {
            sam2695_all_notes_off(ch);
        }
        ESP_LOGI(TAG, "PANIC: All notes off");
        break;
    }
}

// --- LED blink task ---
static void led_task(void *arg)
{
    gpio_config_t led_cfg = {
        .pin_bit_mask = (1ULL << LED_PIN),
        .mode         = GPIO_MODE_OUTPUT,
    };
    gpio_config(&led_cfg);
    gpio_set_level(LED_PIN, 1);  // off (active LOW)

    extern bool ble_midi_is_connected(void);

    while (1) {
        if (ble_midi_is_connected()) {
            gpio_set_level(LED_PIN, 0);  // solid on
        } else {
            // slow blink
            int64_t ms = esp_timer_get_time() / 1000;
            gpio_set_level(LED_PIN, (ms % 1000 < 100) ? 0 : 1);
        }
        vTaskDelay(pdMS_TO_TICKS(50));
    }
}

// --- Main event loop ---
static void midi_task(void *arg)
{
    QueueHandle_t midi_queue = (QueueHandle_t)arg;
    midi_event_t event;

    while (1) {
        if (xQueueReceive(midi_queue, &event, pdMS_TO_TICKS(10))) {
            process_midi_event(&event);
        }
        buttons_poll();
        vTaskDelay(1);
    }
}

void app_main(void)
{
    ESP_LOGI(TAG, "=================================");
    ESP_LOGI(TAG, "  %s", DEVICE_NAME);
    ESP_LOGI(TAG, "  XIAO BLE MIDI + SAM2695");
    ESP_LOGI(TAG, "=================================");

    // NVS (required for BLE)
    esp_err_t ret = nvs_flash_init();
    if (ret == ESP_ERR_NVS_NO_FREE_PAGES || ret == ESP_ERR_NVS_NEW_VERSION_FOUND) {
        ESP_ERROR_CHECK(nvs_flash_erase());
        ret = nvs_flash_init();
    }
    ESP_ERROR_CHECK(ret);

    // SAM2695 init (UART + boot delay)
    sam2695_init();

    // Init all 16 channels to default volume
    for (uint8_t ch = 0; ch < 16; ch++) {
        sam2695_set_volume(ch, 100);
        vTaskDelay(pdMS_TO_TICKS(10));
    }

    // Set default melodic voice on the voice channel
    sam2695_program_change(VOICE_CHANNEL, current_bank, current_program);
    ESP_LOGI(TAG, "Boot voice -> patch %d [%s] bank %d",
             current_program, GM_FAMILIES[current_program / 8], current_bank);
    vTaskDelay(pdMS_TO_TICKS(50));

    // Default reverb/chorus on the voice channel
    sam2695_control_change(VOICE_CHANNEL, 0x50, 1);   // Reverb type: Room 2
    sam2695_control_change(VOICE_CHANNEL, 0x5B, 30);  // Reverb send: 30
    sam2695_control_change(VOICE_CHANNEL, 0x51, 0);   // Chorus type: Chorus 1
    sam2695_control_change(VOICE_CHANNEL, 0x5D, 0);   // Chorus send: 0

    // Boot flourish: a drummer (DRUM_CHANNEL is a real MIDI channel 0-15) gets
    // the signature beat; a synth (DRUM_CHANNEL disabled, > 15) gets a short
    // hello note in its own voice.
#if DRUM_CHANNEL <= 15
    sam2695_boot_sound(DRUM_CHANNEL);
#else
    sam2695_note_on(VOICE_CHANNEL, 60, 100);
    vTaskDelay(pdMS_TO_TICKS(350));
    sam2695_note_off(VOICE_CHANNEL, 60);
#endif

    // Buttons
    buttons_init(on_short_press, on_long_press);

    // MIDI queue + BLE
    QueueHandle_t midi_queue = xQueueCreate(MIDI_QUEUE_SIZE, sizeof(midi_event_t));
    ble_midi_init(midi_queue);

    // Start tasks
    xTaskCreate(midi_task, "midi", 4096, midi_queue, 5, NULL);
    xTaskCreate(led_task, "led", 2048, NULL, 2, NULL);

    ESP_LOGI(TAG, "=== %s ready ===", DEVICE_NAME);
}

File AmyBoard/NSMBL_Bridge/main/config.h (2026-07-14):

#pragma once

// --- Bridge identity (generic default) ---
// Copy a named config from ../configs/ before building, e.g.:
//   cp configs/config_Garee.h main/config.h
#define DEVICE_NAME     "NSMBL_Bridge"

// --- Bridge channel routing ---
//   BRIDGE_IN:  BRIDGE_ALL (0) = forward every channel, or 1-16 = only that channel
//   BRIDGE_OUT: BRIDGE_PASSTHROUGH (0) = keep each message's original channel,
//               or 1-16 = remap ALL forwarded messages onto that one channel
//               (handy because most hardware is fixed to channel 1).
#define BRIDGE_ALL          0
#define BRIDGE_PASSTHROUGH  0
#define BRIDGE_IN   BRIDGE_ALL          // generic default: forward everything...
#define BRIDGE_OUT  BRIDGE_PASSTHROUGH  // ...unchanged

// --- AMYboard DIN MIDI out (UART1) ---
// AMYboard: MIDI OUT Type A = GPIO14 (Type B = GPIO15), MIDI IN = GPIO21, UART1.
#define MIDI_UART_NUM   UART_NUM_1
#define MIDI_BAUD       31250
#define MIDI_TX_PIN     14      // MIDI OUT data leg (Type A); use 15 for Type B
#define MIDI_RX_PIN     21      // MIDI IN — reserved for future thru/merge
// The OUT jack is TRS tip=GPIO14, ring=GPIO15, sleeve=GND with NO fixed 3.3V rail.
// A DIN MIDI opto needs a current source, so the *other* leg must be held HIGH
// (MIDI idle/source). Type A: TX=14, SRC=15. Type B: swap to TX=15, SRC=14.
#define MIDI_SRC_PIN    15

// --- I2C bus (Qwiic accessories: Modulino Knob + SH1107 OLED) ---
#define I2C_SDA             17
#define I2C_SCL             18
#define I2C_FREQ_HZ         400000
#define KNOB_ADDR_PRIMARY   0x3B    // Modulino Knob 7-bit (Arduino 8-bit 0x76 / 2)
#define KNOB_ADDR_ALT       0x3A    // Modulino Knob 7-bit (Arduino 8-bit 0x74 / 2)
#define OLED_ADDR           0x3C    // SH1107 128x128
#define OLED_SETUP          u8g2_Setup_sh1107_i2c_seeed_128x128_f  // seeed = x_offset 0

// --- MIDI Event Queue ---
#define MIDI_QUEUE_SIZE 128

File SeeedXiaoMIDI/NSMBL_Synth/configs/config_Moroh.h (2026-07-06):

#pragma once

// ============================================================
//  MOROH — Arps / Sequences (Giorgio Moroder)
//  Copy to main/config.h before building:
//    cp configs/config_Moroh.h main/config.h
// ============================================================

// --- Band Member Identity ---
#define DEVICE_NAME     "NSMBL_Moroh"
#define DEFAULT_PATCH   80      // Lead 1 (Square) — top of the GM Synth Lead area
#define DEFAULT_BANK    0

// --- Channel behavior ---
// Listens ONLY on its roster channel (MIDI ch5). DRUM_CHANNEL disabled (> 15).
#define VOICE_CHANNEL   4       // Moroh listens only on MIDI channel 5
#define DRUM_CHANNEL    0xFF    // no drums — single-channel synth

// --- Hardware Pins (XIAO ESP32-C3) ---
#define BUTTON_0_PIN    5
#define BUTTON_1_PIN    4
#define BUTTON_2_PIN    3
#define BUTTON_3_PIN    2
#define LED_PIN         10      // Active LOW

// --- SAM2695 UART ---
#define SAM_UART_NUM    UART_NUM_0
#define SAM_UART_BAUD   31250
#define SAM_TX_PIN      21      // XIAO Serial0 TX
#define SAM_RX_PIN      20      // XIAO Serial0 RX

// --- MIDI Event Queue ---
#define MIDI_QUEUE_SIZE 64

// --- Button Timing ---
#define DEBOUNCE_MS     50
#define LONG_PRESS_MS   600

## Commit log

2026-06-29 Add NSMBL_SmplCty: AMYboard BLE MIDI sample player on ESP-IDF
    First AMYboard band member — a 16-slice drum sample player that receives
    BLE MIDI from iPhone and plays WAV kit files from SD card. Dual-core
    architecture: BLE MIDI on Core 0, I2S audio rendering on Core 1 with
    FreeRTOS queue between them. Parses standard WAV cue points for slice
    boundaries, maps to MIDI notes starting at C2 (note 36).
    Also migrates all project documentation from Arduino to ESP-IDF,
    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
2026-06-30 Add NSMBL_EEnoo AMY synth firmware, reorganize project structure
    New band member: EEnoo — a full polyphonic synth using the AMY engine
    (250 oscillators) with Juno-6 on ch1, DX7 on ch2, and GM drums on ch10.
    All driven over BLE MIDI from iPhone.
    Reorganized AmyBoard/ so each firmware variant lives in its own directory:
    - AmyBoard/NSMBL_SmplCty/ — 16-slice drum sample player (WAV/SD card)
    - AmyBoard/NSMBL_EEnoo/ — AMY synth engine with multi-channel support
    Updated PLANNING.md and TASKS.md to reflect completed Phase 1 milestones.
    [config.h, main.c, sd_card.c]
2026-06-30 Add Mozaic patch selector script for NSMBL_EEnoo
    iOS Mozaic script with 16-pad interface for switching between
    Juno-6 (ch1) and DX7 (ch2) patch banks, plus knob for fine patch
    selection. Passes all other MIDI through to the synth.
2026-06-30 Add Mozaic sound shaper script for NSMBL_EEnoo
    Real-time CC control surface: filter cutoff (CC 70), resonance
    (CC 71), volume (CC 7), mod wheel (CC 1). Channel selector pads
    for Juno/DX7/Drums, sustain toggle, CC reset, and a test keyboard
    on the bottom row. Pairs with the patch selector script.
2026-06-30 Add NSMBL CC handler and unified Mozaic controller
    Firmware: replace AMY's Juno-only CC handler with nsmbl_midi_cc_handler
    that works on all channels. Maps CC 7 (volume), 10 (pan), 70 (filter),
    71 (resonance), 75/93 (chorus), 91 (reverb).
    Mozaic: new unified EEnoo Controller script combining patch selection
    and sound shaping — prev/next patch browsing, filter/reso/reverb/chorus
    knobs with vol/pan toggle mode, sustain, CC reset.
2026-06-30 Add MIDI Panic button to EEnoo Controller
    Sends CC 120 (All Sound Off), CC 123 (All Notes Off), and CC 64
    (Sustain Off) on all 16 channels. Kills stuck notes dead.
2026-06-30 Add band member configs: EEnoo, Pryns, Aufde, Kneel
    Named configs for each band member — just copy to config.h before
    flashing. EEnoo (pads), Pryns (lead), Aufde (bass) use AMY synth
    firmware. Kneel (drums) uses SmplCty sample player firmware.
2026-06-30 Update README and TASKS for current state of the project
    README rewritten to reflect actual working system: AMYboard-focused,
    band roster with musician-inspired names, NSMBL CC map, Mozaic
    control surface, build instructions with named configs. Removed
    outdated XIAO/Arduino-era content.
2026-06-30 Add band member firmware projects: Pryns, Aufde, Kneel
    Three new firmware directories, all verified building:
    - NSMBL_Pryns (Prince) — lead synth, ch2, Juno Lead I
    - NSMBL_Aufde (Auf der Maur) — bass synth, ch3, Juno Synth Bass I
    - NSMBL_Kneel (Neal Peart) — drums, ch10, SmplCty sample player
    Each is a self-contained ESP-IDF project ready to flash.
    Updated .gitignore for ESP-IDF build artifacts and .DS_Store.
2026-06-30 Consolidate firmware into NSMBL_Synth and NSMBL_SampleKits
    Replace per-band-member directories with two firmware bases:
    - NSMBL_Synth (AMY engine) — used by EEnoo, Pryns, Aufde
    - NSMBL_SampleKits (WAV player) — used by Kneel
    Band member identity is just a config.h swap from configs/.
    Eliminates code duplication across 5 directories.
    [config.h, main.c, sd_card.c]
2026-07-01 Add XIAO ESP-IDF firmware, SAM2695 reference, Mozaic controller, fix BLE MIDI parser
    - XIAO ESP32-C3 + SAM2695 firmware (SeeedXiaoMIDI/NSMBL_Synth/)
    - SAM2695 MIDI reference with all CCs, NRPNs, reverb/chorus types (Docs/)
    - Mozaic XIAO controller: Mix layout with XY filter pad, NRPNs, named FX types
    - Rewrote BLE MIDI parser to handle running status — old parser misinterpreted
    timestamp bytes as status bytes when iOS batched messages, silently dropping CCs
    - Added ESP-IDF toolchain instructions to CLAUDE.MD
    - Updated PLANNING.md, TASKS.md, README.md for XIAO platform status
    [buttons.c, config.h, main.c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]
2026-07-01 Fix BLE MIDI running status parsing and SAM2695 bank handling
    BLE parser (ble_midi.c):
    - Rewrote parse loop to handle running-status continuation. Batched
    same-status messages (e.g. NRPN sequences: CC99+CC98+CC6) omit both
    timestamp and status bytes; the old loop demanded a timestamp each
    iteration and dropped everything after the first message. Confirmed
    via live capture: dual-NRPN packets now parse fully.
    - Reverted debug logging to DEBUG level after diagnosis.
    Bank handling (sam2695.c, main.c, Mozaic):
    - SAM2695 has only two banks: 0=GM, 127=MT-32. Values 1-126 are empty
    and silence Program Changes. Device bank buttons did bank+1, walking
    into empty banks and killing patch ch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
    [main.c, sam2695.c]
2026-07-01 Harden button input and fix volume tracking
    buttons.c:
    - Call gpio_reset_pin() before configuring each button pad, matching what
    Arduino's pinMode() does — detaches any stale peripheral/matrix routing
    before setting the pulled-up input.
    - Add the 50ms debounce that DEBOUNCE_MS was declared for but never used,
    so a bouncy switch can't double-fire a press.
    - Remove the temporary GPIO scan / edge / heartbeat diagnostics used to
    trace the (hardware seating) button issue.
    main.c:
    - Fix volume tracking in all-channel mode. The guard `ch == (MIDI_CHANNEL-1)`
    evaluated to `ch == -1` when MIDI_CHANNEL is 0, so incoming volume CCs
    never updated current_volume. Now matches the program-ch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
    [buttons.c, main.c]
2026-07-02 Lots of reference added
    Scraped a lot of stuff for reference.
    [01 Change.list.kicad_sch, 02 Block Diagram.kicad_sch, 03 Power Sheet and PAM8403.kicad_sch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]
2026-07-02 Listen only on channel 1 (melody) and channel 10 (drums)
    The SAM2695 is multitimbral (a different instrument per MIDI channel), which
    surprised us during testing: changing the patch then playing on another channel
    sounded like "nothing changed" because each channel is its own voice. Rather
    than fight that, make the unit behave like a normal hardware synth.
    - ble_midi.c: the parser now accepts only VOICE_CHANNEL (MIDI ch1) and
    DRUM_CHANNEL (MIDI ch10); all other channels are dropped before queueing, so
    a busy unused channel can't starve the ones we care about. Routing is handled
    in the host (AUM).
    - config.h: replace the old MIDI_CHANNEL accept-all knob with explicit
    VOICE_CHANNEL /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
    [config.h, main.c]
2026-07-02 Fix melodic program changes: move ESP-IDF console off UART0
    Root cause of "patch never changes, stuck on one bell-like sound": the debug
    console was on UART0 — the same port that drives the SAM2695. Every ESP_LOGI
    was transmitted to the chip as garbage MIDI and corrupted its state, so program
    changes (though provably correct on the wire) never took effect. Intermittent
    and correlated with logging activity, which is what made it so hard to pin down.
    sdkconfig.defaults: force the console to USB-Serial-JTAG and off UART0
    (CONFIG_ESP_CONSOLE_UART_DEFAULT=n, USB_SERIAL_JTAG=y, SECONDARY_NONE). The
    earlier attempt never applied because sdkconfig.defaults only takes effect when
    sdkconfig doesn't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
    [main.c, sam2695.c]
2026-07-02 XIAO patch-nav MVP: fine step on buttons 2/3 + document the UART0 gotcha
    - Buttons 2/3 now step patches one at a time (fine), complementing the
    family-jump on 0/1 (coarse) — full access to all 128 voices with fast browse.
    - Documented the console-on-UART0 root cause in PLANNING.md (Technical Notes,
    with guard rails), README.md (button map + build gotcha), and TASKS.md so it
    can't quietly regress. The fix: console on USB-JTAG, CONSOLE_UART_NUM=-1.
    [main.c]
2026-07-02 Add SAM2695 datasheet reference (markdown breakdown)
    17-part markdown breakdown of the SAM2695 datasheet (overview, pins, timings,
    reset/power, MIDI implementation, sounds/GM-MT32, drum sets, NRPNs, etc.) used
    as reference while debugging the XIAO synth. Obsidian/macOS cruft excluded.
2026-07-02 Review cleanup: panic releases sustain, fix stale comments, task the rest
    From a fresh-eyes review of the XIAO firmware:
    - sam2695_all_notes_off now sends CC64=0 before All Sound Off / All Notes Off,
    so panic also kills notes held by a sustain pedal left on
    - Remove duplicated/stale comment block above on_short_press and correct the
    "chord" comments (audition plays a single C4)
    - TASKS.md: document the deferred findings — audition blocking the MIDI task
    (needs a UART mutex before de-blocking), volume-button intent for drums,
    ble_midi_is_connected declaration home
    [main.c, sam2695.c]
2026-07-02 Add named XIAO band-member configs: Jami, Bowee, Ryngo
    Multiple XIAO units all advertise as "NSMBL_Synth", which makes them
    indistinguishable in AUM. Following the AmyBoard configs/ pattern, add three
    identity headers to copy over main/config.h before flashing:
    - config_Jami.h — NSMBL_Jami, lead synth (default: Lead 2 sawtooth)
    - config_Bowee.h — NSMBL_Bowee, strings synth (default: String Ensemble 1)
    - config_Ryngo.h — NSMBL_Ryngo, drums (sequence ch10; kit via PC)
    Same firmware everywhere — only DEVICE_NAME and DEFAULT_PATCH differ. Verified
    the Jami variant builds. README and config.h comments updated with usage.
    [config_Bowee.h, config_Jami.h, config_Ryngo.h]
2026-07-06 Sync band roster naming across docs and configs
    Adopt the canonical roster (README/PLANNING tables) everywhere:
    Eenoo (pads), Prynz (lead), Botsee (bass, Bootsie Collins), 8OhAte (XIAO drums),
    Kneel (Amy drums), Dapht (samples), Garee (MIDI out).
    - Rename configs to match:
    - AmyBoard: Aufde->Botsee, EEnoo->Eenoo, Pryns->Prynz (Kneel unchanged)
    - XIAO: Jami/Bowee/Ryngo -> Eenoo/Prynz/Botsee/8OhAte; XIAO synth configs now
    listen on their roster channel (Eenoo ch1, Prynz ch2, Botsee ch3), drums ch10
    - Update main/config.h pointer comments in both firmwares
    - PLANNING: intro line + architecture diagram to new names/channels
    - README + TASKS: prose/task references to new names
    - GM_VOICI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
    [config.h, config_8OhAte.h, config_Botsee.h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]
2026-07-06 XIAO band variants: each unit listens on exactly one MIDI channel
    Per the roster, make each XIAO variant single-channel so it responds only to
    its own port (routed per-device in AUM):
    - Synths listen ONLY on their roster channel (Eenoo ch1, Prynz ch2, Botsee ch3)
    via DRUM_CHANNEL disabled (0xFF); the parser then passes only VOICE_CHANNEL.
    - 8OhAte listens ONLY on ch10 (VOICE_CHANNEL=DRUM_CHANNEL=9); MIDI ch10 is
    always GM drums on the SAM2695.
    main.c: boot flourish is now conditional (#if DRUM_CHANNEL <= 15) — drummers
    play the signature beat, synths play a short hello note in their own voice.
    Prebuilt per-member BINs are gitignored (attached to the GitHub release instead).
    Co-Autho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
    [config_8OhAte.h, config_Botsee.h, config_Eenoo.h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]
2026-07-06 Add Moroh (Giorgio Moroder) — 5th XIAO member, arps/sequences on ch5
    New single-channel XIAO variant: NSMBL_Moroh, listens only on MIDI ch5,
    default patch Lead 1 (Square, PC 80) at the top of the GM Synth Lead area.
    Rounds out the 5-piece XIAO band (Eenoo/Prynz/Botsee/Moroh/8OhAte).
    Roster tables (README + PLANNING), architecture diagram, intro line, and the
    config.h pointer comment updated. BIN built and attached to the v0.1.0 release.
2026-07-06 Docs: bring status/tasks up to date with v0.1.0 XIAO band
    - PLANNING: refresh Current Status (v0.1.0 shipped, 5-piece single-channel XIAO
    band, UART0 bug solved, 3 units flashed); config note covers both platforms;
    add 2026-07-06 session-log entry
    - TASKS: mark shipped milestones (release, naming sync, 5 single-channel
    variants + BINs, flashed units); update Next to remaining flashes; add Garee
    MIDI-out and CV-output AMYboard variants to Later
    - README: point to the release's prebuilt per-member BINs with a flash command
2026-07-07 Scaffold Garee — AMYboard BLE-to-DIN MIDI bridge firmware
    New AmyBoard/NSMBL_Bridge/ project: BLE MIDI in -> DIN MIDI out, no synthesis.
    Reuses the proven BLE parser (from the XIAO firmware); adds a small UART1 MIDI
    output stage (GPIO14 Type A, 31250 baud, per the AMY source pin defs).
    Configurable routing via two #defines:
    - BRIDGE_IN: BRIDGE_ALL or a single channel (parser drops the rest)
    - BRIDGE_OUT: BRIDGE_PASSTHROUGH or remap every message onto one channel
    config_Garee.h default = forward ALL, remap to ch1 — so hardware that's fixed to
    channel 1 just plays whatever you route to Garee, no menu-diving on the gear.
    Builds clean for ESP32-S3. Console stays on UART0 (MIDI is on UART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
    [config.h, config_Garee.h, main.c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]
2026-07-07 Garee: console on USB-Serial-JTAG (S3 native USB), off the MIDI UART
    The AMYboard enumerates as native USB (/dev/cu.usbmodem*), so put the console on
    USB-Serial-JTAG to make logs viewable over the same USB-C used to flash. MIDI is
    on UART1 (GPIO14/21), a different peripheral, so there's no console/MIDI
    collision. View logs with `idf.py -p <port> monitor` from a real terminal.
2026-07-07 Garee: fix DIN MIDI out — hold the non-data TRS leg high as the source
    The AMYboard MIDI OUT is a TRS jack (PJ-3410) wired tip=GPIO14 (data),
    ring=GPIO15, sleeve=GND, with NO fixed 3.3V rail (v1.4 schematic). A DIN MIDI
    input's optocoupler needs a current source, which on this board must be provided
    by firmware holding the non-data leg HIGH. Garee only drove UART TX on GPIO14 and
    left GPIO15 floating, so the receiver's opto never conducted — total silence into
    an Akai MPC on BOTH Type-A and Type-B adapters, even though the UART transmitted
    perfectly.
    Fix in midi_out_init(): after uart_set_pin, drive MIDI_SRC_PIN (15) as a GPIO
    output held high. Matches stock tulipcc amyboard_set_midi_ou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
    [config.h, config_Garee.h, midi_out.c]
2026-07-13 NSMBL_SampleKits: I2C encoder + SH1107 OLED kit selection
    Self-contained local UI so an AMYboard drum node can browse and load kits
    from the SD card with no host:
    - i2c_bus: shared i2c_master bus (Qwiic, SDA=17/SCL=18)
    - modulino_knob: Arduino Modulino Knob driver. 7-bit addr 0x3B/0x3A (Arduino's
    8-bit 0x76/0x74 / 2); 4-byte read with pinstrap byte first; wrap-safe int16
    delta + button edge. Verified against the vendored Arduino_Modulino source.
    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
2026-07-13 NSMBL_Synth: port running-status BLE MIDI parser
    Same fix as NSMBL_SampleKits: replace the old parser (duplicate timestamp-skip
    blocks, no running-status support) with the running-status version
    (data_bytes_for_status() lookup, SysRT/SysEx handling). Keeps this variant's
    MIDI_CHANNEL filter.
2026-07-13 NSMBL_Synth: encoder + OLED patch & parameter control
    Bring the sampler's local-UI pattern to the AMY synth variant so a node can
    select patches and tweak its synth parameters standalone, and see what's loaded.
    - Reuse verbatim from NSMBL_SampleKits: i2c_bus, modulino_knob, vendored u8g2.
    - oled.c: two synth screens -- NAVIGATE menu (Patch + Filter/Reso/Reverb/Chorus/
    Volume/Pan, value bars, highlight) and EDIT (big label + wide bar).
    - ui.c: "menu + edit" model -- turn scrolls rows; push enters EDIT; in EDIT turn
    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
2026-07-14 NSMBL_Bridge (Garee): encoder channel routing + OLED MIDI monitor
    Give the BLE->DIN bridge a local interface: live channel routing and a glanceable
    MIDI activity monitor, so you can re-route and confirm traffic without a host.
    - bridge_state: makes BRIDGE_IN (listen filter) and BRIDGE_OUT (remap target)
    runtime (seeded from config defaults), plus a monitor (last forwarded note,
    forwarded-note counter, IN/OUT activity timestamps) shared across the parse
    task, forward task, and UI via a short portMUX critical section.
    - oled.c: bridge monitor screen -- IN->OUT header (active field boxed), big
    last-note readout, IN/OUT activity dots (flash on recent traffic), note counter.
    - ui.c: turn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
    [config.h, i2c_bus.c, main.c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]
2026-07-14 AMY configs: refresh per-member configs for the encoder+OLED UI
    The AmyBoard per-member configs predated the UI work and lacked the I2C/OLED/
    UI_CHANNEL defines, so they no longer built against the current firmware.
    Regenerate each from its project's current main/config.h plus the member
    identity: Eenoo (ch1, pad 47), Prynz (ch2, lead 32), Botsee (ch3, bass 31),
    Kneel (ch10 sampler), Garee (bridge, remap->ch1). Used to build the v0.2.0
    release BINs.
    [config_Botsee.h, config_Eenoo.h, config_Garee.h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]
2026-07-14 Extra docs...
    [1734827-2.stp, ABX00107-step.step, ABX00107.step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]
2026-07-14 Added my case STL
    Someone asked for it
    [AmyBoardCasing_03.stl]

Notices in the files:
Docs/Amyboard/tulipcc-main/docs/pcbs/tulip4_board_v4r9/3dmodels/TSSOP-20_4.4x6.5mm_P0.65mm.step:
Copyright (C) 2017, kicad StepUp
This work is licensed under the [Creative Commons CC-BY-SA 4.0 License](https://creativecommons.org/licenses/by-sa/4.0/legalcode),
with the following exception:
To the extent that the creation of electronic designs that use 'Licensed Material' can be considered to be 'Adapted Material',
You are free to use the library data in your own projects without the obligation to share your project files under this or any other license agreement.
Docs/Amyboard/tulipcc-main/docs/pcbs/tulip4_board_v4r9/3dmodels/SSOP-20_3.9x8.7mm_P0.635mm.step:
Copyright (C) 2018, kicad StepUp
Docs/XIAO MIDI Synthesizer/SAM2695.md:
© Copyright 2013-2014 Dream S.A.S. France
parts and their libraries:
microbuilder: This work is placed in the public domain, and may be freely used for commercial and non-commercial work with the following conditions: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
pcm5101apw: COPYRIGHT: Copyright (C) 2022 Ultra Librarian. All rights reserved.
